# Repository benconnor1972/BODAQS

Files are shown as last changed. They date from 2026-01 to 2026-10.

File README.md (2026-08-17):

<table>
  <tr>
    <td width="50%">
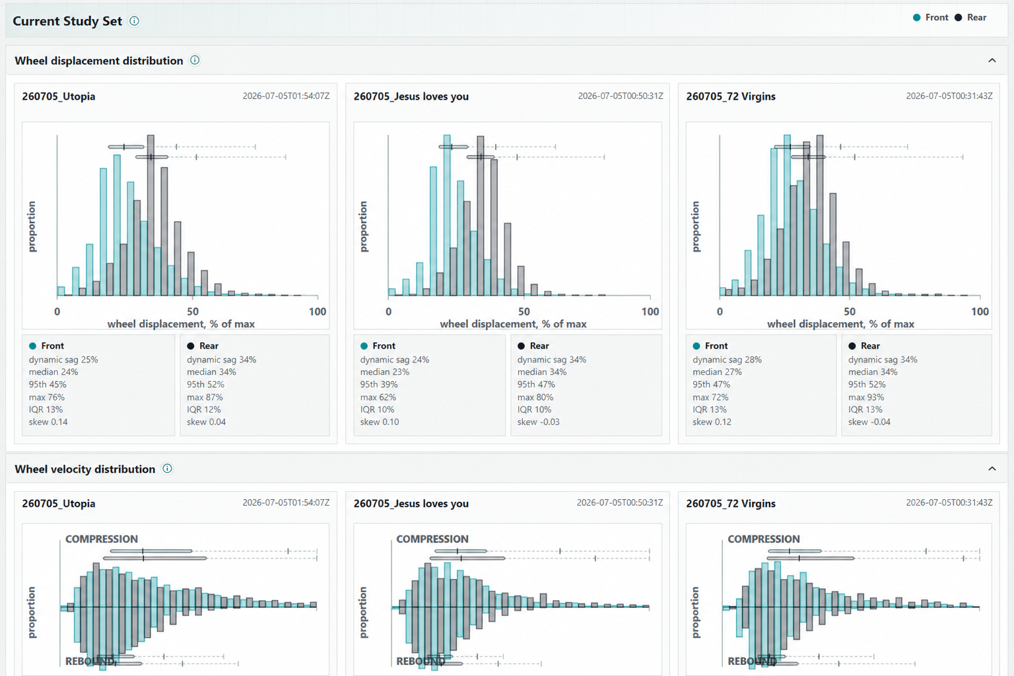
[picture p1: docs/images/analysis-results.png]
BODAQS Workbench showing the simple suspension stats analysis view
      
    </td>

   <td width="50%">
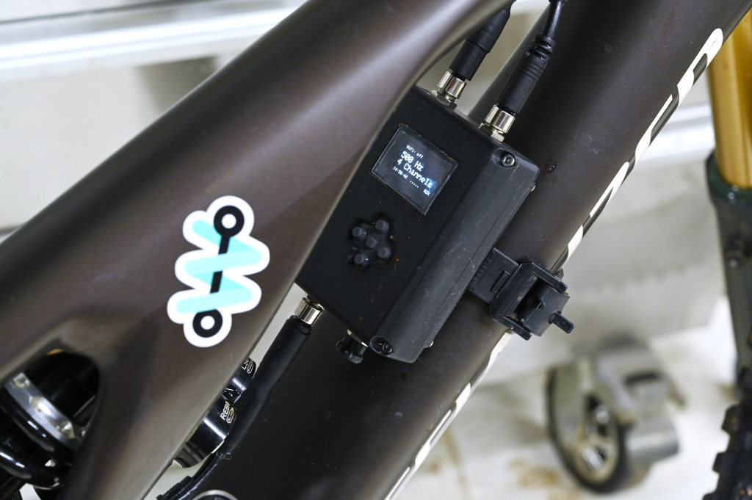
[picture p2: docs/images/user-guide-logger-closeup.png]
BODAQS logger installed on a bike
      
    </td>
  </tr>
  <tr>
    <td width="50%">
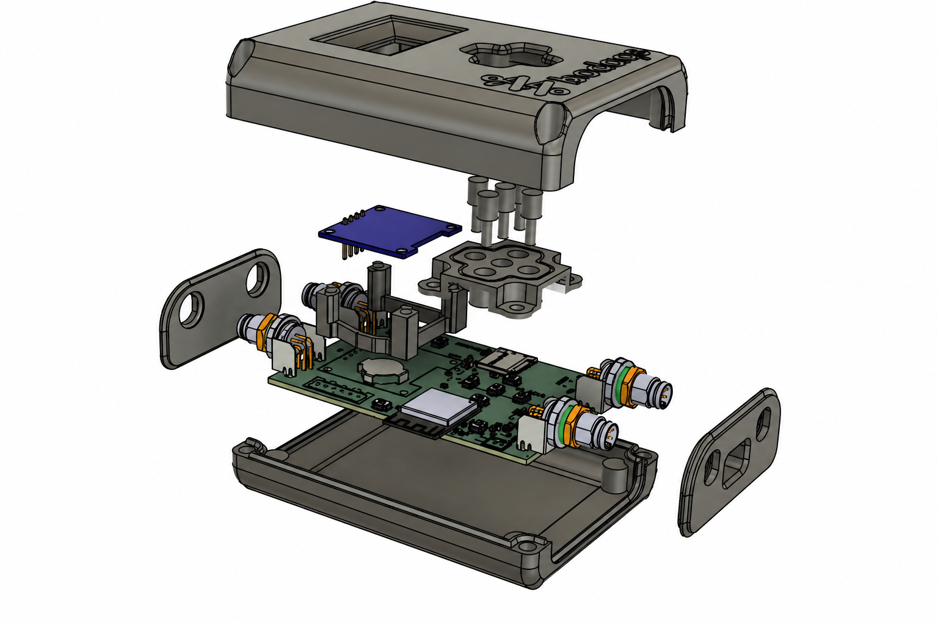
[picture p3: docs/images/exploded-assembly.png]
BODAQS A8 logger exploded diagram
      
    </td>
    <td width="50%">
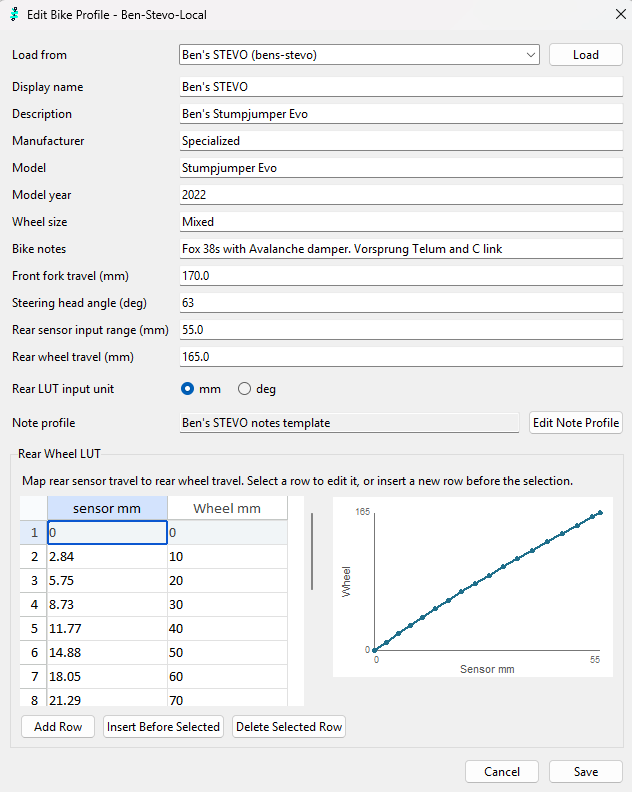
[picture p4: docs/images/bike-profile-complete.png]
BODAQS Import Manager showing a bike profile
      
    </td>
  </tr>
</table>

Current releases [here](https://github.com/benconnor1972/BODAQS/blob/main/RELEASES.md)

# Bicycle Open Data Acquisition System

BODAQS (Bicycle open data acquisition system) is an open-source, build-it-yourself data collection
and analysis system for mountain bikes, designed to be accessible to anyone with some DIY skills and a curiosity about what their bike is actually doing.

Data acquisition is ubiquitous in motorsport, and it's making its way into mountain-bike racing too. But for the engineering-minded (or budget-constrained), the choice is often between costly professional systems or consumer tools that keep the underlying data hidden.

BODAQS aims to offer an alternative: hardware that can be built with basic soldering skills using widely available parts; software with deep functionality and a structure designed for long-term expansion; and analysis built on powerful, free tools — alongside mounting and mechanical designs that can be 3D printed at home or produced at low cost. 

The project provides **open designs** for the hardware, software, analysis tools, and mechanical parts needed to collect and analyze mountain-bike data. It follows a build-it-yourself ethos, emphasising simplicity and low cost **without compromising functionality**.

## The problem with mountain bike (suspension) tuning

For most riders, suspension setup is a vibe-based, iterative guessing game: adjust a click, do a
run, wonder if that made things better or just 'different', repeat to exhaustion.

At the sharp end of gravity racing, teams with the budget chase these problems using data - but at a high cost. A few consumer products - notably Shockwiz, now owned by SRAM - have bridged the gap with a product that can provide meaningful suspension insight for most riders and be set up in under twenty minutes. But ShockWiz is a closed system: the algorithm is proprietary, the data never leaves the device, and if you run a coil shock, you're out of luck.

For the rider who wants to go deeper, wants to do more with the data, or whose coil setup isn't
supported,the choice has been: trust a black box, go all in on professional equipment, or go
without.

## The device

The BODAQS logger is a compact, hackable, open-source data logger you build yourself from widely available
components using basic soldering skills and a 3D printer. It records inputs from suspension and other sensors, at up to 1000Hz, and stores the data as standard CSV files readable by almost anything. The device can connect to wifi to allow settings to be edited or log files downloaded using any device with a web browser.

A small OLED screen and keypad make it simple to use, and an optional
handlebar-mounted button lets you tag moments of interest mid-ride — a heavy landing, a sketchy
section — so they're easy to find later.

The full design is open: PCB schematics and layouts, firmware, case, sensor mounts and more are all available to build, hack, and improve. There's a full bill of materials, build guide and advice on where to purchase the parts required.

## The software

Recording data is an engineering problem. Deciding what it means is the harder part, and the part that actually matters for tuning.

The BODAQS software comprises two main components:

- the **Import Manager** imports data from one or more loggers via file copy or WiFi, applies bike geometry information, does pre-processing calculations, matches GPS data from external devices and manages setup notes. The processed files live in your personal run library.
- the **BODAQS Workbench** gives you the visualization tools to dig deep into what your bike is doing.
The whole package can be installed on your computer and run with or without an internet connection.

## Who it's for

BODAQS is designed to scale with the user — in both the build, and the analysis.

If you're new to data acquisition, the hardware guide walks you through assembling the
logger, and you'll have something real to look at after your first ride with a couple of sensors - or even just one. 

If you're a top-end rider, mechanic or suspension shop with your own battle-tested ideas on how a bike should be set up, you'll have something you can use to test out and validate your own ideas and work, race faster, or to add value to your customers. 

If you're a tinkerer, engineer, developer, data scientist or uncategorised nerd, you can contribute to the project. Code, designs, ideas, feedback - it's all welcome.

## Enough of the pitch - where's this thing actually at?

**TL;DR:** we've got a pretty usable first-generation system that runs from end to end: From sourcing and building your logger to analyzing your runs. There's still lots to do, but we think it can add value for most people in its current state.

- The hardware works well within the limits of what we have tested and we think the user experience is pretty good. 
- The system supports analog potentiometers for suspension displacement, AS5600 (12-bit) and AS5048B (14-bit) rotary encoders for measuring linkage rotation, and GPS (either dedicated receiver or integrating data from Garmin devices).
- We have our own end-to-end software solution that you can download and test out, as well as a [hosted demo](https://demo.bodaqs.net/). We're also compatible with [data.syn.bike](https://data.syn.bike) if you prefer to see your data presented that away.
- We have [sourcing](https://bodaqs.net/logger-build-guide/bodaqs-a8/sourcing-hardware/), [building](https://bodaqs.net/logger-build-guide/bodaqs-a8/building-the-logger/), and [user](https://bodaqs.net/user-guide/) guides.
- We have published packages for the [hardware](https://github.com/benconnor1972/BODAQS/tree/main/hardware/releases) and the [3d printed parts](https://github.com/benconnor1972/BODAQS/tree/main/mechanical/Case/a8_v1_0)
- We have a set of Jupyter Lab [analysis notebooks](https://github.com/benconnor1972/BODAQS/releases) for exploratory data analysis. The back end code is organised in Python modules and there is a documented [API](https://github.com/benconnor1972/BODAQS/blob/main/docs/analysis/contracts/BODAQS_Public_API_Contract_v0.md). 

What we're working on:
- Further development of the software. There is lots we want to do!
- Extending the range of supported sensors. We've gone heavy (overkill?) on our software design to make integration of additional sensor types simple, so now is the time to cash in. Our next priorities are wheel speed sensors and inertia-motion units.
- Collecting build feedback from our beta testers. We're looking for people who want to help with this!
- Getting the system under some faster riders - in the end, we want to do *data analysis*, not just build hardware and software.

## Ethos and inspiration

This project exists for many reasons but three specific precursors stand out:
 - ShockWiz: Nigel Wade's ground-breaking product, now owned by SRAM, is in a category of one: mountain bike suspension analysis products that can be set up by an average user in under 20 minutes and provide useful feedback to the vast majority of riders. I was a happy ShockWiz user for many years and probably still would be if I hadn't discovered coil suspension. An elegant product that extracts maximum insight from minimum hardware, with a simplicity that hides some very clever engineering.
 - Sufni: The first open-source mountain bike data acquisition project to cross my path. For a variety of reasons I decided to take a different path rather than build one, but it provided the seed of the idea and the use of Lego for sensor mounting deserves a credit of its own.
 - RepRap: The movement that gave birth to cheap and ubiquitous 3D printing wasn't driven by market analysis by some big corporation, but by people who wanted a thing they couldn't buy (at a reasonable price). The community development and sharing ethos persists to this day and the products available are massively better and cheaper than what was available just a few years ago.

## Project maintenance

BODAQS is maintained by [Ben Connor](https://github.com/benconnor1972).

Contact: benconnor1972@gmail.com

Official release and code-signing responsibilities are described in the
[Code Signing Policy](CODE_SIGNING_POLICY.md).

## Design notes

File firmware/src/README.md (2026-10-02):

# ESP32 Data Logger (SD + Web UI)

ESP32-based data logger with:
- An extensible sensor framework - initial target is 2 potentiometer, 2 accelerometer, 2 strain gauge and one event mark channels
- Configurable logging rates of 10, 20, 50, 100, 200, 500, 700, and 1000 Hz, subject to sensor throughput limits
- SD card logging
- On-device web UI (list/download/delete files, simple config page)
- mDNS discovery in station and AP mode via `_bodaqs-logger._tcp`
- Button control (start/stop logging, mark events, menu navigation)
- General and sensor configuration via config file on SD (`loggercfg`) 

Developed mainly for mountain bike use.

On the A8, external ADC throughput is budgeted at 70% of each ADS1220's
2,000 SPS maximum, divided by its number of active, unmuted analog channels.
The logger uses the lowest limit across the active ADCs and rounds down to a
permitted rate. There is no separate 500 Hz cap: one active channel per ADC
allows up to 1,000 Hz, two allow 700 Hz, and three or four allow 200 Hz.
The requested configuration rate is preserved; the effective rate controls
logging. Higher rates require hardware validation of sample freshness and
logger timing. The existing integer-microsecond cadence uses a 1,428 us period
for 700 Hz (approximately 700.28 Hz).

A8 and RC3 have separate board profiles with the same hardware pin mapping.
Build A8 with `bodaqs_s3_mini_n4r2` (`BODAQS_A8`) and RC3 with
`bodaqs_s3_mini_n4r2_rc3` (`BODAQS_V1RC3`). The legacy
`BODAQS_S3_Mini_N4R2` profile alias selects A8. RC3 and Prototype F retain
the Sleep menu entry and the default hold-left sleep binding; A8 omits both.
Explicit bindings in existing config files still apply, so remove any A8
sleep binding there as needed. Restart is the last main-menu entry on all
boards and is unavailable while logging. Automatic idle sleep remains
controlled by `auto_sleep_idle_min`.

## Hardware

- **ESP32** (Arduino core 3.3.0 tested) - SparkFun ESP32 Thing Plus dev board
- **MicroSD** via ESP32 SDMMC
- **Buttons**
- **0.96" monochrome OLED display**
- **Sensors** starting with potentiometers on ADC pins (configurable)

## Development

# ESP32 Data Logger — Module Overview

This document summarizes the major modules in the project, what each one is responsible for, how they interact, and key APIs/gotchas. It’s meant to be kept at the repo root for quick orientation.

---

## Top-Level Flow (boot → ready)

1. **setup()** initializes storage (SD), applies defaults, loads config, brings up Wi‑Fi (optional), syncs RTC, constructs sensors from the config, starts Display/UI, and registers buttons.
2. **loop()** runs the main managers’ `loop()` functions (logging, web server, menu, button dispatch, etc.).

---

## `ConfigManager`

**Purpose:** Load/save the logger’s global settings and the list of **SensorSpec**s from `loggercfg.txt`. It also owns a per‑sensor key/value store backing the **ParamPack** interface used by sensor code.

**Key responsibilities**
- `begin(filename)` - set the config file path. Storage access is handled through `StorageManager`.
- `load(LoggerConfig&)` / `save(const LoggerConfig&)` — merge text file with defaults and persist changes.
- Manage **SensorSpec** array (type, name, mutedDefault, ParamPack for per-sensor params).
- Simple string‑backed **ParamStore** (arrays `keys[]`/`vals[]`, bounded sizes) with case‑insensitive lookups.

**APIs**
- `uint8_t sensorCount()`
- `bool getSensorSpec(uint8_t i, SensorSpec& out)` — returns a copy; ParamPack is rebound to the correct store.
- `bool getParam/getIntParam/getFloatParam/getBoolParam(index, key, out)` — safe accessors used by UI/Web to read current per‑sensor values.
- Global parse helpers: `parseBool`, etc.

**Notes/Gotchas**
- `save()` writes **all** config keys (globals + sensors) deterministically.
- `logger_name` is the stable logger identity used by upload/import workflows
  and shown in the web UI title bar.
- `ConfigManager::loggerId()` returns a trimmed, filename-safe derivative of
  `logger_name` for API/session identifiers without changing the stored name.
- `log_format` controls the emitted log file format. `bodaqs_standard` is the normal headed BODAQS CSV; `bodaqs_compact_binary` writes the established single-timebase BDQ v1 file; and explicit `bodaqs_multi_stream_binary` selection writes the experimental BDQ v2 independent-stream format. Deprecated syn.bike format keys are accepted on load and silently select `bodaqs_compact_binary`.
- `omit_metadata=false` keeps the default behaviour of writing a same-stem JSON log metadata file at log close. Set `true` to skip metadata generation.
- Idle timeout config is saved in minutes (`auto_sleep_idle_min`, `wifi_idle_timeout_min`). Legacy `_ms` keys are still accepted on load for migration.
- Fixed per‑sensor KV capacity (currently 32). Exceeding keys will drop extra pairs.
- File format keys used by analog pot sensors: `pin`, `mode`, `include_raw`, `zero_count`, `full_count`, `full_travel_mm`.
- File format keys used by AS5600 string-pot sensors include `counts_per_turn`, `wrap_threshold_counts`, `sensor_zero_count`, `sensor_full_count`, `installed_zero_count`, `sensor_full_travel_mm`, and `assume_turn0_at_start`.
- File format keys used by AS5048B and AS5600 rotary angle sensors include `i2c_bus`, `i2c_addr`, `zero_count`, and `direction`. `direction` is `counts_increase_positive` or `counts_decrease_positive`; log metadata still emits legacy `invert` for downstream compatibility.

---

## `SensorManager`

**Purpose:** Owns the live sensor objects, registration, primary pot selection, and per‑sensor mute state that the logger and UI respect.

**Key responsibilities**
- `begin(const LoggerConfig*)` — reset internal lists and prepare to accept sensors.
- Build sensors in `setup()` by iterating `ConfigManager::sensorCount()` and mapping `ParamPack` → sensor params.
- `registerSensor(Sensor*)`, `finalizeBegin()`, `debugDump()` for inspection.
- Mute control used by logger/UI: `getMuted(idx, bool&)`, `setMuted(idx, bool)`.
- `primaryPot()` selection for UI convenience.

**Notes/Gotchas**
- Keep the **construction order** deterministic so UI indices match spec indices.
- Treat `SensorManager` APIs as **static** utilities across the codebase.

---

## `AnalogPotSensor` (potentiometer)

**Purpose:** Acquire analog position and report one or more columns depending on mode and configuration.

**Key params (from ParamPack)**
- `pin` (ADC pin), `mode` (`raw`/`norm`/`mm`), `include_raw` (bool),
- `zero_count`, `full_count`, `full_travel_mm`.

**Notes**
- Produces normalized and/or raw columns; column names include the sensor `name` (e.g. `pot1_norm`).
- Measurement direction is derived from calibration endpoints. If the full-travel count is below the zero-travel count, the firmware treats the signal as inverted.
- Honors **muted** state via `SensorManager` (muted sensors still tick but are skipped in log output).

## `AS5048BAngleSensor` / `AS5600AngleSensor`

**Purpose:** Acquire one-turn absolute rotary position over I2C and report raw counts or zeroed angular movement.

**Key params (from ParamPack)**
- `i2c_bus`, `i2c_addr`, `i2c_read_mode`
- `zero_count`, `direction`
- `slow_filter` optionally writes the AS5600 `CONF.SF` slow-filter bits at
  startup as a volatile setting (`unchanged`, `16x`, `8x`, `4x`, or `2x`).
- `output_mode`, `include_raw`, `include_angle`, `include_diag`
- `include_angle` appends a diagnostic AS5600 `ANGLE` register column so it can
  be compared with the normal raw `RAW_ANGLE` register readout.
- For AS5600 and AS5048B, `include_diag` adds AGC/status/magnitude plus read-state and
  failure-counter columns (`read_ok`, `reused`, `read_failures`,
  `diag_failures`).
- AS5600 metadata includes a read-only startup snapshot of key device registers
  (`ZPOS`, `MPOS`, `MANG`, `CONF`, `RAW ANGLE`, `ANGLE`, `STATUS`, `AGC`, and
  `MAGNITUDE`) under `device_config`.
- BDQ final summaries include bounded AS5600 and AS5048B runtime transition
  diagnostics (logging/scheduler boundaries, the start and recovery of
  read/configuration failures, failure stage/result, and analog-rail state).
  CSV JSON metadata contains the corresponding compact sensor-health summary;
  these diagnostics do not add sample columns or successful-path I2C
  transactions.
- AS5600 I2C logging uses the device's persistent `RAW_ANGLE` pointer after
  the first addressed read. Normal samples therefore need only the two-byte
  read transaction; diagnostic/configuration access invalidates the pointer
  and the next sample safely re-primes it. Runtime summaries report fast-read
  attempts/successes/fallbacks and raw-read duration. The default magnetic
  diagnostic cadence is 1 Hz (`diag_interval_ms=1000`).

**Notes**
- `ZERO` calibration captures the installed zero point and then asks for a small positive movement so the firmware can set `direction`.
- `direction=counts_increase_positive` means increasing raw counts produce positive angular output; `counts_decrease_positive` reverses that polarity.
- Metadata emits both `direction` and legacy `invert`; `invert=true` corresponds to `counts_decrease_positive`.
- These angle sensors do not support multi-turn tracking.
- Repeated failures are coalesced into transition events and aggregate streak
  counts. At most 32 events are retained per session; overflow is reported.

## `AS5600StringPotSensorBase` / `AS5600StringPotAnalog`

**Purpose:** Acquire a wrapped one-turn AS5600 reading, unwrap it across multiple turns in firmware, and report unwrapped travel while still logging wrapped raw counts.

**Key params (from ParamPack)**
- `ain` / `pin`
- `counts_per_turn`, `wrap_threshold_counts`, `assume_turn0_at_start`
- `sensor_zero_count`, `sensor_full_count`, `installed_zero_count`, `sensor_full_travel_mm`
- `output_mode`, `include_raw`

**Notes**
- `RAW` mode reports wrapped counts as the primary column.
- When `include_raw=true`, the logger appends wrapped raw counts and unwrapped raw counts. The unwrapped raw metadata includes `unwrap` in its transform chain.
- `LINEAR` mode reports unwrapped mm using the calibrated unwrapped span.
- The sensor resets its unwrap tracker to turn 0 at each logging start when `assume_turn0_at_start=true`.

For `AS5600StringPotI2C`, the I2C-specific parameters also include
`slow_filter`, `include_angle`, `include_diag`, and `diag_interval_ms`. The I2C
variant applies and records the same volatile AS5600 configuration, device
register snapshot, magnetic diagnostics, read-quality columns, runtime events,
and deferred post-session recovery as `AS5600AngleSensor`. Existing string-pot
measurement columns retain their previous order; optional health columns are
appended after them.

---

## `StorageManager`

**Purpose:** Single owner of SDMMC startup and log file lifecycle; provides sample interval/buffer knobs.

**Common APIs**
- `StorageManager_begin(boardProfile)`
- `StorageManager_setSampleRate(hz)` / `StorageManager_getSampleIntervalUs()`
  (`StorageManager_getSampleIntervalMs()` remains as a rounded-up compatibility view)
- `StorageManager_setBufferSize(bytes)`

**Notes**
- `SD_MMC.begin()` and error handling live here.
- `bodaqs_standard` logs `sample_id`, timestamp, all active sensor columns, and
  `mark`, with a header. Run statistics and generic configured-sensor health
  summaries are written to the same-stem JSON metadata file under `qc`.
- Both binary selections write `.bdq` logs with embedded metadata and schema information. `bodaqs_compact_binary` is BDQ v1; `bodaqs_multi_stream_binary` is the opt-in BDQ v2 path. Neither generates a separate JSON sidecar or automatic ZIP archive.
- In BDQ v2 mode, sensors with native stream support (currently BMI270) are excluded from the primary row and stored once at the hardware profile rate. BMI270 `max_output_rate_hz` continues to govern the legacy sparse-row adapters only.
- The BDQ v2 primary-row queue is capped at 32 rows to leave heap for multiple IMU FIFO queues. At the intended auxiliary-sensor ceiling of 200 Hz this is about 160 ms of buffering; primary queue drops are preserved in stream status and the final summary.
- BMI270 profiles `orientation_200`, `orientation_400`, `orientation_800`, and
  `orientation_1600` select native accel/gyro ODRs while retaining the existing
  +/-16 g, +/-2000 deg/s, and filter/performance settings. The higher-rate
  profiles are experimental until their achieved rates, filtering, loss, and
  timing have been measured on the target wiring.
- `accel_1600_gyro_200` is an experimental BDQ-v2-only mixed-rate profile.
  It emits 1600 records/s on the accelerometer time grid and declares
  `gyro_sample_valid` at offset 26; gyro axis values are fresh only when that
  field is 1. The stream catalog separately reports effective accel and gyro
  rates. CSV and BDQ v1 reject this profile rather than imply that held or
  placeholder gyro values are native 1600 Hz measurements.
- `fifo_poll_rate_hz` independently selects FIFO service at 25, 50, 100, 200,
  or 400 Hz. Experimental 10 Hz service is restricted to
  `accel_800_gyro_200`. Session diagnostics record the selected native/output/poll rates,
  queue coverage and pressure, FIFO throughput, I2C occupancy, achieved service
  rates, missed service slots, and scheduler lateness.
- A 1600 sample/s stream has an 800 Hz Nyquist limit; it cannot preserve a
  1 kHz signal regardless of transport performance. A genuine 1 kHz analysis
  band requires a different IMU profile/device sampling above 2 ksample/s with
  suitable analogue/digital filter bandwidth.
- Direct syn.bike CSV output is deprecated. Legacy `syn_bike_raw` configuration values fall back to `bodaqs_compact_binary`; data.syn.bike files can be generated downstream by the BODAQS analysis tooling.
- Standard CSV and BDQ logging refuse configurations with more than 64 emitted
  sensor columns. CSV rows are formatted in a session-allocated worst-case
  buffer; formatting and storage-write failures are counted in metadata rather
  than being silently omitted.
- When metadata is enabled and written successfully, log close also creates a
  same-stem session ZIP via `<stem>.zip.tmp` then renames it to `<stem>.zip`.
- After the ZIP is written successfully, the loose same-stem CSV and JSON are
  removed; the ZIP is the canonical upload/import artifact.
- A small smoke test may create `TEST.TXT` during setup.

---

## `ZipArchiveWriter`

**Purpose:** Create small store-only ZIP archives on SD for completed session
artifacts.

**Notes/Gotchas**
- Currently used by `StorageManager` to archive each completed CSV/JSON pair.
- Writes to a caller-supplied destination and refuses to overwrite existing
  files; callers should write a temporary path and rename after success.

---

## `UploadSessionScanner`

**Purpose:** Find completed CSV archives and compact binary sessions on SD for
the Wi-Fi upload API.

**Common APIs**
- `scan(directory, out, capacity, summary)` - returns complete ZIP-backed CSV
  sessions and loose `.bdq` sessions, then fills a bounded summary.
- `findBySessionId(sessionId, out, directory)` - resolves a complete session by
  its `logger_id__session_stem` identifier.

**Notes/Gotchas**
- `.zip.tmp` files are ignored as importable archives but counted in the scan
  summary for diagnostics.
- `.bdq` sessions report `data_format=bdq`, `data_path`, and `data_ready`
  instead of a CSV archive.
- Upload/acknowledgement flags are read from `UploadAckIndex`.

---

## `UploadAckIndex`

**Purpose:** Persist import acknowledgements from the desktop agent.

**Common APIs**
- `markSessionAcknowledged(record)` - records an acknowledgement, returning
  success without appending when the session is already acknowledged.
- `findSessionAcknowledgement(sessionId, out)` - reads the latest valid record
  for a session.
- `applyAcknowledgementStatuses(lookups, count)` - resolves acknowledgement
  flags for a batch of session ids with one index scan.
- `isSessionAcknowledged(sessionId)` - convenience predicate used by session
  listing.

**Notes/Gotchas**
- The index is `/upload_index.ndjson`; the `.ndjson` extension keeps it out of
  same-stem session discovery.
- Oversized indexes are refused rather than scanned indefinitely; remove or
  compact `/upload_index.ndjson` on the SD card if this diagnostic appears.
- Corrupt lines are skipped so a bad record does not block session listing.

---

## `UploadSessionCleanup`

**Purpose:** Conservative cleanup for sessions already acknowledged by the
desktop import agent.

**Common APIs**
- `cleanupSession(session, MoveToUploaded, result)` - moves the ZIP into
  `/uploaded`; loose CSV/JSON files are moved too when present on older cards.
- `cleanupSession(session, Delete, result)` - removes the ZIP; loose CSV/JSON
  files are removed too when present on older cards.

**Notes/Gotchas**
- API callers must require upload mode and prior acknowledgement before using
  this helper.
- Cleanup requires the archive and treats loose CSV/JSON files as optional
  legacy companions.

---

## `LoggingManager`

**Purpose:** Turn logging on/off, write headers and rows from active sensors, and accept **mark** events.

**Common APIs**
- `bool start()` / `void stop()` / `bool isRunning()`
- `void mark()` — insert a marked row/annotation.

**Interlocks**
- Will **refuse to start** while the web server is running (see `ButtonActions`).
- Will **refuse to start** while upload mode is active.

---

## `UploadModeManager`

**Purpose:** Runtime guard for Wi-Fi upload workflows.

**Common APIs**
- `bool enter()` / `void exit()` / `bool toggle()`
- `bool isActive()` / `bool canEnter()`

**Interlocks**
- Upload mode cannot be entered while logging is active.
- Upload mode is transport-neutral; it does not automatically start Wi-Fi.
- Logging cannot start while upload mode is active.

---

## `RTCManager`

**Purpose:** Timekeeping (internal ESP32 RTC or external DS3231), NTP sync, timezone application.

**Common APIs**
- `RTCManager_begin(RTC_INTERNAL|RTC_EXTERNAL)`
- `RTCManager_setHumanReadable(bool)` — UI/log timestamp format.
- `RTCManager_syncWithNTP(ssid, pass)`
- Tied to `configTzTime(tz, ntp1, ntp2, ntp3)` in `setup()`.

---

## `WiFiManager`

**Purpose:** Non-blocking Wi-Fi state machine for station/AP networking, RTC
sync, web/API availability, and discovery.

**Common APIs**
- `status()` - returns mode, IP, hostname, RSSI/client details.
- `hostname()` - returns a stable mDNS/HTTP hostname derived from `logger_id`.
- `refreshDiscovery()` - restarts mDNS TXT records after upload
  mode changes.

**Notes/Gotchas**
- Station and AP modes both advertise `_bodaqs-logger._tcp` on port `80`
  when online, so the device is reachable at `bodaqs-<logger_id>.local`
  in either mode.

---

## `WebServerManager`

**Purpose:** Lightweight HTTP UI for status, SD file browsing, and editing **all** configuration (globals + sensors).

**Routes**
- `/` redirects to `/files`; `/files` is the landing page and supports SD browsing, upload, download, and delete actions.
- `/config` (GET) displays editable globals and sensor sections.
- `/config` (POST) updates globals and rewrites `loggercfg.txt` with all keys; also rewrites each sensor’s block.
- `/config/sensors` can add or remove sensor config blocks. Removing a sensor rewrites config only; transform directories/files are left in place. Restart the logger after adding/removing sensors so the live sensor set is rebuilt.
- `/api/v1/device`, `/api/v1/status`, `/api/v1/upload-mode/*`,
  `/api/v1/sessions`, `/api/v1/session/archive`, and `/api/v1/session/data` expose the local-first
  import-agent API. Session list/download/cleanup routes require upload mode.
- `/files` includes browser controls for entering/exiting upload mode and
  reports network/session readiness for manual checks.
- All HTML pages share a title/navigation header showing `BODAQS data logger: <logger_name>`, the active network, and IP address.

**Interlocks**
- Config edits and generic SD-card mutations are rejected while logging or
  upload mode is active. Downloads remain allowed; import cleanup should use
  the upload API after acknowledgement.
- `canStart()` returns false while logging is active; `ButtonActions` also blocks starting logging while Wi‑Fi/web is running.

**Helpers**
- Minimal HTML/CSS, simple CSV inputs (e.g., NTP servers), basic HTML escaping, safe path checks.

---

## `UI` & `DisplayManager`

**Purpose:** Unified printing to Serial and OLED with levels and targets, plus transient toasts and a status line.

**UI APIs (typical)**
- `UI::begin(g_cfg)` — apply target/level preferences.
- `UI::println(serialText, oledText, target, level, oledToastMs=0)`
- `UI::status("Ready")` — persistent status line when idle.
- `UI::toast("Marked", 1200)` — small transient message.
- `UI::clear(target)` / `UI::flush()` — OLED control.
- `UI::setModal(true/false)`, `UI::isModal()` — allow **MenuSystem** to “own” the OLED while a menu is open.

**DisplayManager**
- Owns the OLED device and regular idle/telemetry rendering.
- In `loop()`, it **exits early** when `UI::isModal()` is true so the menu can draw unobstructed.

---

## `ButtonManager`

**Purpose:** Register buttons in **poll** or **interrupt** mode, debounce, and raise callbacks with **edge** and **hold** events.

**APIs**
- `ButtonManager_register(pin, BUTTON_POLL|BUTTON_INTERRUPT, debounceMs, callback)`
- `ButtonManager_loop()` — delivers events & performs polling.
- Optional `ButtonManager_read(pin)` — single-pin polled edge read.

**Events**
- `BUTTON_PRESSED`, `BUTTON_RELEASED`, `BUTTON_HELD` (long‑press; ~800 ms default).

**Notes/Gotchas**
- Interrupt mode posts **PRESS** from ISR; **HELD** is synthesized in the main loop when the level stays LOW long enough.
- Some pins can’t generate external interrupts on ESP32; keep **Enter** on a reliable GPIO when using interrupt mode, or use **poll** for nav keys.

---

## `ButtonActions`

**Purpose:** Wire configured pins to user-visible actions and UI feedback.

**Mappings (typical)**
- **Web** → start/stop web server (blocks when logging). `web_toggle` can be
  bound to `click`, `double_click`, or `held`.
- **Log** → start/stop logging (blocks when web server is running).
- **Mark** → inserts a mark only when logging is active.
- **Nav Up/Down/Left/Right/Enter** → dispatch into **MenuSystem** when the menu is active; otherwise show small UI toasts.

**Setup**
```cpp
ButtonActions::begin(&g_cfg);
ButtonActions::registerButtons();  // reads pins & debounce from config
```

---

## `MenuSystem`

**Purpose:** A small, modal OLED UI navigated by five buttons for logging,
upload, sensor, calibration, and settings workflows.

**Behavior**
- **Open/Close**: short‑press Enter to open, long‑press Enter to close (or via left/back).
- **Auto‑close** after inactivity (default 15 s; `setIdleCloseMs(ms)`).
- **States**: `Inactive` → `Main`; `Settings` groups lower-frequency
  configuration and device actions (`WiFi mode`, `Log format`, `Reset time`,
  `Restart`, `About`).
- **Navigation**:
  - From **Main**: Right/Enter opens the selected item, including the
    `Settings` submenu.
  - In **Settings**: Up/Down selects settings; Right/Enter opens or runs the
    selected setting.
  - In **SensorsList**: Up/Down to move selection, Right/Enter toggles mute for the selected sensor via `SensorManager::getMuted/setMuted`.
  - Left goes back; closing returns the OLED to `DisplayManager` by calling `UI::setModal(false)` internally.

**Notes**
- The `About` screen is under `Settings`; it shows firmware version, active
  board profile, and build timestamp.
- Firmware version text comes from the compile-time `BODAQS_FW_VERSION` define, with fallback defaults in `FirmwareInfo.h`.
- Calls `UI::setModal(true)` on open and `UI::setModal(false)` on close so normal telemetry rendering pauses while the menu is visible.
- Uses `ConfigManager::sensorCount()`/`getSensorSpec()` to render names; relies on `SensorManager` for the **live** mute state.

---

## `DebugLog` (optional)

**Purpose:** Compile‑time and run‑time gated debug printing without littering the codebase with `#ifdef`s.

**Typical use (pseudocode)**

```cpp
// DebugLog.h
// #define DEBUGLOG_ENABLED 1  // uncomment to compile logs in
enum DebugLevel : uint8_t { DL_ERROR=0, DL_WARN=1, DL_INFO=2, DL_DEBUG=3, DL_VERBOSE=4 };
void DBG_SET_LEVEL(DebugLevel lvl);
bool DBG_WOULD_LOG(DebugLevel lvl);
void DBG_IMPL(DebugLevel lvl, const char* fmt, ...);

#define DBG(lvl, fmt, ...)    do { if (DBG_WOULD_LOG(lvl)) DBG_IMPL(lvl, fmt, ##__VA_ARGS__); } while(0)
#define DBG_IF(cond, lvl, fmt, ...) do { if ((cond) && DBG_WOULD_LOG(lvl)) DBG_IMPL(lvl, fmt, ##__VA_ARGS__); } while(0)
```

**Notes**
- You can flip a single global to enable/disable logs and adjust verbosity.
- Keep fast‑path disabled in production to save cycles and flash.

---

## Configuration Keys (globals)

- `logger_name`, `sample_rate_hz`, `timestamp_mode` (`human|fast`), `log_format` (`bodaqs_standard|bodaqs_compact_binary|bodaqs_multi_stream_binary`; deprecated syn.bike values fall back to compact binary), `omit_metadata`, `auto_sleep_idle_min`, `wifi_idle_timeout_min`, `tz`
- `debounce_ms`
- Button pins: `web_button_pin`, `log_button_pin`, `mark_button_pin`, `nav_up_pin`, `nav_down_pin`, `nav_left_pin`, `nav_right_pin`, `nav_enter_pin`
- Network/time: `wifi_ssid`, `wifi_password`, `ntp_servers`, `time_check_url`
- UI: `ui_target`, `ui_serial_level`, `ui_oled_level`, `oled_brightness`, `oled_idle_dim_ms`, `oled_logging_policy` (`auto`, `freeze`, or `prefer_active`)
- RTC: `use_external_rtc`

Sensor sections follow the pattern:
```
sensorN.type=analog_pot
sensorN.name=pot1
sensorN.muted=true|false
sensorN.pin=34
sensorN.mode=raw|norm|mm
sensorN.include_raw=true|false
sensorN.zero_count=0
sensorN.full_count=4095
sensorN.full_travel_mm=0

sensorN.type=as5600_string_pot_analog
sensorN.name=stringpot1
sensorN.ain=0
sensorN.counts_per_turn=4096
sensorN.wrap_threshold_counts=2048
sensorN.assume_turn0_at_start=true
sensorN.sensor_zero_count=0
sensorN.sensor_full_count=24576
sensorN.installed_zero_count=0
sensorN.sensor_full_travel_mm=600
sensorN.output_mode=LINEAR
sensorN.include_raw=true
```

---

## Interactions at a Glance

- **WebServerManager ↔ LoggingManager**: mutual gating (don’t run both at once).
- **MenuSystem ↔ DisplayManager/UI**: menu takes OLED ownership (modal) and then releases it.
- **ConfigManager ↔ SensorManager**: specs/params come from `ConfigManager`; live mute and sensor objects live in `SensorManager`.
- **ButtonManager ↔ ButtonActions**: hardware events → high-level behaviors.

---

## Troubleshooting Tips

- **Crashes during config print**: ensure any `st->items[k]` legacy code was replaced with the current `ParamStore` (`keys[k]` / `vals[k]`).
- **Wi‑Fi/Web won’t start**: check STA credentials and the “busy while logging” guard.
- **Buttons unreliable**: confirm GPIO supports interrupts if using ISR mode; otherwise fallback to `BUTTON_POLL`.
- **Menu flicker/overdraw**: verify `UI::isModal()` check in `DisplayManager::loop()` short‑circuits while menus are active.
- **Sensor list shows only one entry**: confirm `s_sensorSel` clamping and that `ConfigManager::sensorCount()` matches the constructed sensors.

---

*Last updated: generated by ChatGPT.*

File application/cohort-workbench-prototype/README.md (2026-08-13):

# BODAQS Study Set Workbench Prototype

Static React/Vite prototype for the BODAQS Library Browser and Study Set
Builder.

The prototype is designed to run in two local modes:

- Vite development mode, with the browser app on `http://localhost:5173` and the
  Library API service on `http://127.0.0.1:8765`.
- Bundled local mode, where the Library API service serves the built web app and
  API from the same origin.

## Run

```powershell
cd C:\Users\benco\dev\BODAQS\application\cohort-workbench-prototype
npm install
npm run dev
```

Start the Library API service in a second terminal:

```powershell
cd C:\Users\benco\dev\BODAQS\analysis
..\.venv\Scripts\python.exe -m bodaqs_analysis.library_api_service --libraries-root "C:\Users\benco\OneDrive\BODAQS-data" --host 127.0.0.1 --port 8765
```

If the current terminal does not know where Node.js is, open a fresh terminal or
prepend the Node install path:

```powershell
$env:Path = "C:\Program Files\nodejs;$env:Path"
```

By default, dev and hosted builds call `http://127.0.0.1:8765`. Override that
with `VITE_BODAQS_LIBRARY_API_URL` when needed:

```powershell
$env:VITE_BODAQS_LIBRARY_API_URL = "http://127.0.0.1:8766"
npm run dev
```

## Bundled Local Smoke Test

Build the web app:

```powershell
cd C:\Users\benco\dev\BODAQS\application\cohort-workbench-prototype
npm run build
```

Serve the built app from the Library API service:

```powershell
cd C:\Users\benco\dev\BODAQS\analysis
..\.venv\Scripts\python.exe -m bodaqs_analysis.library_api_service --libraries-root "C:\Users\benco\OneDrive\BODAQS-data" --host 127.0.0.1 --port 8765 --web-root "..\application\cohort-workbench-prototype\dist"
```

Open `http://127.0.0.1:8765/`. In this mode the web app uses the same origin for
API calls, so no `VITE_BODAQS_LIBRARY_API_URL` setting is required.

Optional health check:

```powershell
Invoke-RestMethod http://127.0.0.1:8765/api/v1/health | ConvertTo-Json -Depth 5
```

The `web_app` field should report `enabled: true` and `index_present: true`.

## Checks

```powershell
npm run build
npm run lint
```

## UI Glyph Conventions

The Workbench uses [Lucide](https://lucide.dev/) glyphs. A static glyph is an
orientation aid, not decoration: use one only for a persistent work area or a
first-class BODAQS concept. Subordinate headings remain text-only unless the
glyph makes the concept materially easier to scan.

| Concept | Glyph | Current use |
| --- | --- | --- |
| Library | `Library` | Library Browser |
| Sessions / signal data | `Activity` | Session Selector, signal-related views |
| Study Set | `Layers3` | Study Set Builder |
| Tracks | `Route` | Tracks |
| Filters | `Filter` / `SlidersHorizontal` | Filters, Select and filter drawer |
| GPS location / trackpoints | `MapPin` | GPS headings, trackpoints |
| Map | `Map` | Track map and map placeholders |
| Matching | `Crosshair` | Match Preview and trackpoint-query controls only |
| Video | `Video` | Video reference |
| Altitude | `Mountain` | Altitude Profile |
| Lap timing | `Timer` | Lap timing |

Action glyphs describe the action rather than the surrounding concept: for
example `Plus`, `Save`, `Trash2`, `Play`, `RefreshCw`, `RotateCcw`, and the
directional chevrons. Keep `X` unchanged for close controls until a separate
close-control policy is agreed. The CSS point and segment marks in Track
Analysis are intentionally retained because they express track geometry more
clearly than a generic glyph.

## Current Scope

- Browse, sort, filter, inspect, rename, and delete library sessions.
- Create, save, load, analyze, and manage Study Sets.
- Manage saved filters, tracks, notes, bookmarks, GPS previews, and signal
  inspection workflows through the Library API service.
- Launch analysis views from the library browser or saved/current Study Sets.

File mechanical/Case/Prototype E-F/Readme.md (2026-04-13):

### 3d printing files for case

This directory contains the STL files needed to print the case. A case has four parts: base, lid, top end and bottom end.

There are two base variants, one that uses heat-set brass inserts for closure, and one that uses standard M3 hex nuts.

The ends vary according to the number and type of connectors to be installed. The standard layout is:
 - Four connectors in the top end: two analog inputs, one I2C input and one connector for a handlebar-mounted switch.
 - Two connectors in the bottom end for analog inputs.
 
Variations of the end pieces are provided should you not want to break out all the connectors.

Unless otherwise noted, the end pieces are designed for M8 circular connectors. Those designated '_plastic' are designed to accommodate push-together M8 plastic connectors with cable tails attached.

CAD files (Fusion archive and STEP) are also provided to allow modification of the case design.

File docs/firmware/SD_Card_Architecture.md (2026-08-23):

# SD Card Architecture (BODAQS Firmware)

This document describes the SD card architecture used in the BODAQS firmware.

## 1. Current Policy

BODAQS firmware now supports **SDMMC only** for logger storage.

The old SPI/SdFat backend and the ancient `ThingPlus_A` prototype profile have been retired. Production board profiles are expected to provide SDMMC pins through `BoardProfile::storage`.

## 2. Hardware Backend

The SD card subsystem uses the ESP32 SD/MMC peripheral via Arduino `SD_MMC`.

- Pins are defined by the active `BoardProfile`.
- 1-bit mode is currently used by the BODAQS 4D/4F profiles.
- 4-bit mode remains represented in `StorageProfile` for future SDMMC boards, but it is still handled through `SD_MMC`.

## 3. Filesystem API

All firmware file I/O uses Arduino FS objects from `SD_MMC`:

```cpp
File f = SD_MMC.open("/path.txt", FILE_READ);
```

There is no active `SdFat`, `SdFs`, or SPI SD storage path in the firmware.

## 4. StorageManager Responsibilities

`StorageManager` owns storage startup and log file lifecycle:

- Configure SDMMC pins from `BoardProfile`.
- Call `SD_MMC.begin(...)`.
- Verify card presence, card type, and capacity.
- Open, write, flush, and close CSV log files.
- Use the board performance profile's `bdq_chunk_bytes` target for compact BDQ
  data chunks. The default production target is 16 KiB; the writer falls back
  to smaller allocations at log start if necessary.
- Write each completed BDQ data chunk as one contiguous filesystem write while
  retaining the existing independently CRC-protected BDQ chunk format.
- Record bounded storage-write stall evidence in the BDQ final summary when
  timing instrumentation is enabled.
- Provide common text-file helpers used by config and metadata:
  - `StorageManager_loadTextFile(...)`
  - `StorageManager_saveTextFile(...)`

## 5. Consumers

Other modules should not hold storage backend pointers. They should either:

- use `StorageManager_loadTextFile(...)` / `StorageManager_saveTextFile(...)` for simple text files, or
- use `SD_MMC` directly where streaming/directory APIs are needed, such as file browser and transform routes.

## 6. Summary

- SDMMC is the only supported logger storage backend.
- `SD_MMC` / Arduino `File` is the only active filesystem API.
- SPI/SdFat support has been removed to reduce flash use and simplify maintenance.
- Board profiles remain the source of SDMMC pin configuration.

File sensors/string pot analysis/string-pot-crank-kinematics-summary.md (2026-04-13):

# String Pot Crank-Drive Kinematics Summary

## Original briefing

You described a **string potentiometer driven by a crank arrangement** with:

- crank pin offset: \(r\)
- distance from crank centre of rotation to the fixed entry point of the string pot: \(l\)

This differs from the classical slider-crank because there is **no fixed-length connecting rod**. Instead:

- the "connecting rod" is effectively the **string itself**
- the string length **changes continuously**
- one end of the string remains at a **fixed point** at the string pot entry

You asked for expressions for the **displacement, velocity, and acceleration** of the string, and then for the specific case:

- \(r = 75\,\text{mm}\)
- \(l = 500\,\text{mm}\)

you asked for:

1. peak velocity as a function of crank RPM
2. the maximum error between the exact displacement and a sinusoidal approximation
3. peak acceleration as a function of RPM, including values at **250 RPM** and **350 RPM**

---

## Geometry and exact string length

Take the crank centre as the origin, and place the fixed string entry point at \((l,0)\). If the crank angle is \(\theta\), then the crank pin position is:

\[
P = (r\cos\theta,\; r\sin\theta)
\]

The fixed string entry point is:

\[
E = (l,0)
\]

The exact string length is the distance from \(P\) to \(E\):

\[
s(\theta) = \sqrt{(l-r\cos\theta)^2 + (r\sin\theta)^2}
\]

which simplifies to:

\[
\boxed{s(\theta)=\sqrt{l^2+r^2-2lr\cos\theta}}
\]

If displacement is measured relative to the minimum string length, then for \(l>r\):

\[
s_{\min}=l-r
\]

so the string displacement is:

\[
\boxed{x(\theta)=s(\theta)-(l-r)}
\]

The maximum string length is:

\[
s_{\max}=l+r
\]

so the total stroke is:

\[
\boxed{s_{\max}-s_{\min}=2r}
\]

---

## Exact velocity

Let crank angular speed be \(\omega=\dot\theta\). Then:

\[
\dot x = \dot s = \frac{ds}{d\theta}\,\dot\theta
\]

Differentiating gives:

\[
\boxed{v(\theta)=\dot x = \frac{lr\,\omega\,\sin\theta}{\sqrt{l^2+r^2-2lr\cos\theta}}}
\]

---

## Exact acceleration

For the general case with angular acceleration \(\alpha = \ddot\theta\):

\[
\ddot x = \ddot s = \frac{lr\sin\theta}{s}\,\alpha + \left(\frac{lr\cos\theta}{s} - \frac{l^2r^2\sin^2\theta}{s^3}\right)\omega^2
\]

where:

\[
s = \sqrt{l^2+r^2-2lr\cos\theta}
\]

For **constant crank speed** (the case used for the peak-acceleration results below), \(\alpha=0\), so:

\[
\boxed{a(\theta)=\ddot x = \left(\frac{lr\cos\theta}{s} - \frac{l^2r^2\sin^2\theta}{s^3}\right)\omega^2}
\]

---

## Special case: \(r=75\,\text{mm},\; l=500\,\text{mm}\)

---

## Peak velocity as a function of crank RPM

Using:

\[
\omega = \frac{2\pi N}{60}
\]

where \(N\) is crank speed in RPM, the exact velocity is:

\[
v(\theta)=\frac{lr\,\omega\,\sin\theta}{\sqrt{l^2+r^2-2lr\cos\theta}}
\]

For \(l>r\), the peak velocity magnitude occurs at:

\[
\cos\theta = \frac{r}{l}
\]

For this geometry:

\[
\cos\theta = \frac{75}{500}=0.15
\quad\Rightarrow\quad
\theta \approx 81.37^\circ
\]

and the peak velocity magnitude simplifies exactly to:

\[
\boxed{|v|_{\max}=r\omega}
\]

Therefore:

\[
\boxed{|v|_{\max}=75\left(\frac{2\pi N}{60}\right)\;\text{mm/s}}
\]

which can be written as:

\[
\boxed{|v|_{\max}=2.5\pi N\;\text{mm/s}}
\]

Numerically:

\[
\boxed{|v|_{\max}\approx 7.854\,N\;\text{mm/s}}
\]

or:

\[
\boxed{|v|_{\max}\approx 0.007854\,N\;\text{m/s}}
\]

Examples:

- 60 RPM -> 471.2 mm/s
- 100 RPM -> 785.4 mm/s
- 120 RPM -> 942.5 mm/s

---

## Sinusoidal displacement approximation and its maximum error

For large \(l/r\), the natural sinusoidal approximation is:

\[
\boxed{x_{\sin}(\theta)=r(1-\cos\theta)}
\]

For this geometry:

\[
\boxed{x_{\sin}(\theta)=75(1-\cos\theta)\;\text{mm}}
\]

The exact-minus-sinusoid error is:

\[
e(\theta)=x(\theta)-x_{\sin}(\theta)
\]

which becomes:

\[
e(\theta)=\sqrt{l^2+r^2-2lr\cos\theta}-l+r\cos\theta
\]

The maximum error occurs at:

\[
\cos\theta = \frac{r}{2l}
\]

For this geometry:

\[
\cos\theta = \frac{75}{1000}=0.075
\quad\Rightarrow\quad
\theta \approx 85.70^\circ
\]

and the maximum error is:

\[
\boxed{e_{\max}=\frac{r^2}{2l}}
\]

So here:

\[
\boxed{e_{\max}=\frac{75^2}{2\cdot 500}=5.625\;\text{mm}}
\]

This means the sinusoidal approximation underestimates the exact displacement by at most:

\[
\boxed{5.625\;\text{mm}}
\]

Equivalent interpretations:

- **3.75% of full stroke** (150 mm)
- **7.5% of half-stroke amplitude** (75 mm)

At the exact mid-stroke point:

\[
x_{\text{exact}}=75\;\text{mm}, \qquad x_{\sin}=69.375\;\text{mm}
\]

so the difference is exactly 5.625 mm.

---

## Peak acceleration as a function of crank RPM

Assuming **constant crank speed**, the exact acceleration is:

\[
a(\theta)=\left(\frac{lr\cos\theta}{s} - \frac{l^2r^2\sin^2\theta}{s^3}\right)\omega^2
\]

For \(l>r\), the **maximum positive acceleration** occurs at \(\theta=0\):

\[
\boxed{a_{\max}=\frac{lr}{l-r}\,\omega^2}
\]

The most negative acceleration occurs at \(\theta=\pi\):

\[
\boxed{a_{\min}=-\frac{lr}{l+r}\,\omega^2}
\]

So the peak magnitude is:

\[
\boxed{|a|_{\text{peak}}=\frac{lr}{l-r}\left(\frac{2\pi N}{60}\right)^2}
\]

For \(r=75\,\text{mm}\), \(l=500\,\text{mm}\):

\[
\frac{lr}{l-r}=\frac{500\cdot 75}{500-75}=88.235294\;\text{mm}
\]

so:

\[
\boxed{|a|_{\text{peak}}=88.235294\left(\frac{2\pi N}{60}\right)^2\;\text{mm/s}^2}
\]

which simplifies numerically to:

\[
\boxed{|a|_{\text{peak}}\approx 0.96761\,N^2\;\text{mm/s}^2}
\]

or:

\[
\boxed{|a|_{\text{peak}}\approx 9.6761\times 10^{-4}\,N^2\;\text{m/s}^2}
\]

### At 250 RPM

\[
|a|_{\text{peak}}\approx 0.96761(250)^2 = 60475.5\;\text{mm/s}^2
\]

\[
\boxed{|a|_{\text{peak}}\approx 60.48\;\text{m/s}^2}
\]

### At 350 RPM

\[
|a|_{\text{peak}}\approx 0.96761(350)^2 = 118532.0\;\text{mm/s}^2
\]

\[
\boxed{|a|_{\text{peak}}\approx 118.53\;\text{m/s}^2}
\]

### Most negative acceleration for completeness

For this geometry:

\[
\frac{lr}{l+r}=\frac{500\cdot 75}{575}=65.21739\;\text{mm}
\]

so:

\[
a_{\min} \approx -0.71519\,N^2\;\text{mm/s}^2
\]

Numerically:

- 250 RPM -> \(-44.70\,\text{m/s}^2\)
- 350 RPM -> \(-87.61\,\text{m/s}^2\)

---

## Final compact results

### Exact kinematics

\[
\boxed{s(\theta)=\sqrt{l^2+r^2-2lr\cos\theta}}
\]

\[
\boxed{x(\theta)=\sqrt{l^2+r^2-2lr\cos\theta}-(l-r)}
\]

\[
\boxed{v(\theta)=\frac{lr\,\omega\,\sin\theta}{\sqrt{l^2+r^2-2lr\cos\theta}}}
\]

\[
\boxed{a(\theta)=\left(\frac{lr\cos\theta}{s}-\frac{l^2r^2\sin^2\theta}{s^3}\right)\omega^2}
\qquad (\text{constant } \omega)
\]

with:

\[
s=\sqrt{l^2+r^2-2lr\cos\theta}
\]

### For \(r=75\,\text{mm},\; l=500\,\text{mm}\)

Peak velocity:

\[
\boxed{|v|_{\max}=2.5\pi N\;\text{mm/s}\approx 7.854N\;\text{mm/s}}
\]

Maximum sinusoid error:

\[
\boxed{e_{\max}=5.625\;\text{mm}}
\]

Peak acceleration:

\[
\boxed{|a|_{\text{peak}}\approx 0.96761N^2\;\text{mm/s}^2}
\]

or:

\[
\boxed{|a|_{\text{peak}}\approx 9.6761\times 10^{-4}N^2\;\text{m/s}^2}
\]

with:

- \(250\,\text{RPM} \rightarrow 60.48\,\text{m/s}^2\)
- \(350\,\text{RPM} \rightarrow 118.53\,\text{m/s}^2\)

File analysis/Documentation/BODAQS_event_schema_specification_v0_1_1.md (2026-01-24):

# BODAQS Event Schema Specification v0.1 (updated: segment role dicts)

This document specifies the YAML schema used by the BODAQS analysis pipeline to define event detection,
segmentation defaults, and metric extraction.

This update introduces **registry-first, no-fallback** segment role definitions (Option B):
`segment_defaults.roles` must be expressed in **dict form** with a `prefer` selector that is **sensor-relative**
(i.e., the sensor is bound from the event instance / anchor signal, not hard-coded in the schema).

---

## 1. Key concepts

### 1.1 Signals and the signal registry
The analysis pipeline maintains a canonical signal registry at:

- `session["meta"]["signals"]`

The registry maps **dataframe columns** → semantic metadata, including (at minimum):

- `sensor` (e.g. `rear_shock`, `front_shock`)
- `quantity` (e.g. `disp`, `vel`, `acc`, `raw`)
- `unit` (e.g. `mm`, `mm/s`, `mm/s^2`, `counts`)
- `kind` (e.g. `""` engineered, `raw`, `qc`)
- `op_chain` (list of operations/variants applied, e.g. `["zeroed"]`)

All downstream components must resolve signals **via the registry**. No suffix-guessing or fallback concatenation.

### 1.2 Events are expanded per sensor
An event definition can list multiple sensors. During event detection, each event is expanded into one row per sensor.
Event rows are expected to include an anchor signal column (commonly `signal_col`) that identifies the sensor for that
event instance.

---

## 2. Top-level YAML structure

Top-level keys:

- `specification`: schema specification version (string)
- `version`: schema file revision (string)
- `naming`: naming/suffix conventions (legacy; discouraged for role resolution)
- `defaults`: global defaults for triggers/windows/metrics
- `series`: named series definitions (optional)
- `events`: list of event definitions

---

## 3. Event definition

Each entry in `events` is an object with (common fields):

- `id` (string, stable key used in `events_df["schema_id"]`)
- `label` (string, human-readable)
- `sensors` (list[str], e.g. `["rear_shock", "front_shock"]`)
- `trigger` (definition of primary trigger)
- `preconditions` (optional constraints)
- `window` (time window defaults for detection)
- `metrics` (metric definitions)
- `tags` (optional)
- `segment_defaults` (defaults used by `extract_segments` / segment viewer)

---

## 4. segment_defaults

`segment_defaults` provides defaults used when extracting segments for events of a given schema id.

### 4.1 segment_defaults fields

- `anchor` (string): which timestamp field anchors the segment (commonly `trigger_time_s`)
- `window` (object): segment window, in seconds
  - `pre_s` (float)
  - `post_s` (float)
- `roles` (list[RoleDef]): **required in registry-first mode**

### 4.2 RoleDef (dict form)

Each entry in `segment_defaults.roles` MUST be a dict with:

- `role` (string): output role name in the segment bundle (e.g. `disp`, `vel`, `raw`)
- `prefer` (dict): registry selector constraints

`prefer` MUST include:

- `quantity` (string): one of `disp`, `vel`, `acc`, `raw`, ...

`prefer` MAY include:

- `unit` (string): e.g. `mm`, `mm/s`, `counts`
- `kind` (string): `""` (engineered), `raw`, `qc`
- `op_chain` (list[str]): operation/variant chain, e.g. `["zeroed"]`, `["norm"]`

Note: Operation tokens in op_chain are canonicalised (zeroed, norm, …).
Implementations MAY accept legacy tokens prefixed with op_ and normalize them internally, but schemas SHOULD use canonical tokens.

In v0.1.1+, `segment_defaults.roles` MUST be specified in dictionary form.

Each role entry MUST include a `prefer` block with at least:
- `quantity`
- `unit`

`sensor` MAY be omitted; 
- The sensor is bound from the **event instance** (via its anchor signal / `signal_col` and the registry).
- This avoids duplicating role lists per sensor and keeps schemas sensor-agnostic.

### 4.3 Resolution rules (Option B)

When extracting segments for a specific event row:

1. Determine the event sensor from the anchor signal column (e.g. `signal_col`) via `meta["signals"][signal_col]["sensor"]`.
2. For each RoleDef, resolve the dataframe column by matching registry entries on:
   - the event sensor (bound at runtime)
   - `prefer.quantity`
   - and any optional `prefer` fields (`unit`, `kind`, `op_chain`)
3. Resolution must be **deterministic**:
   - 0 matches → error (missing signal)
   - >1 matches → error (ambiguous signal)

String roles (e.g. `roles: ["disp", "vel"]`) are **not permitted** in registry-first mode.

### Normalised displacement (`disp_norm`)

`disp_norm` is a **role name**, not a physical quantity.

Semantics:
- `quantity`: `disp`
- `unit`: `"1"` (dimensionless)
- `op_chain`: typically `["zeroed", "norm"]`

Example role specification:

```yaml
- role: disp_norm
  prefer:
    quantity: disp
    unit: "1"
    op_chain: [zeroed, norm]

---

## 5. Example (segment_defaults.roles)

```yaml
segment_defaults:
  anchor: trigger_time_s
  window: { pre_s: 0.2, post_s: 0.8 }
  roles:
    - role: disp
      prefer: { quantity: disp, unit: mm, op_chain: [zeroed] }
    - role: vel
      prefer: { quantity: vel, unit: mm/s, op_chain: [zeroed] }
    - role: raw
      prefer: { quantity: raw, unit: counts, kind: raw }
```

---

# End of document

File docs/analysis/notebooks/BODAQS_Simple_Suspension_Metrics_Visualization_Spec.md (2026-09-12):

# Session Browser Suspension Visualization Specification

Status: draft for manual review  
Audience: BODAQS browser / Library API / visualization implementation agents  
Prototype target: session browser extension in the React/TypeScript browser app  

## 1. Purpose

This document specifies the next visualization direction for BODAQS suspension
comparison views. It replaces the earlier notebook-first implementation target:
the prototype should be built as an extension to the browser session/study-set
browser, using the browser visualization stack already adopted for the web
application.

The goal is a clean but flexible comparison view for suspension signals,
metrics, event counts, and distributions, starting from a Study Set scope.

The core visualization grammar has two explicit analysis modes:

- **Session view** consumes enabled sessions and groups, optional per-session
  time windows, and one or more Scenario populations. Its comparison dimensions
  are entity, suspension end, and Scenario.
- **Track view** consumes one enabled track and only enabled individual sessions
  that have a valid crossing pair for at least one selected sector. Its
  comparison dimensions are session, suspension end, and sector. Groups,
  unmatched sessions, time windows, and Scenarios are retained but inactive.
- In either mode, the three active comparison dimensions are assigned
  bijectively to `across`, `down`, and `on_chart`. Series colour follows the
  `on_chart` dimension.
- Each quantity or chart family lives in a vertically collapsible panel.

The first implementation should feel like a high-value quick view, not a
general pivot-table builder. It should nevertheless use data and component
shapes that can later support saved visualization setups and a richer comparison
builder.

## 2. Current Context

Assume the following are already available:

- a BODAQS artifact library exposed through the current Library API service
- a Study Set selected or loaded in the browser app
- Study Set entities consisting of explicit sessions and optional groupings
- processed sessions containing signal data, event tables, metrics, and
  metadata
- optional track/trackpoint sector information for sessions where geospatial
  matching has been performed

Implementation target:

```text
application/cohort-workbench-prototype/
```

Relevant current stack:

- Vite
- React
- TypeScript
- plain CSS / application CSS
- `@tanstack/react-table` for table behavior where useful
- `d3` for scales, binning, and custom visualization helpers
- `@observablehq/plot` for fast distribution/scatter experiments where useful
- `uPlot` for dense time-series views where useful
- `lucide-react` for icons

The existing Python/Jupyter simple suspension metrics dashboard remains useful
as a reference for semantics, selectors, metric defaults, and summary
calculations. It is not the prototype implementation target for this work.

Implementation checkpoint:

- Browser entry point from the Study Set `Analyze` modal is implemented.
- Whole-session displacement and velocity distribution panels are implemented.
- Whole-session event counts are implemented as tables.
- Whole-session compression and rebound scatter panels are implemented.
- Compression and rebound scatter panels include best-fit lines, equations, and
  `R^2` summaries.
- The view supports a comparison layout toggle:
  - `Entities as columns`: front/rear overlaid inside each entity tile.
  - `Ends as columns`: selected entities overlaid inside front/rear tiles.
- A sector-mode UI scaffold is implemented. It lists the selected track and
  trackpoint-bounded sectors.
- Initial sectorized displacement and velocity distributions are implemented.
  The browser assigns raw signal samples to sectors using trackpoint
  crossing-time intervals from loaded track match summaries, then renders
  front/rear mini ridgeline distributions by sector.
- The earlier whole-session/sector toggle and two-way comparison-layout toggle
  are superseded by Session view and Track view plus the shared three-dimension
  comparison assignment.
- Session view supports multiple independently evaluated Scenario populations
  and an explicit `All qualifying data` baseline. Scenario populations may
  overlap and are not presented as additive.
- Track view requires a single enabled track. Only enabled individual sessions
  with valid bounding-trackpoint crossings for the selected sector are charted.
- The mode, enabled scope items, mode-specific filters, and comparison
  assignments are retained in browser visualization settings.

## 3. Architecture Direction

The browser should own interaction and chart rendering. The Library API should
serve catalog, Study Set, signal, event, metric, and time-series data in stable
payloads without requiring the browser to understand artifact paths.

For this view, the browser may compute lightweight visualization transforms
such as:

- histogram bins from raw or raw-equivalent samples
- ridgeline density/bin geometry
- chart scales and layout
- front/rear styling
- entity visibility
- panel collapse state

The Library API should be used for data access and heavier or cross-session
work where browser-side computation would be slow, lossy, or require artifact
knowledge.

Important constraint:

Do not build distributions from display-decimated time-series payloads unless
the endpoint explicitly preserves distribution correctness. A decimated trace is
good for drawing a line; it is not necessarily valid input for histograms,
percentiles, or ridgelines.

## 4. Non-goals For The First Version

Do not implement the following in the first version unless explicitly requested:

- a general-purpose pivot table builder
- saved visualization specifications
- arbitrary time-window comparison across multiple sessions
- syn.bike-style displacement navigation bar
- time matching between sessions
- sector data slicing / ridgeline rendering
- sector support for compression/rebound metric scatter plots
- authoring or editing Study Sets from this visualization view
- changing canonical Study Set membership from visualization controls
- notebook/Jupyter implementation of the new layout

The syn.bike-style single-session time-window navigator is a roadmap item. It
may be introduced later as an ad-hoc visualization-only scope refinement when
exactly one session entity is active.

## 5. Key Concepts

### 5.1 Visualization Entity

A visualization entity is either:

- a single processed session
- a Study Set grouping

Sessions and groupings should be listed together in visualization controls.
Groupings are deselected by default. Users may turn entities on/off for the
current visualization without changing Study Set membership.

### 5.2 Grouping Semantics

When a Study Set grouping is visualized as one entity, use pooled raw
samples/events from its member sessions.

Examples:

- displacement distribution for a grouping pools matching displacement samples
  from the grouping's member sessions
- velocity distribution for a grouping pools matching velocity samples
- event counts for a grouping count matching events from all member sessions
- scatter plots for a grouping plot pooled event/metric rows from all member
  sessions unless this proves visually misleading

Grouping behavior is allowed only where pooling is meaningful. If a chart type
cannot represent a grouping safely, show a clear disabled/unsupported message
for that entity rather than silently choosing a misleading behavior.

### 5.3 Signal Role

Signal role is the front/rear distinction.

Front and rear are first-class visualization roles, not generic aggregation
dimensions. They should not be pooled into one combined distribution. They may
be shown on the same chart, adjacent within an entity, or both, depending on
chart type.

Use fixed front/rear colors globally across the browser app.

Recommended initial colors:

- front: BODAQS teal
- rear: black or a dark neutral

Exact color tokens should be aligned with the broader BODAQS UI styling once
design tokens exist.

### 5.4 Sector

A sector is a track-ordered subdivision derived from trackpoints / track
matching. In visualizations, sectors are ordered by track order almost always.

If a session/entity has no data for a sector, keep the sector row visible but
empty/faint so track order remains stable across entities.

### 5.5 View Scope

The first implementation should support:

- whole selected entities
- optional sector breakdown where implemented

Do not implement ad-hoc time-window scope in the first version. Keep it on the
roadmap as a single-session-only refinement.

## 6. Overall Browser Layout

Add the suspension visualization as a mode or panel within the session browser /
Study Set browser area. The user should be able to move from a loaded Study Set
to visualization without re-selecting the library root or Study Set.

The visualization view is a vertical stack of collapsible panels.

Initial panels:

- Displacement distribution
- Velocity distribution
- Event counts
- Compression metrics
- Rebound metrics

Each panel uses a horizontal entity strip:

```text
Panel title / controls
------------------------------------------------------------
| Entity A | Entity B | Entity C | ...
------------------------------------------------------------
```

The entity strip should scroll horizontally if it exceeds available width.
Do not paginate in the first implementation unless horizontal scrolling proves
unworkable.

The browser visualization uses one shared comparison-layout control. Each
active mode supplies exactly three dimensions, and the user assigns each one
to exactly one of `across`, `down`, and `on_chart`. Reassigning a dimension
swaps it with the dimension already occupying that placement, so the layout is
always valid.

Session-view defaults are entity across, Scenario down, and suspension end on
chart. Track-view defaults are sector across, session down, and suspension end
on chart. A singleton `down` dimension is visually collapsed rather than
adding an empty-looking facet tier.

Within each entity, front/rear comparison is arranged according to the chart
type:

- distribution whole-entity mode: front/rear may be overlaid on one chart
- distribution sector mode: front/rear should be adjacent horizontally within
  the entity, with sectors arranged vertically
- scatter metrics: front/rear may be on the same chart
- event counts: front/rear should be presented in a table

Sector breakdown, where available, is vertical:

```text
Entity tile
------------------------------------------------
Front                         Rear
Sector 1   chart/row          Sector 1   chart/row
Sector 2   chart/row          Sector 2   chart/row
Sector 3   chart/row          Sector 3   chart/row
```

This sector-mode rule supersedes any earlier design idea that front/rear should
be stacked vertically.

## 7. Shared Axis And Scale Rules

Use shared axes where comparison depends on scale.

Default scale rules:

- distribution panel x-axis: shared across all entity tiles
- distribution panel y-axis: shared within comparable chart rows where relevant
- displacement normalized x-axis: fixed `0..1`
- velocity x-axis: symmetric around zero, with a fixed default limit unless
  explicitly changed
- metric scatter axes: shared across all entity tiles in the panel
- event count tables: no chart y-axis; counts are tabular because they may span
  several orders of magnitude

Where an axis is fixed by domain semantics, prefer the fixed value over
autoscaling. Where autoscaling is needed, compute panel-level shared extents
before rendering entity tiles.

## 8. Panel Specifications

### 8.1 Displacement Distribution Panel

Purpose:

Show normalized suspension displacement distributions and summary displacement
statistics for selected entities.

Inputs:

- selected visualization entities
- front displacement signal selector
- rear displacement signal selector
- optional engineering-unit displacement source for stats
- optional sector assignments

Whole-entity mode:

- one tile per selected entity
- front and rear shown on the same histogram chart
- x-axis is normalized displacement, fixed `0..1`
- y-axis is shared across entity tiles
- summary stats shown per entity and per role

End-faceted mode:

- one tile for front and one tile for rear
- selected entities are overlaid as colored distribution series within each end
- x/y scale rules remain panel-level shared

Sector mode:

- one tile per selected entity
- front and rear arranged horizontally inside the tile
- sectors arranged vertically in track order
- each front/rear role uses ridgeline-style distributions by sector
- empty sectors remain visible and faint

Summary stats:

- dynamic sag / median
- 95th percentile
- maximum travel
- interquartile range
- skew

Stats should continue to show normalized values. If engineering-unit values are
available, show paired normalized/mm values as the current Python dashboard
does.

### 8.2 Velocity Distribution Panel

Purpose:

Show suspension velocity distributions for selected entities.

Inputs:

- selected visualization entities
- front velocity signal selector
- rear velocity signal selector
- optional sector assignments

Whole-entity mode:

- one tile per selected entity
- front and rear shown on the same histogram chart
- x-axis is velocity in `mm/s`
- x-axis is symmetric around zero
- default fixed absolute limit may remain the current Python dashboard's
  default unless changed during implementation
- y-axis is shared across entity tiles

End-faceted mode:

- one tile for front and one tile for rear
- selected entities are overlaid as colored distribution series within each end
- x/y scale rules remain panel-level shared

Sector mode:

- one tile per selected entity
- front and rear arranged horizontally inside the tile
- sectors arranged vertically in track order
- each front/rear role uses ridgeline-style distributions by sector

### 8.3 Event Counts Panel

Purpose:

Show event counts by entity and front/rear role.

Reasoning:

Event counts may span several orders of magnitude, so tabular display is
preferred over bar charts for the first version.

Inputs:

- selected visualization entities
- front event signal selector
- rear event signal selector
- event table data
- optional sector assignments, if later extended

Whole-entity mode:

- one tile per selected entity or one table spanning entities
- counts grouped by event type and front/rear role
- groupings use pooled events

Sector mode:

- optional for later implementation
- if implemented, sectors are vertical and ordered by track order
- counts remain tabular

### 8.4 Compression Metrics Panel

Purpose:

Show compression metric relationships for selected entities.

Current default:

- event type: `compressions_all`
- x metric: `m_stroke_disp_max`
- y metric: `m_interval_vel_max`

Whole-entity mode:

- one tile per selected entity
- front and rear may be shown on the same scatter chart
- shared x/y axes across all entity tiles
- regression/fit overlays may remain if already supported and meaningful

End-faceted mode:

- one tile for front and one tile for rear
- selected entities are overlaid as colored scatter series within each end
- best-fit lines, equations, and `R^2` are shown per entity series when enough
  points are available

Sector mode:

- defer in first version
- future behavior: facet vertically by sector
- do not implement sector support for compression scatter in the first slice

### 8.5 Rebound Metrics Panel

Purpose:

Show rebound metric relationships for selected entities.

Current default:

- event type: `rebounds_all`
- x metric: `m_stroke_disp_max`
- y metric: `m_interval_vel_min`

Whole-entity mode:

- one tile per selected entity
- front and rear may be shown on the same scatter chart
- shared x/y axes across all entity tiles
- regression/fit overlays may remain if already supported and meaningful

End-faceted mode:

- one tile for front and one tile for rear
- selected entities are overlaid as colored scatter series within each end
- best-fit lines, equations, and `R^2` are shown per entity series when enough
  points are available

Sector mode:

- defer in first version
- future behavior: facet vertically by sector
- do not implement sector support for rebound scatter in the first slice

## 9. Browser Data Shape

Create browser-side domain types for visualization records. These may be built
from multiple API responses, but downstream chart components should consume a
tidy shape rather than raw service payloads.

Recommended record shape:

```text
entity_id
entity_label
entity_type          session | grouping
source_session_ref_id
source_session_key
source_run_id
source_session_id
signal_role          front | rear
sector_id
sector_label
sector_order
quantity             displacement | velocity | event_count | event_metric
value
unit
metric_name
event_type
time_s
```

Not every field is required for every panel. Missing fields should be explicit
null/empty values rather than inferred from labels.

Recommended TypeScript locations:

```text
application/cohort-workbench-prototype/src/domain/
application/cohort-workbench-prototype/src/components/
```

Prefer keeping data shaping in domain/helper modules and rendering in chart
components. Avoid embedding Library API response handling deeply inside visual
components.

## 10. API And Data Access Requirements

### 10.1 Existing API To Reuse

Use the current Library API for:

- library/catalog loading
- Study Set loading
- session references and entity membership
- event and metric query endpoints where available
- time-series windows for trace-style views where downsampling is acceptable
- track/trackpoint metadata where needed

### 10.2 Distribution Data Requirement

Histogram, percentile, and ridgeline views require distribution-correct data.

Acceptable first-version approaches:

- add or use a Library API signal query endpoint that returns raw or
  distribution-correct samples for selected sessions/signals
- add a Library API distribution endpoint that returns bin counts and summary
  stats for selected sessions/signals
- use `timeseries/window` only if the requested payload is not display-decimated
  or the endpoint explicitly returns distribution-correct samples

Do not silently compute histograms or summary stats from min/max bucket
decimated trace data.

### 10.3 Event And Metric Data Requirement

Compression/rebound scatter and event count panels require event/metric rows for
the selected entities.

If `events/query` and `metrics/query` are already implemented, use them. If not,
the first implementation should add minimal table-oriented API support rather
than reading artifacts directly in the browser.

### 10.4 Grouping Resolution

The browser may resolve a grouping into member session references from the Study
Set object. API requests can then be made per member session and pooled in the
browser, provided the data volume remains acceptable.

If grouping data volumes become large, move pooling/summary work server-side in
a later slice.

## 11. User Controls

Current controls:

- entry point from the session browser / Study Set browser
- analysis scope containing independently enabled sessions, groupings, and at
  most one track; groupings are deselected by default
- inactive-period exclusion in the scope block
- Session view / Track view mode selector, with Session view as the default
- Session view: optional per-session time windows and one or more Scenario
  populations, including `All qualifying data`
- Track view: trackpoint-bounded sector selection; only enabled matched
  individual sessions qualify
- comparison assignment requiring the mode's entity, end, and Scenario/sector
  dimensions to use `across`, `down`, and `on_chart` exactly once
- panel collapse/expand
- engineering-unit display option for displacement stats if engineering-unit
  values are available

Nice-to-have but not required for first implementation:

- select all sessions
- select all groupings
- reset entity visibility
- per-panel chart options
- save visualization setup
- single-session time-window navigator

Visualization scope and presentation selection are local to the visualization
view and must not mutate the Study Set. Mode-inapplicable settings are preserved
so switching modes does not discard the user's previous setup.

## 12. Implementation Plan

### Slice 1: Browser Shell And Entity-First Whole-Session View

Status: implemented

Goal:

Add the suspension visualization view to the browser session/study-set browser
with whole-session entity-first panels and no sector mode.

Expected work:

- add a session-browser visualization entry point
- add visualization entity selection backed by the loaded Study Set
- list sessions and groupings together, with groupings deselected by default
- create collapsible panel components
- create horizontally scrolling entity strips
- add browser-side data/domain helpers for entity, role, and panel data
- implement whole-session displacement and velocity distribution panels
- implement event counts as tabular display
- implement compression and rebound scatter panels with front/rear on the same
  chart per entity
- use fixed front/rear colors

Acceptance criteria:

- user can open the visualization view from a loaded Study Set/session browser
  context
- user can select one or more session entities for visualization
- groupings appear but are deselected by default
- enabling a grouping pools member-session samples/events where supported
- displacement and velocity panels compare front/rear within each entity
- compression and rebound panels show front/rear on the same chart per entity
- event counts are readable as tables
- axes are shared at panel level where specified
- large selections scroll horizontally rather than breaking layout
- frontend build passes

### Slice 1A: Comparison Layout Flip

Status: implemented, then superseded by Slice 4's three-dimension grammar

Goal:

Allow the user to flip the two primary comparison dimensions without changing
the selected Study Set entities.

Expected work:

- add a comparison-layout control
- keep `Entities as columns` as the default mode
- add `Ends as columns` mode for distribution and metric scatter panels
- overlay selected entities as colored series inside front/rear tiles
- keep event counts table-oriented

Acceptance criteria:

- user can switch between entity-faceted and end-faceted layouts at runtime
- no new API request is required when only the layout changes
- distribution panels remain scale-comparable across the panel
- compression and rebound scatter panels keep shared axes and regression
  summaries in both modes

### Slice 5: Session/Track Modes And Three-Dimension Comparison

Status: implemented

Goal:

Separate filtering semantics that are valid in session time from comparisons
that require one matched track, while giving SSA and SPD the same compact
faceting grammar.

Implemented behavior:

- Scope independently enables sessions, groups, and one track; inactive-period
  exclusion remains a convenient scope-level control.
- Session view applies time windows and supports multiple Scenario populations,
  including a null-Scenario baseline.
- Track view ignores groups and unmatched sessions and applies selected sectors
  using conservative bounding-trackpoint crossing times.
- Each mode assigns its three active dimensions to `across`, `down`, and
  `on_chart` exactly once, with swap-on-selection behavior.
- The generic faceting path is shared by distributions, event counts, metric
  scatter charts, and phase-diagram variants.
- Mode-specific settings are preserved while inactive, and older saved
  whole-session/sector settings migrate to the corresponding mode.

### Slice 6: Population And Scenario Caching

Status: initial implementation complete

Session time windows, inactive-period exclusion, and Scenario Episodes are
represented in the browser as reusable population selections over immutable
source arrays. The implementation:

- compiles the combined selection into a compact per-session byte mask only
  when a chart first needs sample values;
- caches chart-ready selected values against the stable population view;
- retains bounded population-view and Scenario-evaluation caches;
- caches Scenario requests independently so adding another Scenario comparison
  reuses evaluations already loaded in the browser; and
- invalidates browser Scenario cache identity when the underlying suspension
  analysis cache is invalidated.

The Library API caches Scenario evaluation at both the complete-request and
individual-session levels. Multi-session responses are composed from those
session entries, so changing scope or reprocessing one session does not require
re-evaluating unaffected sessions. Cache timing and hit/miss diagnostics are
available through the existing service diagnostics and the browser's
`bodaqs.debug.suspension-cache` debug switch.

Activity eligibility has a separate, disposable per-session run index derived
from the canonical activity mask. It is built lazily, shared across Scenario
definitions, persisted only as a rebuildable service cache entry, and keyed by
the session data and metadata artifact identities. The regression corpus shows
that this run representation remains very small even for the longest current
sessions. Proactive all-Scenario mask generation, a general decoded-column
cache, and startup prewarming remain deferred until measurements demonstrate a
need.

### Slice 2: API Hardening For Chart-Ready Data

Status: minimal implementation complete; continue hardening as data volume and
sector requirements become clearer

Goal:

Ensure the browser is receiving statistically valid data for distributions,
events, and metrics.

Expected work:

- review existing `signals/query`, `events/query`, `metrics/query`, and
  `timeseries/window` behavior
- add minimal API support if needed for distribution-correct samples or
  server-computed distribution bins
- add request/response types in the browser data source layer
- add tests for data-source mapping and distribution correctness assumptions

Acceptance criteria:

- displacement and velocity histograms are not built from display-decimated
  data
- event count inputs include all relevant events for selected entities
- scatter inputs include matching event/metric rows
- browser components consume stable typed data-source methods rather than ad
  hoc fetch calls

### Slice 3A: Sector Mode UI Scaffold

Status: implemented

Goal:

Expose sector mode in the visualization UI without pretending sector data
slicing is complete.

Expected work:

- add a visualization scope control: whole session vs by sector
- use Study Set `trackIds` and loaded track records to select a track
- derive trackpoint-bounded sector rows from ordered trackpoints
- show sector rows in displacement and velocity panels when sector mode is
  selected
- show clear deferred-state messaging for metric scatter panels

Acceptance criteria:

- sector mode is disabled or unavailable when no track is attached
- track selection appears when sector mode is active
- displacement and velocity panels show ordered sector scaffold rows
- compression and rebound panels clearly state that sector scatter is deferred
- frontend build passes

### Slice 3B: Add Distribution Sector Data And Ridgelines

Historical note: the acceptance criteria and limitations below describe the
original sector-scaffold slice. Slice 5 supersedes its grouping, layout, and
panel-coverage constraints with Track view and the generic comparison grammar.

Status: initial browser-side implementation complete

Goal:

Add real sector breakdown for displacement and velocity distributions.

Expected work:

- use `signals/query` raw time arrays for sample timestamps
- use loaded track match summaries for per-session trackpoint crossing times
- assign displacement/velocity samples to sectors in the browser when both
  bounding trackpoints have valid crossing times
- produce ridgeline-style distributions by sector
- keep sector rows stable and ordered by track order
- show empty rows/cells for missing sector data

Acceptance criteria:

- sector mode affects displacement and velocity panels first
- sector mode works for one session and multiple sessions
- entities remain arranged horizontally
- front/rear are adjacent horizontally within entity tiles
- sectors are vertical and ordered by track order
- groupings pool samples by sector where sector assignment is available
- sectors with missing crossing intervals remain visible but empty
- frontend build passes

Current limitations:

- sector assignment is browser-side and interval-based; it depends on loaded
  `SessionTrackMatchRecord.trackpointResults[].crossingTimeS` values.
- samples are assigned to the time interval between adjacent crossed
  trackpoints; this does not yet account for path direction beyond using the
  min/max crossing time as the interval.
- compression/rebound scatter sector mode remains deferred.
- event-count sector mode remains deferred.
- no server-side sector cache or chart-ready sector aggregation exists yet.

### Slice 4: Polish And Error Handling

Goal:

Make the view robust enough for routine browser use.

Expected work:

- improve loading, empty-data, and unsupported-data states
- add warnings for groupings where pooling is not meaningful
- ensure chart labels and legends remain readable
- keep layout usable on tablet-sized displays or larger
- add manual validation notes to the relevant browser handoff or README

Acceptance criteria:

- missing front/rear signals produce clear messages
- missing sector data produces clear messages
- API failures produce recoverable UI states
- large selections remain usable
- no raw exception text is shown for ordinary missing-data conditions

## 13. Testing Plan

Automated tests should be added where practical for data preparation helpers and
browser components.

Recommended frontend/unit tests:

- entity list includes sessions and groupings, with groupings deselected by
  default
- grouping distribution input pools member-session samples
- front/rear roles are kept separate and not pooled
- displacement x-axis domain remains fixed `0..1`
- sector ordering follows track order
- missing sector rows are preserved in sector-mode data
- event-count grouping pools events correctly
- data-source methods reject or flag decimated data when distribution-correct
  data is required

Recommended browser/manual tests:

- start the Library API service against a real library root
- start the Vite browser app
- load a Study Set containing one session
- open the suspension visualization view
- load a Study Set containing multiple sessions
- load a Study Set containing at least one grouping
- confirm groupings are visible but initially deselected
- enable a grouping and confirm distributions/events pool member data
- verify front/rear colors are consistent across panels
- verify horizontal scrolling works with many selected entities
- verify sector mode for displacement and velocity where sector data exists
- verify sector mode missing-data behavior where sector data does not exist

Recommended commands:

```powershell
cd C:\Users\benco\dev\BODAQS\application\cohort-workbench-prototype
npm run build
```

If API code is changed:

```powershell
cd C:\Users\benco\dev\BODAQS\analysis
..\.venv\Scripts\python.exe -m pytest
```

## 14. Assumptions

The implementation may proceed using these assumptions unless contradicted:

- "Session browser" means the React/TypeScript browser application's
  session/study-set browser area, not the Jupyter `bodaqs_session_browser`
  notebook.
- Study Set groupings are available in the loaded Study Set object.
- A grouping can be resolved to member sessions in browser state.
- Pooled raw samples/events are the correct default for grouping visualization.
- Front/rear colors should be fixed globally.
- Displacement distributions use normalized displacement as the primary x-axis.
- Track sectors, where present, have a stable order derived from track order.
- Horizontal scrolling is acceptable for entity overflow in the prototype.
- Sector support is required first for displacement and velocity only.
- Time-window navigation is omitted from the first version.

## 15. Ambiguities And Design Questions

The following should be reviewed before or during implementation:

- Exact front/rear color tokens are not finalized.
- The exact browser entry point is not specified: implementation may add a
  dedicated "Visualize" mode/tab/panel inside the current session browser /
  Study Set browser UI.
- The precise API shape for distribution-correct signal samples or server-side
  histogram bins may need to be defined before Slice 1 can be fully useful.
- The precise storage/location of per-sample sector assignments may need code
  inspection before Slice 3.
- If sector assignments are not already materialized per sample, Slice 3 may
  require a new computation/cache layer rather than only a frontend change.
- The preferred ridgeline implementation is not fixed. D3 or Observable Plot are
  both acceptable for the first browser implementation if wrapped behind a
  reusable component boundary.
- For grouping scatter plots, it is assumed that plotting all pooled events is
  acceptable. If this becomes visually noisy, a summary mode may be needed.
- Event count sector mode is intentionally deferred, but the eventual table
  layout should be revisited once sector data volume is better understood.
- Panel collapse state persistence is not specified. First implementation may
  keep it runtime-only.
- Visualization entity selection persistence is not specified. First
  implementation may keep it runtime-only.

## 16. Future Roadmap Items

Potential follow-up work:

- saved visualization setups
- advanced comparison/spec builder
- single-session displacement navigation / time-window scope
- per-entity time windows, only if a clear use case emerges
- sector support for compression/rebound metric scatter
- metric-distribution panels for compression/rebound metrics
- richer distribution forms such as violin plots
- reusable visualization-spec contract shared by notebooks and browser
- server-side chart-ready aggregation endpoints if browser-side pooling becomes
  too slow for large Study Sets

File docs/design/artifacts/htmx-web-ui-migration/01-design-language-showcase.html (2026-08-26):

# BODAQS Design Language Showcase

Reference page for the htmx web UI migration. Open this file in a browser to see all components rendered with the brand palette.

## Color Palette

### Brand Colors

--shadow-grey#212227

--dim-grey#637074

--lavender-grey#8693ab

--powder-blue#aab9cf

--pale-sky#bdd4e7

### Semantic Status Colors

success#e7f5e7 / #8bc34a

error#ffe7e7 / #e57373

warn#fff3cd / #ffe08a

## Navigation Bar

Files General Sensors

## Alerts

Configuration saved.

Error: Invalid sample rate. Must be between 1 and 2000 Hz.

Editing is disabled while logging is active. Exit upload mode or stop logging to make changes.

## Fieldsets & Form Rows

General

Logger name

Sample rate (Hz)

Log format BODAQS CSV Compact binary

Omit metadata JSON

Timestamp mode

Timezone POSIX tz rule

Network & NTP

Wi-Fi mode

AP SSID

AP password 8-63 characters

Enable Wi-Fi by default

NTP servers

## Buttons

Save Cancel Delete Disabled

### Button with htmx indicator

Save Saving... Save Saving... ← left shows "Saving..." state, right shows idle

## Table (Sensor List)

# | Name | Type | State | Output

0 | front_susp | AS5600 String Pot I2C | active | LINEAR | Edit
1 | rear_susp | AS5600 String Pot I2C | active | LINEAR | Edit
2 | front_pot | Analog Potentiometer | muted | RAW | Edit
3 | gps | DAN-F10N GPS UART | active | RAW | Edit

## Locked State (logging active)

Editing is disabled while logging is active. Exit upload mode or stop logging to make changes.

General (locked)

Logger name

Sample rate (Hz)

Save

## Mobile Preview (375px)

375px — iPhone SE / small Android

Files General Sensors

General

Logger name

Sample rate (Hz)

Wi-Fi mode

Save

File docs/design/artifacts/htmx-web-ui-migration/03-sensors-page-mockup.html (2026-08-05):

BODAQS data logger: BODAQS-Logger

Network: Access point / BODAQS-Logger IP: 192.168.4.1

Files General Sensors

## Sensors

# | Name | Type | State | Output

0 | front_susp | AS5600 String Pot I2C | active | LINEAR | Edit
1 | rear_susp | AS5600 String Pot I2C | active | LINEAR | Edit
2 | front_pot | Analog Potentiometer | muted | RAW | Edit
3 | gps | DAN-F10N GPS UART | active | RAW | Edit

New sensor

Type

Name Leave blank to auto-name.

Add Sensor Adding...

## Sensor Editor: front_susp

← Back to sensors

front_susp - AS5600 String Pot I2C

#### Basic

Name

Type Apply Type Rebuilds fields for this sensor type; restart after add/delete/type changes.

I2C bus

I2C address

Muted by default

#### Output

Output mode Complex transforms are applied downstream during import/analysis.

Include raw column

Sensor full travel (mm)

Installed range

#### Usage

End

Primary domain

Primary quantity

#### Calibration

Calibration methods Read-only sensor capability. Calibration values below remain editable.

Sensor count at zero travel

Sensor count at full travel

Installed zero count

Zero count

#### Wrapping

Counts per turn

Wrap threshold (counts)

Assume turn 0 at log start

Remove Delete this sensor Removes the sensor from logger config only.

Save Sensor Saving...

## Simulated htmx Fragment Responses

### Save success

<div class="alert-ok">Saved.</div>

Rendered:

Saved.

### Add sensor success (with redirect hint)

<div class="alert-ok">Sensor added. Restart the logger to rebuild the live sensor set.</div>

Rendered:

Sensor added. Restart the logger to rebuild the live sensor set.

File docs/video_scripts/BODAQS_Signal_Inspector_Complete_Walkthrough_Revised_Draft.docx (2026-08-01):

BODAQS Signal Inspector

Draft walkthrough script | Approx. 6 minutes 10 seconds

Recording setup

Start with one session that has useful signals and GPS. Have a local video clip ready to attach, and identify one or two distinctive moments for the synchronisation demonstration.

What appears on screen | What I say in voiceover
0:00-0:10 BODAQS logo and a clean Workbench data view. | BODAQS is an open source mountain bike data acquisition project focused on making professional analysis tools affordable and accessible
0:10-0:23 Brief return to the Simple Suspension Analysis tab, showing the distribution charts from the previous video. | In the last video we looked at some suspension analysis data from the demo library, in summary form: frequency distributions of wheel displacement and speed, that sort of thing
0:23-0:26 Short BODAQS title bumper. No voiceover.
0:26-0:42 Library Browser with a session selected. The cursor moves toward the signal preview and Signal Inspector action. | In this video we introduce the Signal Inspector: the place to examine time series data at its most basic and locate points or sections of interest using GPS and video, and bookmark them for later analysis.
0:42-0:57 Click the Signal Inspector icon, then briefly use the wheel-displacement preview route to show the alternative entry point. | The signal inspector opens from this little icon in the library. You’ll notice the library gives you a preview of the wheel displacement signals – you can open the signal inspector from that too. You can also launch the signal inspector from inside the simple suspension analysis view as we’ll see a little later.
0:57-1:13 Signal Inspector opens. Hold on the three panels: main signal panel, Bookmarks/GPS/Video, and Signals/Events. Collapse and reopen one side panel. | The signal inspector consists of three panels: the main signal panel, bookmarks, GPS and video panel, and the signals and events panel in the middle here. The second two, you can put away to give you more screen real estate to look at the signals.
1:13-1:37 The full-session chart. Hover to show value readouts, then click a recognisable feature to set Pinned Time. | Initially, the signal panel shows the full session. As you mouse over, the values of each signal are shown on the screen. You can click on the chart at any point – that time is called Pinned Time. We’ll use that later.
1:37-2:04 Drag across the chart to zoom. Zoom once more, use Full session, then drag and resize the navigator window at the bottom. | If we click, drag and release in the chart, we zoom into a smaller window. We can zoom repeatedly. We can also restore the full session view, or resize or drag the window in the navigator at the bottom of the panel here – which always shows the full time range of the session.
2:04-2:19 Open Signals and events and toggle between the combined-chart and separate-chart display modes. | The signals and events panel controls what’s shown on the chart. You have two basic options: everything on one chart, or each thing on its own chart.
2:19-2:49 Use the Signals checklist: retain wheel displacement and GPS speed, then briefly select wheel velocity and normalised displacement. | The signals list contains all the time series signals produced by all the sensors, and all the additional series derived from them. By default we start with wheel displacements and GPS speed selected, but you can pick anything you want. Some other useful options: wheel velocities; or normalised displacements (if you want to see what percentage of total travel you’re using).
2:49-3:25 Enable compression and rebound events. Select one event and show its detail/readout in the chart. | Events are one of the powerful features of the bodaqs analysis pipeline. Here only a few simple events are configured, but these – compression and rebound events specifically – are the raw material from which many of the suspension statistics we saw in the last video are derived. If we want to, we can see the details of a specific event. Events are a much bigger discussion that I will leave for another video.
3:25-3:49 In Bookmarks, GPS and Video, set Pinned Time, enter a bookmark name and save a point bookmark. Then zoom a window and save it. | The bookmarks, GPS and video panel contains the controls for finding and saving parts of the session that interest us. We can record either a point or a window as a bookmark: put Pinned Time where we want the bookmark, name it and save it; or find the window we want.
3:49-3:58 Show the saved bookmark list, then select a bookmark to restore its stored point or window. | These bookmarks stay with the session. They are also available in other views to filter the analysis.
3:58-4:12 Show the GPS map responding to the cursor and highlight the current time window on the route. | Where GPS is available, the map follows the time cursor and the window is highlighted.
4:12-4:22 Scroll to the Video card and open the new-attachment controls. | We ca also attach a video to this session. Video is optional, but it is particularly useful when you want to see what produced a feature in the data.
4:22-4:38 Enter an attachment name and use Browse to choose a local video file. Show the attachment selector after saving. | Create the attachment, give it a useful name, and browse to the video file. You can keep more than one attachment when you have different camera angles.
4:38-5:12 Scrub to a distinctive moment in the video and pin the matching chart time. Use Sync to pinned time, then briefly show the seconds and tenths nudge controls. | The app will attempt to sync the video to your logger data using the session timestamps, but you may need to do some synchronisation. To synchronise the video, simply find a distinctive moment in the footage and the same moment in the data. Pin the chart time and use Sync to pinned time. The app saves the result.You an also nudge the time alignment in seconds or tenths of seconds.
5:12-5:27 Play the video. The video-head marker advances through the charts; enable Scroll with playback. | Video playback now drives the marker through the signals. Turn on scroll with playback when you want the chart window to follow along automatically.
5:27-5:37 Adjust the panel layout to expand the video area while the chart remains visible. | You can also re-allocate the screen real estate to give the video a bit more room.
5:37-5:58 Show the synchronised chart, map and video together, then return to a concise Signal Inspector overview. | That is Signal Inspector: the place to examine time series data and narrow down on the areas that interest you the most. In future videos, we will continue to explore the features of the BODAQS software. Next, we will be looking at study sets: a way to keep data grouped together.
5:58-6:10 BODAQS end card with website, Instagram and Discord details. | For more information, visit bodaqs.net, follow us on Instagram or join our Discord server. Thank you for watching and see you in the next video.

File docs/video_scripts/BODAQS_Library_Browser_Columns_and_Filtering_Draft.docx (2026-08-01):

BODAQS Library Browser: Columns and Filtering

Draft walkthrough script | Approx. 5 minutes 15 seconds

Recording setup

Use a library with enough sessions to make narrowing the list worthwhile. Begin with default columns and no active filters; have one saved filter available for the final section.

What appears on screen | What I say in voiceover
0:00-0:10 BODAQS logo over the Library Browser session table. | BODAQS is an open source mountain bike data acquisition project focused on making professional analysis tools affordable and accessible.
0:10-0:25 Brief return to a saved Study Set and its selected member rows. | In the last video, we built a Study Set for a comparison. In this video, we will look at the Library Browser in more detail: how to configure it and quickly find the sessions you need.
0:25-0:44 Open the Library Browser and hold on the Library Selector, session table, preview panels and Study Set Builder. | The main areas are the Library Selector, the session table, the preview panels below it, and the Study Set Builder. Most of the time, the table is where you will start.
0:44-1:04 Open Library Selector. Select one library, then briefly add a second library if relevant. | First, choose where to look. Keep one library selected for a focused search, or include more than one when the comparison spans libraries.
1:04-1:23 Return to the table and pause on the default column arrangement. | The table begins with a sensible default view. It gives you enough context to identify likely sessions without opening every recording.
1:23-1:48 Click Columns. Select a practical preset, then turn on one additional useful field. | Use Columns to shape the table around the decision you are making. Start with a preset, then add only the fields you will actually use to choose sessions.
1:48-2:08 Move one visible column left or right in the Columns menu, then return to the table. | You can also set the order. Put the fields you scan most often near the left, so the useful information stays visible while you work through the list.
2:08-2:25 Drag one column boundary wider, using a name or notes field as the example. | Column widths are adjustable as well. Give names or notes a little more room when they carry the context you need.
2:25-2:45 Click a column heading to sort, then click it again to reverse the order. | Sorting is the quickest first pass. Sort by date to find a recent session, or by another visible field when that is the more useful way to organise the list.
2:45-3:12 Open one column filter, search its values and select a meaningful condition. | For a more precise shortlist, open a column filter. Search the values, choose the condition you want, and the table updates to show just those sessions.
3:12-3:35 Open a second column filter and select a complementary condition. Leave the shorter list visible. | Filters can work together. Here we are combining two simple conditions so the table becomes a list we can actually inspect or add to a Study Set.
3:35-3:55 Use the main search field to find a word or identifier, then clear it. | The search field is useful when you already know part of a name, note or identifier. It works well alongside the filters rather than replacing them.
3:55-4:20 Show the saved-filter controls. Apply one useful saved filter, then clear it. | For a filtering pattern you use repeatedly, save it and bring it back from the filter controls. That is handy for common questions without turning the browser into a long setup exercise.
4:20-4:43 Clear temporary filters. Leave the preferred column configuration and a tidy shortlist on screen. | Once the list is right, select the sessions and move on: inspect one directly, or add several to a Study Set for comparison. The Library Browser is there to get you to the data quickly.
4:43-5:03 Show a selected session entering Signal Inspector, then a small multi-session selection going to Study Set Builder. | That is the basic library workflow: choose the source, shape the table, narrow the sessions, then open the analysis that answers the question. In future videos, we will keep building on those comparisons.
5:03-5:15 BODAQS end card with website, Instagram and Discord details. | For more information, visit bodaqs.net, follow us on Instagram or join our Discord server. Thank you for watching and see you in the next video.

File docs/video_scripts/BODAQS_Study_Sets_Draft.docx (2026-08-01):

BODAQS Study Sets

Draft walkthrough script | Approx. 4 minutes 30 seconds

Recording setup

Start in the Library Browser with several comparable sessions visible. Use a small, meaningful selection and, if possible, a saved track that is relevant to those sessions.

What appears on screen | What I say in voiceover
0:00-0:10 BODAQS logo over several sessions selected in the Library Browser. | BODAQS is an open source mountain bike data acquisition project focused on making professional analysis tools affordable and accessible.
0:10-0:24 Quick cuts of single-session analysis and track timing views. | We started by looking at analysis of a single session. In this video, we will look at Study Sets: a way to save a useful selection of sessions, group them in different ways, add tracks, and save it so you can return to it later.
0:24-0:41 Library Browser with the Study Set Builder visible. Hold long enough to see the table, current Study Set and saved Study Sets. | Hiding away on the right hand side of the library browser is the study set builder panel. This is where we keep the sessions, groups and tracks that belong in the comparison.
0:41-1:03 Select two or three comparable sessions in the table. Keep the selection visible. | We’ll start with a small selection of sessions: a few repeats of one route, plus a couple of others. Add the selected sessions to the current Study Set.
1:03-1:18 Click Add to Study Set. The selected sessions appear in Current Study Set. | We’re also going to add a track from our list of tracks. We’ll cover where these come from in a later video, but for now just observe that we can put them in our study set. We can also search for sessions with GPS data that matches the track, which can be very useful.
1:18-1:40 Enter a clear Study Set name and a short description, if useful. | The third thing you can put in a study set is a group. Groups are useful if you want to pool data for something. For example, if you want to group all your morning runs on one setup and compare them to all your afternoon runs on a different setup, you can do that.
2:50-3:10 Click Save. Show the saved Study Set in the list and the confirmation message. | You don’t have to save your stud set – you can proceed directly to analysis. But if you do, you’ll be able to return to it. The payoff is that the same prepared set can launch multiple different analysis views – visible at the same time if you like.
3:32-3:55 Click Analyze and show the Analysis launcher with the prepared Study Set in scope.
3:55-4:15 End on the saved Study Set name and its compact member list. | So that’s a study set: a re-usable grouping of data for analysis. You don’t have to use them, but you’ll probably find them useful. In the next video, we will look at tracks and lap timing – a perfect use case for study sets.
4:15-4:27 BODAQS end card with website, Instagram and Discord details. | For more information, visit bodaqs.net, follow us on Instagram or join our Discord server. Thank you for watching and see you in the next video.

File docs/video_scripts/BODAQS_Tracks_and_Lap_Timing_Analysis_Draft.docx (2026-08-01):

BODAQS Tracks and Lap Timing Analysis

Draft walkthrough script | Approx. 5 minutes

Recording setup

Open a saved Study Set containing several sessions with GPS coverage. Have a saved track with a start/finish point and sector points ready, and use sessions that have crossed the track.

What appears on screen | What I say in voiceover
0:00-0:10 BODAQS logo over a route map and a lap-time table. | BODAQS is an open source mountain bike data acquisition project focused on making professional analysis tools affordable and accessible.
0:10-0:25 Brief return to a Signal Inspector view with GPS and the session time cursor visible. | In the last video, we looked at the idea of a study set: a collection of related data. In this video, we see a perfect application: we will use several sessions with GPS data to look at tracks, segments and virtual lap timing.
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

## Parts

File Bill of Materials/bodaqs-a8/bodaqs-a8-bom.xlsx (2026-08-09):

Qty | Item | Link |  | Note
1 | BODAQS A8 printed circuit board | JLCPCB (https://jlcpcb.com/) | https://jlcpcb.com/ | Direct from fabricator
 |  | BODAQS.net (https://bodaqs.net/logger-build-guide/bodaqs-a8/buy/) | https://bodaqs.net/logger-build-guide/bodaqs-a8/buy/ | Buy from bodaqs.net
1 | 0.96" OLED display HS96L03W2C03 | AliExpress (https://www.aliexpress.com/item/1005007228213109.html) | https://www.aliexpress.com/item/1005007228213109.html | Multiple vendors - search "HS96L03W2C03"
1 | Nintendo 2DS replacement button pad | AliExpress (https://www.aliexpress.com/item/1005009646292735.html) | https://www.aliexpress.com/item/1005009646292735.html | Multiple vendors - search "button pad 2DS"
1 | Li-Ion Polymer battery pack 3.7V. JST-PH 2 pin connector | Sparkfun (https://www.sparkfun.com/lithium-ion-battery-2ah.html) | https://www.sparkfun.com/lithium-ion-battery-2ah.html | Recommended if purchasing from the US
 |  | Kiwi Electronics (https://www.kiwi-electronics.com/en/lithium-polymer-li-po-battery-3-7v-1200mah-1045) | https://www.kiwi-electronics.com/en/lithium-polymer-li-po-battery-3-7v-1200mah-1045 | Recommended if purchasing from the EU
 |  | Altronics (https://www.altronics.com.au/p/s4725-3.7v-2000mah-polymer-lithium-ion-battery-lipo/) | https://www.altronics.com.au/p/s4725-3.7v-2000mah-polymer-lithium-ion-battery-lipo/ | Recommended if purchasing from Australia
 |  | AliExpress (https://www.aliexpress.com/item/1005004841334328.html) | https://www.aliexpress.com/item/1005004841334328.html | Check dimensions - model 524261 from this vendor
1 | Header socket, 8.5mm high, 2.54mm pitch, single row, 4+ sockets. | Sparkfun (https://www.sparkfun.com/arduino-header-kit.html) |  | Recommended if purchasing from the US
 |  | Kiwi Electronics (https://www.kiwi-electronics.com/en/teensy-header-kit-2706) |  | Recommended if purchasing from the EU
 |  | Altronics (https://www.altronics.com.au/p/p5390-oupiin-40-pin-header-socket/) |  | Recommended if purchasing from Australia
 |  | AliExpress (https://www.aliexpress.com/item/1005003610333849.html) |  | Multiple vendors - search "Socket header 8.5mm".
4 | Amphenol M8 circular connector M8AS-06PMMR-SF8001 | Digikey (https://www.digikey.com.au/en/products/detail/amphenol-ltw/M8AS-06PMMR-SF8001/7618863)
 |  | AliExpress (https://www.aliexpress.com/item/1005008002251461.html) | https://www.aliexpress.com/item/1005008002251461.html | Purchase plug assemblies from same vendor - read the guide
4 | M8 Plug assemblies Amphenol 8A-06AFFM-SL7A01 | Digikey (https://www.digikey.com.au/en/products/detail/amphenol-ltw/8A-06AFFM-SL7A01/7616809) | https://www.digikey.com.au/en/products/detail/amphenol-ltw/8A-06AFFM-SL7A01/7616809 | Digikey
5 max | M6 plastic circular connectors - 3 pin | AliExpress (https://www.aliexpress.com/item/1005005939808200.html) | https://www.aliexpress.com/item/1005005939808200.html | Multiple vendors - search "M6 connector". Read the guide to decide how many you need.
3 max | M6 plastic circular connectors - 4 pin | AliExpress (https://www.aliexpress.com/item/1005005939808200.html) | https://www.aliexpress.com/item/1005005939808200.html | Multiple vendors - search "M6 connector". Read the guide to decide how many you need.
1 | 22mm x 33mm x 1mm acrylic panel | AliExpress (https://www.aliexpress.com/item/1005012216508583.html) | https://www.aliexpress.com/item/1005012216508583.html | You can make this from a clear lens from a set of goggles.
1 | CR1220 button cell battery |  |  | For real-time clock. Available almost anywhere.
1 | MicroSD card, 16GB or larger |  |  | Available almost anywhere
 | 2.5mm shrink sleeve |  |  | Available from most hardware shops and electronics suppliers.
 | 10mm shrink sleeve(if making y connections) |  |  | Available from most hardware shops and electronics suppliers.
 | Neutral-cure caulking silicone |  |  | Available from most hardware shops.
Fasteners (option 1)
14 | M3 x 5 x 4.2 heat set brass inserts | AliExpress (https://www.aliexpress.com/item/1005008666672949.html) | https://www.aliexpress.com/item/1005008666672949.html | Multiple vendors - search "M3 brass insert"
4 | M3 x 12 stainless steel socket head capscrews | AliExpress (https://www.aliexpress.com/item/1005003318923561.html) | https://www.aliexpress.com/item/1005003318923561.html | Multiple vendors - search "M3 stainless steel hex"
4 | M3 x 8 stainless steel socket head capscrews | AliExpress (https://www.aliexpress.com/item/1005003318923561.html) | https://www.aliexpress.com/item/1005003318923561.html | Multiple vendors - search "M3 stainless steel hex"
6 | M3 x 6 stainless steel socket head capscrews | AliExpress (https://www.aliexpress.com/item/1005003318923561.html) | https://www.aliexpress.com/item/1005003318923561.html | Multiple vendors - search "M3 stainless steel hex"
4 | M2 x 5 stainless steel button head capscrew | AliExpress (https://www.aliexpress.com/item/32966917947.html) | https://www.aliexpress.com/item/32966917947.html | Multiple vendors - search "M2 stainless steel buttonhead"
Fasteners (option 2)
8 | BT2.5 x 8 self-tapping screws for plastic | Bambulab (https://au.store.bambulab.com/products/bt2-5-socket-head-cap-self-tapping-screws-shcs-new) | https://au.store.bambulab.com/products/bt2-5-socket-head-cap-self-tapping-screws-shcs-new | Also available on AliExpress
10 | BT2.5 x 5 self-tapping screws for plastic | Bambulab (https://au.store.bambulab.com/products/bt2-5-socket-head-cap-self-tapping-screws-shcs-new) | https://au.store.bambulab.com/products/bt2-5-socket-head-cap-self-tapping-screws-shcs-new | Also available on AliExpress
3D printed parts
Qty | Part
1 | Logger case - base
1 | Logger case - lid
1 | Logger case - top end
1 | Logger case - bottom end
1 | Logger case - Nav plate
1 | Logger case - Power button plate
1 | Logger case - OLED spacer
6 | Logger case - pin
1 | Plug
4 | Caps
1 | Downtube mount

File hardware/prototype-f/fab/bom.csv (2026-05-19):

Designator | Footprint | Quantity | Value | LCSC Part #
C1, C2, C3, C4 | 0603 | 4 | 10nF | C57112
C6, C7 | 0603 | 2 | 2.2uF | C342978
C8 | 0603 | 1 | 100nF | C91183
D1, D2 | D_SOD-323 | 2 | BAT60A | C442418
R1, R10, R12, R3, R4, R6, R7, R9 | 0603 | 8 | 10K | C25804
R11, R2, R5, R8 | 0603 | 4 | 68R | C27592
U2 | SOIC-14_3.9x8.7mm_P1.27mm | 1 | MCP6004 | C7378
U3 | SOT-23-5 | 1 | TPS7A2033PDBVR | C2862740

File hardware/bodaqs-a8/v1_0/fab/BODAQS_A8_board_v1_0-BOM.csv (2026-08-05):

Designator | Footprint | Quantity | Value | LCSC Part #
BT1 | BAT-TH_MY-1220-01 | 1 | MY-1220-01 | C964817
C1, C10, C14, C15, C16, C18, C20, C29, C30, C31, C32, C7 | 0402 | 12 | 100nF | C1525
C11, C33, C34, C6, C3 | 0402 | 4 | 1uF | C52923
C12, C13 | 0603 | 2 | 2.2uF | C23630
C17, C19, C9 | 0805 | 3 | 10uF | C15850
C2, C8 | 0603 | 2 | 22uF | C84419
C21, C22, C23, C24, C25, C26, C27, C28 | 0402 | 8 | 10nF | C15195
C4 | 0402 | 1 | 4.7uF | C23733
C5 | 0805 | 1 | 47uF | C16780
CN1 | CONN-TH_B2B-PH-K-S | 1 | Battery | C131337
D1, D2 | 0603 | 2 | Red | C2286
IC1 | XC6193AA05ERG | 1 | XC6193A103ER-G | C19267155
L1 | L0603 | 1 | MPZ1608S601ATA00 | C107335
Q1 | SOT-23 | 1 | DMG2301L | C102619
R1, R11, R13, R15, R22, R25, R26, R27, R28, R29, R30, R31, R4 | 0402 | 13 | 10k | C25744
R10, R9 | 0402 | 2 | 22 | C25092
R12 | 0402 | 1 | 511k | C64042
R14 | 0402 | 1 | 91k | C4147
R16 | 0402 | 1 | 18k | C25762
R17 | 0402 | 1 | 1k | C11702
R18, R19, R3, R5, R7, R8 | 0402 | 6 | 4.7k | C25900
R2, R6 | 0402 | 2 | 47k | C25792
R20, R21, R23 | 0402 | 3 | 200k | C25764
R24 | 0402 | 1 | 133k | C25753
R32, R33, R34, R35, R36, R37, R38, R39 | 0402 | 8 | 100R | C25076
R40, R41, R42, R43, R44, R45, R46, R47, R48, R49 | 0402 | 10 | 47R | C25120
R50, R51 | 0402 | 2 | 5.1k | C25905
SIM1 | SIM-SMD_8P-1040310811 | 1 | 1040310811 | C585350
SW1, SW2, SW3, SW4, SW5, SW6, SW7, SW8 | SW-SMD_L3.9-W3.0-P4.45 | 8 | TS-1088-AR02016 | C720477
U1 | ESP32-S2-MINI-1 | 1 | ESP32-S3-MINI | C3013941
U10, U11 | VQFN-16_L3.5-W3.5-P0.50-BL-EP2.1 | 2 | ADS1220IRVAR | C2651338
U12 | SOT-23-6_L2.9-W1.6-P0.95-LS2.8-BR | 1 | DT1042-04SO | C19626385
U2 | L1008 | 1 | DFE252012P-1R0M=P2 | C882955
U3 | TDFN-8_L2.0-W2.0-P0.50-BL-EP1.2 | 1 | MAX17048G+T10 | C2682616
U4 | SOT-583-8_L2.1-W1.2-P0.50-LS1.6-BL | 1 | TPS631000DRLR | C5219190
U5 | WSON-10_L2.2-W2.0-P0.40-BL-EP_TI_DLH0010A | 1 | BQ25185DLHR | C19725033
U6 | TSOT-23-5_L2.9-W1.6-P0.95-LS2.8-BR | 1 | TPS7A2030PDBVR | C963429
U7 | SOT-23-6_L2.9-W1.6-P0.95-LS2.8-BR | 1 | TPS2553DBVR | C55266
U8 | MicroCrystal_C7_SON-8_1.5x3.2mm_P0.9mm | 1 | RV-3028-C7 | C3019759
USB1 | USC-C-SMD_USB4085-GF-A | 1 | USB4085-GF-A_C7095263 | C7095263

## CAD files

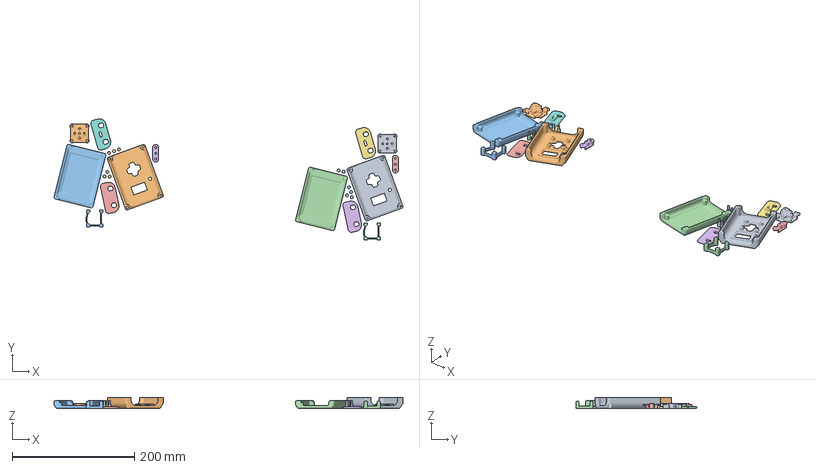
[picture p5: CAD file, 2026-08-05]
mechanical/Case/a8_v1_0/3mf/a8_all_parts_one_material.3mf
572.1 x 198.9 x 18.0 mm
Lid bt2_5.step
Lid.step
Base.step
Base bt2_5.step
Top end.stl x 2
Bottom end.stl x 2
Nav plate bt2_5.stl
Nav plate.stl
OLED spacer.stl x 2
Power button plate bt2_5.stl
Power button plate.stl
Pin.stl x 12

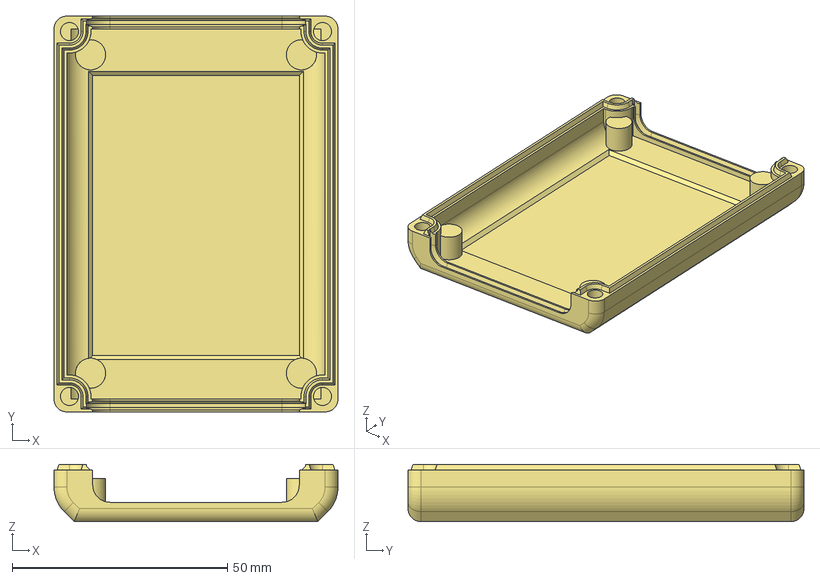
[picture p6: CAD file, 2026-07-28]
mechanical/Case/a8_v1_0/step/Base.step
66.0 x 92.0 x 13.3 mm

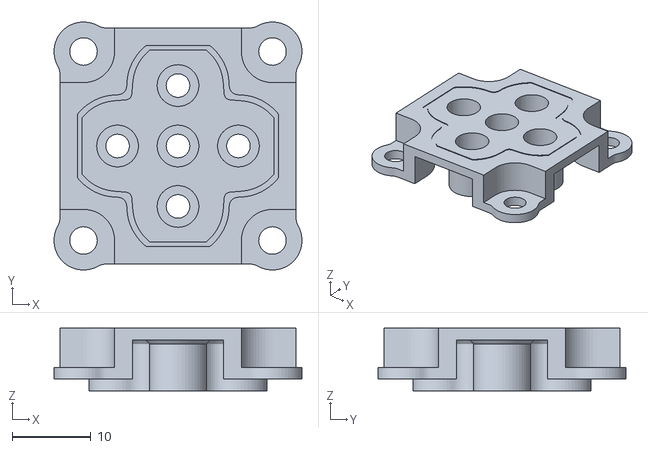
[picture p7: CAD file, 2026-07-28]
mechanical/Case/a8_v1_0/stl/Nav plate.stl
31.5 x 31.5 x 8.00

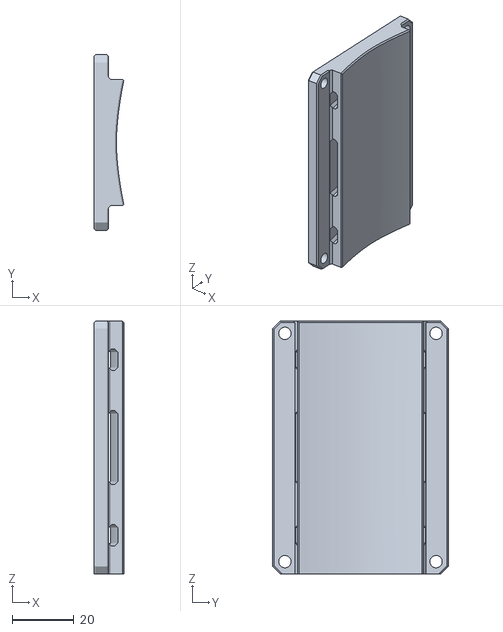
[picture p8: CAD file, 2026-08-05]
mechanical/Case/Common/Downtube mount generic.stl
9.59 x 57.0 x 82.0

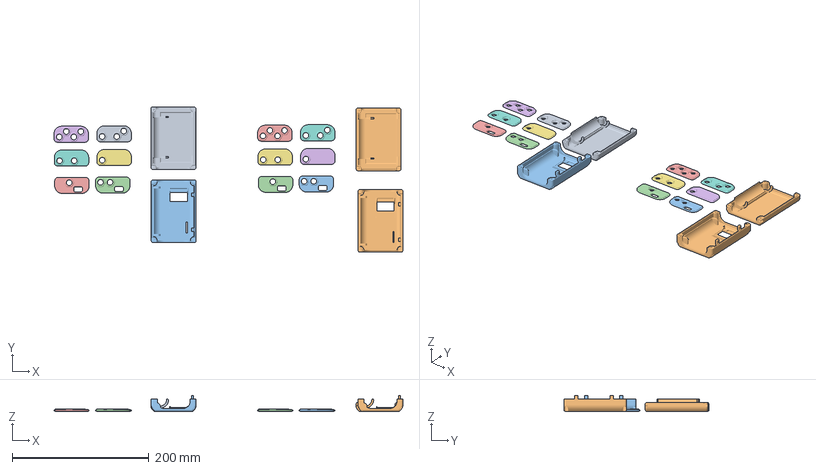
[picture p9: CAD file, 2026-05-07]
mechanical/Case/Prototype E-F/3mf/All parts - three color - F.3mf
511.3 x 213.1 x 23.5 mm
Base.step
Base_nuts.step
Lid.step x 2
Bottom end.stl x 2
Bottom end_1_connector.stl x 2
Top end.stl x 2
Top end_1_connector.stl x 2
Top end_2_connectors.stl x 2
Top end_3_connectors.stl x 2

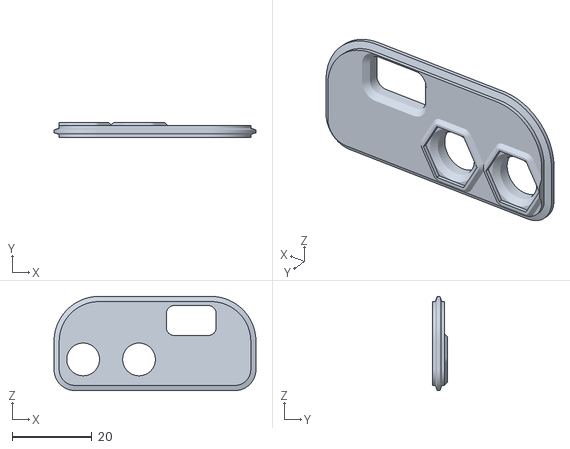
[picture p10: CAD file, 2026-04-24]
mechanical/Case/Prototype E-F/Bottom end.stl
50.6 x 3.70 x 23.6

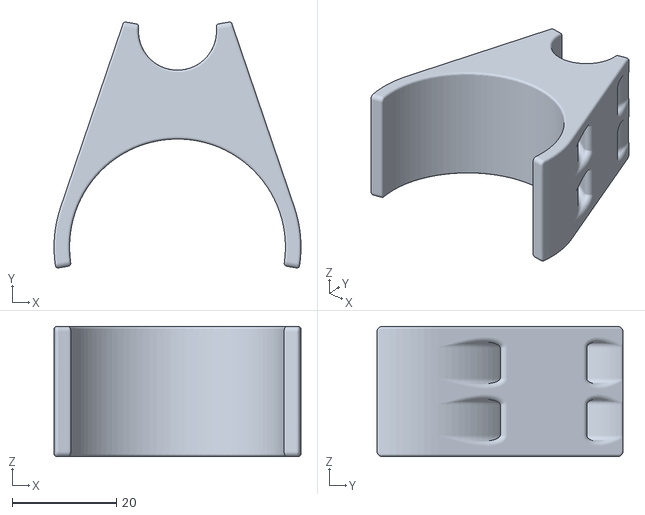
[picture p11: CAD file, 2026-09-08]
mechanical/linear-potentiometer-mounts/Fork/Fox 34/fork-lower-housing-type-forkdia41_5-potdia15-sid-fox34-miran.stl
47.5 x 47.3 x 25.0

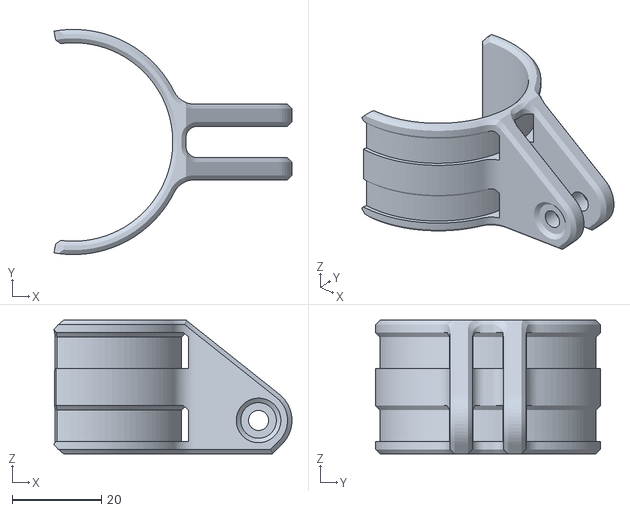
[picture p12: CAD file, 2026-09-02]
mechanical/linear-potentiometer-mounts/Fork/Fox 36/fork-lower-ziptie-type-od44_5-af7mm-fox36-lyrik-miran.stl
53.4 x 50.5 x 30.0

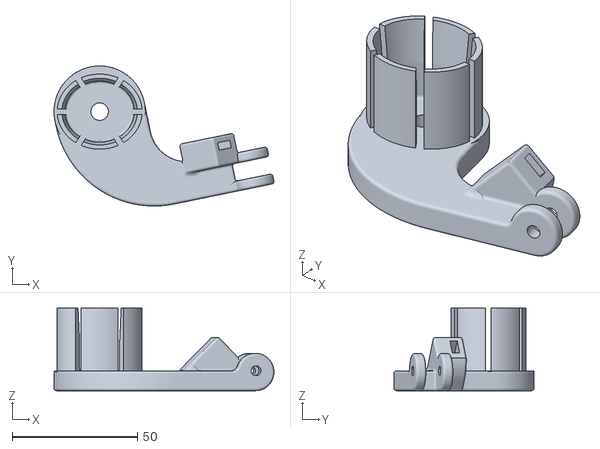
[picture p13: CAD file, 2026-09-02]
mechanical/linear-potentiometer-mounts/Fork/Fox 38/fork-upper-steerer30-type-oval-af7mm-fox38-miran.stl
87.9 x 56.0 x 33.0

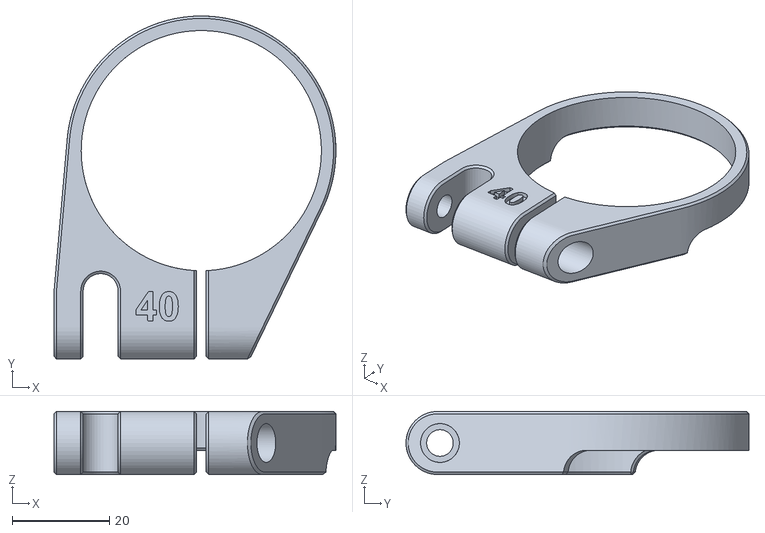
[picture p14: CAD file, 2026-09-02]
mechanical/linear-potentiometer-mounts/Fork/Fox 40/fork-lower-band-type-od49_5-af7mm-fox40-miran.stl
58.1 x 70.7 x 13.0

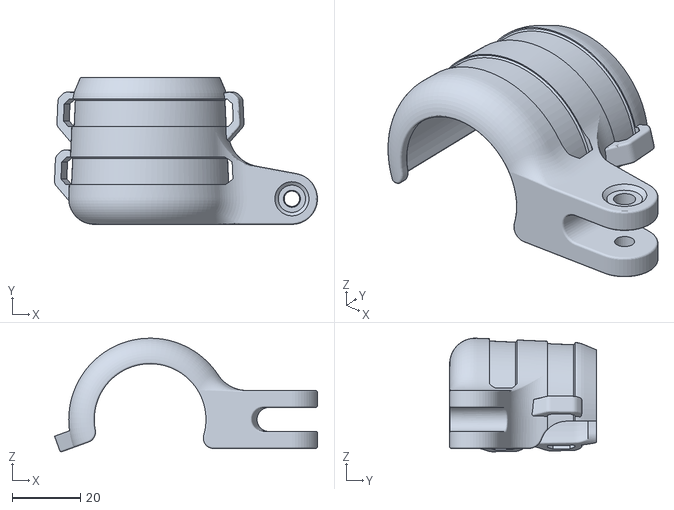
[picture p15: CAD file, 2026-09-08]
mechanical/linear-potentiometer-mounts/Fork/SID/fork-upper-crown0-type-af7mm-sid-miran.stl
77.1 x 43.0 x 33.3

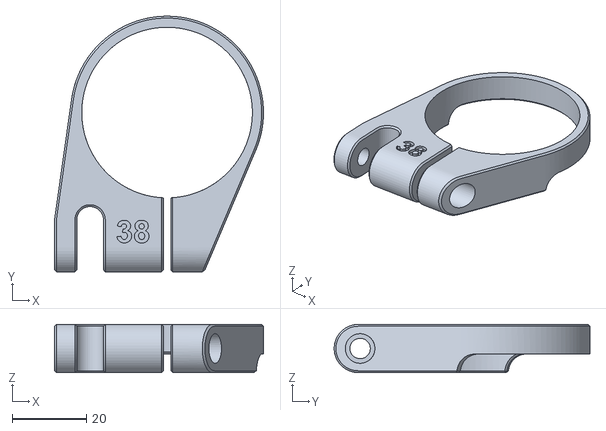
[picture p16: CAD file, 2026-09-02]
mechanical/linear-potentiometer-mounts/Fork/Zeb/fork-lower-band30-type-od46-af7mm-fox38-zeb-miran.stl
56.3 x 68.9 x 13.0

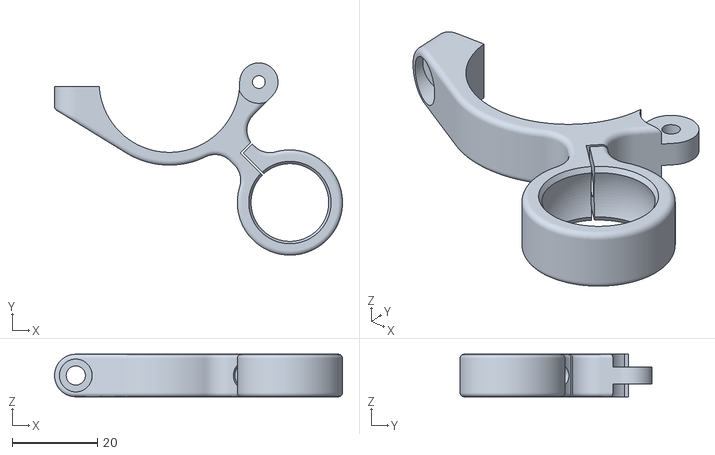
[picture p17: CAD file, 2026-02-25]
mechanical/linear-potentiometer-mounts/Shock/Coil shock body mount/Shock pot mount upper 33ID part 2.stl
67.6 x 45.1 x 10.0

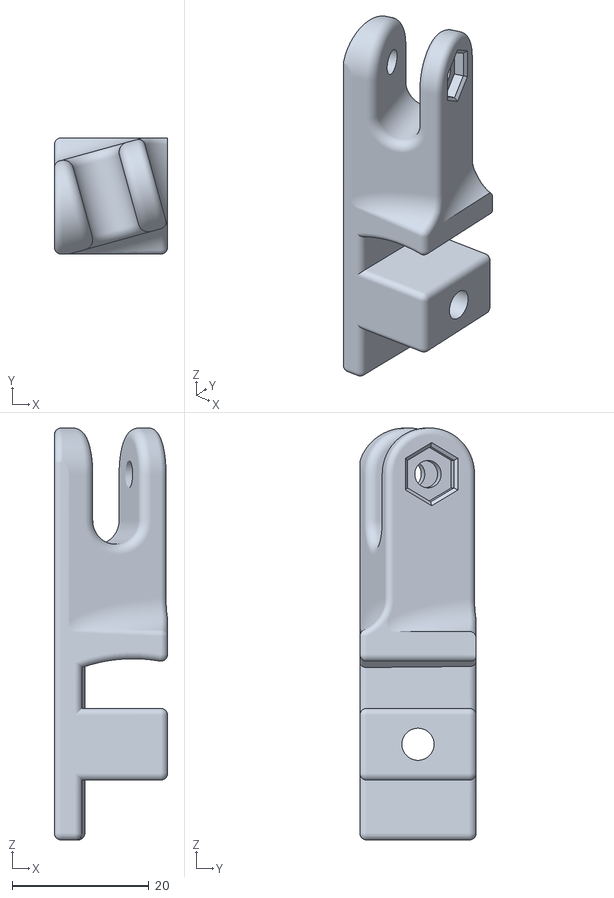
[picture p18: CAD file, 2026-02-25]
mechanical/linear-potentiometer-mounts/Shock/STEVO yoke mount/Rear pot back mount part 1.stl
16.6 x 17.0 x 60.2

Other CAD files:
mechanical/linear-potentiometer-mounts/Fork/Lyrik/fork-upper-steerer30-type-od31_7mm-af7mm-lyrik-miran.stl
mechanical/Case/a8_v1_0/3mf/a8_all_parts_3_colors.3mf
mechanical/Case/a8_v1_0/step/Base bt2_5.step
mechanical/Case/a8_v1_0/stl/Bottom end.stl
mechanical/Case/Common/Amphenol M8 cap.stl
mechanical/Case/Common/Plug.stl
mechanical/Case/Prototype E-F/3mf/All parts - one color - F.3mf
mechanical/Case/Prototype E-F/Base.stl
mechanical/Case/Prototype E-F/Base_nuts.stl
mechanical/Case/Prototype E-F/Bottom end_1_connector.stl
mechanical/Case/Prototype E-F/Bottom end_1_connector_plastic.stl
mechanical/Case/Prototype E-F/Lid.stl
mechanical/Case/Prototype E-F/STEP/Base.step
mechanical/Case/Prototype E-F/STEP/Base_nuts.step
mechanical/Case/Prototype E-F/STEP/Lid.step
mechanical/Case/Prototype E-F/Top end.stl
mechanical/Case/Prototype E-F/Top end_1_connector.stl
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

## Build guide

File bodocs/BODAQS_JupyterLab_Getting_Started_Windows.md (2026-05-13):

# BODAQS: Get Started with JupyterLab (Windows, no Conda)

This guide gets you from **"repo cloned"** to **"JupyterLab running your notebooks"** on **Windows**, assuming you **don't have Python installed yet** and you want a **single environment** using Python's built-in **venv**.

---

## 0) Prerequisites

You already have:
- A local clone of the **BODAQS** repo.

You will install:
- **Python** (includes `pip`)
- A **virtual environment** for this repo
- **JupyterLab**
- The repo's Python dependencies

---

## 1) Install Python on Windows

1. Download Python from the official site:
   - https://www.python.org/downloads/windows/

2. Run the installer and **make sure** you tick:
   - **Add python.exe to PATH**
   - (Optional but recommended) **Install launcher for all users**

3. Finish the install.

### Verify Python is installed

Open **PowerShell** and run:

```powershell
python --version
pip --version
```

You should see version output (for example `Python 3.12.x`).

If `python` is not found:
- Re-run the installer and ensure **"Add to PATH"** is checked, or
- Close and reopen PowerShell after installation.

---

## 2) Create a virtual environment inside the repo

In PowerShell, `cd` into your repo (adjust the path):

```powershell
cd D:\Dev\BODAQS
```

Create a virtual environment (named `.venv`):

```powershell
python -m venv .venv
```

Activate it:

```powershell
.\.venv\Scripts\Activate.ps1
```

If PowerShell blocks activation with an execution policy warning, run:

```powershell
Set-ExecutionPolicy -Scope CurrentUser -ExecutionPolicy RemoteSigned
```

Then try activation again:

```powershell
.\.venv\Scripts\Activate.ps1
```

### Upgrade pip (recommended)

```powershell
python -m pip install --upgrade pip
```

---

## 3) Install BODAQS Python dependencies

BODAQS dependencies are defined in the repo-root `requirements.txt`.

From the repo root:

```powershell
python -m pip install -r requirements.txt
```

This is the canonical live environment specification, including JupyterLab.
Use it again after pulling dependency updates.

---

## 4) Launch JupyterLab

No separate `pip install jupyterlab` step is required after installing
`requirements.txt`.

From the **repo root** (recommended):

```powershell
python -m jupyter lab
```

A browser tab should open with the JupyterLab interface. If it does not,
PowerShell will print a local URL (usually starting with
`http://localhost:8888/lab`) that you can paste into your browser.

---

## 5) Open and run notebooks

In JupyterLab:
1. Use the left file browser to navigate to the notebook folder (commonly `notebooks/`, but it may differ).
2. Open a `.ipynb` file.
3. If prompted to select a kernel:
   - Choose the **Python** kernel associated with your `.venv`.

### Run a notebook

- Use **Run -> Run All Cells**, or press **Shift+Enter** to execute cell-by-cell.

---

## 6) Typical workflow (every time)

When you come back later:

1. Open PowerShell
2. Go to the repo
3. Activate the venv
4. Launch JupyterLab

```powershell
cd D:\Dev\BODAQS
.\.venv\Scripts\Activate.ps1
python -m jupyter lab
```

---

## Troubleshooting

### "ModuleNotFoundError: ..."

That package is not installed in your current environment. Confirm you activated the venv:

```powershell
where python
python -c "import sys; print(sys.executable)"
```

You should see a path inside `...\BODAQS\.venv\...`.

Then install dependencies again (Section 3).

---

### JupyterLab / notebook version conflict after a refresh

If `pip` reports that `notebook` requires a newer `jupyterlab`, refresh from
the repo-root `requirements.txt` again after pulling the latest branch changes:

```powershell
python -m pip install -r requirements.txt
python -m pip check
```

If warnings about invalid distributions such as `~upyterlab` persist, your venv
likely contains leftovers from an interrupted package upgrade. Recreating the
`.venv` is the cleanest fix.

---

### Jupyter launches but the kernel can't start / wrong kernel

Make sure `ipykernel` is installed in your venv:

```powershell
python -m pip install ipykernel
```

Then (optional) register a named kernel:

```powershell
python -m ipykernel install --user --name bodaqs --display-name "Python (BODAQS)"
```

Restart JupyterLab and select **Python (BODAQS)** as the kernel.

---

### Port already in use

Start JupyterLab on a different port:

```powershell
python -m jupyter lab --port 8889
```

---

### "jupyter is not recognized..."

You likely did not install JupyterLab in the active environment, or the venv is not activated.

Try:

```powershell
python -m pip install -r requirements.txt
python -m jupyter lab
```

---

## What I need from you (only if you want this guide to be repo-specific)

If you want this guide to mention *exact* file/folder names (for example the correct notebooks folder, the correct dependency install command, or a "first notebook to run"), tell me:
- What dependency file(s) your repo uses: `requirements.txt` / `pyproject.toml` / something else
- The folder where the notebooks live (for example `analysis/notebooks/`)
- The recommended "first notebook" (filename)

Then I can produce a tailored version with no conditionals.

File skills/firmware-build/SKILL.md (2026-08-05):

---
name: firmware-build
description: "Build, merge, and flash BODAQS ESP32-S3 firmware using the firmware/build.sh script. Use when the user wants to compile firmware, create a flashable .bin file, flash firmware to a device, change the default build environment or serial port, list available firmware environments, clean build artifacts, or configure build settings. Triggers on: build firmware, flash firmware, make a .bin, upload firmware, esptool, platformio, build.sh, change build config, which environment, serial port."
---

# Firmware Build

Build, merge, and flash BODAQS ESP32-S3 firmware via `firmware/build.sh`.

## Prerequisites

The script requires two tools. If either is missing, the script prints install instructions and exits:

- **PlatformIO CLI** (`pio`) — install with `pipx install platformio`
- **esptool** — install with `pipx install esptool` or `brew install esptool`

## Quick Reference

All commands run from `firmware/`:

| Command | Purpose |
|---|---|
| `./build.sh` | Build + merge (default env) |
| `./build.sh build [env]` | Build + merge for a specific env |
| `./build.sh merge [env]` | Merge only (skip build, reuse existing artifacts) |
| `./build.sh flash [env]` | Build + merge + flash to device |
| `./build.sh clean [env]` | Clean build directory |
| `./build.sh check` | Verify tools, project, port, and device |
| `./build.sh detect` | Scan /dev for connected ESP32-S3 devices |
| `./build.sh list` | List all environments from platformio.ini |

Options: `--port PORT` (or `auto`), `--no-build`, `--env ENV`, `-h`/`--help`.

## Configuration

All defaults are inline at the top of `firmware/build.sh` under the "Configuration" section. An optional `firmware/build.conf` file can override any value if it exists.

When the user asks to change build configuration (default environment, serial port, baud rate, flash offsets, output filename), read [references/configuration.md](references/configuration.md) for the full list of settings, what each controls, and what to prompt the user about.

## Workflow

1. **Run a system check.** Execute `./build.sh check` to verify tools, project files, environment, serial port, connected device, and build state. This catches problems before a build or flash attempt.
2. **Determine the target environment.** If the user doesn't specify, use the default (`DEFAULT_ENV` in build.sh). Run `./build.sh list` to see all options. Ask the user which board they're targeting if unclear.
3. **Build + merge.** Run `./build.sh build [env]`. Produces `bodaqs-firmware.bin` in `firmware/`.
4. **Flash.** Run `./build.sh flash [env]` (builds + merges + flashes in one step), or `./build.sh flash --no-build` to reflash an existing binary.
5. **If flashing fails**, run `./build.sh check` to diagnose, then verify the serial port with `--port` and that the device is connected and in bootloader mode.

## Environments

Environments are defined in `firmware/platformio.ini`. Each maps to a board + set of build flags. Key environments:

- `thingplus_s3_usb_cdcserial_bodaqs_4f` — SparkFun Thing Plus, BODAQS 4F board profile (default)
- `bodaqs_s3_mini_n4r2` — BODAQS V1RC3 custom board (A8)
- `*_as5048_probe` / `*_gps_uart_probe` — diagnostic variants for sensor bringup
- `*_bringup` — minimal diagnostics build

Run `./build.sh list` for the current full list.

## Multi-Board Workflows

When building for multiple boards (e.g., Prototype F and A8/RC3), both environments produce the same output file (`bodaqs-firmware.bin`). Each build overwrites the previous binary — the filename gives no indication of which board it targets.

To avoid confusion:

- **Set per-env `OUTPUT_BIN`** in `build.conf` to keep separate binaries (e.g., `bodaqs-4f.bin` vs `bodaqs-v1rc3.bin`).
- **Flash baud differs by board** — V1RC3 flashes at 460800, Thing Plus at 921600. The script auto-selects based on environment. Override with `FLASH_BAUD` in build.conf if needed.
- **Always specify the env** when flashing: `./build.sh flash bodaqs_s3_mini_n4r2` rather than relying on the default.

## System Check

`./build.sh check` runs a full diagnostic of the build environment. It does not require tools to be installed — it reports what's missing rather than exiting. Use it:

- **Before building** — catches missing tools, bad env names, missing project files
- **Before flashing** — verifies serial port exists and device is connected
- **When troubleshooting** — isolates whether a failure is tools, config, port, or device

The check reports six categories with ✓/✗/! markers:

| Category | What it verifies |
|---|---|
| Tools | PlatformIO CLI and esptool installed with versions |
| Project | platformio.ini, src/, boards/, variants/ directories present |
| Environment | DEFAULT_ENV exists in platformio.ini; build.conf status |
| Serial Port | Configured port exists in /dev |
| Device | ESP32 chip type and MAC (probes via esptool chip-id) |
| Build State | Previous build artifacts and merged binary present |

Exits with code 1 if any check fails, 0 if all pass. Warnings (build.conf missing, no previous build) do not cause a failure.

## Port Detection

Auto-detection is enabled by default (`DEFAULT_PORT="auto"` in build.sh). The script scans `/dev/cu.*` and probes each port with esptool to find a connected ESP32-S3.

**Standalone:** `./build.sh detect` — scans and reports all ESP32-S3 devices found.

**With flash:** Auto-detection runs automatically before flashing. To override with a specific port:
```
./build.sh flash --port /dev/cu.usbmodem1101
```

**How it works:**
1. Lists all `/dev/cu.*` ports (filters out Bluetooth and debug ports)
2. Probes each with `esptool --chip esp32s3 --port <port> chip-id`
3. If exactly one ESP32-S3 responds, uses it automatically
4. If multiple respond, lists them all and uses the first (user can override with `--port`)
5. If none respond, reports failure with a hint to check the connection

To disable auto-detection, set `DEFAULT_PORT` to a specific port (e.g. `/dev/cu.usbmodem1101`) in build.sh or build.conf.

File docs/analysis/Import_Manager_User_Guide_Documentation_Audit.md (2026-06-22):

# Import Manager Documentation Audit

Status: draft  
Date: 2026-06-21  
Scope: `bodocs/src/content/docs/software-guide/setup-import-manager.mdx`, `bodocs/src/content/docs/user-guide/import-manager-user-guide.mdx`, and `bodocs/src/content/docs/user-guide/import-manager-folder-structure-appendix.md`  
Import Manager context: current `import-manager` and `analysis` trees after the 0.1.4-Beta work.

This note identifies changes needed before editing the website content. It is intentionally an audit/planning document, not an edit of the published docs.

## Source Docs Reviewed

- `bodocs/src/content/docs/software-guide/setup-import-manager.mdx`
- `bodocs/src/content/docs/user-guide/import-manager-user-guide.mdx`
- `bodocs/src/content/docs/user-guide/import-manager-folder-structure-appendix.md`

## Code And Local Context Checked

- Import Manager UI and provisioning: `import-manager/bodaqs_import_manager/import_agent_setup.py`, `import-manager/bodaqs_import_manager/import_agent_provisioning.py`
- Import/preprocess execution: `analysis/bodaqs_analysis/import_agent.py`, `analysis/bodaqs_analysis/preprocess_profile.py`, `analysis/bodaqs_analysis/io_logger.py`
- data.syn.bike exporter: `analysis/bodaqs_analysis/exporters/data_syn_bike.py`
- Library shape note: `docs/analysis/Library_Shape_Run_Session_Bike_Profile_Changes.md`
- Release notes draft: `import-manager/docs/BODAQS Import Manager 0.1.4-Beta Release Notes Draft.md`
- Existing screenshot assets in `bodocs/src/assets/pics/`

## Summary

The Import Manager setup guide, user guide, and folder-structure appendix are now materially out of date. The largest conceptual drift is that the docs still describe a mostly source-local model:

- each source has its own bike profile folder;
- each source has its own settings/preprocess folder;
- libraries live directly under the library root;
- one imported archive generally equals one run;
- removing a source only removes the catalog/config entry.

The current app has moved toward a shared workspace model:

- shared bike profiles live under the libraries/workspace root;
- shared preprocess profiles live under the libraries/workspace root;
- shared event schemas live under the libraries/workspace root;
- new managed libraries live under a `libraries/` collection directory below that root;
- sources point at shared bike/preprocess profile files;
- a source scan can import multiple sessions into the same run;
- sources and libraries can be removed from the manager only, or completely removed from disk after confirmation.

The docs should be updated before they are used as end-user guidance for 0.1.4-Beta.

## Recommended Responsibility Split

- `software-guide/setup-import-manager.mdx` should be the first successful setup path:
  - install the app;
  - create or adopt a workspace;
  - create the first library and source;
  - configure the bike profile and optional note template;
  - run one first import.
- `user-guide/import-manager-user-guide.mdx` should be the operating guide:
  - everyday importing;
  - watch mode;
  - source and library management;
  - shared profile assignment;
  - naming;
  - Wi-Fi logger workflows;
  - exports;
  - troubleshooting.
- `user-guide/import-manager-folder-structure-appendix.md` should be the path and file reference:
  - app settings;
  - current managed workspace layout;
  - source folders;
  - shared bike/preprocess/event-schema folders;
  - managed library folders;
  - legacy compatibility notes.

## Existing Items Whose Details Have Changed

### Import Manager Setup Guide

- The setup guide currently shows the old provisioning workflow and should be updated around **Create Initial Library + Source**.
- It should introduce the split between:
  - **Libraries root**, which now contains managed libraries and shared profile folders;
  - **Sources root**, which contains source folders and workflow folders.
- It should mention **Use Existing Workspace** for adopting already-created shared roots on another computer.
- The setup steps should include:
  - `Generate data.syn.bike exports`;
  - source type selection;
  - optional session auto-naming;
  - optional draft setup note attachment.
- The quick folder tree should no longer show active source-local `bike/` and `settings/` folders for new sources.
- The bike-profile section should describe shared bike profile files under `bike_profiles/`, not source-local `<source>/bike`.
- The rear LUT section should say it maps rear sensor travel to rear wheel travel, and mention `mm`/`deg` input units.
- The setup guide should keep only a short conceptual folder tree and link to the appendix for full detail.
- The setup guide should include a short first-import test path:
  - local archive: copy `.zip` or supported logger file such as `.bdq` into `inbox/`;
  - run **Import Now**;
  - check `done/`, `failed/`, `runs/`, and optionally `syn/`.

### Import Manager User Guide

#### Opening Overview

- The overview currently says each source can have its own import settings, bike profile, and notes template. This needs to be revised:
  - sources still own note templates/presets under their `notes/` folder;
  - sources now normally reference shared bike profile files;
  - sources now normally reference shared preprocess profile files;
  - legacy source-local bike/settings folders can still work if a source config points at them.
- The opening should introduce the shared workspace concepts before listing source/library folders.
- The app title now includes the app version, for example `BODAQS Import Manager 0.1.4-Beta`.

#### Quick Folder Layout

- The user guide currently presents a simplified layout like:

  ```text
  BODAQS/
    libraries/<library>/
    sources/<source>/
  ```

  This no longer matches the current managed layout.
- A current conceptual layout should show the shared profile directories and the managed library collection, for example:

  ```text
  <data-or-workspace-root>/
    bike_profiles/
    preprocess_profiles/
    event_schemas/
    libraries/
      <library>/
        runs/
        library/
        syn/
    sources/
      <source>/
        import_source.json
        notes/
        fit/
        inbox/
        done/
        failed/
        staging/
  ```

- The docs should be careful with the terms `libraries root`, `library folder`, `sources root`, and `workspace/data root`. Current code can use separate source and library roots, while many real deployments use a common parent folder.

#### Sources

- The typical source folder no longer contains active `bike/` and `settings/` folders for newly provisioned managed sources.
- Current source folders normally contain:
  - `import_source.json`
  - `notes/`
  - `fit/`
  - `inbox/`
  - `done/`
  - `failed/`
  - `staging/`
- `bike/` and `settings/` should be documented as legacy/source-local compatibility locations, not the default current layout.
- `.bdq` archives/logs should be included where the docs currently imply that local archive sources are only `.zip` based.
- The source config now has explicit pointers to shared files:
  - `bike_profile_path`
  - `preprocess_profile_path`
- The source config can also include session naming configuration under `naming.session_description`.

#### Libraries

- New managed libraries are now created under:

  ```text
  <libraries-root>/libraries/<library>/
  ```

- Existing direct-child library folders remain supported for compatibility, but should not be presented as the default new layout.
- The current guide should distinguish:
  - the shared libraries/workspace root;
  - the `libraries/` collection directory;
  - an individual library artifact folder.
- The docs should mention that shared bike/preprocess/event-schema folders are not inside an individual library. They are shared across libraries that use the same root.

#### Manager Tab

- The current Libraries table has changed. It currently shows:
  - `Library Name`
  - `Syn Export`
- The current Sources table has changed. It currently shows:
  - `Enabled`
  - `Allow Reprocessing`
  - `Source Name`
  - `Type`
  - `Status`
  - `Target Library`
  - `Bike Name`
  - `Attach Note`
- The actions row has changed. It now includes:
  - `Refresh`
  - `Sync Workspace`
  - `Import Now`
  - `Start Watch`
  - `Stop Watch`
- The docs should explain `Allow Reprocessing`, especially because it affects whether archives in `done/` can be reprocessed.
- The docs should explain `Sync Workspace`: it discovers libraries/sources/profile files from the configured workspace roots and reconciles the UI with disk.

#### Source Context Menu

The documented context menu is out of date. The current source context menu includes:

- `Edit bike`
- `Assign bike profile`
- `Duplicate bike profile`
- `Assign preprocess profile`
- `Change target library`
- `Import naming`
- `Details`
- Wi-Fi source actions where applicable:
  - `Edit Wi-Fi settings`
  - `Check Logger`
  - `Request Upload Mode`
  - `Open Logger Web UI`
- `Validate`
- `Rename source`
- `Remove Source`

The docs should explain the difference between:

- editing the currently assigned shared bike profile;
- assigning an existing shared bike profile;
- duplicating a shared bike profile;
- assigning a different preprocess profile.

The docs should also mention that duplicating a bike profile does not automatically assign the duplicate to the source.

#### Library Context Menu

The guide should document the current library context menu:

- `Rename library`
- `Details`
- `Remove Library`

The remove behavior has changed and is described separately below.

#### Adding Libraries And Sources

- New library provisioning now creates or ensures the shared directories:
  - `bike_profiles/`
  - `preprocess_profiles/`
  - `event_schemas/`
- New source provisioning now creates a source folder with workflow subfolders, and points the source at shared bike/preprocess profile files.
- The current Provision tab includes session auto-naming controls:
  - `Auto-name sessions on import`
  - `Session base name`
- The current Provision tab includes a `Generate data.syn.bike exports` library option.
- The current Provision tab action row includes:
  - `Create Initial Library + Source`
  - `Use Existing Workspace`
  - `Apply App Settings`
- The guide should document when to use `Use Existing Workspace` versus creating a new library/source.

#### Import Now And Watch Mode

- `Import Now` can now prompt for an optional run-description override. Leaving it blank uses source/default naming.
- Session descriptions can be auto-generated from a base name and index.
- Detected sessions from the same source scan can now be processed into the same run, rather than every session being forced into a separate run.
- The docs should explain that run and session IDs remain stable machine-facing identifiers, while run/session descriptions are the user-facing names seen by downstream tools.
- The guide should mention that bulk detection and processing progress is now shown during the pass, rather than waiting for all sessions to complete.
- The user-facing difference between `Import Now` and `Start Watch` should be refreshed:
  - `Import Now` performs an immediate scan/import pass;
  - `Start Watch` starts continuous watching for enabled sources;
  - `Stop Watch` stops the watcher.

#### Run And Session Model

- The current docs still imply a one-archive/one-session/one-run mapping in several places.
- Current behavior is better described as:
  - a run is an import/preprocess batch for a source pass;
  - a run may contain one or more sessions;
  - each session remains addressable by `(run_id, session_id)`;
  - run and session descriptions are separate from IDs.
- The appendix should carry the detailed disk layout; the user guide only needs the operational model.

#### Bike Profiles

- The current guide says each source has its own bike profile. This is no longer the default model.
- Bike profiles are now shared files under:

  ```text
  <libraries-root>/bike_profiles/
  ```

- A source points to a bike profile file via `bike_profile_path`.
- Multiple sources can use the same bike profile.
- Assigning a bike profile changes which shared profile the source uses.
- Duplicating a bike profile creates a new shared file but does not automatically assign it.
- The guide should advise users to duplicate a profile before experimental edits if the same profile is shared by multiple sources.
- The rear wheel LUT section has changed:
  - the top text should refer to sensor travel, not shock travel;
  - LUT input units can be `mm` or `deg`;
  - the first table column heading updates to `sensor mm` or `sensor deg`;
  - the second table column maps to wheel travel in `mm`.
- The calibration/materialization text should account for rotary sensor channels and degree-based calibration/LUT input.

#### Preprocess Profiles And Event Schemas

- Preprocess profiles are no longer best described as source-local `settings/` files.
- Shared preprocess profiles now live under:

  ```text
  <libraries-root>/preprocess_profiles/
  ```

- Shared event schemas now live under:

  ```text
  <libraries-root>/event_schemas/
  ```

- A source references a preprocess profile via `preprocess_profile_path`.
- Event schemas are referenced from preprocess profiles by path. For the seeded shared profile, the event schema path is relative to the preprocess profile directory:

  ```text
  ../event_schemas/event_schema.yaml
  ```

- The docs should make clear that legacy source-local settings files remain usable if a source points at them.

#### Activity Detection

- The current guide does not cover the updated activity detection strategy.
- The current strategy should be documented at a user level:
  - GPS velocity is preferred when available;
  - wheel motion is used as the next option;
  - legacy preprocess profiles remain supported;
  - analog flat-zero signals can be genuine inactivity or a missing sensor, so the profile/source configuration matters.
- The seeded preprocess profile now uses a 0.1 second zeroing window.

#### GPS Handling

- The guide should be updated to reflect that logger GPS data is now used downstream, not just FIT-style GPS naming.
- Initial invalid GPS rows from logger files are tolerated when validity flags and finite coordinates indicate which points are usable.
- data.syn.bike exports now use logger GPS where available.
- FIT files are still useful for enrichment/fallback workflows, but the guide should not imply that FIT is the only way GPS gets into downstream exports.

#### data.syn.bike Exports

- The guide should mention that exports now handle missing travel at one end by writing zeros in the relevant columns, so the data.syn.bike visualiser can still open the file.
- The guide should explain that export files are re-generated on reprocess when the library/source settings request data.syn.bike output.
- The output description should include:
  - the CSV export file;
  - the helper/settings text file;
  - export manifests where relevant.
- The explanation of raw/travel scaling should be refreshed, especially for processed wheel travel mode and rotary sensors.
- The current `synoutputs.png` image shows the data.syn.bike web analyser, not the Import Manager's `syn/` output folder. It should not be the only visual for this section.

#### Removing Sources And Libraries

- The current guide says removing a source only removes it from the Import Manager and leaves folders untouched. This is now incomplete.
- Current remove dialogs offer two choices:
  - remove from Import Manager only;
  - remove from Import Manager and delete the folder from disk.
- Complete removal requires an additional confirmation where the user types `DELETE`.
- Complete source removal deletes the source folder if the filesystem operation succeeds.
- Complete library removal deletes the individual library data folder if the filesystem operation succeeds.
- Complete library removal does not delete shared workspace-level folders such as:
  - `bike_profiles/`
  - `preprocess_profiles/`
  - `event_schemas/`
- The guide should mention practical failure causes such as read-only/locked folders, especially under cloud-synced roots such as OneDrive.

#### Troubleshooting

The troubleshooting section should be expanded or refreshed for current behavior:

- Source removal/delete fails:
  - folder may be open in another process;
  - cloud sync may hold locks;
  - file attributes may be read-only;
  - user may have insufficient permission for that folder.
- Source appears with unexpected type/status:
  - this was fixed in the current build, but users should refresh/sync workspace after upgrading.
- Wi-Fi logger not discovered:
  - check AP versus station mode;
  - use fixed logger address where discovery is not available;
  - use `Open Logger Web UI` to confirm browser connectivity.
- No GPS in downstream export:
  - check whether logger GPS points are valid;
  - check FIT enrichment only if relying on FIT GPS;
  - check the preprocess profile's GPS stream handling.
- Session appears inactive:
  - check available activity signals;
  - GPS velocity is preferred;
  - wheel motion is fallback;
  - missing/flat analog signals can look like parked-bike inactivity.
- data.syn.bike file missing or incomplete:
  - verify library export setting;
  - verify reprocess setting;
  - check source `failed/` and logs;
  - remember that missing one-end travel should now produce zero-filled columns rather than an unreadable export.

#### Safe Operating Habits

- The current advice to keep one active bike profile per source is no longer right.
- Recommended habits should become:
  - treat shared bike/preprocess profiles as reusable workspace assets;
  - duplicate a profile before experimental edits if it is shared;
  - assign the intended profile explicitly after duplicating;
  - stop watch mode before major source/profile changes;
  - keep shared profiles under the managed profile directories rather than adding ad hoc source-local files;
  - back up shared profile directories along with libraries and sources.

### Folder And File Structure Appendix

#### Main Locations

- The appendix currently describes three locations: app settings, sources root, and libraries root. It needs one more layer of precision.
- The app settings file remains:

  ```text
  %LOCALAPPDATA%/BODAQS/import-agent/import_agent_app.json
  ```

- The sources root still contains source folders.
- The libraries/workspace root now contains shared assets plus the managed library collection:

  ```text
  <libraries-root>/
    bike_profiles/
    preprocess_profiles/
    event_schemas/
    libraries/
      <library>/
  ```

- The appendix should explain that code defaults and user-chosen roots can produce confusing names. For example, a folder named `libraries` may be the configured libraries root, and it may itself contain the managed `libraries/` collection directory.
- A vocabulary table would help:
  - app settings path;
  - sources root;
  - libraries/workspace root;
  - shared profile directories;
  - managed library collection directory;
  - individual library folder.

#### Portable Shared Workspace Example

- The portable/shared workspace example should include shared profile directories.
- A clearer example would be:

  ```text
  BODAQS-data/
    sources/
      <source>/
    bike_profiles/
      <bike-profile>.json
    preprocess_profiles/
      <preprocess-profile>.json
    event_schemas/
      event_schema.yaml
    libraries/
      <library>/
        runs/
        library/
        syn/
  ```

- The docs should explain that sources and libraries can be configured under the same data root, but they are still separate roots in app settings.

#### Source Folder

- The current source folder tree includes active `bike/` and `settings/` folders. That should move to a legacy compatibility note.
- The current managed source folder should be documented as:

  ```text
  <sources-root>/<source>/
    import_source.json
    notes/
    fit/
    inbox/
    done/
    failed/
    staging/
  ```

- `inbox/`, `done/`, `failed/`, and `staging/` should be described as workflow folders for local archives and logger downloads.
- `fit/` remains the place for FIT enrichment files.
- `notes/` remains source-owned.

#### Source Manifest

The `import_source.json` field descriptions need updates:

- `source_id`: stable source identifier.
- `display_name`: UI-facing source name.
- `source_type`: local archive or Wi-Fi logger style source.
- `library_id`: target library identifier used by the managed app.
- `artifacts_dir`: compatibility/direct path field; managed app primarily resolves `library_id` through app settings.
- `preprocess_profile_path`: path to the selected preprocess profile file, usually in shared `preprocess_profiles/`.
- `bike_profile_path`: path to the selected bike profile file, usually in shared `bike_profiles/`.
- `session_note`: source-local note template/preset configuration under `notes/`.
- `fit_dir`, `inbox_dir`, `done_dir`, `failed_dir`, `staging_dir`: source workflow directories.
- `force_reprocess`: whether already processed archives can be reprocessed.
- `logger_wifi`: Wi-Fi logger connection and upload-mode settings.
- `naming.session_description`: optional auto-naming settings for session descriptions.

#### Shared Bike Profiles

The appendix should add a new section for:

```text
<libraries-root>/bike_profiles/
```

It should explain:

- bike profiles are shared workspace assets;
- a source references a specific profile file;
- multiple sources may share one profile;
- duplicate creates a new profile file;
- duplicate does not automatically assign the new file;
- source-local `bike/` folders are legacy-compatible, not the normal new layout.

#### Shared Preprocess Profiles

The appendix should add a new section for:

```text
<libraries-root>/preprocess_profiles/
```

It should explain:

- preprocess profiles are shared workspace assets;
- a source references a specific profile file;
- a profile can reference event schemas by relative or absolute path;
- the seeded relative event schema path is:

  ```text
  ../event_schemas/event_schema.yaml
  ```

- source-local `settings/` folders are legacy-compatible, not the normal new layout.

#### Shared Event Schemas

The appendix should add a new section for:

```text
<libraries-root>/event_schemas/
```

It should explain:

- event schemas are shared workspace assets;
- the Import Manager does not need source-level event schema assignment because preprocess profiles already reference schema paths;
- event schemas can be reused by multiple preprocess profiles.

#### Library Folder

- The library folder example should be updated from direct-child library roots to the current managed default:

  ```text
  <libraries-root>/libraries/<library>/
    library_definition.json
    runs/
    library/
    syn/
  ```

- The docs should mention that older direct-child library folders remain readable for compatibility, but new libraries are created under the managed `libraries/` directory.

#### Runs And Sessions

- The appendix currently states that each run usually corresponds to one imported session. That is now misleading.
- Current wording should describe:
  - a run as a source scan/import batch;
  - a run may contain multiple sessions;
  - sessions are stored below the run;
  - the stable physical address is `(run_id, session_id)`.
- The run manifest can contain batch import metadata, including the import mode and session count.
- The appendix should describe run/session descriptions separately from run/session IDs.

#### Library Index And Catalog

- The existing `library/` state/index section is broadly still relevant, but should be checked for wording that assumes one run per session.
- Downstream tools should use manifests/catalogs and IDs rather than folder names alone.
- The docs should clarify whether browser/study-set columns labelled `run` and `session` show descriptions, IDs, or both, depending on the current downstream UI.

#### data.syn.bike Output Folder

- The appendix should include the current `syn/` folder output shape.
- It should show that exports are session-based and include generated CSV plus helper/settings/manifest files where present.
- It should explain that exports may be regenerated on reprocess.
- It should mention zero-filled columns for missing one-end travel.

#### Removing Data

- The appendix should add a section distinguishing:
  - remove from Import Manager only;
  - complete removal from Import Manager plus disk deletion.
- It should state exactly what complete deletion affects:
  - complete source removal deletes the source folder;
  - complete library removal deletes the individual library folder;
  - complete library removal does not delete shared profile/schema directories.
- It should caution that manual deletion outside the app may require `Sync Workspace` or app restart.

## New Items And Features Not Currently Covered

- Shared bike profile directory under the libraries/workspace root.
- Shared preprocess profile directory under the libraries/workspace root.
- Shared event schema directory under the libraries/workspace root.
- Managed `libraries/` collection directory below the configured libraries/workspace root.
- Assign bike profile action.
- Duplicate bike profile action and its non-auto-assignment behavior.
- Assign preprocess profile action.
- Import naming dialog for session auto-naming.
- Session auto-naming controls during source provisioning.
- Import Now run-description override prompt.
- Batch import behavior where multiple detected sessions can be processed into the same run.
- Progress updates during detection and processing of large batches.
- `Sync Workspace` action.
- `Allow Reprocessing` source column and behavior.
- Complete source removal with disk deletion and typed confirmation.
- Complete library removal with disk deletion and typed confirmation.
- Version number in the app title.
- Updated Wi-Fi logger AP-mode/fixed-address/open-web-UI workflows.
- Logger GPS use in downstream exports.
- data.syn.bike export behavior when one end of travel data is missing.
- Rotary-sensor related bike profile behavior:
  - degree-based LUT input;
  - degree-capable calibration materialization;
  - sensor travel wording for rear LUT.
- Updated activity detection preference order:
  - GPS velocity first;
  - wheel motion fallback;
  - legacy profiles supported.
- Seeded preprocess profile's 0.1 second zeroing window.
- Local archive handling for compact binary `.bdq` where relevant.

## Screenshots That Are Out Of Date

The following existing screenshots should be updated before the docs are refreshed.

### `import-manager.png`

Used near the start of both `setup-import-manager.mdx` and `import-manager-user-guide.mdx`.

This is substantially outdated:

- it shows the old unversioned app title;
- it shows old library/source table columns such as library/source IDs;
- it does not show the current `Allow Reprocessing`, `Bike Name`, and `Attach Note` columns;
- it does not show the current `Sync Workspace` action;
- it predates the shared profile model and current source status/type column fixes.

Recommendation: replace with a current full-window Manager tab screenshot from 0.1.4-Beta.

### `import-mgr-provisioning.png`

Used in `setup-import-manager.mdx`.

This screenshot is outdated:

- it does not show the current session auto-naming controls;
- it does not show the current action row, especially **Create Initial Library + Source** and **Use Existing Workspace**;
- it likely predates shared bike/preprocess/event-schema provisioning.

Recommendation: replace with a current Provision tab screenshot focused on first setup.

### `just-say-yes.png`

Used in `setup-import-manager.mdx`.

This screenshot should be checked against the current post-create prompt:

- the prompt still offers to open the bike-profile editor after source creation;
- the text may now mention the rear LUT and note template;
- the styling may need refreshing for a consistent 0.1.4-Beta screenshot set.

Recommendation: refresh if the current prompt differs materially from the image.

### `manager-tab.png`

This screenshot is outdated:

- it lacks the current app title/version;
- it lacks the current `Allow Reprocessing` source column;
- it lacks the current `Sync Workspace` button;
- it shows old table content/columns.

Recommendation: replace with a current Manager tab screenshot, preferably with one local source and one Wi-Fi logger source visible.

### `source-context-menu.png`

This screenshot is outdated:

- it is missing `Assign bike profile`;
- it is missing `Duplicate bike profile`;
- it is missing `Assign preprocess profile`;
- it is missing `Import naming`;
- it predates the current source table columns.

Recommendation: replace with a current source context menu screenshot.

### `provision-tab.png`

This screenshot is outdated:

- it does not show the current session auto-naming controls;
- it does not show the current action row including `Use Existing Workspace` and `Apply App Settings`;
- it does not show the current app title/version;
- it likely predates the current shared profile provisioning behavior.

Recommendation: replace with a current Provision tab screenshot with the session auto-naming row visible.

### `bike-profile-complete.png`

This screenshot is outdated:

- it refers to rear shock travel instead of rear sensor travel;
- it does not show the `mm`/`deg` LUT input unit radio buttons;
- it does not show the dynamic `sensor mm` or `sensor deg` first column heading;
- it predates the current shared bike profile model.

Recommendation: replace with a current bike profile editor screenshot showing the rear LUT area.

### `edit-note-profile.png`

This screenshot appears broadly consistent with the source-local note profile concept, but it should be checked during the final doc edit.

Recommendation: refresh only if the current dialog styling/fields have changed, or if a consistent 0.1.4-Beta screenshot set is desired.

### `synoutputs.png`

This image shows the data.syn.bike web analyser rather than the Import Manager output folder.

Recommendation: either move/use it in a data.syn.bike workflow section, or supplement it with a screenshot of the Import Manager/library `syn/` folder containing generated CSV/helper/manifest files.

## Screenshots Or Photos That Should Be Added

- Current full-window Manager tab showing:
  - versioned app title;
  - Libraries table;
  - Sources table with all current columns;
  - `Sync Workspace`, `Import Now`, `Start Watch`, and `Stop Watch`.
- Current Provision tab showing:
  - libraries root;
  - sources root;
  - target library;
  - source type;
  - session auto-naming controls;
  - action row.
- Current first-setup Provision tab screenshot for the setup guide, with **Create Initial Library + Source** clearly visible.
- Current post-create prompt asking whether to open the bike-profile editor.
- Source context menu showing the shared profile and import naming actions.
- Assign Bike Profile dialog.
- Duplicate Bike Profile dialog, ideally with a caption noting that the duplicate is not auto-assigned.
- Assign Preprocess Profile dialog/file picker.
- Import Naming dialog.
- Import Now run-description override prompt.
- Remove Source dialog showing the two removal choices.
- Typed `DELETE` confirmation dialog for complete removal.
- Remove Library dialog, including the warning that shared profile/schema folders are not deleted.
- Bike Profile editor showing the current rear LUT unit controls and `sensor mm`/`sensor deg` heading.
- Wi-Fi logger settings dialog showing discovery/fixed-address/upload/open-web-UI workflow.
- A progress/log screenshot from a multi-archive import showing detection and per-session processing updates.
- A current folder tree screenshot or generated diagram showing:
  - `sources/`
  - `bike_profiles/`
  - `preprocess_profiles/`
  - `event_schemas/`
  - `libraries/<library>/runs`
- A `syn/` output folder screenshot showing generated CSV, helper/settings text, and manifest files.
- Optional: a data.syn.bike web analyser screenshot after upload, kept separate from the file-output screenshot.

## Suggested Restructure

### Setup Guide

The setup guide should stay short and task-oriented. It should cover only the
first successful setup:

1. Install the app.
2. Create or adopt a workspace.
3. Create the first library and source.
4. Configure the bike profile and optional note template.
5. Run one first import.
6. Link onward to the user guide and appendix.

It should avoid becoming the full source/library management guide. It only
needs a short conceptual folder tree, with path details left to the appendix.

### Import Manager User Guide

The user guide should assume first setup is complete. It should be organised
around normal operation and ongoing management:

1. What the Import Manager manages
   - sources;
   - libraries;
   - shared profiles;
   - runs and sessions.
2. Everyday importing
   - local archive sources;
   - Wi-Fi logger sources;
   - `Import Now`;
   - watch mode;
   - progress and failures.
3. Naming and descriptions
   - run IDs versus run descriptions;
   - session IDs versus session descriptions;
   - Import Now run-description override;
   - session base-name auto-naming.
4. Managing shared profiles
   - bike profiles;
   - preprocess profiles;
   - event schemas;
   - source-local legacy compatibility.
5. Managing libraries and sources
   - sync workspace;
   - rename;
   - retarget;
   - remove from manager;
   - complete delete from disk.
6. Exports and downstream tools
   - data.syn.bike;
   - FIT enrichment;
   - logger GPS;
   - `syn/` folder outputs.
7. Troubleshooting
   - source discovery;
   - Wi-Fi logger discovery/AP mode;
   - failed imports;
   - inactive sessions;
   - deletion/access-denied problems.

### Folder And File Structure Appendix

The appendix should become the authoritative disk-layout reference and should separate current layout from legacy compatibility:

1. App settings
2. Workspace/library roots vocabulary
3. Current managed workspace tree
4. Source folders
5. Shared profile folders
6. Managed library folders
7. Runs and sessions
8. Library indices/catalogs
9. data.syn.bike outputs
10. Legacy source-local bike/settings folders
11. Remove/delete behavior
12. Sharing a workspace across computers

This would keep the main guide practical while letting the appendix carry the precise path details.

## Editorial Notes For The Later Content Edit

- Use `profile` carefully:
  - bike profile is shared;
  - preprocess profile is shared;
  - note profile/template is source-local.
- Use `description` for user-facing run/session names and `ID` for stable machine-facing names.
- Prefer `assign` for selecting an existing shared profile and `duplicate` for creating a new profile file.
- Avoid saying a source "owns" a bike/preprocess profile unless discussing legacy source-local compatibility.
- Be explicit that complete deletion is destructive and separate from ordinary removal from the Import Manager.
- Keep detailed implementation fields in the appendix; keep the main guide focused on what users need to do.

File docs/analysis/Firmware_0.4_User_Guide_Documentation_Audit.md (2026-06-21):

# Firmware 0.4 User Guide Documentation Audit

Status: draft  
Date: 2026-06-21  
Scope: `bodocs/src/content/docs/user-guide/index.mdx` and `bodocs/src/content/docs/user-guide/accessing logs and configuration.mdx`  
Firmware context: current `firmware` tree after the 0.4.0 feature work.

This note identifies changes needed before editing the website content. It is intentionally an audit/planning document, not an edit of the published docs.

## Source Docs Reviewed

- `bodocs/src/content/docs/user-guide/index.mdx`
- `bodocs/src/content/docs/user-guide/accessing logs and configuration.mdx`

## Firmware Areas Checked

- OLED/menu behavior: `firmware/src/MenuSystem.cpp`, `firmware/src/UI.cpp`, `firmware/src/DisplayManager.cpp`
- Web routes: `firmware/src/Routes_Config.cpp`, `firmware/src/Routes_Files.cpp`, `firmware/src/Routes_Api.cpp`, `firmware/src/HtmlUtil.cpp`
- Sensor model/registry: `firmware/src/SensorRegistry.cpp`, `firmware/src/SensorManager.cpp`, sensor class files
- File/log behavior: `firmware/src/StorageManager.cpp`, `firmware/src/BdqLogWriter.cpp`, `firmware/src/LogMetadataWriter.cpp`

## Existing Items Whose Details Have Changed

### Display Overview

- The idle footer no longer has a `Time:` label. It shows the clock on the left, optional GPS status in the middle, and battery percentage on the right.
- GPS status now appears only when a GPS sensor is configured:
  - `GPS` = fix achieved
  - `.....` = GPS configured and acquiring
  - `NOGPS` = GPS configured but absent/error/no usable state
- The top status line can now show AP-mode state as well as station Wi-Fi state. It alternates network name and IP when network is up.
- The status line can temporarily show board warnings such as missing SD card, SD not ready, analog rail fault, low battery, or battery alert.
- The existing `Idle.png` explanation needs updating to include GPS, battery percentage, and AP/status-warning behavior.

### Navigation Model And Main Menu

The top-level menu currently contains:

- `WiFi: ON/OFF/STARTING`
- `Upload: ON/OFF`
- `Mute sensors`
- `Sample rate: <rate> Hz`
- `Calibration`
- `Sag helper`
- `Sleep`
- `Settings`

The current docs still list `Reset time` and `Restart` as top-level items. These now live under `Settings`.

The new `Settings` submenu contains:

- `WiFi mode: STA/AP`
- `Log format`
- `Reset time`
- `Health`
- `Restart`
- `About`

### Logging Start/Stop

- The docs say Wi-Fi may be restored after stopping a log if it was active when logging started. Current behavior should be described more conservatively: starting a log stops Wi-Fi/web so sampling has ownership; users should manually re-enable Wi-Fi/upload mode after logging if needed.
- Logging is blocked while upload mode is active.
- The docs should clarify that web/config/file mutation is not a while-logging workflow.

### Marking Events

- The existing docs say marks require the bar switch and cannot be logged using the logger keypad. That may still be the intended user-facing policy, but the firmware now treats marks as a configurable button action rather than a hard-coded special case.
- The docs should describe the shipped/default user flow rather than implying a firmware limitation. Suggested wording: marks are normally made using the configured mark/bar-switch button while logging is active.
- Mention that the display shows `Marked` when the mark is accepted.

### Wi-Fi And Web Interface

- The docs currently assume station Wi-Fi only. Firmware now supports both station and access-point modes.
- The main menu Wi-Fi row starts/stops the selected Wi-Fi mode and web server. The row can show `WiFi: STARTING`.
- AP mode should be documented as a direct-connect workflow, typically using the logger AP SSID/password and the AP IP address.
- The Settings menu now has a `WiFi mode` picker (`Station` / `Access point`).
- The General web config page also exposes Wi-Fi mode, AP SSID, and AP password.
- AP credential changes should be described as taking effect after Wi-Fi restart, not necessarily immediately during the active browser session.

### Reset Time

- `Reset time` is now under `Settings`, not the top-level menu.
- Time sync depends on station Wi-Fi/NTP. AP mode is useful for direct browser access but does not provide internet NTP unless another route is present.
- The docs should distinguish station-mode NTP from AP-mode web access.

### Log Format

- Log format can be selected on-device from `Settings` -> `Log format`.
- The General web config page now offers three formats:
  - `BODAQS CSV`
  - `syn.bike CSV`
  - `BODAQS compact binary`
- The docs currently talk mainly about CSV and syn.bike output. They need to mention compact binary `.bdq` output, what it is for, and what downstream software support is required.

### Files Page

- The Files page now includes a `Logger upload` panel with:
  - upload mode active/inactive state
  - network mode/name/IP/hostname
  - importable session count
  - incomplete session count where applicable
  - enter/exit upload mode button
- Upload mode is now distinct from ordinary manual file browsing.
- Manual upload/create/delete operations are disabled while logging is active or upload mode is active.
- The docs should add `.bdq` compact binary files to the list of possible log files.
- The current text says `fip files` in the ZIP/download card. That looks like a typo and should be corrected.

### General Configuration Page

The current docs need updates for fields now present or changed:

- `Log format` includes compact binary.
- `Wi-Fi mode` is now configurable (`Station` / `Access point`).
- `AP SSID` and `AP password` are present.
- `HTTP time check URL` is present.
- Hidden SSID and static IP details remain present.
- Config pages are locked while logging is active or upload mode is active.
- The recommendation around `Timestamp mode` should be checked. The existing text says to generally leave it as `fast`, but the current defaults and downstream expectations should be verified before preserving that advice.

### Sensor Configuration Page Structure

- The Sensors page is no longer a single long editor for every sensor. It now shows a sensor summary table and a `New sensor` block.
- Each sensor has its own detail page at `/config/sensor?id=N`.
- Screenshots and text should reflect the list/detail split.
- Add/delete/type changes still require restart before relying on the live sensor set.

### Sensor Types

The currently documented sensor configuration is centered on analog pots/I2C basics. The supported type list now includes at least:

- Analog Potentiometer
- AS5600 String Pot (Analog)
- AS5600 String Pot (I2C)
- AS5600 Angle (I2C)
- AS5048B Angle (I2C)
- DAN-F10N GPS (UART)

The docs should describe these at a user-facing level, especially which fields appear for each family: analog input, I2C bus/address, UART port/baud, wrapping, GPS update rate/diagnostics, etc.

### Sensor Output Section

- Output mode is now firmware-limited to `RAW` and `LINEAR` in the web UI.
- The docs still describe logger-side `LUT` and `Poly` output modes as active options. That is out of date.
- The docs should say complex transforms are applied downstream during import/analysis. Legacy POLY/LUT configs may be read but saved back as LINEAR.
- `Units label` is no longer an editable override. Units are inherited from the sensor class/output mode.
- `Installed range` is now a sensor parameter for sag percentage display.
- Bus speed (`i2c_hz`) is no longer a per-sensor web field; bus speed is part of the board profile.

### Sensor Usage / Semantics

- Usage fields are still important: `End`, `Primary domain`, and `Primary quantity` feed log metadata and features such as Sag Helper.
- The docs should explicitly connect `primary_domain=suspension` to Sag Helper eligibility.
- GPS signals should be described in terms of signal semantics rather than as ordinary fixed-rate scalar sensors. Mention that GPS rows may initially be invalid and downstream processing should respect validity/status fields.

### Sensor Calibration Section

- `Calibration methods` is now read-only in the web UI. It reflects sensor capability/effective calibration availability; it is not a user override.
- Calibration state/values remain editable where exposed.
- Rotary zero calibration now includes a direction/polarity step (`Capture +move`) so the firmware can infer positive direction. The old docs describe zero as a single capture.
- Rotary polarity is now represented by `direction`; `invert` continues to be emitted for compatibility where needed.
- Range calibration language should be narrowed to sensor families that actually support it. Rotary angle sensors do not need range calibration for counts-to-degrees.
- The zero-calibration section currently has `<Flag src="" alt="">`; that should be replaced with a real screenshot or plain text until an image exists.

### Sample Rate

- The OLED sample-rate picker still offers `10, 20, 50, 100, 200, 500, 1000 Hz`.
- The web page numeric field allows a wider range. The docs should either document the OLED-supported preset list separately from the web numeric field, or recommend using presets unless there is a reason to do otherwise.
- Add a caution that some sensor combinations, especially external ADC and asynchronous sensors, may limit the practical logging rate.

### Mute Sensors

- The basic behavior remains, but the docs should mention that muted sensors are also hidden from Sag Helper and excluded from active logging output.

### Sleep / Power

- The broad behavior is still valid, but the Proto-E-specific warning is probably less central now that Proto F/RC3 are the active hardware targets. Consider moving that warning to a legacy hardware note.
- The docs should mention current board warnings on the idle display if keeping the display overview comprehensive.

## New Items Or Features Not Currently Covered

### Access Point Mode

Add a direct-connect workflow:

1. Set Wi-Fi mode to `Access point` from OLED Settings or General web config.
2. Start Wi-Fi from the main menu or configured button binding.
3. Connect laptop/phone to the logger AP SSID.
4. Browse to the AP IP shown on the OLED, typically the ESP32 AP address unless configured otherwise.
5. Understand that AP mode is for local browser access, not internet/NTP time sync.

### Upload Mode

Add a section explaining Upload Mode:

- What it is: a protected mode for Import Manager / session transfer workflows.
- How to enter/exit from the Files page and OLED main menu.
- What it changes: configuration and manual file mutations are locked while active.
- Why it exists: gives file transfer/import workflows clear ownership of the SD card/network interaction.

### Sag Helper

Add a full OLED feature section:

- Main menu item: `Sag helper`, after `Calibration` and before `Sleep`.
- Not available while logging; stop logging first.
- Shows unmuted sensors with `primary_domain=suspension`.
- Updates live values once per second.
- Up/down cycles display modes:
  - raw counts
  - linear units, only for sensors configured for linear output
  - sag percentage, only when `installed_range` is set
- Enter/mark freezes/unfreezes the displayed values.
- Frozen values briefly flash off every two seconds and show `HOLD`.
- Left exits back to the main menu.

### GPS Sensor Support

Add GPS coverage:

- DAN-F10N GPS over UART.
- GPS is asynchronous/lower-rate relative to the main log loop.
- GPS state appears on OLED footer when configured.
- GPS columns/signals need validity/status interpretation downstream.
- Initial invalid GPS rows are normal while acquiring a fix.
- GPS does not currently discipline the RTC in this firmware release.
- L5 is not enabled for now.

### Compact Binary Log Format

Add user-facing explanation of compact binary output:

- The file extension is `.bdq`.
- It is smaller/more efficient than CSV but requires compatible downstream tooling.
- Metadata/semantics remain important.
- Users who want simple manual inspection should keep using BODAQS CSV.

### RC3 And External ADC Analog Inputs

Add a short note for RC3 users:

- Analog input dropdowns are board-aware.
- RC3 analog inputs may be external ADC channels rather than ESP32 GPIO ADC pins.
- External ADC sampling has practical rate limits depending on channels/sensor configuration.

### New Rotary Sensors

Add sensor-type notes for:

- AS5600 angle sensor.
- AS5048B angle sensor.
- AS5600 string-pot modes if not already covered elsewhere.
- Direction/polarity calibration workflow.
- I2C address and bus selection at a high level.

### Health And About Screens

Add lightweight descriptions:

- `Health` shows SD, battery, analog rail, sample-rate/effective-rate style status.
- `About` gives device/firmware information.

### Web API / Import Manager Endpoints

Probably not a main user-guide topic, but the accessing-logs page may need a short note that Import Manager uses API endpoints and Upload Mode. Avoid documenting the API exhaustively in the user guide; link to an API/developer note if one exists.

## Screenshots / Photos That Are Out Of Date

These screenshots are referenced by the two reviewed docs and should be considered stale or at least suspect after the UI changes:

- `Idle.png` - footer/time/GPS/battery/status behavior changed.
- `mainmenu.png` - top-level menu items changed; add Upload, Sag helper, Settings; remove top-level Reset time/Restart.
- `connecting.png` - Wi-Fi row now can show `STARTING`; AP mode should be represented too.
- `wifiip.png` - idle Wi-Fi status now alternates network/IP and can show AP mode.
- `wifion.png` / `wifinetwork.png` if used elsewhere - likely old station-only assumptions.
- `mute.png` - verify against current list layout and muted marker.
- `samplerate.png` - likely mostly valid, but verify visible preset list and header.
- `calibration.png` - sensor list may now show changed calibration capabilities, including rotary zero-only cases.
- `rangestart.png` / `rangefinish.png` - verify phased calibration UI and labels.
- `config.png` - General page now includes compact binary and updated layout/locking behavior.
- `wifi.png` - Network section now includes Wi-Fi mode, AP SSID/password, HTTP time check URL, etc.
- `files.png` - Files page now includes the Logger upload panel and upload-mode controls.
- `sensorbasic.png` - sensor editing moved to detail pages and Basic has board-aware fields.
- `sensorbasici2c.png` - I2C page should be re-shot for current detail page; bus speed no longer appears as a sensor field.
- `sensoroutput.png` - output mode is now RAW/LINEAR only; no editable units label; installed range added.
- `sensorusage.png` - verify section appears only for sensors with usage params and matches current labels.
- `sensorcalibration.png` - calibration methods read-only; direction/zero_count fields for rotary sensors may need separate shots.
- `sensorwrapping.png` - verify against current string-pot wrapping fields and labels.
- `logformat.JPG` / `logformatmenu.JPG` - likely need updating for compact binary and Settings submenu placement if reused.

## Screenshots / Photos We Should Have But Currently Do Not

OLED screenshots/photos to add:

- Idle/status with no GPS configured.
- Idle/status with GPS acquiring (`.....`).
- Idle/status with GPS fixed (`GPS`).
- Idle/status in AP mode showing AP name/IP behavior.
- Main menu showing the current top-level item list.
- Settings menu showing Wi-Fi mode, Log format, Reset time, Health, Restart, About.
- Wi-Fi Mode picker (`Station` / `Access point`).
- Log Format picker including `BODAQS compact binary`.
- Upload Mode screen from the OLED.
- Sag Helper RAW mode with one or two suspension sensors.
- Sag Helper LINEAR mode.
- Sag Helper `%` mode with installed range configured.
- Sag Helper frozen/HOLD state.
- Rotary zero calibration `Capture +move` screen.
- Rotary calibration save/cancel screen after +move capture.
- Health screen.
- Optional: About screen.

Web screenshots to add:

- Files page with Logger upload panel at the top.
- Files page in upload mode.
- Files page while manual mutation is disabled.
- General config page showing compact binary and Network & NTP fields.
- General config page in AP mode with AP SSID/password fields.
- Sensors summary/list page.
- New sensor block with current supported type list.
- Sensor detail page for an analog pot on Proto F/RC3.
- Sensor detail page for an RC3 external ADC analog input showing board-aware analog input options.
- Sensor detail page for an I2C rotary angle sensor.
- Sensor detail page for DAN-F10N GPS over UART.
- Sensor detail Output section showing RAW/LINEAR only and installed range.
- Sensor detail Calibration section showing read-only calibration methods.
- Locked configuration warning while logging active.
- Locked configuration warning while upload mode active.

Photos that may be useful, depending on how far the user guide wants to go:

- Proto F logger with keypad/OLED in current enclosure.
- RC3 board/logger hardware if it is now a supported target for users.
- DAN-F10N GPS board wired to the UART pins.
- AS5600/AS5048 rotary sensor examples if sensor setup is covered in this guide rather than hardware docs.

## Suggested Restructure

### `Using the data logger` (`index.mdx`)

Suggested structure:

1. Display overview
   - Status line
   - Footer: time, GPS, battery
   - Warnings/toasts/dimming
2. Controls and navigation
   - Button model
   - Default bindings / bar-switch note
   - Menu navigation pattern
3. Start/stop logging and marks
   - Logging owns sensors/storage; Wi-Fi/upload mode are stopped/blocked
   - Marks from configured mark button
4. Main menu map
   - Short table of top-level items and what they do
5. Settings submenu
   - Wi-Fi mode
   - Log format
   - Reset time
   - Health/About/Restart
6. Wi-Fi quick start
   - Station mode summary
   - AP mode summary
   - Link to full accessing-logs/config page
7. Sensor operations
   - Mute sensors
   - Sample rate
   - Calibration overview
   - Sag Helper
8. Sleep/power

This would keep the on-device guide focused on what a rider/operator sees on the logger.

### `Accessing logger data and configuration`

Suggested structure:

1. What the web UI is for
   - Setup, file transfer, configuration
   - Not while logging
2. Connection options
   - Station mode
   - Access point mode
   - Finding IP/hostname
3. Files and upload mode
   - Files page overview
   - Manual downloads/ZIP
   - Upload mode and Import Manager workflow
   - What files you will see: `.CSV`, `.json`, `.bdq`
4. General configuration
   - Logger identity/rates/log formats
   - Time and timezone
   - Wi-Fi station/AP settings
5. Sensor configuration concepts
   - Sensor list vs sensor detail page
   - Basic/wiring
   - Output policy
   - Usage/semantics
   - Calibration state
   - Wrapping/other advanced fields
6. Sensor type notes
   - Analog pot / external ADC
   - AS5600 string pot
   - AS5600/AS5048 angle sensors
   - DAN-F10N GPS
7. Safety/locking behavior
   - Config locked while logging/upload mode
   - Manual file mutation disabled while logging/upload mode
   - Restart requirements after add/delete/type changes

### General Editorial Suggestions

- Use tables for menu items and web fields rather than long prose lists where possible. The firmware UI is now feature-rich enough that tables will be easier to maintain.
- Separate current user workflows from legacy caveats. Proto-E-specific limitations should move to a legacy hardware note unless the page is explicitly covering older builds.
- Avoid documenting every low-level sensor parameter inline. Instead, group parameters by concept and add type-specific notes for fields users are likely to touch.
- Treat complex transforms as downstream/import-manager work, not a logger-side workflow.
- Include a short glossary for terms that now matter to both firmware and downstream processing: `domain`, `quantity`, `linear output`, `installed range`, `upload mode`, `AP mode`, `valid GPS fix`.

## Priority Update List

Recommended first pass:

1. Replace `mainmenu.png`, `Idle.png`, `files.png`, `config.png`, `wifi.png`, and all sensor config screenshots.
2. Rewrite menu structure in `index.mdx` to match current top-level menu plus Settings submenu.
3. Add AP mode and upload mode to `accessing logs and configuration.mdx`.
4. Update sensor configuration text to match RAW/LINEAR-only output and split list/detail pages.
5. Add Sag Helper section.
6. Add GPS support and GPS footer/status section.
7. Fix calibration docs for rotary `Capture +move` direction calibration and read-only calibration methods.
8. Add compact binary `.bdq` format note.

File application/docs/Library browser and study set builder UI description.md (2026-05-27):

# UI description: Library Browser and Study Set Builder
This bit of the UI is intended to allow users to set the scope for analysis by defining a ‘study set’ (previously called a ‘cohort’). A study set specifies one or more sessions, 0 or more ‘groupings’ (previously called ‘aggregations’ – sets of one or more of the sessions in the study set) and 0 or more ‘tracks’ (collections of geospatial locations).

The handoff to visualization is a single study set definition.

## Overall layout
The UI is comprised of two panels with a fixed left-right orientation. The left panel is the ‘library browser’; the right is the ‘study set builder’. Both panels should be collapsible horizontally for when screen real estate is scarce.

## Library Browser
The Library Browser is intended to do three things:
-	allow users to find and specify sessions they want to place in a cohort
-	allow users to attach tracks to a study set (including defining new tracks)
-	provide a shortcut to analysis with a degenerate study set(i.e. pick a single session and go directly to analysis, with a one-session, 0 grouping, 0 geopoint study set created invisibly).
First implementation could be just the library selector and session selector.

It comprises the following UI elements:

### Library Selector
Permits the user to select one or more libraries from the library root. All the sessions in selected libraries are then available, subject to further filtering

### Session Selector
The UI point where sessions are added to a study set. Features of this element are:
-	Column control. The user can add, remove, resize and reorder the displayed columns. Available columns are a defined subset of run, session, preprocessing and bike metadata.
-	Ad-hoc filtering and sorting. The user can sort and filter on any of the available columns.
-	Quick metadata access. The user can click icons to view session notes, session metadata and data quality warnings.
-	Multi-select. The user can select one or more rows from the table. One of these rows is the primary selection, which determines the data displayed in the GPS Location UI element.
-	‘Add to study set’ control. The user can add one or more selected sessions to the current study set.
-	‘Analyze now’ control. The user can go directly to analysis with a single session.

### Filter Manager
A UI element that lists available filters, allows filters to be toggled on and off, and allows creation of new filters. Unlike ad-hoc filtering on the session selector columns, this control allows filters to be re-used. It is intended that multiple filters can be applied at one time.

### GPS Location window
A UI element that shows GPS data for the primary selection and/or selected Tracks. Also includes an entry point for creation of new Tracks.

### Track Manager
The UI point where Tracks are added to the study set or selected for display in the GPS location window. Also allows creation, editing and deletion of Tracks.

## Study Set Builder
The study set builder is intended to provide viewing (and editing) of the content of the current Study Set; permit saving, loading and editing of persisted Study Sets; and provide the main entry point for analysis.
It has two UI elements: Current Study Set and Saved Study Sets.

### Current Study Set
This set of controls contains two tables, one each for the Study Set’s Sessions and Tracks. It also allows groupings to be specified by selection of multiple sessions from the Sessions Table.

The Sessions Table displays the same set of columns as the Sessions Selector in the Library Browser, with a control for each to remove the session from the Study Set (and any groupings it is a part of). The Sessions Table also allows the user to define ‘groupings’.  (Implementation details TBD. Ideally these would be displayed with link lines, but simply having one or more grouping columns with checkboxes would be OK).

The Tracks table lists tracks that form part of the Study Set, with a control to remove each one. The columns show the Track name, the number of points, and controls to access deeper data (coordinates, map, distances etc).
The Current Study Set UI element also contains a text box and save button so the Study Set definition can be persisted, and an ‘analyze’ button to move to analysis of the Current Study Set

### Saved Study Sets
This set of controls contains a table listing saved Study Sets, with controls to analyze, view and load a single Study Set.

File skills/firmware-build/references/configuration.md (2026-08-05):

# Build Configuration Reference

All configuration lives in the "Configuration" section at the top of `firmware/build.sh`. An optional `firmware/build.conf` file can override any value — if it exists, it is sourced after the inline defaults.

## Settings

### DEFAULT_ENV

**What it controls:** Which PlatformIO environment is built when no env is specified on the command line.

**Default:** `thingplus_s3_usb_cdcserial_bodaqs_4f`

**When to prompt the user:** When they ask to change the default board, or when they're unsure which environment to use. Run `./build.sh list` to show available options. Ask which board they're targeting:

- SparkFun ESP32-S3 Thing Plus → `thingplus_s3_usb_cdcserial_bodaqs_4f` (BODAQS 4F profile)
- BODAQS V1RC3 custom board (A8) → `bodaqs_s3_mini_n4r2`
- Diagnostic/probe builds → envs ending in `_probe` or `_bringup`

### CHIP

**What it controls:** ESP32 chip variant passed to esptool for merge and flash operations.

**Default:** `esp32s3`

**When to change:** Only if switching to a different ESP32 family (e.g., `esp32`, `esp32c3`). All BODAQS boards use the ESP32-S3.

### DEFAULT_PORT

**What it controls:** Serial port used for flashing when `--port` is not passed on the command line.

**Default:** `auto`

**Special value:** `auto` (the default) auto-detects a connected ESP32-S3 on each run. The script scans `/dev/cu.*`, probes each port with esptool, and uses the first ESP32-S3 that responds. See the Port Detection section in SKILL.md.

**When to prompt the user:** When flashing fails with a port error, or when the user mentions a different USB port or device. Common macOS values:

- `/dev/cu.usbmodem1101` — typical ESP32-S3 USB CDC
- `/dev/cu.usbmodem2101` — second USB CDC device
- `/dev/cu.SLAB_USBtoUART` — CP210x UART bridge (older boards)
- `auto` — auto-detect by scanning /dev and probing with esptool

To discover available ports: `ls /dev/cu.*` with the device plugged in, or run `./build.sh detect`.

### FLASH_BAUD

**What it controls:** Upload baud rate for esptool flashing.

**Default:** Empty (auto-selected per board — 460800 for V1RC3, 921600 for Thing Plus)

**When to change:** Set to a specific value to force one rate for all boards. If flash uploads are unreliable, drop to `460800`. Higher speeds (`1500000`, `2000000`) work on some boards but can fail with long USB cables.

**Board-specific note:** The V1RC3 board definition specifies 460800 in its board JSON. When `FLASH_BAUD` is empty, build.sh auto-selects this rate for `bodaqs_s3_mini_n4r2*` environments. Setting `FLASH_BAUD` explicitly overrides this for all boards.

### OFFSET_BOOTLOADER, OFFSET_PARTITIONS, OFFSET_FIRMWARE

**What they control:** Flash addresses where each binary component is placed during the merge step.

**Defaults (no_ota partition scheme):**

| Setting | Default | Contents |
|---|---|---|
| `OFFSET_BOOTLOADER` | `0x0` | Bootloader |
| `OFFSET_PARTITIONS` | `0x8000` | Partition table |
| `OFFSET_FIRMWARE` | `0x10000` | Application firmware |

**When to change:** Only if `board_build.partitions` in `platformio.ini` is changed from `no_ota.csv` to a different partition scheme. The partition table CSV defines where each component lives. Verify offsets against the partition CSV before changing.

### OUTPUT_BIN

**What it controls:** Filename of the merged binary written to `firmware/`.

**Default:** `bodaqs-firmware.bin`

**When to change:** When building for multiple boards, set a per-env filename to avoid overwriting. Both environments produce the same `bodaqs-firmware.bin` by default — each build overwrites the previous binary. For multi-board workflows, use distinct names (e.g., `bodaqs-4f.bin` vs `bodaqs-v1rc3.bin`) via `build.conf`.

## Optional build.conf File

If `firmware/build.conf` exists, it is sourced after the inline defaults and can override any variable. This lets users keep customizations out of the script itself. Example:

```bash
# firmware/build.conf
DEFAULT_ENV="bodaqs_s3_mini_n4r2"
DEFAULT_PORT="/dev/cu.usbmodem2101"
OUTPUT_BIN="bodaqs-v1rc3.bin"
```

The file is optional — the script works standalone with inline defaults if `build.conf` does not exist.

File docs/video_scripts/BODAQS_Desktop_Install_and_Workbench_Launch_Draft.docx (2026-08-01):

BODAQS Desktop Install Package - Video 1 Draft Script

Bare installation and opening the BODAQS Workbench web app

Production Notes

1. Scope: install BODAQS Desktop, launch BODAQS Import Manager, and open the bundled BODAQS Workbench web app in the browser. Do not cover logger provisioning, imports, analysis, or Workbench usage.

2. Current build note: the Workbench button is enabled only after a managed workspace exists. This draft treats the first-run Create Default Workspace click as a minimal launch prerequisite, not a provisioning lesson. For a literal zero-workspace-step recording, preconfigure the machine before filming.

3. Version note: this draft is based on the current Windows bundle found locally as bodaqs-desktop-setup-0.1.6-dev.exe. Replace the version text in the final take if the release file name changes.

4. Prompt note: Windows UAC or SmartScreen may appear depending on signing and local policy. Include it only if it appears during recording.

Script Table

What is appearing on the screen | What I am saying in the voiceover
[0:00-0:18] Intro to camera. Simple lower third: Ben - creator of BODAQS. Keep the BODAQS logo or website subtle. | BODAQS is an open source mountain bike data acquisition project focused on making professional analysis tools affordable and accessible.
[0:18-0:29] Cut to screen recording. Start from a browser or clean desktop and frame the goal: download and install BODAQS Desktop. | In this short walkthrough we will download and install the BODAQS Desktop software package. In later videos we will cover connecting a logger, importing data and running analysis.
[0:29-0:50] In the browser: go to github.com, search BODAQS, open the BODAQS repository, open Releases, and download the latest BODAQS Desktop executable. | Start by downloading the latest BODAQS Desktop package from the BODAQS github repository. Go to Github.com; search BODAQS and head to the Releases page. Find the latest Desktop release and download the executable.
[0:50-1:07] Downloads folder. Double-click the downloaded BODAQS Desktop installer. Show UAC or SmartScreen only if it appears, then continue. | Double-click the BODAQS Desktop installer. If Windows asks for permission, continue only if you downloaded the installer from the official BODAQS release location. See the notes at the end of this video for how to verify that the package is safe to install.
[1:07-1:20] BODAQS Desktop Setup opens. Move through the welcome page toward the install options. | The installer packages several components: the BODAQS Import Manager and local Library Service, the BODAQS Workbench web app, and an optional sample library so you can try out the software without needing a BODAQS logger.
[1:20-1:26] Destination Location page. Leave the default Program Files install folder and click Next. | Accept the default install folder unless you prefer a different location.
[1:26-1:36] Additional Tasks page. Leave the demo library option selected; tick desktop shortcut only if desired; click Next. | Choose whether to create a desktop shortcut. For a first install, we recommend keeping the demo library option selected.
[1:36-1:55] Ready to Install, then install progress. Use a quick cut or time-lapse while files copy. | Click Install and wait for the files to copy.
[1:55-2:02] Completing Setup page. Keep Launch BODAQS Import Manager selected and click Finish. | Leave Launch BODAQS Import Manager selected and click Finish.
[2:02-2:18] BODAQS Import Manager opens on the Manager tab. Default/demo library rows are already present. Avoid the Provision tab. | The BODAQS import manager is an application that runs on your computer and handles the import and pre-processing of files from your logger. We will cover configuration of the Import Manager in a later video.
[2:18-2:38] Briefly hold on the Manager tab. Cursor points to Libraries/Sources, then to Open BODAQS Workbench. Do not start watch mode or import. | For now, just note the general functions of the import manager: collecting log files from one or more loggers via file copy or wifi; pre-processing the data for easy presentation; matching and attaching GPS data from Garmin devices, and attaching bike setup notes from your template.
[2:38-2:45] Click Open BODAQS Workbench. Wait for the browser tab to open. | Click Open BODAQS Workbench. This opens the BODAQS Workbench analysis app in your web browser.
[2:45-2:56] Browser opens to the local Workbench. Hold on Library Browser and Study Set Builder while the demo library/session list loads. | When the browser opens, the Library Browser and Study Set Builder screen appears. After a couple of seconds, the demo library should load.
[2:56-3:07] Hold on the loaded demo data in Workbench. Do not click into analysis; optionally move the cursor over the visible run/session table. | In the next video, we will examine the runs in the demo library and demonstrate some of the features of the BODAQS Workbench analysis app.
[3:07-3:17] Outro to camera or simple end card with bodaqs.net, Instagram, and Discord. | For more information, visit bodaqs.net, follow us on Instagram or join our Discord server. Thank you for watching and see you in the next video.

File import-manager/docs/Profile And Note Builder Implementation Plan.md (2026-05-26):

# BODAQS Import Manager Profile And Note Builder Plan

Status: implemented second slice

## Goal

Make normal source setup possible without hand-editing JSON. A user should be
able to create or duplicate a bike profile, edit the rear shock-to-wheel LUT,
choose note-template fields from a master catalog, and redirect a source to a
different library from the Import Manager UI.

The bike profile is the user-facing anchor for bike-specific configuration.
The rear LUT remains part of the bike profile, and bike-specific note templates
and setup presets are managed from the bike-profile editing flow.

## Phase 1. Source Library Retargeting

Implemented:

- app-config update helper for changing a source's target library
- source-local `import_source.json` update for `library_id` and `artifacts_dir`
- Manager UI `Change Library` action
- tests for app-config and source-config consistency

## Phase 2. Reusable Builder Models

Implemented:

- `bodaqs_import_manager.import_agent_profile_builders`
- source-local discovery of exactly one valid bike profile, session note
  template, and bike setup preset
- form-value extraction/application for bike profiles
- rear LUT parse/format/update helpers
- note-template field catalog loading and validation
- tests for builder behavior

## Phase 3. Bike Profile Editor

Implemented:

- Manager UI `Edit Bike` action
- editable bike/profile basics
- editable front fork travel, rear shock travel, and rear wheel travel
- save-time bike-profile validation
- setup-preset synchronization to keep draft notes linked to the active bike
  profile
- profile IDs are derived from the display name for normal UI use
- note-template IDs are kept/derived internally rather than exposed in the
  normal field-selection UI
- bike-profile `setup` fields have been removed from the shipped default and
  are stripped when profiles are saved through the builder

Future refinement:

- richer field grouping and validation hints
- optional sensor/install details in the form

## Phase 4. Rear LUT Editor

Implemented:

- rear LUT editing is launched from the bike-profile editor
- dedicated LUT dialog using editable `shock_mm, wheel_mm` lines
- interpolation/extrapolation controls
- enabled/disabled control
- save-time strict monotonic input validation

Future refinement:

- graphical preview
- add/delete row table controls
- import/export LUT CSV

## Phase 5. Note Template Field Builder

Implemented:

- master field catalog asset in `import_agent_assets`
- note-template editing is launched from the bike-profile editor
- scrollable field selector
- template id, version, title, description, and custom-field controls
- setup-preset filtering to selected fields
- target bike-profile relinking

Future refinement:

- preset value editor for chosen fields
- field catalog grouping/filtering
- custom user-defined field creation

## Phase 6. Copy From Existing Source

Implemented:

- Manager UI `Copy Bike` action
- Manager UI `Copy Notes` action
- copied files remain independent source-local files
- copied note setup presets relink to the target source's bike profile

## Phase 7. Provisioning Shortcuts

Implemented:

- newly created sources are selected in the Manager tab
- after source creation, the app offers to open the bike-profile editor
- after source creation, the app offers to open the note-template field selector

Future refinement:

- first-run wizard page for choosing "start from defaults" vs "copy from
  existing source"
- combined bike/profile/note summary screen before creating the source

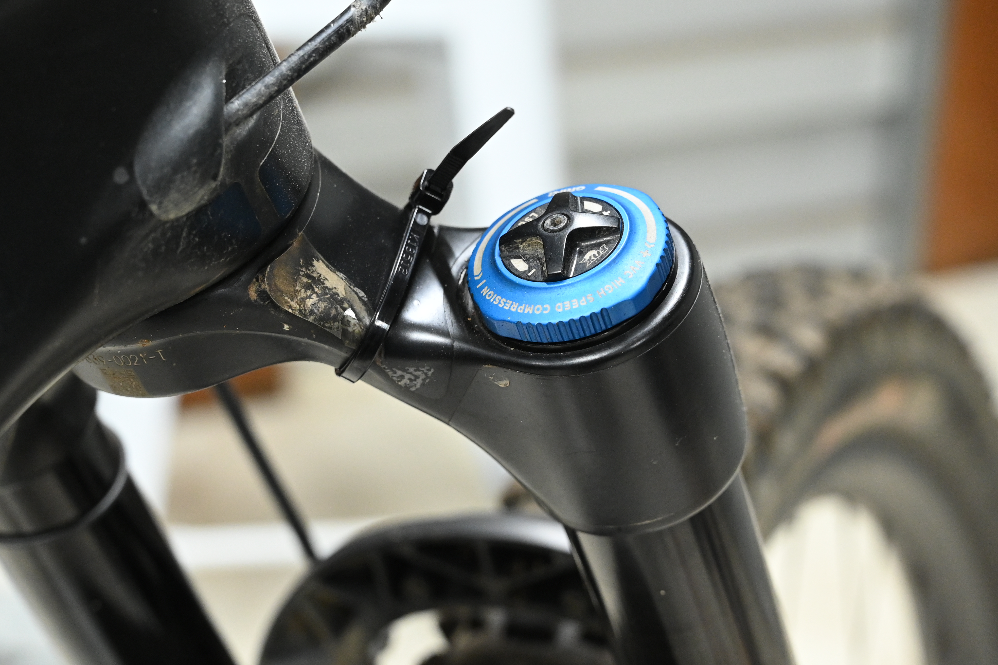
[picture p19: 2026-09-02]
bodocs/src/assets/pics/bike-installation-guide/pot-upper-crown-ziptie.JPG

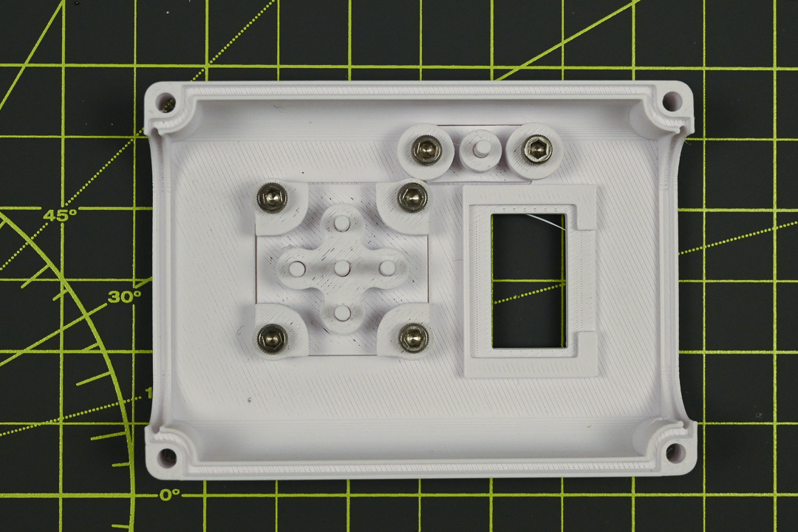
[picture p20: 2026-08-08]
bodocs/src/assets/pics/logger-build-guide/build-a8-8.png

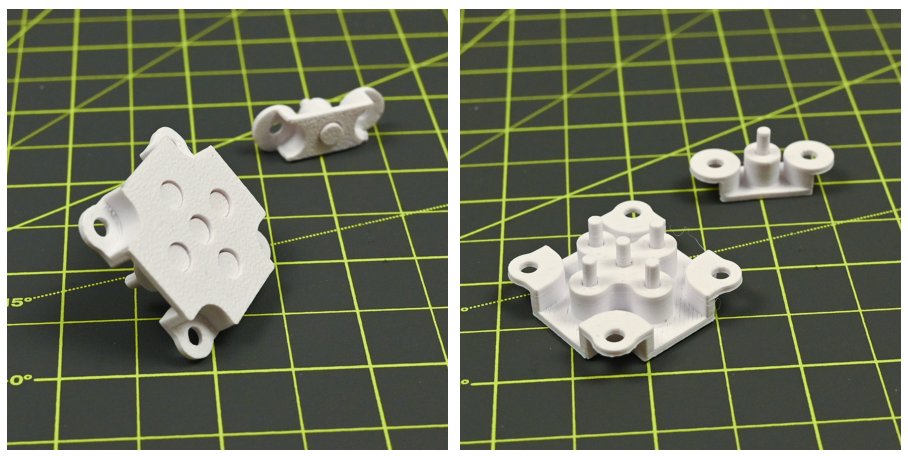
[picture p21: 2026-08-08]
bodocs/src/assets/pics/logger-build-guide/build-a8-7.png

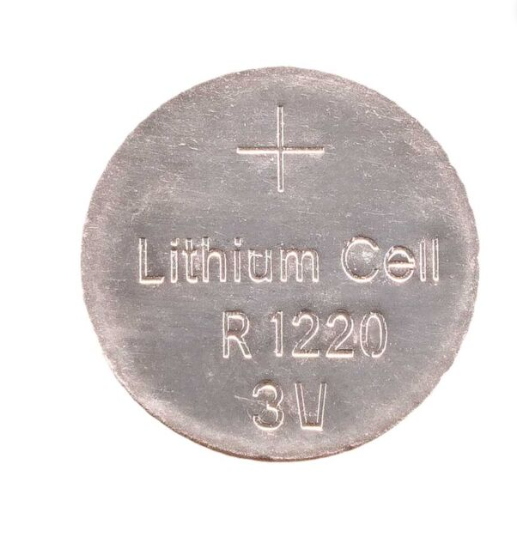
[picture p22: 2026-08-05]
bodocs/src/assets/pics/logger-build-guide/button-cell.png

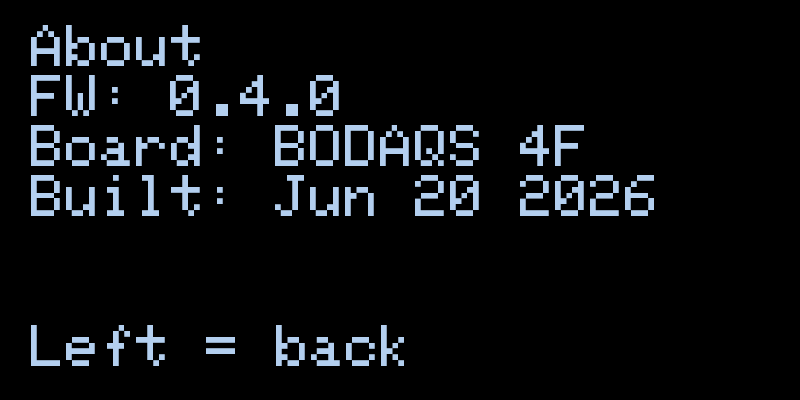
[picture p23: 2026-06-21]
bodocs/src/assets/pics/user-guide/oled-about.png

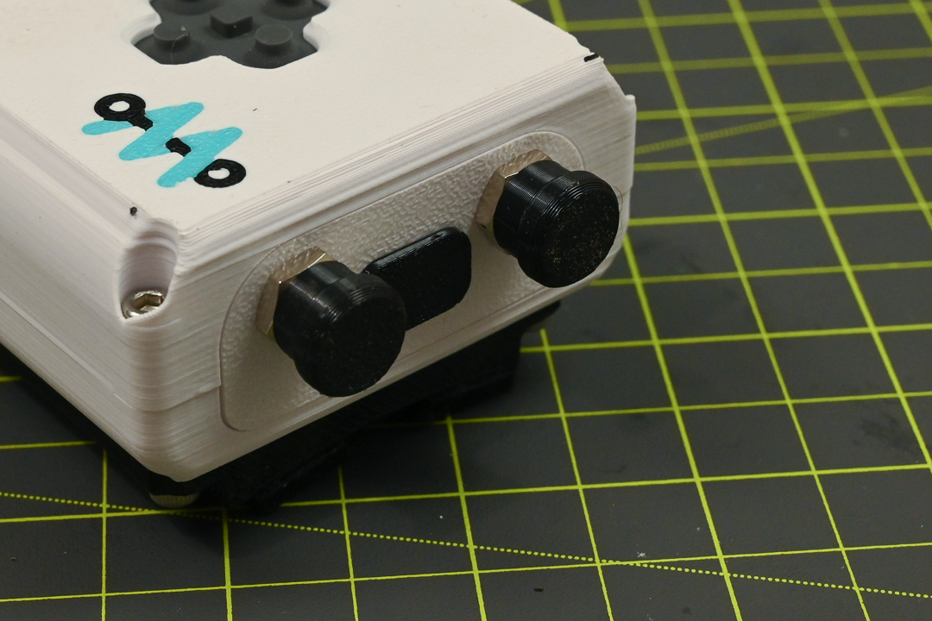
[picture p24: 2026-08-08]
bodocs/src/assets/pics/logger-build-guide/build-a8-21.png

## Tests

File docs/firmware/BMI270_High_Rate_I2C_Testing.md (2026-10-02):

# BMI270 high-rate I2C test plan

Status: exploratory mixed-bus endpoint; full-length bench runs completed and
bike qualification pending, 2026-09-19.

## Purpose

Characterize how far the existing A8 I2C architecture can support four BMI270
accel/gyro streams before choosing whether any production configuration can
remain on I2C. This is a transport and timing test; it does not qualify the
BMI270 for a 1 kHz measurement bandwidth.

## Configuration controls

- `profile`: `orientation_200`, `orientation_400`, `orientation_800`,
  `orientation_1600`, or the BDQ-v2-only `accel_800_gyro_200` and
  `accel_1600_gyro_200`. The orientation profiles use equal accel/gyro ODRs;
  the mixed profiles use 800 or 1600 Hz accel and 200 Hz gyro. Range and
  current filter/performance selections remain unchanged from
  `orientation_200`.
- `fifo_poll_rate_hz`: 25, 50, 100, 200, or 400 Hz generally. An experimental
  10 Hz selection is accepted only with `accel_800_gyro_200`. This controls how
  often the FIFO is serviced, not the IMU sample rate.
- `max_output_rate_hz`: legacy CSV/BDQ-v1 row materialisation only. It is
  retained in saved configurations but hidden from the IMU web editor. Use
  BDQ v2 to retain each IMU at its selected native rate.

The stable default is `orientation_200` with `fifo_poll_rate_hz=200`.

## Capacity expectation

A combined accel/gyro FIFO frame occupies 13 bytes. Ignoring sensor-time and
transaction overhead, one IMU therefore produces 2.6, 5.2, 10.4, or 20.8 kB/s
at the four supported rates. The scheduler's conservative 400 kbit/s model
allows about 40 kB/s per bus (10 wire bits per transferred byte). Consequently,
two 800 sample/s IMUs consume roughly 52% of a bus before overhead, while two
1600 sample/s IMUs require 41.6 kB/s and cannot be sustained by that model.

The 1600/200 mixed profile produces at most about 12.6 kB/s per IMU under the
planner's conservative accounting (single-sensor headers counted separately),
versus 20.8 kB/s for `orientation_1600`. The 800/200 profile is a lower-load
comparison point. Two 1600/200 IMUs remain an intentional ceiling experiment
at 400 kbit/s, but are materially more plausible than two full six-axis
1600 Hz streams.

This calculation is an expected boundary, not a substitute for the cable test.

## Shared-bus AS5600 priority

The AS5600 has no FIFO, so a late read loses timing quality in a way that a
late BMI270 FIFO drain normally does not. The bus scheduler therefore treats
AS5600 angle acquisitions as latency-sensitive. Before beginning a potentially
long BMI270 drain, it looks ahead to the next AS5600 deadline. If that deadline
would fall inside the drain, the scheduler may service the AS5600 first.

This is bounded priority, not unconditional priority. A pending BMI270 drain
may yield at most twice, only after that IMU has completed an initial successful
drain, and only when the estimated deferral remains inside a profile- and
poll-rate-dependent service gap. The normal gap is capped at 70 ms. The
experimental 10 Hz 800/200 case permits 140 ms. Both are further limited to the
time required to fill 60% of the 2048-byte FIFO; the remaining space is reserved
for samples arriving while the eventual drain is in progress. Transactions
already in progress are never pre-empted. The final summary reports
`latency_sensitive`, `maximum_service_gap_us`, `priority_yield_limit`,
`priority_service_count`, `priority_deferral_count`, and
`priority_deferral_maximum_us` for each scheduler client. The last value is the
maximum cumulative AS5600 deferral applied before one buffered service.
`maximum_successful_service_interval_us` records the largest observed interval
between successful client completions.

For the first comparison run, use a 200 Hz primary stream, an AS5600 asynchronous
rate of zero (meaning follow the 200 Hz primary rate), the 800/200 IMU profile,
and 25 Hz FIFO polling. Compare AS5600 achieved rate and start lateness against
the previous run, while confirming that IMU FIFO high-water marks, service gaps,
overflows, sequence gaps, and discontinuities remain acceptable.

The final mixed-bus experiment uses `accel_800_gyro_200`, 10 Hz FIFO polling,
an explicit 500 Hz AS5600 asynchronous target, and a 200 Hz primary stream.
BMI270 temperature is sampled at 2 Hz and held between reads; the short
sensor-time observation remains at 10 Hz. At 10 Hz the acquisition recovery
threshold is reduced from three consecutive failures to two so that recovery
begins before the FIFO's nominal coverage can be exhausted.

This is the endpoint for optimising buffered and unbuffered sensors on the same
400 kHz trunk. Do not add further AS5600 priority levels, reduce BMI270 FIFO
service below 10 Hz, or admit 10 Hz service for higher-throughput profiles. If
the final experiment is insufficient, change the transport architecture: use a
separate bus, qualify Fast-mode Plus electrically, choose a buffered rotary
sensor, or move acquisition to a satellite node.

## Bench sequence

Use BDQ v2, disable radio/UI activity, and retain the intended two-IMUs-per-bus
wiring and 600-1200 mm trunks.

1. Establish a clean four-IMU baseline at 200 sample/s and 200 Hz FIFO service.
2. For 400 and 800 sample/s, test FIFO service at 200, 100, then 50 Hz. Lower
   service rates reduce transaction setup overhead but increase batch latency
   and the consequence of a delayed drain.
3. At 1600 sample/s, first test one active IMU on each bus. Four IMUs at
   `accel_1600_gyro_200` have produced complete short-cable bench runs of about
   13 minutes, but this is still near the measured bus ceiling and is not yet
   qualified with full-length cabling or motion.
4. Repeat the limiting cases at realistic cable length, then with the proposed
   I2C accelerators only if electrical errors or edge quality are the limiting
   mechanism.
5. Repeat each viable point for at least 10 minutes and include representative
   auxiliary I2C and analogue sensor activity up to its expected 200 Hz ceiling.

## Evidence to retain

For each run preserve the BDQ v2 file and final summary, configuration, cable
length/topology, supply voltage at each node, pull-up/accelerator arrangement,
and oscilloscope captures for marginal electrical cases. Review at minimum:

- achieved FIFO service and native record rates per IMU;
- I2C bus occupancy, transaction duration/failure counts, service deadline
  misses, missed slots, and maximum start lateness;
- FIFO full/skip events, queue high-water marks and drops, parser drops, stream
  sequence gaps, and timing-degraded samples split by accel, gyro, and other
  causes; accel/gyro native-time discontinuities and gyro association fallback;
- short sensor-time register-read attempts, failures, drops, duration, and the
  resulting host-time observation windows; these 10 Hz reads add bus load and
  should be included when comparing runs;
- primary logger wake lateness, missed slots, queue drops, and storage timing;
- supply droop and SDA/SCL rise time at the furthest node.
- bus-recovery attempts/successes/failures and before/after SDA/SCL levels in
  `i2c_scheduler_timing.buses`, plus the serial `[I2C] busN recovery` line.

After failed device-level recovery caused by an I2C communication error, the
firmware can detach and reinitialize that bus. If SDA remains low while SCL is
free, it tries up to nine open-drain clock pulses and a STOP. The bus mutex
excludes other users during this operation, and each BMI270 on that bus marks
its next samples as a discontinuity. Attempts are bounded and rate-limited;
if SCL or SDA remains held low, software cannot guarantee recovery without a
separately switchable sensor supply or physical intervention. A recovery does
not make lost samples or their timing reconstructible.

A point is not viable if it has silent or unexplained loss. Numerical acceptance
limits for timing and error rate should be set after the first clean baseline;
all raw counters remain available so that decision does not need to be embedded
in firmware.

## Measurement-bandwidth caveat

Sampling at 1600 sample/s limits unaliased content to below 800 Hz even before
allowing transition band and amplitude/phase tolerances. The user's required
1 kHz acceleration band therefore needs an IMU sampling above 2 ksample/s and a
verified filter response; the BMI270 I2C trials can still establish the A8's
practical multi-device transport ceiling.

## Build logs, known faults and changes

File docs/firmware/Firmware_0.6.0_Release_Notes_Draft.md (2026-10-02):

# BODAQS Firmware 0.6.0 Release Notes Draft

Status: draft  
Release date: TBD

Firmware `0.6.0` is a feature and usability release for BODAQS A8, RC3, and
Prototype F loggers. It adds BDQ v2 multi-stream logging, expands BMI270 support
for multi-IMU and higher-rate configurations, raises the usable A8 ADC sampling
ceiling, and gives A8 and RC3 distinct power-management behavior.

## Highlights

- Added opt-in BDQ v2 multi-stream logging. A recording can contain a primary
  stream plus independent sensor-native streams, allowing high-rate devices to
  retain their native cadence without forcing every channel into one row rate.
- Expanded BMI270 support with selectable acquisition profiles and multi-IMU
  operation, including configurations with up to four IMUs.
- Removed the A8 external-ADC 500 Hz cap, increased the ADC conversion-time
  budget from 55% to 70%, and added 700 Hz to the permitted logger sample rates.
- Split the A8 and RC3 board profiles. A8 no longer has a default Sleep button
  binding or a Sleep menu item; RC3 and Prototype F retain Sleep because they
  use it as their user power-off function.
- Simplified the paused logging display to show `Logging` once, made the sensor
  mute list scroll, and stopped muted IMUs from unnecessarily holding the OLED
  in its reduced-update logging state.
- Moved Restart from Settings to the bottom of the main menu.

## Logging and IMU Changes

BDQ v2 is selected with `log_format=bodaqs_multi_stream_binary`. Existing CSV
and BDQ v1 selections remain supported. The new format records a primary stream
alongside independent native-rate streams and includes the catalog, event, and
diagnostic information needed to interpret them downstream. Use current BODAQS
import and analysis tooling when reading BDQ v2 files.

BMI270 support now includes several accelerometer and gyroscope rate profiles,
mixed-rate FIFO handling, dynamically sized queues, and stronger FIFO, I2C, and
timing diagnostics. The I2C scheduler and recovery paths have also been improved
for shared-bus, multi-sensor operation.

## Sample Rates and A8 ADC Capacity

The permitted logger rates are now:

```text
10, 20, 50, 100, 200, 500, 700, and 1000 Hz
```

The A8 external ADC gate now accepts configurations whose estimated conversion
time uses up to 70% of an ADC's available time. There is no longer a separate
500 Hz hard cap. Capacity still depends on how many active channels share each
ADC; the validation error reports the accepted rate for the current channel
allocation.

The higher budget reduces timing margin for conversion variation, I2C traffic,
and other runtime work. High-rate configurations, especially 700 Hz and 1000 Hz,
should be checked on physical hardware for missed samples and data freshness
before routine deployment.

## Board and User-Interface Changes

- A8 and RC3 now compile against separate board profiles while retaining their
  shared pin mapping.
- A8 defaults no longer bind a held button to Sleep, and its menu omits Sleep.
- RC3 and Prototype F continue to expose Sleep and its default button binding.
- Existing A8 configuration files with an explicit Sleep binding retain that
  binding until the configuration is updated.
- Restart is now the final item on the main menu.
- The reduced-update logging screen now displays `Logging` in full-size text and
  removes the duplicate small `logging` label.
- The sensor mute menu scrolls when more than five sensors are configured.
- When every asynchronous I2C sensor is muted, the OLED can resume normal
  updates after the logging warm-up period because no sensor deadline is at
  risk.

## Build and Developer Tooling

- Added a dedicated RC3 production build target.
- Removed the obsolete ADC diagnostic, AS5048 probe, and GPS UART probe
  PlatformIO tasks. Their dormant source helpers remain available if future
  diagnostic work needs them.
- Added host coverage for the A8, RC3, and Prototype F board-profile behavior.

## Compatibility and Migration

- Use the firmware image that matches the logger hardware. A8 and RC3 images are
  now distinct even though the boards share their pin mapping.
- Update A8 configuration files to remove any explicit Sleep button binding.
- Existing CSV and BDQ v1 configurations remain valid. BDQ v2 is opt-in.
- Use current BODAQS import and analysis tooling for BDQ v2 recordings and
  multi-IMU native streams.
- The nominal 700 Hz period is represented in integer microseconds, producing an
  effective scheduler cadence of approximately 700.28 Hz.

## Release Images

The release directory contains application, bootloader, partition, and combined
full-flash images for all three supported boards:

```text
firmware/dist/0.6.0/
```

| Image | Purpose | SHA-256 |
| --- | --- | --- |
| `bodaqs_a8-0.6.0.bin` | A8 application update | `20E221E611BDCF6235BFDBC3B00C1CA490EC597F8B31A83FA14A5B6DA6358DFD` |
| `bodaqs_a8-0.6.0-bootloader.bin` | A8 bootloader | `E01A2300DE23C8D601E9F2A37684B5DBC83AE37132D5A8833E23520AFD895F92` |
| `bodaqs_a8-0.6.0-partitions.bin` | A8 partition table | `6A88D59601A83A16A19A08114B59D338324B8DEC267D8B43E5D61AD56EC92102` |
| `bodaqs_a8-0.6.0-full.bin` | A8 combined full-flash image | `AF38A5260547A1C6C0545FD881EEA77ABF0D1BC3B87866BB3A853B5F6164EDB5` |
| `bodaqs_v1RC3-0.6.0.bin` | RC3 application update | `D73C72C2638463E94272D03C0C40C11EDCCD9F6F2285D9A1836B23177A1608BA` |
| `bodaqs_v1RC3-0.6.0-bootloader.bin` | RC3 bootloader | `E01A2300DE23C8D601E9F2A37684B5DBC83AE37132D5A8833E23520AFD895F92` |
| `bodaqs_v1RC3-0.6.0-partitions.bin` | RC3 partition table | `6A88D59601A83A16A19A08114B59D338324B8DEC267D8B43E5D61AD56EC92102` |
| `bodaqs_v1RC3-0.6.0-full.bin` | RC3 combined full-flash image | `DFB9E206592D1DA48BBBDF1F39AFBA1F5F932A3C4974218E8387698BF7444ACC` |
| `bodaqs_4f-0.6.0.bin` | Prototype F application update | `381C5537C53427DFF0EB1142D9A3C165DD7630DA768CC5CFAC90EBD77BB11218` |
| `bodaqs_4f-0.6.0-bootloader.bin` | Prototype F bootloader | `9BF9AAB34441621D794360CA427CBDDC3D62F38A7950F8790696BB3D7986769F` |
| `bodaqs_4f-0.6.0-partitions.bin` | Prototype F partition table | `6A88D59601A83A16A19A08114B59D338324B8DEC267D8B43E5D61AD56EC92102` |
| `bodaqs_4f-0.6.0-full.bin` | Prototype F combined full-flash image | `380715DA89C0B3D28D636F02A35C330FCE1B2DE83D208E664E8A6C261D30848F` |

## Flash Addresses

For a normal application-only update, flash the matching application image at
`0x10000`. For a blank or erased logger, flash the matching `-full.bin` image at
`0x00000`.

The separate component offsets are:

```text
0x00000  <board>-0.6.0-bootloader.bin
0x08000  <board>-0.6.0-partitions.bin
0x10000  <board>-0.6.0.bin
```

Do not mix components from different board targets.

## Validation Performed

- The full native host test suite passed.
- All three production PlatformIO environments built successfully:
  - A8: 162,628 of 327,680 bytes RAM (49.6%); 1,827,045 of 2,097,152 bytes
    application flash (87.1%).
  - RC3: 162,628 of 327,680 bytes RAM (49.6%); 1,828,117 of 2,097,152 bytes
    application flash (87.2%).
  - Prototype F: 162,368 of 327,680 bytes RAM (49.6%); 1,824,897 of
    2,097,152 bytes application flash (87.0%).
- Each application image was checked for embedded version `0.6.0` and the
  matching firmware identity (`bodaqs_a8`, `bodaqs_v1RC3`, or `bodaqs_4f`).
- Combined images were generated with the established bootloader, partition,
  and application offsets, and SHA-256 hashes were recorded for all 12 files.

Physical smoke testing on each board remains a release acceptance step. The new
700 Hz ADC configuration and the relaxed 70% ADC budget should receive specific
hardware timing and data-quality checks.

## Known Limitations

- A logging configuration may emit no more than 64 primary-stream sensor
  columns.
- The higher A8 ADC rates depend on the active-channel allocation and conversion
  timing; not every multi-channel configuration can run at 700 Hz or 1000 Hz.
- Existing ArduinoJson deprecation warnings remain during compilation. They do
  not prevent the firmware from building or linking.

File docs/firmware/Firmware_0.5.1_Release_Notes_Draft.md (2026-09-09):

# BODAQS Firmware 0.5.1 Release Notes Draft

Status: draft  
Release date: TBD

Firmware `0.5.1` is a maintenance release for BODAQS A8 loggers that improves
RV-3028 real-time clock battery-backup reliability.

## Changes

- The A8 now checks the RV-3028 backup-power configuration on every startup.
- If necessary, the firmware enables Level Switching Mode so the RTC transfers
  to its CR1220 backup battery when main power is removed.
- Trickle charging is kept disabled because the CR1220 is non-rechargeable.
- Existing RTC calibration and unrelated configuration bits are preserved.
- Configuration EEPROM is written only when correction is required, and the
  saved value is read back for verification.
- A configuration repair failure is reported through diagnostic logging but
  does not prevent the logger from starting.

If the RTC has already lost its time, the logger will still require its normal
network or manual time synchronization once. The repaired backup configuration
then applies to subsequent power cycles.

## Compatibility

- No logger configuration changes are required.
- Existing log formats, sensor configuration, metadata, and analysis workflows
  are unchanged.
- The change applies only to A8 hardware using the external RV-3028 RTC;
  Prototype F behavior is unchanged.

## Release Images

The A8 images are in `firmware/dist/0.5.1/`.

| Image | Flash address | SHA-256 |
| --- | --- | --- |
| `bodaqs_a8-0.5.1.bin` | `0x10000` | `DC4E367A2B4DB6ECC79DB8F37613901D77091DACF7A37FB40BD892A3CFD7D4A5` |
| `bodaqs_a8-0.5.1-full.bin` | `0x00000` | `8C4FDD3F582FA1A616540869B9D43BD2D17F9D8D3E3E576054C7DBB78D6BC8D9` |

Use the application image for a normal firmware update. Use the combined full
image for blank, erased, or uncertain devices.

## Validation

- The `bodaqs_s3_mini_n4r2` PlatformIO target built successfully.
- Build usage was 147,540 of 327,680 bytes RAM (45.0%) and 1,738,013 of
  2,097,152 bytes application flash (82.9%).
- The application image was verified to contain firmware version `0.5.1`.
- Physical main-power removal and battery-retention testing remains part of
  release acceptance.

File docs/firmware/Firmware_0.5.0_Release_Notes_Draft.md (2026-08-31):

# BODAQS Firmware 0.5.0 Release Notes Draft

Status: release  
Release date: 2026-08-31

Firmware `0.5.0` is a major capability and reliability release for BODAQS A8
(previously identified as RC3) and Prototype F loggers. Since `0.4.2`, it adds
end-to-end BMI270 IMU logging, assisted sensor orientation, a self-contained web
interface, more consistent I2C sensor health reporting, and substantial
improvements to BDQ and CSV metadata integrity.

## Highlights

- Added production logging support for one Bosch BMI270 six-axis IMU, including
  native 200 Hz FIFO acquisition, timing and loss diagnostics, temperature,
  startup quality observations, and automatic recovery from several classes of
  transient device failure.
- Added an on-device assisted installation-orientation workflow for the BMI270.
  Accepted orientation is stored in logger configuration and emitted as a
  validated `sensor_native -> body_local` rotation matrix without modifying the
  recorded raw measurements.
- Reworked the logger web interface around htmx and embedded all required web
  assets in firmware. The configuration interface no longer depends on files
  being present on the SD card.
- Added mDNS/Bonjour discovery in both station and access-point modes. The OLED
  displays the logger's `.local` address when available.
- Expanded AS5048B and AS5600 string-pot health handling to match the established
  AS5600 angle-sensor lifecycle more closely, including magnetic diagnostics,
  read-quality fields, failure transitions, and deferred recovery.
- Improved BDQ and CSV metadata completeness and write reliability. BDQ files now
  retain richer typed channel schemas and session diagnostics, while CSV JSON
  metadata is streamed safely and packaged only after completeness checks.
- Deprecated direct syn.bike-format CSV output. Existing configurations that
  request it now silently fall back to BDQ.

## BMI270 IMU Support

The new `bmi270_imu_i2c` sensor records native accelerometer and gyroscope data
from the BMI270's hardware FIFO. Its fixed `orientation_200` profile uses:

- 200 Hz accelerometer and gyroscope acquisition;
- accelerometer range of +/-16 g;
- gyroscope range of +/-2000 degrees per second;
- explicit sequence, native sensor-time, sample-age, validity, temperature, and
  status fields; and
- sparse emission into supported logger rates without inventing replacement
  samples when no new native IMU sample is available.

The implementation preserves sensor-native raw data as the authority. Session
metadata and final diagnostics expose FIFO loss, queue pressure, timing quality,
near-rail events, recovery activity, temperature range, and startup stationary
evidence so collection quality can be assessed downstream.

The logger can also guide the user through an installation-orientation capture
while it is not logging. The capture checks stationarity, acceleration magnitude,
gyro stability, clipping, sample count, and roll residual before accepting the
result. An unset orientation does not prevent raw IMU logging.

## Sensor Reliability and Diagnostics

- AS5048B angle sensors now expose optional magnetic status, AGC, magnitude,
  `read_ok`, reused-sample, raw-read-failure, and diagnostic-failure columns.
- AS5600 I2C string-pot sensors now retain AS5600 device-configuration snapshots,
  magnetic health, read-quality fields, bounded runtime transition events, and
  deferred post-session recovery.
- AS5600 angle sensors, AS5600 string pots, and AS5048B sensors now use a more
  consistent session lifecycle and diagnostic vocabulary.
- Repeated read failures are coalesced into bounded transition histories instead
  of producing unbounded diagnostic output.
- Recovery that could overwrite useful session evidence is deferred until after
  log metadata has been finalized.
- GPS session startup now clears stale cached and queued observations, preventing
  a new session from beginning with the previous session's final position.

## Logging, Metadata, and File Integrity

- BDQ v1 now supports explicit `int16`, `uint16`, `int32`, `uint32`, and
  `float32` sensor-channel storage. This preserves the intended signed and
  unsigned representation of IMU and other native fields.
- Embedded BDQ metadata and CSV JSON metadata now carry substantially closer
  sensor provenance, semantic channel descriptions, runtime sensor health,
  acquisition timing, storage timing, and final session-quality information.
- Large JSON metadata is generated through a streaming path, avoiding the fixed
  in-memory document limit that could truncate metadata as diagnostics grew.
- Standard CSV completion uses a temporary archive and validates its metadata
  before publishing the final ZIP. Loose intermediate CSV and JSON files are
  removed after successful packaging.
- CSV row-buffer sizing is based on a safe worst case, and formatting or storage
  failures are counted rather than silently ignored.
- Both standard CSV and BDQ refuse to start if the configuration emits more than
  64 sensor columns.
- BDQ chunk sizing and storage-stall diagnostics have been improved for sustained
  high-rate logging.

## Web and Network Changes

- The configuration UI now uses htmx-driven routes and more reliable full-page
  refreshes after sensor additions, removals, or type changes.
- CSS, htmx, and other required static assets are embedded in flash and served by
  the firmware, so an incomplete or replaced SD card does not break the UI.
- Content-hashed asset URLs prevent browsers from retaining stale interface
  files after a firmware update.
- The logger advertises its service through mDNS/Bonjour in both Wi-Fi station
  and access-point modes. The normal address is:

  ```text
  bodaqs-<logger_id>.local
  ```

## Compatibility and Migration

- Existing standard BODAQS CSV and BDQ configuration selections remain
  supported.
- Direct syn.bike-format CSV generation has been removed from the logger. Legacy
  syn.bike format keys remain accepted but silently select BDQ, with no warning.
  Existing syn.bike files remain importable, and syn.bike output can still be
  generated by the downstream Import Manager workflow.
- Existing BMI270 `location` configuration remains accepted as an alias for the
  newer domain/end semantics. Obsolete `mount_x`, `mount_y`, and `mount_z` keys
  are removed when configuration is next saved; assisted orientation replaces
  them with a full rotation matrix.
- Existing angle-sensor measurement columns retain their order. Optional health
  columns are appended when diagnostics are enabled.
- Newly added or materially reconfigured BMI270 sensors require a logger restart
  before use so the active device and recorded configuration cannot diverge.
- Use current BODAQS import and analysis tooling when consuming logs containing
  BMI270 secondary streams, typed BDQ fields, or the expanded metadata.

## Build and Developer Tooling

- Added a reproducible command-line build workflow for listing targets, checking
  dependencies, building, merging full-flash images, flashing, and cleaning.
- The Bosch BMI270 SensorAPI dependency is pinned to a specific upstream revision
  and constrained to the required sources.
- Added focused native test coverage for BMI270 profile validation, FIFO parsing,
  queue behavior, timing, mounting/orientation validation, web fragments, static
  routes, and HTML utilities.

## Release Images

The release includes application, bootloader, partition, and combined full-flash
images for A8 and Prototype F. Always use files for the same hardware target.

Expected release directory:

```text
firmware/dist/0.5.0/
```

| Image | Purpose | SHA-256 |
| --- | --- | --- |
| `bodaqs_a8-0.5.0.bin` | Application update image | `DF48353BB8EA2B0ED6074B59946C516E8BFD296F134AD6CF8EECB3868F72A36D` |
| `bodaqs_a8-0.5.0-bootloader.bin` | A8 bootloader | `E01A2300DE23C8D601E9F2A37684B5DBC83AE37132D5A8833E23520AFD895F92` |
| `bodaqs_a8-0.5.0-partitions.bin` | A8 partition table | `6A88D59601A83A16A19A08114B59D338324B8DEC267D8B43E5D61AD56EC92102` |
| `bodaqs_a8-0.5.0-full.bin` | Combined full-flash image | `373E1CA0ABDD24298FB0645DB4F75C2B2495DCFAC14209F6B83BF4BCBB0DC908` |
| `bodaqs_4f-0.5.0.bin` | Prototype F application update image | `CD10F64D323D8E7F0AC723C5DAF6E8715A9305C187C4EEB6D142861441C2B217` |
| `bodaqs_4f-0.5.0-bootloader.bin` | Prototype F bootloader | `9BF9AAB34441621D794360CA427CBDDC3D62F38A7950F8790696BB3D7986769F` |
| `bodaqs_4f-0.5.0-partitions.bin` | Prototype F partition table | `6A88D59601A83A16A19A08114B59D338324B8DEC267D8B43E5D61AD56EC92102` |
| `bodaqs_4f-0.5.0-full.bin` | Prototype F combined full-flash image | `ECAC4D8B12CFC4FF5449347B4E330F98CB77A4A2E3BCD97AFBF18CB117AF6DA3` |

## Flash Addresses

For a normal application-only update, use the image matching the hardware:

```text
0x10000  bodaqs_a8-0.5.0.bin
0x10000  bodaqs_4f-0.5.0.bin
```

For a blank, erased, or uncertain logger, either flash the matching combined
image:

```text
0x00000  bodaqs_a8-0.5.0-full.bin
0x00000  bodaqs_4f-0.5.0-full.bin
```

or flash one matching component set:

```text
# A8
0x00000  bodaqs_a8-0.5.0-bootloader.bin
0x08000  bodaqs_a8-0.5.0-partitions.bin
0x10000  bodaqs_a8-0.5.0.bin

# Prototype F
0x00000  bodaqs_4f-0.5.0-bootloader.bin
0x08000  bodaqs_4f-0.5.0-partitions.bin
0x10000  bodaqs_4f-0.5.0.bin
```

## Validation Performed

- The final A8 `bodaqs_s3_mini_n4r2` PlatformIO environment was built cleanly.
- Final build usage is 147,540 of 327,680 bytes RAM (45.0%) and 1,737,037 of
  2,097,152 bytes application flash (82.8%).
- The linked application was checked for embedded firmware name `bodaqs_a8`,
  version `0.5.0`, and board name `BODAQS A8`.
- The final Prototype F `thingplus_s3_usb_cdcserial_bodaqs_4f` PlatformIO
  environment was built cleanly.
- The Prototype F build uses 147,280 of 327,680 bytes RAM (44.9%) and 1,734,833
  of 2,097,152 bytes application flash (82.7%).
- The linked Prototype F application was checked for embedded firmware name
  `bodaqs_4f`, version `0.5.0`, and board name `BODAQS 4F`.
- Combined full-flash images were generated successfully from each target's
  final bootloader, partition table, and application images.
- Focused parser, storage, metadata, IMU, orientation, and host-extraction tests
  were added and exercised during development.
- BMI270 ride-log inspection drove fixes for FIFO sensor-time parsing, shared-bus
  scheduling, sparse-row handling, clock fitting, and recovery from silent
  volatile-state loss.
- SHA-256 hashes were recorded for all eight release images. Hardware smoke
  testing remains a separate release acceptance step.

## Known Limitations

- This release supports at most one active BMI270 IMU per logger.
- The BMI270 physical acquisition profile is fixed at 200 Hz. Supported sparse
  logger output rates are 5, 10, 20, 25, 40, 50, 100, and 200 Hz.
- BMI270 orientation capture must be run while the logger is idle and the bicycle
  and sensor are held stationary in the requested pose.
- BMI270 component self-test is not run automatically; it requires a future
  maintenance-mode workflow because the Bosch self-test reconfigures the device.
- Direct syn.bike-format CSV output is no longer available in firmware.
- A logging configuration may emit no more than 64 sensor columns.
- Existing ArduinoJson deprecation warnings remain during compilation. They do
  not prevent the firmware from building or linking.

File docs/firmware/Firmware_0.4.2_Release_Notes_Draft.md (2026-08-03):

# BODAQS Firmware 0.4.2 Release Notes Draft

Status: draft  
Release date: TBD

Firmware `0.4.2` is a reliability and observability release for current
Prototype F and RC3 loggers. It builds on `0.4.1` with asynchronous sensor
sampling by I2C bus, stronger sensor-runtime diagnostics, and improved
instrumentation of acquisition and logging behavior.

## Highlights

- Rebuilt production firmware for Prototype F and RC3 as `0.4.2`.
- Moved supported sensor acquisition onto separate asynchronous tasks by bus to
  reduce interference between sensor reads and logging.
- Added lifecycle and timing instrumentation for I2C acquisition, sensor-row
  freshness, reused samples, missing samples, and failure streaks.
- Expanded logger metadata and diagnostic output so downstream tools can better
  distinguish acquisition behavior from row-use behavior.

## Compatibility

- Existing `0.4.x` logger configurations remain supported.
- The BDQ archive format remains compatible with the current import and
  preprocessing workflow.
- Standard over-the-air or update flashing normally requires only the
  application image. Use matching bootloader and partition images for blank,
  erased, or uncertain devices.

## Release Images

The release directory is:

```text
firmware/dist/0.4.2/
```

| Target | Application image | SHA-256 |
| --- | --- | --- |
| Prototype F | `bodaqs_4f-0.4.2.bin` | `022D87A28E64636BB72C489FAFD3B7D16290334C7B474585FE110BFB444A3480` |
| RC3 | `bodaqs_v1RC3-0.4.2.bin` | `F32B08B04A1F9E23A6CC3FBFC66230AC6B93A85657B97F53556B53A61A4B2297` |

Matching full-flash images are included:

```text
bodaqs_4f-0.4.2-bootloader.bin
bodaqs_4f-0.4.2-partitions.bin
bodaqs_v1RC3-0.4.2-bootloader.bin
bodaqs_v1RC3-0.4.2-partitions.bin
```

## Flash Addresses

For a normal update:

```text
0x10000  bodaqs_4f-0.4.2.bin
0x10000  bodaqs_v1RC3-0.4.2.bin
```

For a blank, erased, or uncertain device, flash the matching target set:

```text
0x0000   <board>-0.4.2-bootloader.bin
0x8000   <board>-0.4.2-partitions.bin
0x10000  <board>-0.4.2.bin
```

Use `bodaqs_4f` for Prototype F and `bodaqs_v1RC3` for RC3.

## Validation Performed

- Built `thingplus_s3_usb_cdcserial_bodaqs_4f` successfully.
- Built `bodaqs_s3_mini_n4r2` successfully.
- Prototype F build: 74.1% flash, 42.9% RAM.
- RC3 build: 74.2% flash, 42.9% RAM.

## Known Limitations

- This release retains existing ArduinoJson deprecation warnings during the
  build. They do not prevent the generated images from building or flashing.
- Runtime timing instrumentation is intended to improve diagnostics; it does
  not replace normal validation on the target logger and sensor configuration.

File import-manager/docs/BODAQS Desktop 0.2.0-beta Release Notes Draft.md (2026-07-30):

# BODAQS Desktop 0.2.0-beta Release Notes Draft

Status: draft  
Release date: TBD

BODAQS Desktop `0.2.0-beta` is a bundled Windows beta release of the local
BODAQS workflow. It packages the Import Manager, the local Library Service, the
BODAQS Workbench web application, and an optional demonstration library so users
can import, browse, analyze, and inspect BODAQS data without manually running
Python or Node tooling.

This release remains local-first. The installed application can launch the local
Library Service and Workbench, and the Workbench can also be used against a
separately hosted read-only demo service.

## Component Versions

- BODAQS Desktop bundle: `0.2.0-beta`
- BODAQS Import Manager: `0.1.7-beta`
- BODAQS Library Service: `0.1.1-beta`
- BODAQS Workbench: `0.1.1-beta`

## Installer

Installer filename:

```text
bodaqs-desktop-setup-0.2.0-beta.exe
```

SHA-256:

```text
D47F6605771393667C364F6C0A3986A3CAE82AC5BD4357B7AF698E3B76411410
```

## Headline Changes Since 0.1.6-alpha

- The Windows package is now branded as BODAQS Desktop, reflecting that it
  bundles the Import Manager, Library Service, Workbench, and demo assets.
- The installer can optionally install a demonstration library, with an
  overwrite option for refreshing existing demo data.
- The Import Manager can launch and stop the bundled BODAQS Workbench and local
  Library Service from more prominent controls.
- First-run setup now offers a simpler default workspace path, default library,
  and default local archive source path.
- The Library Service includes read-only hosted-demo support, catalog caching,
  session and study-set refresh support, and expanded APIs used by Workbench
  analysis views.
- The Workbench Library Browser has improved table layout, filtering, column
  resizing, session rename, bulk delete, note copy/paste, signal preview, GPS
  preview, altitude preview, and clearer table controls.
- Simple Suspension Analysis now supports histogram and cumulative-frequency
  views, charted summary-statistic glyphs, normalized or millimetre displacement,
  time-window controls, bookmarks, signal-inspector entry points, and improved
  caching/performance.
- Signal Inspector now supports single-chart and multi-chart modes, synchronized
  window selection, bookmarks, event details with metrics, GPS and altitude
  context, video attachment and sync controls, and local video playback.
- Track Analysis and Lap Timing adds a GPS map workflow for track editing,
  scratch tracks, 3D track altitude profiles, segment labels, untimed segments,
  lap timing comparison, track/session search, and video-assisted trackpoint
  placement.

## Known Limitations

- The Windows installer is not yet code-signed; Windows may show unknown
  publisher or SmartScreen warnings.
- The Workbench is still a beta web UI and some analysis workflows remain
  actively evolving.
- Hosted-demo mode is read-only; write operations such as saving tracks, study
  sets, notes, bookmarks, and video attachments are disabled there.
- Video attachments currently reference local files and are intended for local
  Workbench use, not the hosted demo.
- The installer remains large because it includes Python, scientific analysis
  dependencies, the Library Service, the Workbench, and optional demo assets.

## Suggested Validation Checklist

- Install `bodaqs-desktop-setup-0.2.0-beta.exe` on a clean Windows user account.
- Confirm the optional demo library appears when selected during install.
- Confirm BODAQS Desktop launches the Import Manager.
- Confirm `Open BODAQS Workbench` starts the local Library Service and opens the
  browser UI.
- Confirm the Library Browser lists demo sessions without manually running the
  service.
- Open Simple Suspension Analysis for a single session and for a study set.
- Open Signal Inspector from the Library Browser and from analysis time-window
  controls.
- Open Track Analysis and Lap Timing and confirm demo tracks, GPS paths, altitude
  profile, and lap timing panels render.
- Stop the Workbench from the Import Manager and confirm the browser reports the
  local API as offline.

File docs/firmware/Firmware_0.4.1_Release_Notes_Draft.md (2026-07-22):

# BODAQS Firmware 0.4.1 Release Notes Draft

Status: draft  
Release date: TBD

Firmware `0.4.1` is a small maintenance release following `0.4.0`, focused on
RTC behavior for RC3 loggers with a fitted backup battery.

## Highlights

- Fixed RC3 external RTC startup behavior.
- Rebuilt Proto-F and RC3 firmware images as `0.4.1`.

## Fixes

- RC3 loggers now trust a valid RV3028 external RTC after reset instead of
  discarding the copied system time and forcing a network time sync.
- Automatic Wi-Fi/NTP time recovery is still used when the external RTC is not
  available, cannot be read, or reports PORF/power-loss state.

## Compatibility

No configuration changes are required.

Existing `0.4.0` logger configs should continue to load unchanged. This release
does not change the OLED, sensor, logging, GPS, ADC, web UI, or file format
behavior introduced in `0.4.0`.

## Builds

Release binaries:

```text
bodaqs_4f-0.4.1.bin
bodaqs_v1RC3-0.4.1.bin
```

Matching bootloader and partition images are also available for full flashing
onto blank or erased devices.

## Flash Addresses

The local staging directory for the generated release binaries is:

```text
firmware/dist/0.4.1/
```

For a normal firmware update on a device that already has a compatible
bootloader and partition table, flash only the application binary:

```text
0x10000  bodaqs_4f-0.4.1.bin
0x10000  bodaqs_v1RC3-0.4.1.bin
```

For blank, erased, or uncertain devices, flash the full image set for the
target board:

```text
0x0000   <board>-0.4.1-bootloader.bin
0x8000   <board>-0.4.1-partitions.bin
0x10000  <board>-0.4.1.bin
```

Use the matching board prefix throughout: `bodaqs_4f` for Proto-F loggers, or
`bodaqs_v1RC3` for RC3 loggers.

## Notes

This release is mainly useful for RC3 hardware with the RV3028 backup RTC
battery installed. Proto-F users can stay on `0.4.0`, but `0.4.1` is a harmless
baseline update.

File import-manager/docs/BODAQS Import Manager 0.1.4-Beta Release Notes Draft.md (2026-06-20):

# BODAQS Import Manager 0.1.4-Beta Release Notes Draft

BODAQS Import Manager `0.1.4-Beta` is a Windows beta update focused on shared
library configuration, more reliable logger imports, and smoother source
management.

## Changes Since 0.1.2-alpha

- Added a managed workspace layout with libraries stored under a `libraries`
  directory and reusable configuration stored at the BODAQS data-root level.
- Bike profiles can now be shared across sources and libraries that use the
  same data root, rather than being tied to one import source.
- Preprocess profiles can now be shared and assigned to sources from the source
  context menu.
- Event schemas can be kept in the shared `event_schemas` directory and
  referenced from shared preprocess profiles.
- Import batches detected in the same source pass can now be processed into the
  same run, instead of creating one run per session.
- `Import Now` supports an optional run-description override, and source
  settings support default or base-name-plus-index session descriptions.
- Large import batches now update the manager output during detection and
  processing, rather than waiting until the whole batch is complete.
- Logger CSV loading now repairs rare out-of-order primary timestamp rows before
  preprocessing, fixing failures caused by non-monotonic `time_s` values.
- Logger GPS imports now tolerate initial invalid GPS rows and preserve valid
  GPS points in the `gps_logger` stream.
- Activity detection now prefers GPS velocity when available, then falls back to
  wheel-motion signals, while keeping legacy preprocess profiles usable.
- data.syn.bike exports now use logger GPS data as well as FIT-style GPS column
  names.
- data.syn.bike exports now write zero-filled travel columns when one end of the
  bike has no available travel signal, so the visualizer can still open the
  export.
- Rotary-sensor workflows now support degree-based calibration materialization
  and rear wheel lookup-table inputs in either sensor millimetres or sensor
  degrees.
- Duplicating a bike profile no longer automatically assigns the duplicate to
  the current source.
- Source and library removal now distinguishes between removing an entry from
  the manager and completely deleting its files after confirmation.
- Complete source/library deletion now handles read-only Windows directories
  more reliably and only updates the manager configuration after the filesystem
  deletion succeeds.
- Fixed source table updates so `Type` and `Status` remain separate columns.
- Fixed watch-mode startup behavior.
- Improved Wi-Fi logger upload/discovery state reporting, including logger
  AP-mode workflows.
- Added the packaged application version to the Import Manager window title.

## Compatibility Notes

- Existing Import Manager configuration files should continue to load.
- Existing source-local bike and preprocess profile files remain valid when a
  source still references them.
- Existing libraries that live directly under the data root remain discoverable;
  newly created managed libraries are placed under `libraries`.
- New shared bike profiles, preprocess profiles, and event schemas are stored at
  the data-root level.
- Complete source/library deletion is destructive once confirmed and should be
  tested first on disposable data.

## Installer

The Windows installer output is:

```text
bodaqs-import-manager-setup-0.1.4-Beta.exe
```

The installer remains GUI-only; standalone command-line utilities are not
installed as separate user-facing commands.

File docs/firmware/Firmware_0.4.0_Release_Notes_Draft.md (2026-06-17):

# BODAQS Firmware 0.4.0 Release Notes Draft

Status: draft  
Release date: TBD

Firmware `0.4.0` extends the logger's external sensor support and tightens the
runtime split between logging, upload, and configuration workflows.

## Highlights

- Added UART GPS support for SparkFun DAN-F10N/u-blox modules.
- Added asynchronous sensor caching so lower-rate sensors can feed the
  synchronous log row without blocking the logging loop.
- Added AS5048B and AS5600 rotary angle sensor support over I2C.
- Added rotary angle `direction` calibration while continuing to emit legacy
  `invert` metadata for downstream compatibility.
- Added AS5600 rotary angle support as a practical fallback angle sensor.
- Moved I2C bus speed ownership into board profiles.
- Updated Proto-F and RC3 UART profile mapping to GPIO43 TX and GPIO44 RX.
- Improved upload/config mode ownership so Wi-Fi, GPS, and web routes are not
  unnecessarily kept alive during logging.
- Reduced dynamic web UI pressure by simplifying generated sensor/config pages.

## Compatibility

Existing configs should continue to load. AS5048B and AS5600 angle sensors may
now persist:

```text
sensorN.zero_count=<count>
sensorN.direction=counts_increase_positive
```

or:

```text
sensorN.direction=counts_decrease_positive
```

For rotary angle sensors, `direction` is the firmware-owned polarity field.
Generated metadata still includes `invert` for compatibility with existing
downstream consumers. `invert=true` corresponds to
`counts_decrease_positive`.

## Calibration

The on-device `ZERO` calibration for rotary angle sensors is now two-step:

1. Capture the installed zero position.
2. Move the measured linkage in the intended positive direction and capture
   the second point.

The second capture is used only to determine polarity. It does not create a
full-range calibration; rotary angle output remains based on the sensor's native
counts-per-revolution scale.

## GPS Logging

GPS data is sampled asynchronously and cached. Log rows use the most recent
valid GPS sample according to the sensor's emission policy, with validity and
semantic details recorded in metadata for downstream preprocessing.

## Known Notes

- Rotary angle sensors are single-turn sensors in this release.
- Compact binary logging is still being hardened alongside the new asynchronous
  sensor model.

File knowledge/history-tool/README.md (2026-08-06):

# BODAQS history tool

This private, local-first tool converts the initial BODAQS ChatGPT ZIP and Codex rollout-session archives into a reviewable engineering-knowledge corpus.

It deliberately does not build a general-purpose event database or copy raw conversation data into the repository.

## Installation

From this directory, create or use a Python 3.11+ virtual environment and install the base tool:

```powershell
python -m pip install -e .
```

Install OpenAI support only if you intend to use the opt-in external drafting path:

```powershell
python -m pip install -e ".[openai]"
```

Copy `config/project.example.yaml` to `config/project.local.yaml` and replace every placeholder. The local file is ignored by Git.

The reviewed corpus should initially be configured beneath `C:\Users\benco\OneDrive\BODAQS-private`, not in this repository. Keep raw archives and `private_work` outside the repository as well.

## Commands

```powershell
python -m bodaqs_history inventory --config config/project.local.yaml
python -m bodaqs_history ingest --config config/project.local.yaml
python -m bodaqs_history candidates --config config/project.local.yaml
python -m bodaqs_history draft --config config/project.local.yaml --limit 10
python -m bodaqs_history verify --config config/project.local.yaml
python -m bodaqs_history generate --config config/project.local.yaml
python -m bodaqs_history validate --config config/project.local.yaml
```

`all` runs the same sequence. Without `--allow-external`, drafting creates cautious local candidate records and makes no network request.

## Interactive Codex workflow

The recommended no-API-cost workflow is to run `candidates`, deliberately select one candidate, then prepare a bounded redacted packet for interactive review:

```powershell
python -m bodaqs_history prepare --config config/project.local.yaml --candidate CAND-...
```

The packet is stored privately in `private_work/packets/`. Review it in Codex, generate a cautious Markdown record, verify important code/Git claims, and promote the reviewed record into the private corpus. Do not use `--allow-external` for this workflow.

To use OpenAI, set `llm.external_api_allowed: true`, set `llm.model` (and optional `llm.reasoning_effort`), set `OPENAI_API_KEY` in the process environment, and explicitly add `--allow-external` to `draft` or `all`. `llm.max_input_characters` is a hard cap on redacted text included in each request:

```powershell
$env:OPENAI_API_KEY = "..."
python -m bodaqs_history draft --config config/project.local.yaml --allow-external --limit 10
```

No API key is read or required for inventory, ingest, candidate discovery, validation, or local drafting.

## Initial source support

The first implementation supports the source formats found in the supplied archive:

* a ChatGPT ZIP containing chunked `conversations-*.json` exports;
* Codex `sessions/**/rollout-*.jsonl` archives from the workstation and laptop.

It intentionally ignores Codex caches, SQLite databases, credentials, configuration, plugins, and other non-session files.

## Privacy and review

Raw normalised messages, candidates, redacted LLM bundles, manifests, reports, and drafts remain in `private_work`.

The tool applies basic local redaction immediately before an optional external request. It masks common API-token shapes, email addresses, bearer tokens, and Windows user paths, but it cannot guarantee removal of every sensitive value. Review material before enabling an external call.

`generate` publishes copies to the configured private corpus under `drafts/`; it never overwrites a manually reviewed record. Promote and amend records manually until a more formal review workflow is needed.

## Incremental updates

Run `inventory` after adding new archives. Source hashes and normalised source/session IDs make exact duplicates visible. `private_work/manifest/processing-manifest.json` retains the last run and a bounded run history. The initial implementation keeps drafts separate, but deliberately defers automatic near-duplicate merging and automatic amendment of reviewed records.

## Known limitations

* Semantic candidate classification is not yet separate from OpenAI drafting; deterministic keyword candidates are always available.
* Git verification currently validates explicitly supplied code/Git references in drafts. It does not infer commit-to-topic relationships.
* The current `chronological-overview.md` is an intentional review scaffold, not an auto-generated narrative.

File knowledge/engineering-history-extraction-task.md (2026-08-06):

# Task: Build the BODAQS Engineering Knowledge Corpus

## Objective

Build a local, repeatable knowledge-harvesting tool that turns historical BODAQS conversations and relevant Git repositories into a curated engineering knowledge corpus that is useful to both people and future agents.

The initial run is expected to be substantial because it covers roughly one year of project history. Future runs will normally occur about every three months and should process only new or changed material.

The task ends when the first iteration has produced a reviewed, useful corpus and the incremental workflow is documented. This is not a requirement to build a general-purpose evidence-management platform.

## What the corpus must capture

The corpus should make the following easy to find and understand:

* current engineering decisions and their rationale;
* resolved technical problems and tested fixes;
* important experiments and their results or limitations;
* significant changes of direction or superseded approaches;
* open technical questions;
* uncertainties that need a human decision or further testing;
* concise historical context where it changes how current code, hardware, or analysis should be interpreted.

Do not attempt to turn every message, suggestion, or code edit into a formal record. Prefer a small number of accurate, useful topic records over an exhaustive event database.

## Implementation location and naming

Implement the tool and its documentation under:

```text
bodaqs/knowledge/
  history-tool/
  engineering-history/
```

Use `bodaqs_history` as the Python package and command-line name if a package is needed.

`engineering-history/` is the human- and agent-facing corpus. `history-tool/` contains the implementation, configuration examples, and its documentation. Adjust the exact internal layout only where the existing repository conventions require it.

The initial reviewed corpus is private. Keep generated records under the configured private output location (currently beneath `C:\Users\benco\OneDrive\BODAQS-private`) rather than in the repository. The repository location may contain the tool, documentation, templates, and examples, but not derived private conversation material.

## Working principles

### Source material is read-only

Do not alter, rename, move, or delete source archives or repositories. Treat all source directories as read-only.

### Accuracy over apparent completeness

Conversation history records discussion, proposals, hypotheses, and reported results. It does not necessarily describe the current implementation.

Use evidence in this order where it is available:

1. current code and approved documentation;
2. reproducible test logs or data;
3. Git commits and inspected diffs;
4. explicit project-owner confirmation in conversation;
5. assistant recommendations;
6. inference.

An assistant recommendation alone is never an adopted project decision. Mark incomplete or conflicting conclusions as uncertain rather than forcing an answer.

### Lightweight source references

Each knowledge record must retain enough information for a reviewer to revisit important claims, without requiring forensic-grade source locations for every sentence.

For material claims, retain where available:

* source archive and conversation/session identifier;
* approximate date or date range;
* relevant Git commit and file path;
* a concise evidence note or short quotation for contested or high-impact claims.

Use durable internal references such as:

```text
[Codex:workstation:session-456]
[ChatGPT:main:conversation-123]
[Git:firmware:abcdef1:src/StorageManager.cpp]
```

### Privacy by separation

Keep original archives and unredacted parsed content outside the version-controlled corpus. Generated working data containing raw conversations must be stored in a Git-ignored private directory.

Only reviewed, BODAQS-specific, appropriately redacted knowledge records belong in the project corpus. Do not copy raw archives into the repository.

Before content is sent to an external model, remove or mask obvious secrets, credentials, personal contact details, unrelated personal discussion, customer/employer confidential information, and user-specific private paths. Automated redaction reduces risk but cannot guarantee detection of every sensitive value.

API credentials must be supplied through environment variables, not configuration files committed to Git.

### External LLM use is opt-in

External API use is disabled by default. The tool must require an explicit configuration setting or command-line flag before sending any content externally.

When no local model is configured and external API use is disabled, the tool should still perform inventory, parsing, exact de-duplication, and export of candidate material for manual review. Semantic relevance filtering and drafting may then be deferred rather than silently sending material to an API.

When an LLM is used, retain the model and prompt-version metadata in the run manifest. Ask it to distinguish explicit statements from inference and to allow `unknown`; do not accept unsupported dates, versions, numerical results, or adoption claims.

## Inputs and initial inventory

The available archives and repositories may not match a fixed directory structure. Do not hard-code source paths, archive names, or formats.

Start with a read-only inventory of the supplied inputs. Determine and report the actual ChatGPT and Codex export formats, including unsupported variants, before finalising parser support. Support only formats found in the initial sources plus clearly documented variants that can be tested safely.

Provide a configuration file that identifies:

* source directories and archive labels;
* source type, when known;
* relevant Git repositories;
* project terms and exclusion terms;
* private working directory;
* reviewed corpus output directory;
* optional date range for incremental runs;
* whether an external LLM API is permitted;
* local or external model settings;
* optional redaction patterns.

An example layout is:

```text
sources/                         # supplied externally; never copied into the repo
C:\Users\benco\OneDrive\BODAQS-private\
  engineering-history-work/       # parsed/raw/redacted working data
  engineering-history/            # reviewed private corpus
bodaqs/knowledge/
  history-tool/                   # implementation, templates, and documentation
```

## Required corpus layout

Produce Markdown-first records with YAML front matter in the configured private corpus. A separate YAML, JSON, or CSV version of every record is not required.

```text
<private corpus>/engineering-history/
  README.md
  index.md
  chronological-overview.md
  open-questions.md
  uncertainties.md
  decisions/
  problems/
  experiments/
  topics/
```

Use the smallest set of directories that remains clear. A record can be organised by its primary purpose; avoid duplicate files merely to satisfy multiple categories.

Each record should use front matter similar to:

```yaml
---
title: SD writes and sampling timing
kind: problem-resolution # decision | problem-resolution | experiment | topic | open-question
topics:
  - firmware.storage
  - firmware.sampling
status: resolved # draft | current | resolved | open | uncertain | superseded
applies_to:
  - ESP32-S3 logger
date_range: 2025-11 to 2026-01
confidence: high # high | medium | low
source_refs:
  - Codex:workstation:session-456
  - Git:firmware:abcdef1:src/StorageManager.cpp
code_refs:
  - src/StorageManager.cpp
review_status: draft # draft | reviewed | needs-more-evidence
---
```

The record body should plainly state, where applicable:

* the context or problem;
* observations and supporting evidence;
* options or hypotheses considered;
* the decision, experiment, or resolution;
* implementation and verification status;
* limitations, applicability, and remaining uncertainty.

Use concise source notes or quotations for high-impact, disputed, or numerical claims. Do not expose unrelated raw conversation content.

## Initial workflow

Implement a small, inspectable command-line workflow. Commands may be combined where that improves clarity; do not create separate passes merely for formality.

Suggested commands:

```bash
python -m bodaqs_history inventory --config config/project.yaml
python -m bodaqs_history ingest --config config/project.yaml
python -m bodaqs_history candidates --config config/project.yaml
python -m bodaqs_history draft --config config/project.yaml
python -m bodaqs_history verify --config config/project.yaml
python -m bodaqs_history generate --config config/project.yaml
python -m bodaqs_history all --config config/project.yaml
```

The first iteration should proceed as follows:

1. Inventory the supplied archives and repositories, identify actual formats, hash files, and report anything unsupported or unreadable.
2. Parse supported sources into a private, common representation that preserves conversation/session identity, message order, dates when available, and source paths. Do not silently discard malformed material.
3. Identify likely BODAQS material using project terms and, when configured, semantic classification. Retain enough surrounding context for interpretation. Place borderline material in a candidate queue for human review.
4. Group the selected material into practical topic/date candidates. This may be approximate; it is not a requirement to perfectly segment every episode.
5. Draft a limited number of high-value knowledge records spanning several areas, such as firmware storage and sampling, calibration, IMU selection or processing, analysis methodology, and Garmin/timestamp integration.
6. For important claims, inspect current code and relevant Git diffs or test artifacts. Git inspection is targeted verification, not a requirement to build a complete Git-history database.
7. Generate the Markdown corpus, index, chronological overview, open-questions list, and uncertainties list.
8. Support a human review step before records are described as current project knowledge.

## Candidate selection and factual checks

Prefer topics with one or more of the following:

* an implementation that affects current hardware, firmware, or analysis;
* repeated troubleshooting or recurring confusion;
* a decision with meaningful alternatives or constraints;
* numerical results that influence a design limit or default;
* a later reversal, conflict, or unknown that could mislead future work.

For each drafted conclusion, distinguish these dimensions when relevant:

```text
proposal / decision / implementation / verification
```

For example, a favourable discussion may support a proposal, a merged diff may support implementation, and a test log may support verification. Do not combine those claims without evidence.

Where code, Git history, and discussion disagree, explain the disagreement in the record or `uncertainties.md` and request human review.

## Incremental updates

The initial run is the primary effort. Subsequent runs should normally be conducted roughly quarterly.

Track processed input hashes, source/session identifiers, and the most recent source date in a Git-ignored run manifest. On a later run:

* identify new or changed archives and conversations;
* process only new or changed material where possible;
* identify existing records that may need amendment;
* create draft additions rather than overwrite reviewed content;
* produce a short run summary listing proposed additions, amendments, and newly discovered uncertainties.

Exact duplicate detection is required. Near-duplicate detection, automated cross-archive clustering, and automatic record merging are explicitly deferred unless the initial material demonstrates a practical need.

## Validation and tests

Validation should be proportionate and should fail clearly on structural errors. Check at least:

* input sources are not modified;
* expected Markdown front matter is valid;
* source references resolve to known imported sources where retained;
* record paths and titles are unique;
* Git references point to known repositories/commits when repositories are available;
* reviewed corpus output does not contain secrets detected by the configured redaction checks.

Use small synthetic fixtures to test the parsers for the actual discovered ChatGPT and Codex formats, malformed input, timestamp handling, exact duplicate detection, redaction, and incremental-run tracking. Do not include private conversation content in tests.

## Documentation

Provide a concise README for the tool covering:

* purpose and limits of the corpus;
* supported source formats discovered during the initial inventory;
* configuration and commands;
* private working-data and redaction model;
* external-API opt-in behaviour;
* review workflow;
* how to run an incremental update;
* known limitations and unsupported formats.

Clearly state that generated drafts are not approved engineering truth until reviewed.

## First-iteration deliverables

The first iteration must produce:

1. a source inventory and supported-format report;
2. a private normalised/candidate dataset sufficient to reproduce the drafting process;
3. a candidate queue for borderline or uncertain BODAQS material;
4. a reviewed initial Markdown knowledge corpus spanning the priority technical areas;
5. an index, chronological overview, open-questions list, and uncertainties list;
6. targeted code/Git checks for the highest-impact current claims;
7. a documented incremental workflow and run manifest;
8. a README with commands, privacy limitations, and known unsupported inputs.

## Completion criteria

The task is complete when:

* the supplied sources have been inventoried and their supported/unsupported formats reported;
* relevant BODAQS discussions can be identified and used to draft records with lightweight source references;
* the corpus captures major decisions, resolved problems, important experiments, open questions, and uncertainties;
* key current claims have been checked against code, Git, or test evidence where practical;
* generated records have been reviewed before being presented as current project knowledge;
* the sources remain unchanged;
* a future archive addition can be incorporated incrementally without reprocessing all known material; and
* the README documents operation, privacy limitations, and the next review/update workflow.

Before concluding the task, provide a concise implementation summary, the final directory tree, commands used, tests and results, unsupported formats or limitations, privacy/redaction limitations, highest-priority review items, and recommended next steps.

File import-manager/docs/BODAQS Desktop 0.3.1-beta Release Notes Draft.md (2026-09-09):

# BODAQS Desktop 0.3.1-beta Release Notes

BODAQS Desktop `0.3.1-beta` is a macOS maintenance release that fixes context
menus in the Import Manager.

## Fixed

- Right-click menus now open correctly on the Import Manager's Sources and
  Libraries tables on macOS.
- Control-click is also supported as the standard macOS context-menu gesture.

## Component Versions

- BODAQS Desktop bundle: `0.3.1-beta`
- BODAQS Import Manager: `0.1.10-beta`
- BODAQS Library Service: `0.2.0-beta`
- BODAQS Workbench: `0.2.0-beta`

## Downloads

This maintenance release is distributed for macOS only:

- `BODAQS-Import-Manager-0.3.1-beta-macos-arm64.dmg` — Apple silicon Macs
- `BODAQS-Import-Manager-0.3.1-beta-macos-x64.dmg` — Intel Macs

Windows and Linux packages are not included in this release. Users on those
platforms can continue using BODAQS Desktop `0.3.0-beta`.

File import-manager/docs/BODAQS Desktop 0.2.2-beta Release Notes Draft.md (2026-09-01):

# BODAQS Desktop 0.2.2-beta Release Notes Draft

Status: draft  
Release date: TBD

BODAQS Desktop `0.2.2-beta` improves the local import, library-management, and
analysis workflow. It brings a more responsive Workbench, clearer adequacy and
signal-inspection tools, better Wi-Fi source handling, and automatic retention
management for processed import archives.

## Component Versions

- BODAQS Desktop bundle: `0.2.2-beta`
- BODAQS Import Manager: `0.1.8-beta`
- BODAQS Library Service: `0.1.2-beta`
- BODAQS Workbench: `0.1.2-beta`

The installed package records these values in `component_versions.json`. They
are also available from **Help → About BODAQS Desktop** in the Import Manager.

## Highlights

### Import Manager

- Wi-Fi sources now scan their local inbox as well as the logger when importing
  is enabled. This supports re-processing a run with the same source settings.
- Processed `done` and `failed` archives can now be retained automatically for
  a configurable number of days, defaulting to 30 days. A **retain forever**
  option remains available.
- Archive cleanup runs after each completed scan and also sweeps existing
  archives after upgrading. New archive retention uses the time the run entered
  `done` or `failed`; existing archives use their modified time.
- The Provision page exposes the retention setting and applies it through
  **Apply app settings**.

### BODAQS Workbench

- The Workbench now uses a clearer, more consistent visual language and heading
  structure, including rationalised context glyphs.
- The Study Set Builder automatically expands when sessions or tracks are added.
- Session selection is more flexible: Ctrl/Cmd-click and Shift-click work from
  any data column. A deliberate second click on the Session name starts a
  rename, while a quick double-click still opens analysis.
- Session renaming and multi-session note paste now update optimistically,
  making library changes feel immediate while retaining error recovery.
- Signal previews can show data modestly below zero rather than pinning the
  lower axis at zero.
- Signal Inspector now shows full signal names on hover, defaults to primary
  analysis signals, orders signals by sensor and analysis quantity, and keeps
  its controls more compact.
- Track Analysis and Lap Timing now shows the first scratch-track point on the
  initial map click, provides a visible armed state for adding scratch points,
  and improves its drawer layout and controls.
- Adequacy assessment now displays a compact per-session matrix of ticks and
  crosses beside each criterion. Required failures are red; recommended and
  optional failures are orange.

### Library Service

- Adequacy responses now expose per-session criterion results, supporting the
  Workbench’s criterion matrix.
- Description updates avoid unnecessary rereads of manifests while preserving
  the same API response shape.

## Downloads and Verification

| Platform | Package | Release status |
| --- | --- | --- |
| Windows x64 | `bodaqs-desktop-setup-0.2.2-beta.exe` | Unsigned; SHA-256 to be published after the release build. |
| macOS Apple Silicon | `BODAQS-Import-Manager-0.2.2-beta-macos-arm64.dmg` | Developer ID signed, notarized, and stapled. Download the `macos-arm64-0.2.2-beta` build artifact. |
| macOS Intel | `BODAQS-Import-Manager-0.2.2-beta-macos-x64.dmg` | Developer ID signed, notarized, and stapled. Download the `macos-x64-0.2.2-beta` build artifact. |
| Linux x64 | `BODAQS-Import-Manager-0.2.2-beta-linux-x64.tar.gz` | Keylessly signed with Sigstore. The `linux-x64-0.2.2-beta` artifact also includes its `.sigstore.json` verification bundle. |

The macOS package is a drag-to-Applications DMG. The Linux package is a
portable archive; extract it and run `bodaqs-import-manager` from the expanded
directory.

## Known Limitations

- **The Windows installer is not yet code-signed.** Windows may show an
  unknown-publisher or SmartScreen warning during installation. Verify the
  published SHA-256 before proceeding.
- macOS and Linux builds are produced from the release tag. The macOS signing
  and notarization workflow requires its configured Apple credentials; the
  Linux archive is accompanied by a Sigstore verification bundle.
- This remains a beta release; Workbench analysis workflows and the Import
  Manager configuration experience are still evolving.
- The desktop package is large because it bundles Python, scientific-analysis
  dependencies, the local Library Service, and the Workbench.

## Suggested Validation Checklist

- Install on a clean Windows user account and confirm the expected unsigned
  installer warning is understood.
- Confirm **Help → About BODAQS Desktop** shows the Desktop and three component
  versions listed above.
- Import from a Wi-Fi source with an inbox present, and confirm both the inbox
  and logger source are considered.
- Set a short processed-archive retention period in Provision, apply settings,
  and confirm completed scans clean eligible `done` and `failed` archives.
- In the Workbench, multi-select sessions from several columns; verify rename
  and quick double-click analysis behaviour from the Session column.
- Open Signal Inspector, Adequacy, and Track Analysis and Lap Timing for a
  representative local library.

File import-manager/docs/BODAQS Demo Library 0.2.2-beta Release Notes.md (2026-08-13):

# BODAQS Demo Library 0.2.2-beta Release Notes

Release date: TBD

The BODAQS Demo Library provides a ready-to-browse local library for exploring
BODAQS Desktop and the Workbench without importing data from a logger.

## Download

- Archive: `BODAQS-Demo-Library-0.2.2-beta.zip`
- Archive manifest: `BODAQS-Demo-Library-0.2.2-beta.manifest.json`
- Archive SHA-256:

  ```text
  570cb4b6887710a046b4d85077ba03b084712a7cdcb9686fdf97b46c58a81012
  ```

The manifest records a SHA-256 checksum for the archive and for every packaged
file.

## Install the Demo Library

Unpack the archive into the **BODAQS workspace root**—the folder containing
your `libraries` and `sources` folders. Do not unpack it into the `libraries`
folder itself.

For example, if the Import Manager is configured with:

```text
Workspace root: C:\Users\your-name\BODAQS
Libraries root: C:\Users\your-name\BODAQS\libraries
```

extract the archive to:

```text
C:\Users\your-name\BODAQS\
```

After extraction, the workspace should contain this shape:

```text
BODAQS\
  libraries\
    bodaqs-demo\
      library_definition.json
      runs\
      ...
  study_sets\
  tracks\
  bookmarks\
  session_filters\
  demo_manifest.json
```

The archive does not include an extra enclosing folder. If your extraction tool
offers to create a folder named after the zip automatically, open that folder
and move its contents into the workspace root instead.

Then open the Import Manager and either:

- select the existing workspace in the first-run setup; or
- use **Provision** to select the workspace's existing Libraries root, then
  refresh/synchronise the managed workspace.

`BODAQS Demo Library` should then appear in the Import Manager and Workbench.

## Existing Demo Library

Do not extract this archive over an existing `libraries\bodaqs-demo` folder.
Either keep the existing demo library, or first move/delete that folder and the
companion demo items you want to replace (`study_sets`, `tracks`, `bookmarks`,
and `session_filters`). This avoids a mixed-version library.

## Contents and Deliberate Omissions

This archive includes the library’s processed sessions, tracks, study sets,
bookmarks, session filters, recipes, and `demo_manifest.json`.

To keep the download practical, it deliberately excludes:

- video files;
- video attachment records; and
- generated `.bodaqs_library_api_cache` data.

The Library Service rebuilds its cache when the demo is opened. Video workflows
will not be available from this archive.

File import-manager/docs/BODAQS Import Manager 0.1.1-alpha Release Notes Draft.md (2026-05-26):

# BODAQS Import Manager 0.1.1-alpha Release Notes Draft

Status: draft  
Release date: TBD

BODAQS Import Manager `0.1.1-alpha` is a Windows alpha build of the local
BODAQS import workflow. It focuses on the windowed manager experience: creating
libraries and sources, watching for completed logger sessions, importing local
archive and Wi-Fi logger sources, running the BODAQS preprocessing pipeline, and
writing processed library artifacts without requiring users to run Python.

This release remains local-first. It does not require cloud services, a phone
bridge, BLE, or a database server.

## Headline Changes Since 0.1.0-dev

- The Windows installer now ships the GUI Import Manager only; the separate CLI
  utility is no longer included in the GUI installer package.
- The installer version and output filename are now `0.1.1-alpha`.
- The Manager screen has been simplified around context menus rather than rows
  of action buttons.
- Libraries can be renamed from the Manager screen without changing their
  library IDs or artifact directories.
- Sources can be renamed from the Manager screen without changing their source
  IDs, source roots, or target libraries.
- Source table wording now uses `Target Library` to make the library
  relationship clearer.
- Source context menus now include validation, bike editing, target-library
  changes, details, rename, and removal actions.
- Wi-Fi source provisioning now treats fixed logger addresses as an explicit
  opt-in, so discovered IP addresses are not automatically remembered.
- Existing Wi-Fi source connection settings can be viewed and edited from the
  source context menu.
- Library context menus now include rename and details actions.
- The manager now prevents multiple running instances for the same app
  configuration.
- Bike-profile and note-template editing has been expanded with builder-style
  UI support, including LUT editing and draft note profile generation.

## Installer And Packaging

The Windows installer output is named:

```text
bodaqs-import-manager-setup-0.1.1-alpha.exe
```

The installer includes:

- the windowed BODAQS Import Manager app
- bundled default import assets
- Windows icon assets
- Start Menu integration
- optional desktop shortcut support

The installer no longer includes the standalone `bodaqs-import.exe` CLI utility.
This reduces the package and installed size by avoiding a second bundled Python
runtime and scientific dependency stack. Users who need the CLI can still build
or receive it as a separate artifact.

Installed-mode app configuration is stored in per-user app data rather than in
the installation directory.

The installer is currently unsigned. Users may see Windows "unknown publisher"
or SmartScreen warnings until code signing is added and reputation builds.

## Manager UI

The Import Manager window provides two main workflows:

- `Provision`: create libraries and sources.
- `Manager`: operate existing libraries and sources.

Manager table changes in this release:

- The library table shows `Library Name` and `Syn Export`.
- Library details are available from the library row context menu.
- The source table shows enabled state, source name, source type, status,
  target library, bike name, and attach-note state.
- Source details are available from the source row context menu.
- Source validation has moved from the main button row into the source context
  menu.
- Wi-Fi source actions appear only for Wi-Fi sources.
- Wi-Fi source settings can be edited after provisioning, including logger ID,
  fixed-address mode, fixed address, cleanup policy, and timeouts.

Rename behavior is display-name-only. Renaming a library or source does not
change IDs, paths, import history, or processed artifact locations.

Only one manager instance can run at a time for a given app configuration. If a
second copy is launched, it exits with an already-running message rather than
starting another watcher or tray icon.

## Source And Profile Builders

This alpha includes the current bike-profile and note-template builder work:

- bike profile creation/editing from a guided form
- display-name-driven profile IDs
- front suspension vertical-wheel transform generation from steering head angle
- rear shock-to-wheel LUT editing
- source-local note profile/template editing
- note field defaults
- custom note fields when enabled by the field catalog
- create-from workflows for copying profiles/templates from existing sources

The generated JSON remains compatible with the existing import pipeline and
library artifact contracts.

## Import Capabilities

This release keeps the existing Import Manager capabilities:

- local archive-folder sources for completed logger ZIP files
- Wi-Fi logger sources using the BODAQS Wi-Fi Upload API v1
- mDNS discovery where the local network allows it
- optional fixed logger addresses for networks where mDNS is unavailable or
  unreliable
- multi-source and multi-library management
- background watch mode with Windows tray integration
- start-at-login support
- optional FIT enrichment when enabled by the preprocess profile
- optional draft session-note creation on import
- optional data.syn.bike export generation per library

Wi-Fi logger sources are intended to pair with BODAQS firmware `0.3.0` or later.
Upload mode is required before Wi-Fi session transfer.

## Compatibility Notes

- This is an alpha release, not a polished public stable release.
- Existing app configuration should continue to load.
- Running multiple manager instances with the same app configuration is now
  blocked to avoid duplicate watchers and competing config edits.
- Removing the CLI from the GUI installer does not change the manager app's
  import behavior.
- Existing source and library IDs remain stable when display names are renamed.
- Existing source folders and library folders are not deleted by rename or
  remove-from-manager actions.
- Existing Wi-Fi sources with remembered addresses continue to work, and those
  addresses can now be cleared or updated from the manager.
- macOS packaging is planned separately.

## Known Limitations

- The installer is not yet code-signed.
- The package remains relatively large because the manager includes Python,
  pandas, NumPy, SciPy, parquet support, Tk, tray support, and network discovery
  dependencies.
- The GUI installer no longer installs a command-line import utility.
- mDNS discovery may be blocked by firewall, VPN, guest Wi-Fi, AP isolation, or
  router multicast settings.
- FIT enrichment is best-effort and does not block otherwise successful import.
- data.syn.bike helper files still require manual settings entry in
  data.syn.bike.

## Suggested Validation Checklist

- Install `bodaqs-import-manager-setup-0.1.1-alpha.exe` on a clean Windows user
  account.
- Confirm the Start Menu shortcut launches BODAQS Import Manager.
- Confirm no separate CLI folder or `bodaqs-import.exe` is installed by the GUI
  installer.
- Create a library and local archive source.
- Rename the library and confirm only its display name changes.
- Rename the source and confirm only its display name changes.
- Validate a source from the source context menu.
- Change a source target library from the source context menu.
- Open source and library details dialogs from their context menus.
- Provision a Wi-Fi source from discovery with fixed address off and confirm no
  address is written to the source config.
- Edit a Wi-Fi source, enable fixed address, verify the logger, save, then clear
  fixed address again.
- Edit a bike profile and note profile from the source workflow.
- Launch the manager a second time and confirm it reports that the manager is
  already running rather than opening a duplicate instance.
- Import a completed logger ZIP and confirm artifacts appear in the target
  library.
- If testing Wi-Fi, use firmware `0.3.0` or later, put the logger in upload
  mode, and confirm discovery/import behavior.

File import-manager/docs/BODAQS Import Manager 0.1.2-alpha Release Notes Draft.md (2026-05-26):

# BODAQS Import Manager 0.1.2-alpha Release Notes Draft

Status: draft  
Release date: TBD

BODAQS Import Manager `0.1.2-alpha` is a small Windows alpha update focused on
Wi-Fi source portability and safer desktop app startup behavior.

## Changes Since 0.1.1-alpha

- Wi-Fi source provisioning now treats fixed logger IP addresses as an explicit
  opt-in.
- Discovered logger addresses are no longer automatically saved unless fixed
  address mode is selected.
- Existing Wi-Fi source settings can be viewed and edited from the source
  context menu.
- Wi-Fi actions can fall back to mDNS discovery when a remembered fixed address
  is stale or unreachable.
- The manager now prevents multiple running instances for the same app
  configuration, avoiding duplicate watchers, duplicate tray icons, and
  competing config edits.

## Installer

The Windows installer output is:

```text
bodaqs-import-manager-setup-0.1.2-alpha.exe
```

The installer remains GUI-only; the standalone CLI utility is not included.

## Validation Suggestions

- Install over `0.1.1-alpha` and confirm existing libraries and sources load.
- Provision a Wi-Fi source from discovery with fixed address mode off and
  confirm no fixed address is saved.
- Edit a Wi-Fi source, enable fixed address mode, save, then clear it again.
- Launch the manager a second time and confirm it reports that the manager is
  already running rather than opening a duplicate instance.

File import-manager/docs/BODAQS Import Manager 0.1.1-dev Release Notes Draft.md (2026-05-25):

# BODAQS Import Manager 0.1.1-dev Release Notes Draft

Status: draft  
Release date: TBD

BODAQS Import Manager `0.1.1-dev` is the current packaged desktop build of the
local BODAQS import workflow. It is designed to let users create local
libraries, configure import sources, watch for completed logger sessions, run
the existing BODAQS preprocessing pipeline, and write processed artifacts
without running Python or opening notebooks.

This is a Windows-first development release. It remains local-first: it does
not require cloud services, a phone bridge, BLE, or a database server.

## Highlights

- New Windows installer for BODAQS Import Manager.
- New windowed manager UI for creating and managing libraries and import
  sources.
- Local archive-folder import sources for completed logger ZIP files.
- Wi-Fi logger import sources using the BODAQS Wi-Fi Upload API v1.
- mDNS discovery for station-mode BODAQS loggers where the local network
  allows it.
- Multi-source and multi-library management from one app.
- Background watch mode with Windows tray integration.
- Start-at-login support for the installed manager.
- Per-source bike, settings, FIT, and note-template folders.
- Optional FIT enrichment when enabled by the preprocess profile.
- Optional draft session-note creation on import.
- Optional data.syn.bike export generation per library.
- Branded Windows app, tray, taskbar, and installer icons.

## Compatibility

### Operating System

This build targets Windows desktop/laptop use.

macOS packaging is planned separately. Linux packaging is not part of this
release.

### Firmware

Wi-Fi logger sources are intended to pair with BODAQS firmware `0.3.0` or later,
using the Wi-Fi Upload API v1.

For Wi-Fi import, the logger must:

- be reachable on the local network
- expose `/api/v1/` upload routes
- have completed ZIP-backed sessions
- be in explicit upload mode before session transfer

Local archive-folder sources can import compatible logger ZIP files without a
network connection.

### Session Archive Contract

The import manager expects one completed logger session per ZIP archive.

Each archive should contain a same-stem CSV and JSON pair:

```text
<session_stem>.CSV
<session_stem>.json
```

The files inside the archive do not need fixed names, but the CSV and JSON must
have the same stem.

## Installer And Packaging

The Windows installer output is named:

```text
bodaqs-import-manager-setup-0.1.1-dev.exe
```

The installer includes:

- the windowed Import Manager app
- the CLI import/watch tool as a support utility
- bundled default import assets
- Windows icon assets
- Start Menu integration
- optional desktop shortcut support

Installed-mode app configuration is stored in per-user app data rather than in
the installation directory. This keeps user state separate from installed
program files and makes upgrades/uninstalls safer.

The installer is currently unsigned. Users may see Windows "unknown publisher"
or SmartScreen warnings until code signing is added and reputation builds.

## Manager UI

The Import Manager window provides two main workflows:

- `Provision`: create libraries and sources.
- `Manager`: operate existing libraries and sources.

The manager can:

- create additional libraries under a common libraries root
- create additional sources under a common sources root
- target multiple sources at one central library
- remove a source from the managed configuration without deleting any source or
  library files
- enable/disable sources directly from the source table
- toggle draft-note creation directly from the source table
- toggle data.syn.bike exports directly from the library table
- run one-shot imports
- start and stop background watching
- open source, library, and logger-related locations from the UI

## Source Types

### Local Archive Folder

Local archive sources watch a source `inbox/` directory for completed ZIP files.

On successful import:

- processed artifacts are written to the selected library
- the source archive is moved to `done/`

On failed import:

- the source archive is moved to `failed/`
- the manager records the failure in import state and UI status

The source folder contains:

```text
<source>/
  import_source.json
  bike/
  settings/
  notes/
  fit/
  inbox/
  done/
  failed/
  staging/
```

### Wi-Fi Logger

Wi-Fi sources can download completed session archives directly from a BODAQS
logger over the local network.

The workflow is:

1. Confirm logger identity with `/api/v1/device`.
2. Confirm upload readiness with `/api/v1/status`.
3. Discover completed sessions with `/api/v1/sessions`.
4. Download an archive to a local temporary `.part` file.
5. Validate the downloaded ZIP before import.
6. Import through the same local archive pipeline.
7. Acknowledge successful import to the logger.
8. Optionally request logger-side cleanup.

Upload mode is always required for Wi-Fi session transfer. If the logger is
reachable but not in upload mode, the manager treats that as a normal waiting
state rather than an import failure.

Remote cleanup policies are:

- keep remote files
- move acknowledged sessions to the logger's uploaded area
- delete acknowledged sessions

The default should remain conservative until the user trusts the workflow.

## Logger Discovery

Station-mode logger discovery uses mDNS service:

```text
_bodaqs-logger._tcp
```

The logger ID remains the stable identity. Discovered addresses are treated as
reachability hints and are verified with `/api/v1/device` before importing.

Manual logger addresses remain supported for:

- AP-mode workflows
- networks that block mDNS
- VPN/firewall/guest-network cases
- troubleshooting

## Libraries

Each library contains processed BODAQS artifacts and library metadata:

```text
<library>/
  runs/
  library/
  syn/
  library_definition.json
```

Multiple libraries can live under one libraries root. This supports workflows
such as one library per rider, logger, bike, or test program.

## Processing Pipeline

Imports reuse the existing BODAQS preprocessing and artifact-writing contract.

The manager:

- loads the source bike profile from `bike/`
- loads preprocess settings from `settings/`
- loads an event schema from `settings/` when available
- runs preprocessing
- runs event detection and metrics when an event schema is available
- writes processed run/session artifacts to the target library

The active source folders use an "exactly one valid file" rule:

- `bike/` should contain exactly one valid bike profile
- `settings/` should contain exactly one valid preprocess profile
- `settings/` may contain exactly one valid event schema

## FIT Enrichment

Each source has a `fit/` directory.

When FIT enrichment is enabled in the preprocess profile:

- FIT files are read from the source `fit/` directory
- files should be fully copied before import
- FIT files are not moved or deleted by the manager
- the largest-overlap matching FIT file is preferred
- parse failures or ambiguity do not block the import
- failed FIT enrichment is recorded as a quality-control note/warning

## Draft Session Notes

Each source can optionally attach a draft session note to incoming sessions.

The source owns:

- a session-note template
- a bike setup preset
- an `Attach Note` setting

Notes created during import are marked as draft so users can distinguish
automatically generated setup notes from notes intentionally created or edited
later.

The import process records note/template/setup provenance in the run manifest
and copies needed note-template information into the target library so notes
remain interpretable if the source folder changes later.

## data.syn.bike Exports

Each library can opt in to data.syn.bike export generation.

When enabled before import, new sessions produce files under:

```text
<library>/syn/
```

Outputs include:

- headerless data.syn.bike CSV export files
- per-session helper text files with manual data.syn.bike settings
- an export manifest

The helper text includes values derived from the bike profile, including travel
and normalization-related settings. Raw data can be scaled from the logger's
calibrated raw range to a full ADC-count range for data.syn.bike compatibility.

Old sessions are not backfilled automatically when the library setting is
enabled later.

## Background Operation

The manager can run in watch mode and continue operating from the Windows tray.

Supported behavior:

- closing the window hides to tray when tray support is active
- tray menu can reopen the manager or quit the app
- start-at-login can launch the manager in installed mode
- startup launches can start watch mode automatically
- offline Wi-Fi sources report waiting/error status without modal error storms

## User-Visible Behavior Changes From Notebook/CLI Workflows

- Users no longer need to edit JSON files for normal source/library setup.
- App-level configuration is managed automatically.
- Source bike/settings/note assets are copied into each source folder.
- A source can be removed from the manager without deleting files.
- Wi-Fi downloads are normalized into the same archive-import path as local
  files.
- Event detection and metrics run automatically when an event schema is
  available.
- Logger timezone is not requested in normal setup; session timing comes from
  log metadata.

## Known Limitations

- This is a `dev` release, not a polished public stable release.
- Windows packaging is implemented first; macOS and Linux packages are not yet
  available.
- The Windows installer is not yet code-signed.
- The installer bundle is relatively large because it includes Python runtime
  and scientific dependencies.
- Wi-Fi imports require the logger to be in upload mode.
- Automatic PC switching into logger AP mode is not implemented.
- mDNS discovery depends on local network multicast behavior and may be blocked
  by firewalls, VPNs, guest Wi-Fi, AP isolation, or router configuration.
- Manual logger address entry is still needed for AP mode and troublesome
  networks.
- Old imported sessions are not automatically backfilled for data.syn.bike
  exports or draft notes.
- FIT enrichment is best-effort and intentionally does not block import.
- Remote cleanup should be used conservatively until tested with real logger
  data.

## Suggested Validation Checklist

Installer checks:

- Install BODAQS Import Manager on a clean Windows user account.
- Confirm the Start Menu shortcut launches the manager.
- Confirm the app title and taskbar icon use BODAQS Import Manager branding.
- Confirm the app config is created under per-user app data in installed mode.
- Confirm uninstall behavior when the manager is closed.

Local archive checks:

- Create a library and local archive source.
- Replace the seeded bike profile with a real target-bike profile.
- Copy a completed session ZIP into `inbox/`.
- Run `Import Now`.
- Confirm the archive moves to `done/`.
- Confirm processed artifacts appear in the target library `runs/` directory.

Wi-Fi logger checks:

- Use firmware `0.3.0` or later.
- Put the logger and computer on the same local network.
- Put the logger into upload mode.
- Discover the logger with mDNS, or enter a manual address.
- Use `Check Logger`.
- Import a completed session.
- Confirm the manager acknowledges the import to the logger.
- Test cleanup mode only after confirming the local library artifacts.

Optional-output checks:

- Enable `Syn Export` on a library before import.
- Confirm data.syn.bike CSV/helper files appear under `syn/`.
- Enable `Attach Note` on a source before import.
- Confirm a draft session note appears in the target library.
- Add a fully copied FIT file to the source `fit/` directory and confirm FIT
  enrichment succeeds or records a non-blocking warning.

Failure checks:

- Try importing a malformed ZIP and confirm it moves to `failed/`.
- Try Wi-Fi import when the logger is reachable but not in upload mode.
- Try Wi-Fi discovery on a network where mDNS is blocked and confirm manual
  address entry still works.
- Interrupt a Wi-Fi download and confirm partial `.part` files are not imported.
- Remove a source from the manager and confirm source/library files remain on
  disk.

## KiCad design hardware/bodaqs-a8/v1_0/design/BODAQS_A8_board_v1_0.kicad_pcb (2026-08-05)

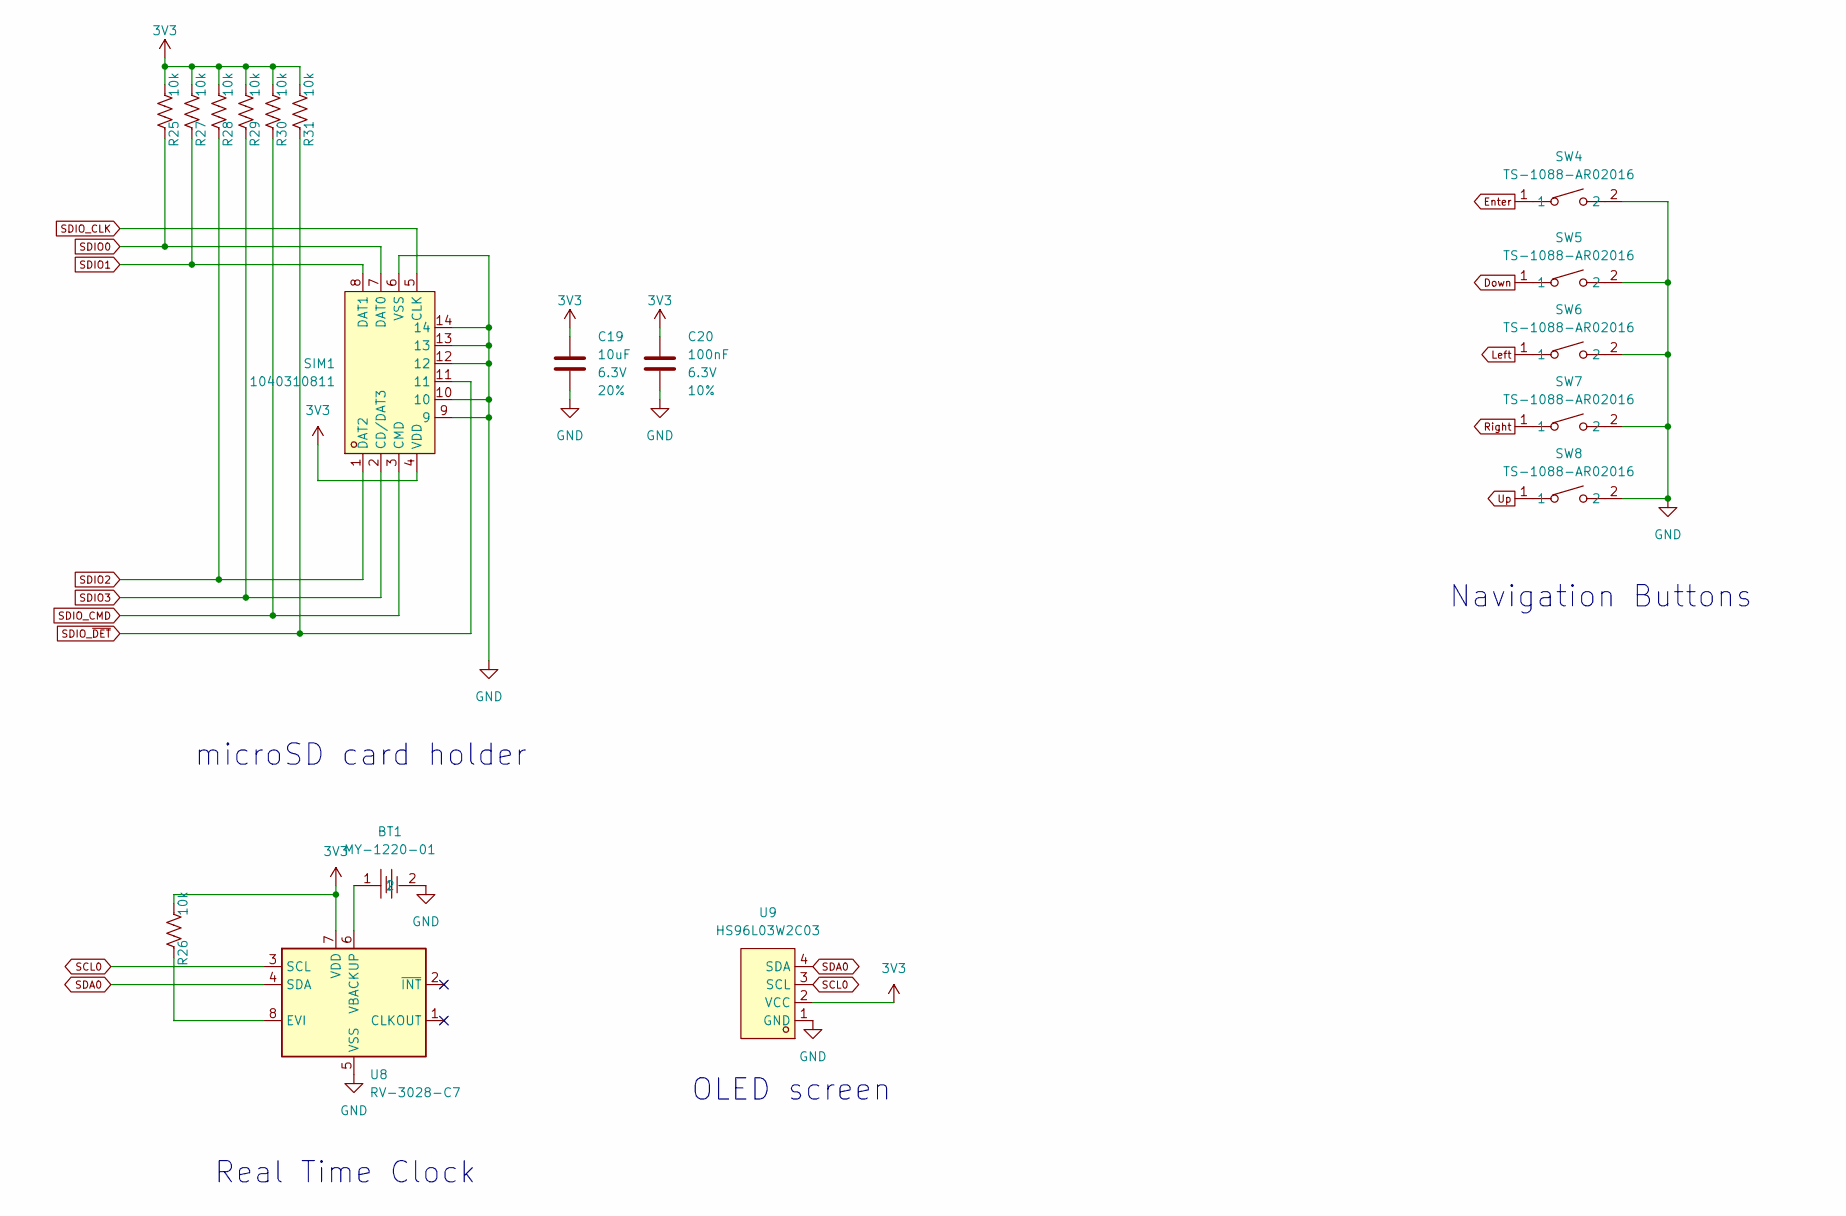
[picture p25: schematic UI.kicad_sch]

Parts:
BT1: MY-1220-01; BAT-TH_MY-1220-01; MPN MY-1220-01; LCSC Part C964817
C19: 10uF; C_0805_2012Metric; Voltage 6.3V; Tolerance 20%; Manufacturer_Part_Number CL21A106KAYNNNE; LCSC Part C15850
C20: 100nF; C_0402_1005Metric; Voltage 6.3V; Tolerance 10%; Manufacturer_Part_Number CL05B104KO5NNNC; LCSC Part C1525
R25, R26, R27, R28, R29, R30, R31: 10k; R_0402_1005Metric; Manufacturer_Part_Number 0402WGF1002TCE; LCSC Part C25744
SIM1: 1040310811; SIM-SMD_8P-1040310811; MPN 1040310811; LCSC Part C585350
SW4, SW5, SW6, SW7, SW8: TS-1088-AR02016; SW-SMD_L3.9-W3.0-P4.45; MPN TS-1088-AR02016; LCSC Part C720477
U8: RV-3028-C7; MicroCrystal_C7_SON-8_1.5x3.2mm_P0.9mm; Manufacturer_Part_Number RV-3028-C7-32.768kHz-1ppm-TA-QC; LCSC Part C3019759
U9: HS96L03W2C03; OLED-TH_L27.8-W27.2-P2.54_C9900033791; MPN HS96L03W2C03; LCSC Part C5248080

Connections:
3V3: C19.1, C20.2, R25.1, R26.1, R27.1, R28.1, R29.1, R30.1, R31.1, SIM1.4 (VDD), U8.7 (VDD), U9.2 (VCC); also elsewhere on the board
Down: SW5.1; also elsewhere on the board
Enter: SW4.1; also elsewhere on the board
GND: BT1.2, C19.2, C20.1, SIM1.6 (VSS), SIM1.9, SIM1.10, SIM1.12, SIM1.13, SIM1.14, SW4.2, SW5.2, SW6.2, SW7.2, SW8.2, U8.5 (VSS), U9.1 (GND); also elsewhere on the board
Left: SW6.1; also elsewhere on the board
unnamed: R26.2, U8.8 (EVI)
unnamed: BT1.1, U8.6 (VBACKUP)
Right: SW7.1; also elsewhere on the board
SCL0: U8.3 (SCL), U9.3 (SCL); also elsewhere on the board
SDA0: U8.4 (SDA), U9.4 (SDA); also elsewhere on the board
SDIO0: R25.2, SIM1.7 (DAT0); also elsewhere on the board
SDIO1: R27.2, SIM1.8 (DAT1); also elsewhere on the board
SDIO2: R28.2, SIM1.1 (DAT2); also elsewhere on the board
SDIO3: R29.2, SIM1.2 (CD/DAT3); also elsewhere on the board
SDIO_CLK: SIM1.5 (CLK); also elsewhere on the board
SDIO_CMD: R30.2, SIM1.3 (CMD); also elsewhere on the board
SDIO_~DET: R31.2, SIM1.11; also elsewhere on the board
Up: SW8.1; also elsewhere on the board

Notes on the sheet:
OLED screen
Real Time Clock
Navigation Buttons
microSD card holder

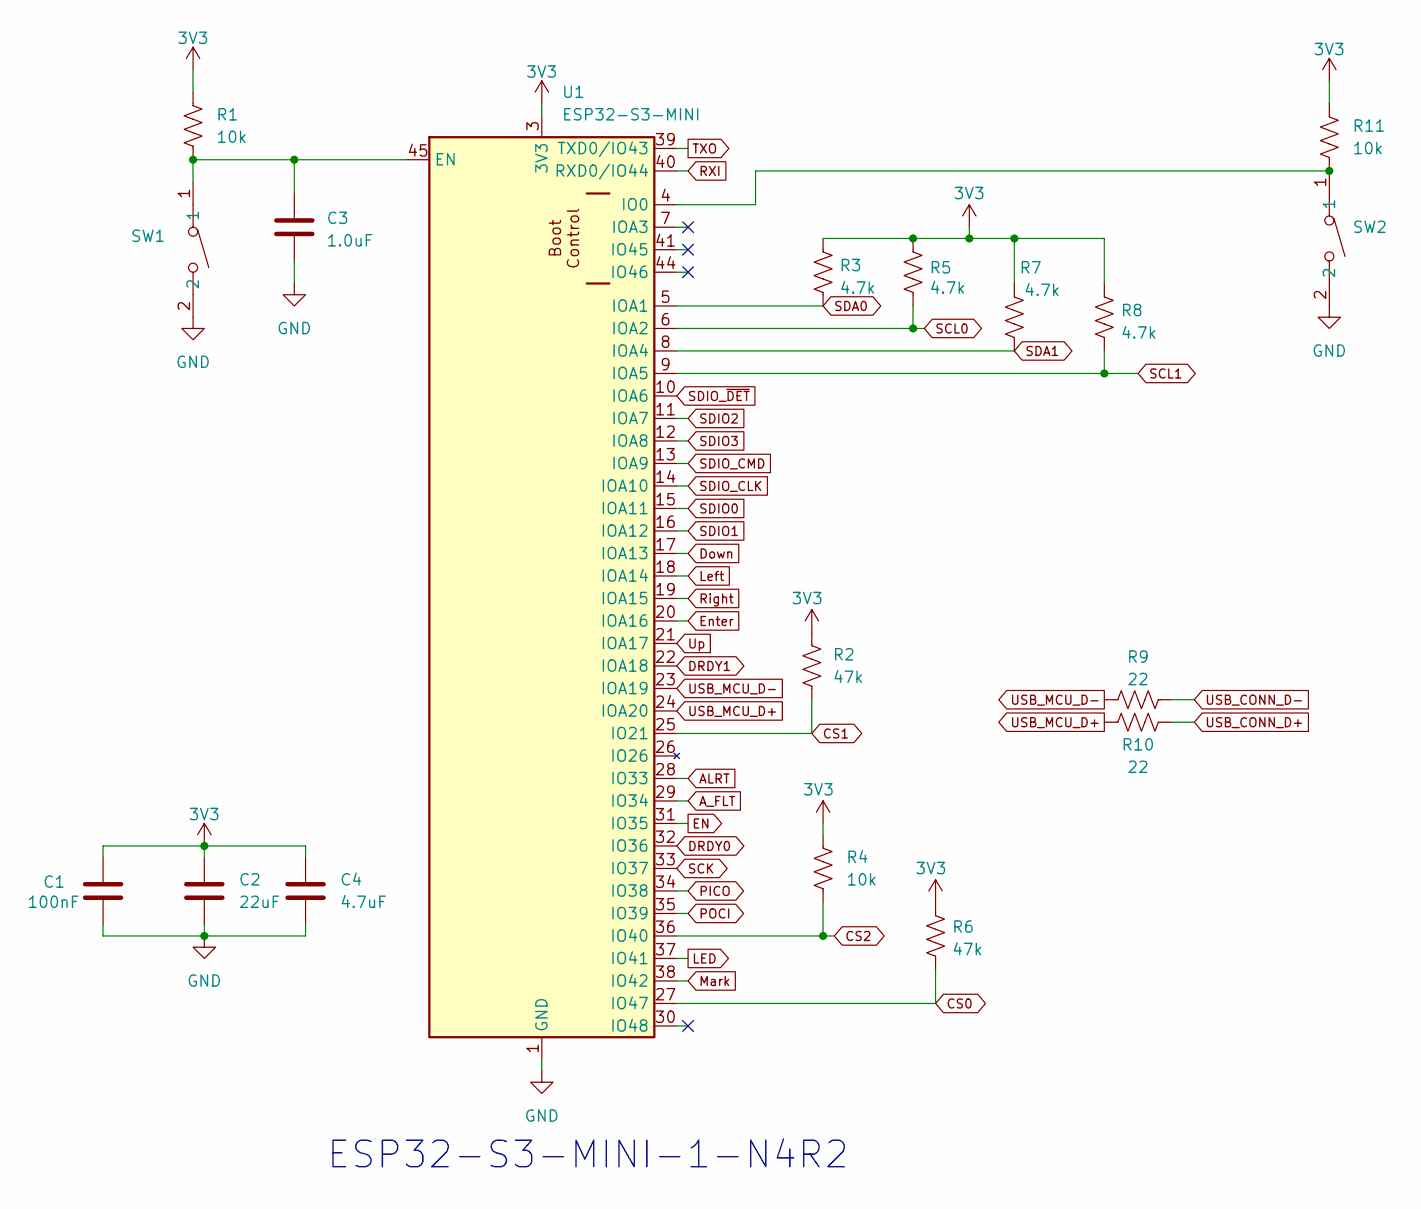
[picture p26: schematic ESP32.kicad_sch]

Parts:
C1: 100nF; C_0402_1005Metric; Manufacturer_Part_Number CL05B104KO5NNNC; LCSC Part C1525
C2: 22uF; C_0603_1608Metric; Voltage 6.3V; Tolerance 20%; Manufacturer_Part_Number GRM188R61A226ME15D; LCSC Part C84419
C3: 1.0uF; C_0402_1005Metric; Voltage 16V; Tolerance 10%; Manufacturer_Part_Number CL05A105KA5NQNC; LCSC Part C52923
C4: 4.7uF; C_0402_1005Metric; Voltage 6.3V; Tolerance 20%; Manufacturer_Part_Number CL05A475MP5NRNC; LCSC Part C23733
R1, R4, R11: 10k; R_0402_1005Metric; Manufacturer_Part_Number 0402WGF1002TCE; LCSC Part C25744
R2, R6: 47k; R_0402_1005Metric; Manufacturer_Part_Number 0402WGF4702TCE; LCSC Part C25792
R3, R5, R7, R8: 4.7k; R_0402_1005Metric; Manufacturer_Part_Number 0402WGF4701TCE; LCSC Part C25900
R9, R10: 22; R_0402_1005Metric; Manufacturer_Part_Number 0402WGF220JTCE; LCSC Part C25092
SW1, SW2: TS-1088-AR02016; SW-SMD_L3.9-W3.0-P4.45; MPN TS-1088-AR02016; LCSC Part C720477
U1: ESP32-S3-MINI; ESP32-S2-MINI-1; Manufacturer_Part_Number ESP32-S3-MINI-1-N4R2; LCSC Part C3013941

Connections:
3V3: C1.1, C2.2, C4.1, R1.1, R2.1, R3.2, R4.1, R5.2, R6.1, R7.2, R8.2, R11.1, U1.3 (3V3); also elsewhere on the board
LED: U1.37 (IO41); also elsewhere on the board
POCI: U1.35 (IO39); also elsewhere on the board
TXO: U1.39 (TXD0/IO43); also elsewhere on the board
ALRT: U1.28 (IO33); also elsewhere on the board
A_FLT: U1.29 (IO34); also elsewhere on the board
CS0: R6.2, U1.27 (IO47); also elsewhere on the board
CS1: R2.2, U1.25 (IO21); also elsewhere on the board
CS2: R4.2, U1.36 (IO40); also elsewhere on the board
DRDY0: U1.32 (IO36); also elsewhere on the board
DRDY1: U1.22 (IOA18); also elsewhere on the board
Down: U1.17 (IOA13); also elsewhere on the board
EN: U1.31 (IO35); also elsewhere on the board
Enter: U1.20 (IOA16); also elsewhere on the board
GND: C1.2, C2.1, C3.2, C4.2, SW1.2, SW2.2, U1.1 (GND), U1.2 (GND), U1.42 (GND), U1.43 (GND), U1.46 (GND), U1.47 (GND), U1.48 (GND), U1.49 (GND), U1.50 (GND), U1.51 (GND), U1.52 (GND), U1.53 (GND), U1.54 (GND), U1.55 (GND), U1.56 (GND), U1.57 (GND), U1.58 (GND), U1.59 (GND), U1.60 (GND), U1.61 (GND), U1.62 (GND), U1.63 (GND), U1.64 (GND), U1.65 (GND); also elsewhere on the board
Left: U1.18 (IOA14); also elsewhere on the board
Mark: U1.38 (IO42); also elsewhere on the board
unnamed: C3.1, R1.2, SW1.1, U1.45 (EN)
unnamed: R11.2, SW2.1, U1.4 (IO0)
PICO: U1.34 (IO38); also elsewhere on the board
RXI: U1.40 (RXD0/IO44); also elsewhere on the board
Right: U1.19 (IOA15); also elsewhere on the board
SCK: U1.33 (IO37); also elsewhere on the board
SCL0: R5.1, U1.6 (IOA2); also elsewhere on the board
SCL1: R8.1, U1.9 (IOA5); also elsewhere on the board
SDA0: R3.1, U1.5 (IOA1); also elsewhere on the board
SDA1: R7.1, U1.8 (IOA4); also elsewhere on the board
SDIO0: U1.15 (IOA11); also elsewhere on the board
SDIO1: U1.16 (IOA12); also elsewhere on the board
SDIO2: U1.11 (IOA7); also elsewhere on the board
SDIO3: U1.12 (IOA8); also elsewhere on the board
SDIO_CLK: U1.14 (IOA10); also elsewhere on the board
SDIO_CMD: U1.13 (IOA9); also elsewhere on the board
SDIO_~DET: U1.10 (IOA6); also elsewhere on the board
USB_CONN_D+: R10.2; also elsewhere on the board
USB_CONN_D-: R9.2; also elsewhere on the board
USB_MCU_D+: R10.1, U1.24 (IOA20)
USB_MCU_D-: R9.1, U1.23 (IOA19)
Up: U1.21 (IOA17); also elsewhere on the board

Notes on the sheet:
ESP32-S3-MINI-1-N4R2

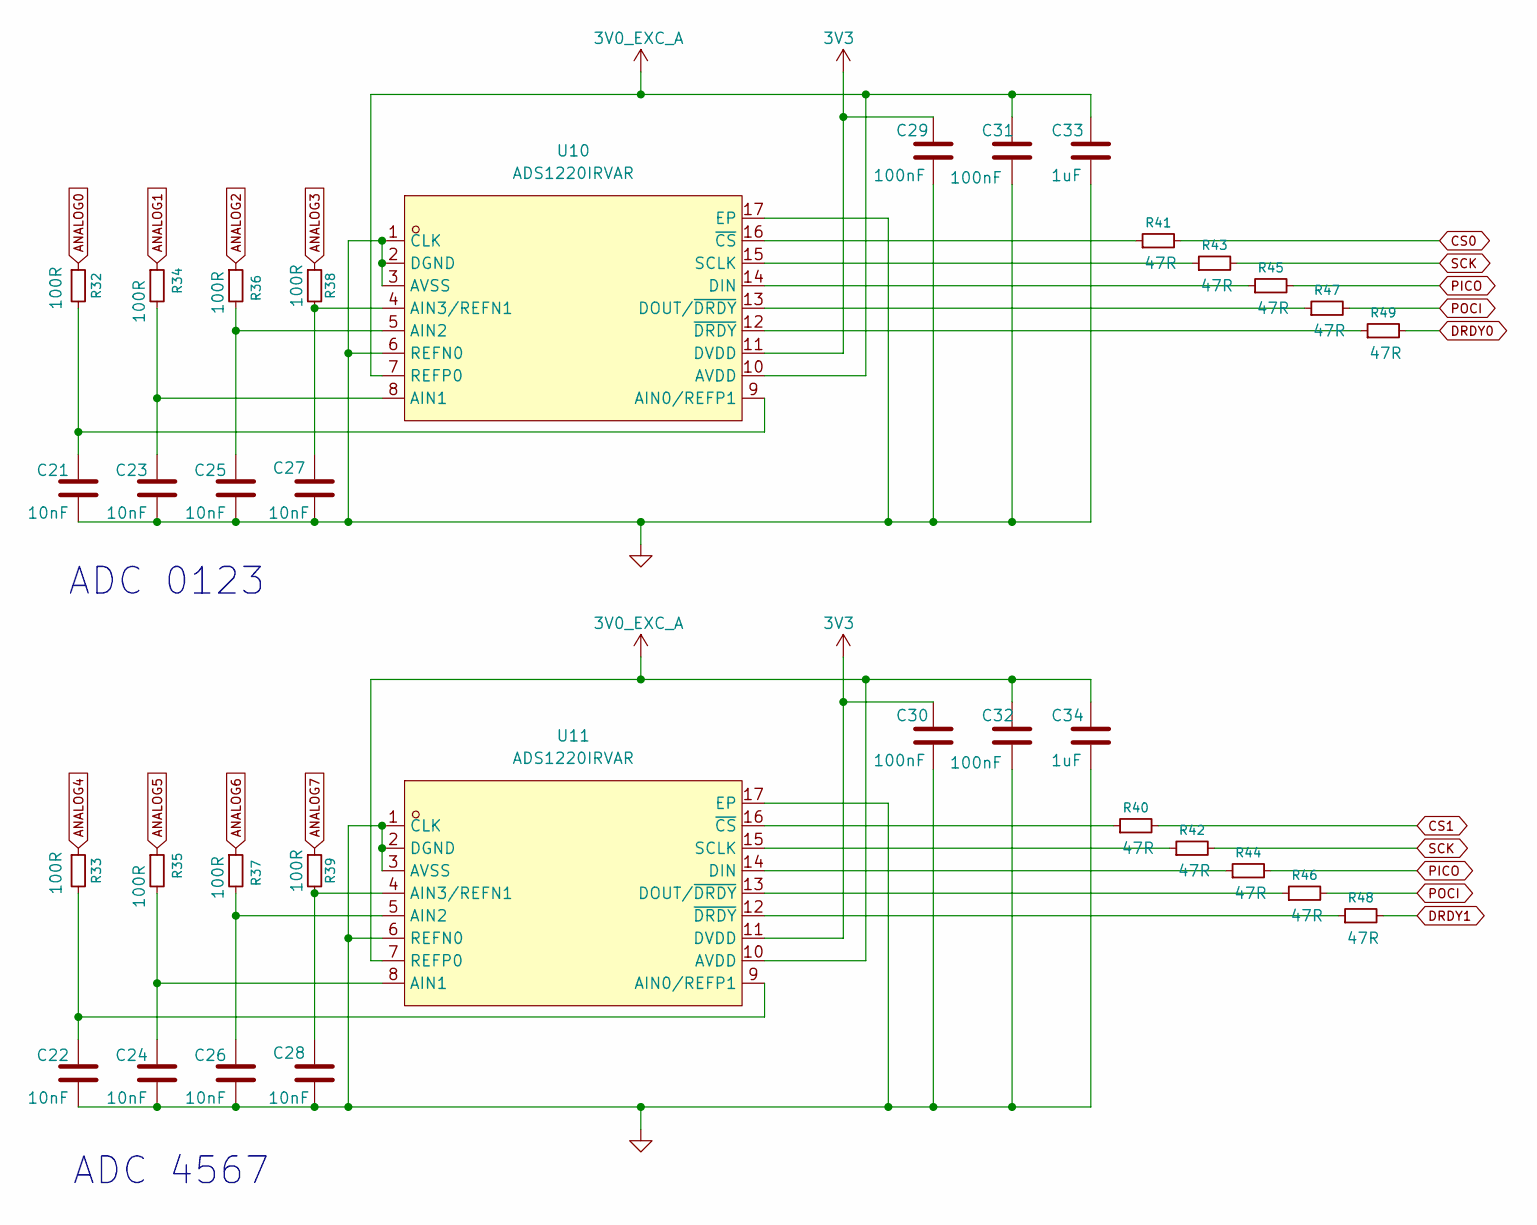
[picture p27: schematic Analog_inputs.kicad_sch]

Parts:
C21, C22, C23, C24, C25, C26, C27, C28: 10nF; C_0402_1005Metric; Manufacturer_Part_Number CL05B103KB5NNNC; LCSC Part C15195
C29, C30, C31, C32: 100nF; C_0402_1005Metric; Manufacturer_Part_Number CL05B104KO5NNNC; LCSC Part C1525
C33, C34: 1uF; C_0402_1005Metric; Manufacturer_Part_Number CL05A105KA5NQNC; LCSC Part C52923
R32, R33, R34, R35, R36, R37, R38, R39: 100R; R_0402_1005Metric; Manufacturer_Part_Number 0402WGF1000TCE; LCSC Part C25076
R40, R41, R42, R43, R44, R45, R46, R47, R48, R49: 47R; R_0402_1005Metric; Manufacturer_Part_Number 0402WGF499JTCE; LCSC Part C25120
U10, U11: ADS1220IRVAR; VQFN-16_L3.5-W3.5-P0.50-BL-EP2.1; MPN ADS1220IRVAR; LCSC Part C2651338

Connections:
3V0_EXC_A: C31.1, C32.1, C33.1, C34.1, U10.7 (REFP0), U10.10 (AVDD), U11.7 (REFP0), U11.10 (AVDD); also elsewhere on the board
3V3: C29.1, C30.1, U10.11 (DVDD), U11.11 (DVDD); also elsewhere on the board
POCI: R46.2, R47.2; also elsewhere on the board
ANALOG0: R32.1; also elsewhere on the board
ANALOG1: R34.1; also elsewhere on the board
ANALOG2: R36.1; also elsewhere on the board
ANALOG3: R38.1; also elsewhere on the board
ANALOG4: R33.1; also elsewhere on the board
ANALOG5: R35.1; also elsewhere on the board
ANALOG6: R37.1; also elsewhere on the board
ANALOG7: R39.1; also elsewhere on the board
CS0: R41.2; also elsewhere on the board
CS1: R40.2; also elsewhere on the board
DRDY0: R49.2; also elsewhere on the board
DRDY1: R48.2; also elsewhere on the board
GND: C21.2, C22.2, C23.2, C24.2, C25.2, C26.2, C27.2, C28.2, C29.2, C30.2, C31.2, C32.2, C33.2, C34.2, U10.1 (CLK), U10.2 (DGND), U10.3 (AVSS), U10.6 (REFN0), U10.17 (EP), U11.1 (CLK), U11.2 (DGND), U11.3 (AVSS), U11.6 (REFN0), U11.17 (EP); also elsewhere on the board
unnamed: C21.1, R32.2, U10.9 (AIN0/REFP1)
unnamed: C23.1, R34.2, U10.8 (AIN1)
unnamed: C25.1, R36.2, U10.5 (AIN2)
unnamed: C27.1, R38.2, U10.4 (AIN3/REFN1)
unnamed: R45.1, U10.14 (DIN)
unnamed: R47.1, U10.13 (DOUT/~DRDY)
unnamed: R43.1, U10.15 (SCLK)
unnamed: R41.1, U10.16 (~CS)
unnamed: R49.1, U10.12 (~DRDY)
unnamed: C22.1, R33.2, U11.9 (AIN0/REFP1)
unnamed: C24.1, R35.2, U11.8 (AIN1)
unnamed: C26.1, R37.2, U11.5 (AIN2)
unnamed: C28.1, R39.2, U11.4 (AIN3/REFN1)
unnamed: R44.1, U11.14 (DIN)
unnamed: R46.1, U11.13 (DOUT/~DRDY)
unnamed: R42.1, U11.15 (SCLK)
unnamed: R40.1, U11.16 (~CS)
unnamed: R48.1, U11.12 (~DRDY)
PICO: R44.2, R45.2; also elsewhere on the board
SCK: R42.2, R43.2; also elsewhere on the board

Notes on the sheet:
ADC 4567
ADC 0123

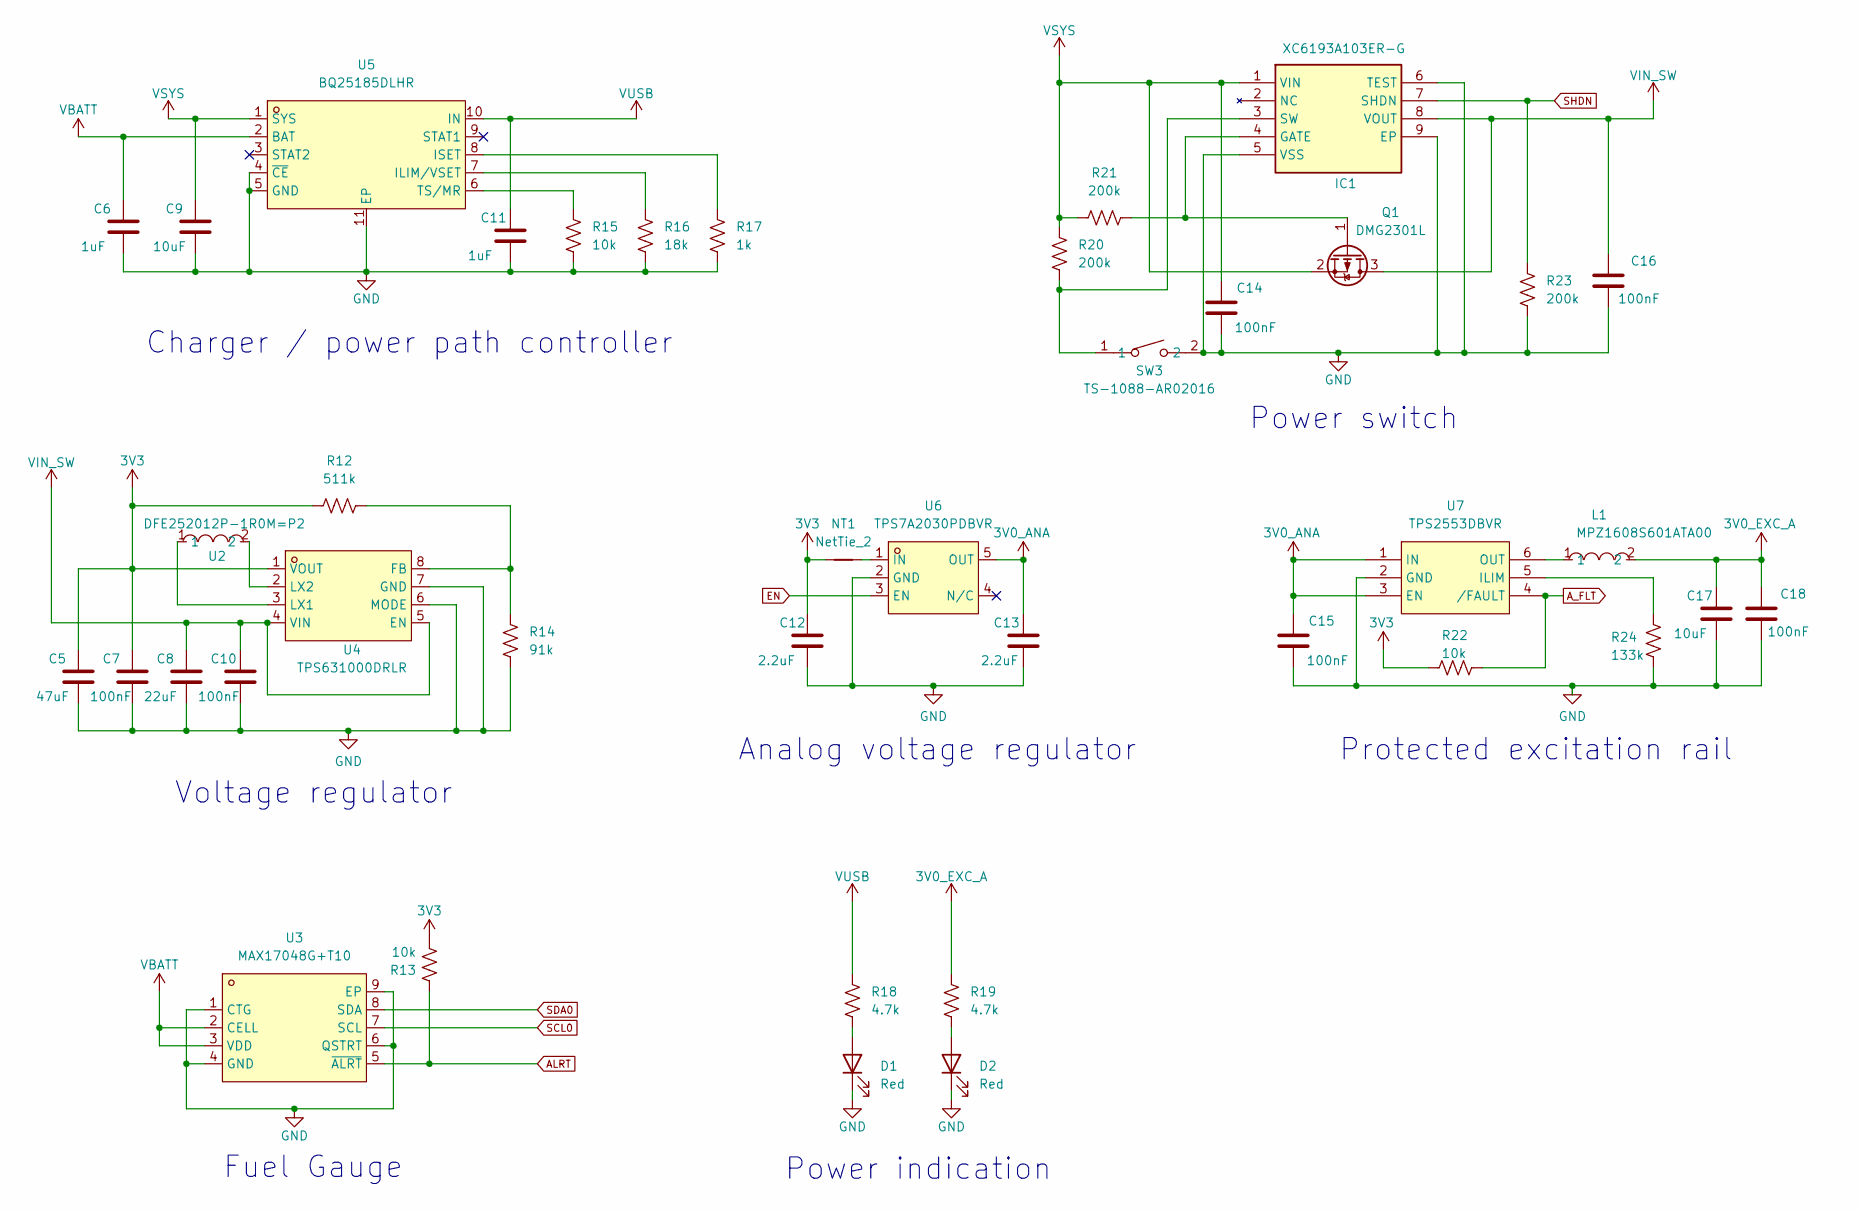
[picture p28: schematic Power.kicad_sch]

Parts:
C5: 47uF; C_0805_2012Metric; Manufacturer_Part_Number CL21A476MQYNNNE; LCSC Part C16780
C6, C11: 1uF; C_0402_1005Metric; Manufacturer_Part_Number CL05A105KA5NQNC; LCSC Part C52923
C7, C10, C14, C15, C16, C18: 100nF; C_0402_1005Metric; Manufacturer_Part_Number CL05B104KO5NNNC; LCSC Part C1525
C8: 22uF; C_0603_1608Metric; Manufacturer_Part_Number GRM188R61A226ME15D; LCSC Part C84419
C9, C17: 10uF; C_0805_2012Metric; Manufacturer_Part_Number CL21A106KAYNNNE; LCSC Part C15850
C12, C13: 2.2uF; C_0603_1608Metric; Manufacturer_Part_Number CL10A225KO8NNNC; LCSC Part C23630
D1, D2: Red; LED_0603_1608Metric; Manufacturer_Part_Number Hubei KENTO KT-0603R; LCSC Part C2286
IC1: XC6193A103ER-G; XC6193AA05ERG; Manufacturer_Part_Number XC6193A103ER-G; LCSC Part C19267155
L1: MPZ1608S601ATA00; L0603; MPN MPZ1608S601ATA00; LCSC Part C107335
NT1: NetTie_2; NetTie-2_SMD_Pad0.5mm
Q1: DMG2301L; SOT-23; Manufacturer_Part_Number DMG2301L-7; LCSC Part C102619
R12: 511k; R_0402_1005Metric; Manufacturer_Part_Number 0402WGF5113TCE; LCSC Part C64042
R13, R15, R22: 10k; R_0402_1005Metric; Manufacturer_Part_Number 0402WGF1002TCE; LCSC Part C25744
R14: 91k; R_0402_1005Metric; Manufacturer_Part_Number 0402WGF9102TCE; LCSC Part C4147
R16: 18k; R_0402_1005Metric; Manufacturer_Part_Number 0402WGF1802TCE; LCSC Part C25762
R17: 1k; R_0402_1005Metric; Manufacturer_Part_Number 0402WGF1001TCE; LCSC Part C11702
R18, R19: 4.7k; R_0402_1005Metric; Manufacturer_Part_Number 0402WGF4701TCE; LCSC Part C25900
R20, R21, R23: 200k; R_0402_1005Metric; Manufacturer_Part_Number 0402WGF2003TCE; LCSC Part C25764
R24: 133k; R_0402_1005Metric; Manufacturer_Part_Number 0402WGF1333TCE; LCSC Part C25753
SW3: TS-1088-AR02016; SW-SMD_L3.9-W3.0-P4.45; MPN TS-1088-AR02016; LCSC Part C720477
U2: DFE252012P-1R0M=P2; L1008; MPN DFE252012P-1R0M=P2; LCSC Part C882955
U3: MAX17048G+T10; TDFN-8_L2.0-W2.0-P0.50-BL-EP1.2; MPN MAX17048G+T10; LCSC Part C2682616
U4: TPS631000DRLR; SOT-583-8_L2.1-W1.2-P0.50-LS1.6-BL; MPN TPS631000DRLR; LCSC Part C5219190
U5: BQ25185DLHR; WSON-10_L2.2-W2.0-P0.40-BL-EP_TI_DLH0010A; MPN BQ25185DLHR; LCSC Part C19725033
U6: TPS7A2030PDBVR; TSOT-23-5_L2.9-W1.6-P0.95-LS2.8-BR; MPN TPS7A2030PDBVR; LCSC Part C963429
U7: TPS2553DBVR; SOT-23-6_L2.9-W1.6-P0.95-LS2.8-BR; MPN TPS2553DBVR; LCSC Part C55266

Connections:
3V0_ANA: C13.1, C15.1, U6.5 (OUT), U7.1 (IN), U7.3 (EN)
3V0_EXC_A: C17.1, C18.1, L1.2, R19.1; also elsewhere on the board
3V3: C5.1, C7.1, C12.1, NT1.1, R12.1, R13.1, R22.2, U4.1 (VOUT); also elsewhere on the board
ALRT: R13.2, U3.5 (~ALRT); also elsewhere on the board
A_FLT: R22.1, U7.4 (/FAULT); also elsewhere on the board
EN: U6.3 (EN); also elsewhere on the board
GND: C5.2, C6.2, C7.2, C8.2, C9.2, C10.2, C11.2, C12.2, C13.2, C14.2, C15.2, C16.2, C17.2, C18.2, D1.1 (K), D2.1 (K), IC1.5 (VSS), IC1.6 (TEST), IC1.9 (EP), R14.2, R15.2, R16.2, R17.2, R23.2, R24.1, SW3.2, U3.1 (CTG), U3.4 (GND), U3.6 (QSTRT), U3.9 (EP), U4.6 (MODE), U4.7 (GND), U5.4 (~CE), U5.5 (GND), U5.11 (EP), U6.2 (GND), U7.2 (GND); also elsewhere on the board
unnamed: D1.2 (A), R18.2
unnamed: D2.2 (A), R19.2
unnamed: IC1.4 (GATE), Q1.1 (G), R21.2
unnamed: IC1.3 (SW), R20.2, SW3.1
unnamed: R12.2, R14.1, U4.8 (FB)
unnamed: U2.1, U4.3 (LX1)
unnamed: U2.2, U4.2 (LX2)
unnamed: R16.1, U5.7 (ILIM/VSET)
unnamed: R17.1, U5.8 (ISET)
unnamed: R15.1, U5.6 (TS/MR)
unnamed: NT1.2, U6.1 (IN)
unnamed: R24.2, U7.5 (ILIM)
unnamed: L1.1, U7.6 (OUT)
SCL0: U3.7 (SCL); also elsewhere on the board
SDA0: U3.8 (SDA); also elsewhere on the board
SHDN: IC1.7 (SHDN), R23.1
VBATT: C6.1, U3.2 (CELL), U3.3 (VDD), U5.2 (BAT); also elsewhere on the board
VIN_SW: C8.1, C10.1, C16.1, IC1.8 (VOUT), Q1.3 (D), U4.4 (VIN), U4.5 (EN)
VSYS: C9.1, C14.1, IC1.1 (VIN), Q1.2 (S), R20.1, R21.1, U5.1 (SYS)
VUSB: C11.1, R18.1, U5.10 (IN); also elsewhere on the board

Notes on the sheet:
Power indication
Charger / power path controller
Protected excitation rail
Voltage regulator
Fuel Gauge
Analog voltage regulator
Power switch

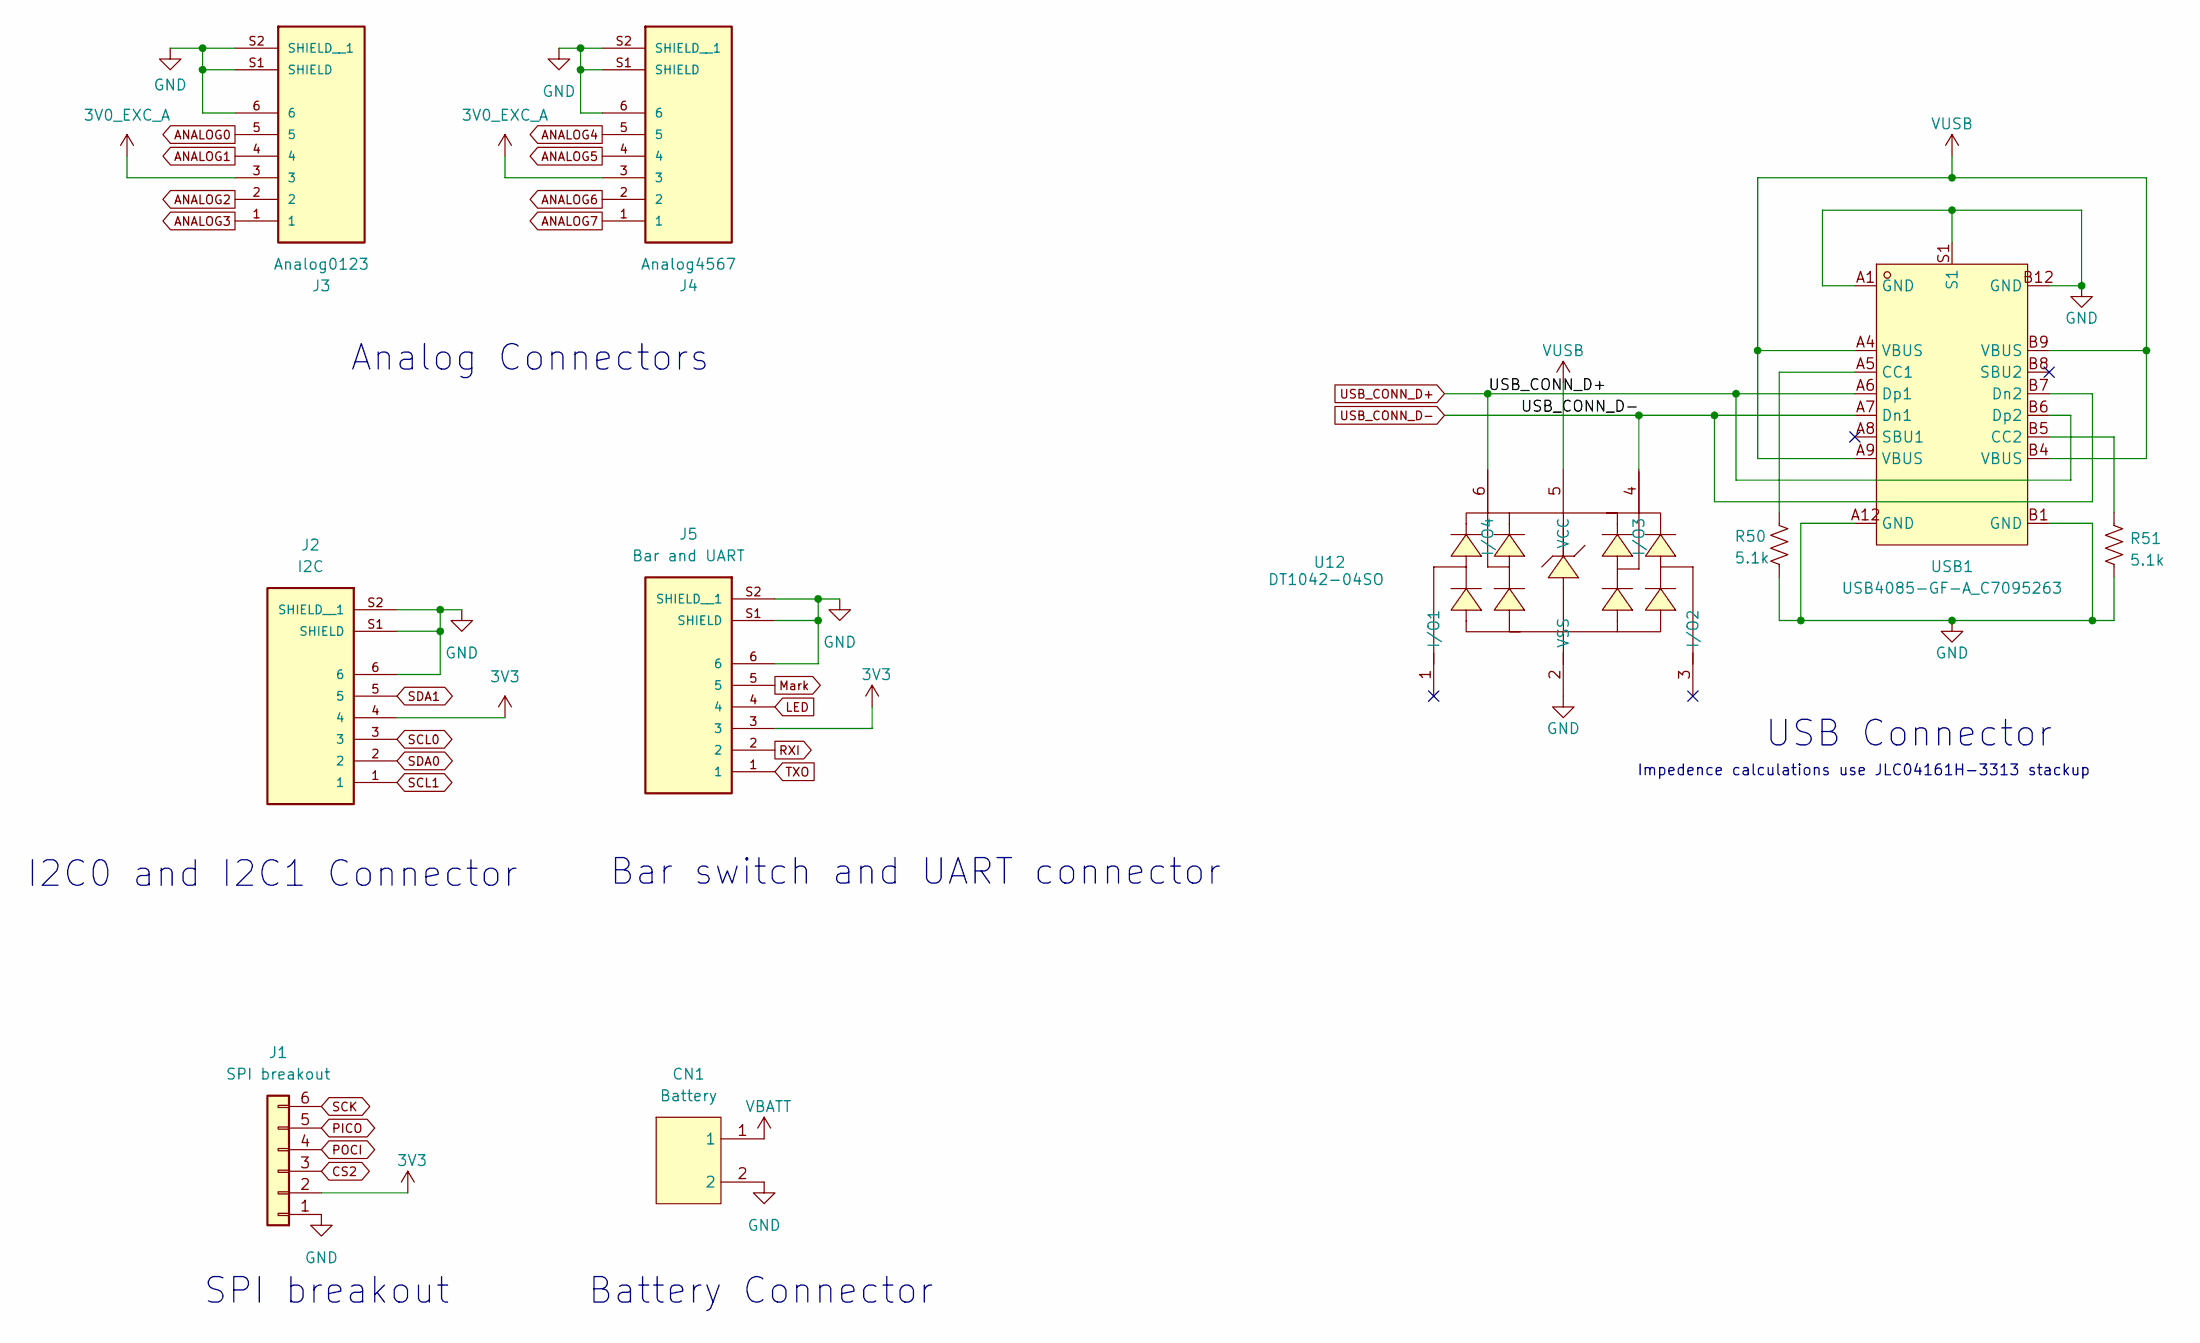
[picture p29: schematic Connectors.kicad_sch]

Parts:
CN1: Battery; CONN-TH_B2B-PH-K-S; MPN B2B-PH-K-S(LF)(SN); LCSC Part C131337
J1: SPI breakout; JST_XA_B06B-XASK-1_1x06_P2.50mm_Vertical
J2: I2C; AMPHENOL_M8AS-06PMMR-SF8001; PARTREV A
J3: Analog0123; AMPHENOL_M8AS-06PMMR-SF8001; PARTREV A
J4: Analog4567; AMPHENOL_M8AS-06PMMR-SF8001; PARTREV A
J5: Bar and UART; AMPHENOL_M8AS-06PMMR-SF8001; PARTREV A
R50, R51: 5.1k; R_0402_1005Metric; Manufacturer_Part_Number 0402WGF5101TCE; LCSC Part C25905
U12: DT1042-04SO; SOT-23-6_L2.9-W1.6-P0.95-LS2.8-BR; MPN DT1042-04SO-7(UMW); LCSC Part C19626385
USB1: USB4085-GF-A_C7095263; USC-C-SMD_USB4085-GF-A; MPN USB4085-GF-A; LCSC Part C7095263

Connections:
3V0_EXC_A: J3.3, J4.3; also elsewhere on the board
3V3: J1.2, J2.4, J5.3; also elsewhere on the board
LED: J5.4; also elsewhere on the board
POCI: J1.4; also elsewhere on the board
TXO: J5.1; also elsewhere on the board
ANALOG0: J3.5; also elsewhere on the board
ANALOG1: J3.4; also elsewhere on the board
ANALOG2: J3.2; also elsewhere on the board
ANALOG3: J3.1; also elsewhere on the board
ANALOG4: J4.5; also elsewhere on the board
ANALOG5: J4.4; also elsewhere on the board
ANALOG6: J4.2; also elsewhere on the board
ANALOG7: J4.1; also elsewhere on the board
CS2: J1.3; also elsewhere on the board
GND: CN1.2, J1.1, J2.6, J2.S1 (SHIELD), J2.S2 (SHIELD__1), J3.6, J3.S1 (SHIELD), J3.S2 (SHIELD__1), J4.6, J4.S1 (SHIELD), J4.S2 (SHIELD__1), J5.6, J5.S1 (SHIELD), J5.S2 (SHIELD__1), R50.2, R51.1, U12.2 (VSS), USB1.A1 (GND), USB1.A12 (GND), USB1.B1 (GND), USB1.B12 (GND), USB1.S1; also elsewhere on the board
Mark: J5.5; also elsewhere on the board
unnamed: R50.1, USB1.A5 (CC1)
unnamed: R51.2, USB1.B5 (CC2)
PICO: J1.5; also elsewhere on the board
RXI: J5.2; also elsewhere on the board
SCK: J1.6; also elsewhere on the board
SCL0: J2.3; also elsewhere on the board
SCL1: J2.1; also elsewhere on the board
SDA0: J2.2; also elsewhere on the board
SDA1: J2.5; also elsewhere on the board
USB_CONN_D+: U12.6 (I/O4), USB1.A6 (Dp1), USB1.B6 (Dp2); also elsewhere on the board
USB_CONN_D-: U12.4 (I/O3), USB1.A7 (Dn1), USB1.B7 (Dn2); also elsewhere on the board
VBATT: CN1.1; also elsewhere on the board
VUSB: U12.5 (VCC), USB1.A4 (VBUS), USB1.A9 (VBUS), USB1.B4 (VBUS), USB1.B9 (VBUS); also elsewhere on the board

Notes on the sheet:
I2C0 and I2C1 Connector
SPI breakout
Analog Connectors
Impedence calculations use JLC04161H-3313 stackup
USB Connector
Bar switch and UART connector
Battery Connector

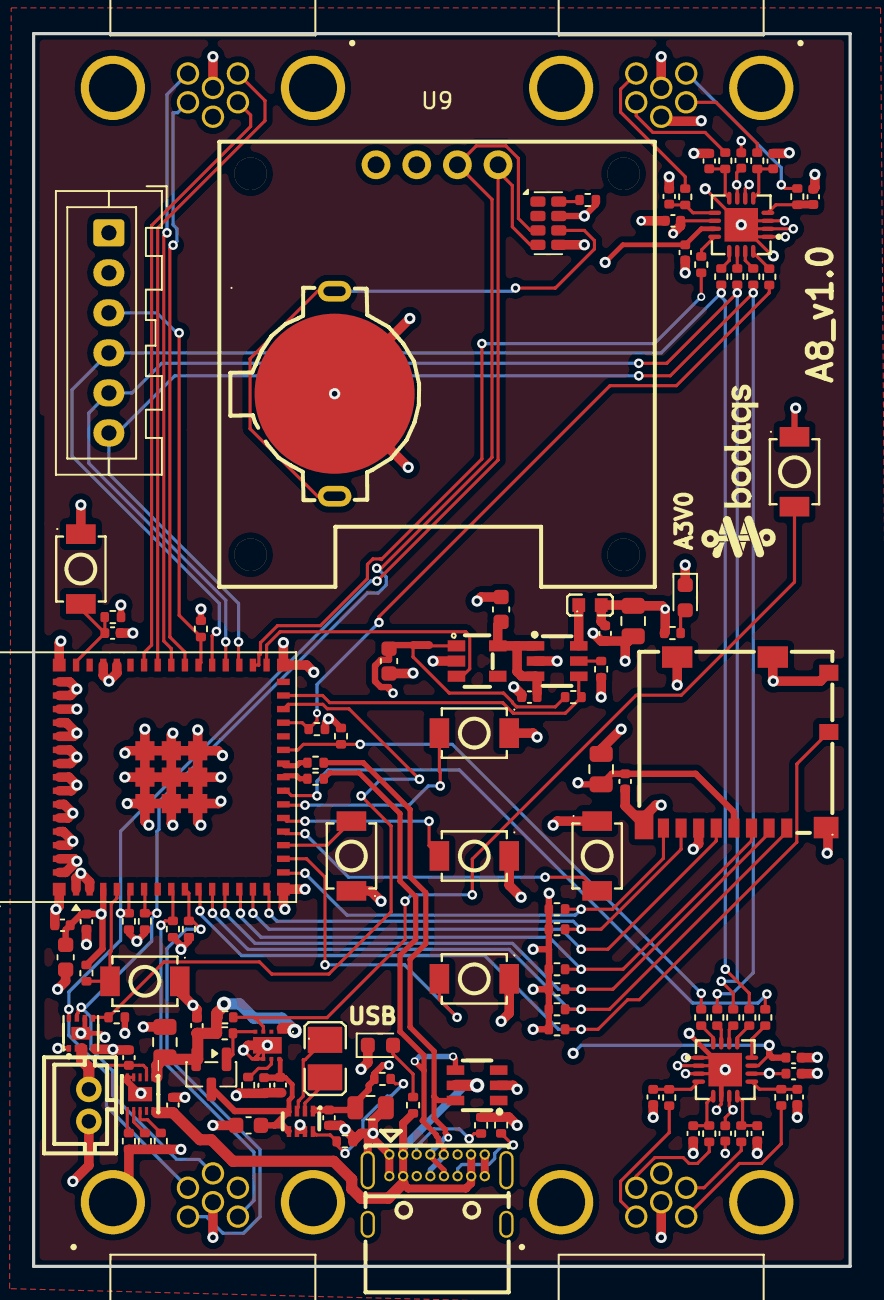
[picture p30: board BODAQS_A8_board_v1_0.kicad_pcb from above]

Board: 4 copper layers, 51.0 x 77.0 mm, 120 parts (0 on the bottom side), 89 nets.

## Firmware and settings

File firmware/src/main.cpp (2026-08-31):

#include <Arduino.h>
#include "ButtonManager.h"

#include "Calibration.h"
#include "RTCManager.h"
#include "StorageManager.h"
#include "WebServerManager.h"
#include "WiFi.h"
#include "ConfigManager.h"
#include "DisplayManager.h"
#include "UI.h"
#include "LoggingManager.h"
#include "ButtonActions.h"
#include "ButtonBindingTable.h"
#include "Sensor.h"
#include "SensorManager.h"
#include "AnalogPotSensor.h"
#include "DebugLog.h"
#include "MenuSystem.h"
#include "SensorRegistry.h"
#include "TransformRegistry.h"
#include "OutputTransform.h"
#include "WiFiManager.h"
#include "UploadModeManager.h"
#include "BoardSelect.h"
#include "I2CManager.h"
#include "AnalogInputManager.h"
#include "IndicatorManager.h"
#include "PowerManager.h"
#include "BoardProfile.h"
#if defined(BODAQS_AS5048_LIBRARY_PROBE)
#include "AS5048LibraryProbe.h"
#endif
#if defined(BODAQS_GPS_UART_PROBE)
#include "GpsUartProbe.h"
#endif
#include "freertos/FreeRTOS.h"
#include "freertos/task.h"
#include "esp_heap_caps.h"

#include "FS.h"
#include "SD_MMC.h"

#define PROBE(msg) do { LOGI(msg); delay(2); } while(0)
#define BOOT_LOGW(...) LOGW_TAG("BOOT", __VA_ARGS__)
#define BOOT_LOGE(...) LOGE_TAG("BOOT", __VA_ARGS__)
#define BOOT_LOGI(...) LOGI_TAG("BOOT", __VA_ARGS__)
#define HB_LOGD(...)   LOGD_TAG("HB", __VA_ARGS__)
#define ADC_LOGD(...)  LOGD_TAG("ADC", __VA_ARGS__)

#ifndef BODAQS_BOARD_PROFILE
#define BODAQS_BOARD_PROFILE ThingPlusS3_BODAQS_4_D
#endif


//Debug
static void dbgHeartbeat_()
{
  static uint32_t last = 0;
  uint32_t now = millis();
  if (now - last < 5000) return;
  last = now;

  HB_LOGD("ms=%lu core=%d heap=%u largest=%u\n",
          (unsigned long)now,
          xPortGetCoreID(),
          ESP.getFreeHeap(),
          heap_caps_get_largest_free_block(MALLOC_CAP_8BIT));

  // Optional: stack watermark for loop task (call from the task you care about)
  HB_LOGD("stack watermark=%u\n", (unsigned)uxTaskGetStackHighWaterMark(nullptr));
}


// --- Small utils ------------------------------------------------------------

// Parse "ZERO,RANGE" → CalMask (case-insensitive). Unknown tokens are ignored.
static CalMask parseCalMaskCSV(const char* csv) {
  if (!csv || !*csv) return CAL_NONE;
  CalMask m = CAL_NONE;

  auto ieq = [](char a, char b) {
    if (a >= 'a' && a <= 'z') a = char(a - 32);
    if (b >= 'a' && b <= 'z') b = char(b - 32);
    return a == b;
  };
  auto tokenEq = [&](const char* tok, const char* lit) {
    while (*tok && *tok != ' ' && *tok != '\t') {
      if (!*lit || !ieq(*tok, *lit)) return false;
      ++tok; ++lit;
    }
    return *lit == '\0';
  };

  const char* p = csv;
  while (*p) {
    while (*p == ',' || *p == ' ' || *p == '\t') ++p;
    if (!*p) break;
    const char* start = p;
    while (*p && *p != ',') ++p;

    // trim end spaces
    const char* end = p;
    while (end > start && (end[-1] == ' ' || end[-1] == '\t')) --end;

    char buf[24];
    size_t len = size_t(end - start);
    if (len >= sizeof(buf)) len = sizeof(buf) - 1;
    memcpy(buf, start, len);
    buf[len] = '\0';

    // normalize leading/trailing spaces already handled
    if (tokenEq(buf, "ZERO"))  m = (CalMask)(m | CAL_ZERO);
    if (tokenEq(buf, "RANGE")) m = (CalMask)(m | CAL_RANGE);
  }
  return m;
}

// ----------------------------------------------------------------------------

static void buildSensorsFromConfig();
static bool s_rtcConnectIntent = false;
void onToggleLogging(ButtonEvent event);
void onMarkEvent(ButtonEvent event);
void onWebServerToggle(ButtonEvent event);

static adc_attenuation_t adcAttenuationForBoard_(board::AdcAttenuation attenuation) {
  switch (attenuation) {
    case board::AdcAttenuation::Db0:   return ADC_0db;
    case board::AdcAttenuation::Db2p5: return ADC_2_5db;
    case board::AdcAttenuation::Db6:   return ADC_6db;
    case board::AdcAttenuation::Db11:
    default:                           return ADC_11db;
  }
}

static const char* adcAttenuationLabel_(board::AdcAttenuation attenuation) {
  switch (attenuation) {
    case board::AdcAttenuation::Db0:   return "0dB";
    case board::AdcAttenuation::Db2p5: return "2.5dB";
    case board::AdcAttenuation::Db6:   return "6dB";
    case board::AdcAttenuation::Db11:
    default:                           return "11dB";
  }
}

static void configureBoardAnalogInputs_() {
  if (!board::gBoard) return;

  const auto& analog = board::gBoard->analog;
  analogReadResolution(12);

  const adc_attenuation_t attenuation = adcAttenuationForBoard_(analog.attenuation);
  for (uint8_t i = 0; i < analog.count; ++i) {
    const int8_t pin = analog.pins[i];
    if (pin < 0) continue;

    analogSetPinAttenuation((uint8_t)pin, attenuation);
    ADC_LOGD("AIN%u GPIO%02d attenuation=%s\n",
             (unsigned)i,
             (int)pin,
             adcAttenuationLabel_(analog.attenuation));
  }
}

static void applyLogSettings_(const LoggerConfig& cfg) {
  Log_setEnabled(true);
  Log_resetLevel();
  if (cfg.logLevelOverride <= LOG_TRACE) {
    Log_setLevel((LogLevel)cfg.logLevelOverride);
  }
}


LoggerConfig g_cfg;  
TransformRegistry gTransforms;

using namespace board;

static bool isLoggingPredicate() { return LoggingManager::isRunning(); }

#if defined(BODAQS_BRINGUP_DIAGNOSTICS)
static void setupBringupDiagnostics_() {
  BOOT_LOGI("Bring-up diagnostics enabled\n");

  ConfigManager::begin("/config/loggercfg.txt");

  g_cfg.uiTarget       = 3;
  g_cfg.uiSerialLevel  = 3;
  g_cfg.uiOledLevel    = 3;
  g_cfg.oledBrightness = 200;
  g_cfg.oledIdleDimMs  = 30000;
  g_cfg.sampleRateHz   = 100;

  I2CManager::begin(*gBoard);
  DisplayManager::begin(g_cfg,
                        gBoard->display,
                        I2CManager::bus(gBoard->display.bus_index));
  UI::begin(g_cfg);
  UI::status("Bring-up ready");
  UI::toast("BODAQS\nBRINGUP", 2500, 1);
  UI::println("Bring-up diagnostics ready.", "", UI::TARGET_SERIAL, UI::LVL_INFO);

  ButtonActions::begin();
  ButtonManager_setPressActivityCallback(PowerManager::noteActivity);
}
#endif

void setup() {
  
    Serial.begin(115200);
    SelectBoard(BoardID::BODAQS_BOARD_PROFILE);
    if (!gBoard) {
      BOOT_LOGE("FATAL: Board not selected\n");
      while (true) delay(1000);
    }
    PowerManager::begin(*gBoard);
    configureBoardAnalogInputs_();
    DumpActiveBoardProfile();
    DumpActiveBoardButtons();

#if defined(BODAQS_AS5048_LIBRARY_PROBE)
    RunAS5048LibraryProbe(*gBoard);
    return;
#endif

#if defined(BODAQS_GPS_UART_PROBE)
    RunGpsUartProbe(*gBoard);
    return;
#endif

#if defined(BODAQS_BRINGUP_DIAGNOSTICS)
    setupBringupDiagnostics_();
    return;
#endif

  AnalogInputManager::begin(*gBoard);

#if defined(BODAQS_ADC_DEBUG_PROBE)
    auto dumpAdc = [](const char* tag){
      ADC_LOGD("\n%s\n", tag);
      if (!gBoard) return;
      for (uint8_t i = 0; i < gBoard->analog.count && i < board::BOARD_MAX_ANALOG_INPUTS; ++i) {
        int8_t p = AnalogInputManager::pinForAin(i);
        if (p < 0) continue;
        int v = analogRead((uint8_t)p);
        LOGD("  AIN%u GPIO%02d = %d\n", (unsigned)i, (int)p, v);
      }
    };

    dumpAdc("before WiFi");
#endif
  
  //Buffer debug
  static uint32_t g_sampleCounter = 0;

  StorageManager_begin(*gBoard);           

  applyLogSettings_(g_cfg);

  StorageManager_setSampleRate(100);   // 100 Hz logging

  // UI / OLED defaults (fallbacks)
  g_cfg.uiTarget       = 1;     // serial
  g_cfg.uiSerialLevel  = 3;     // info
  g_cfg.uiOledLevel    = 3;     // info
  g_cfg.oledBrightness = 200;   // nominal contrast
  g_cfg.oledIdleDimMs  = 30000; // 30s
  g_cfg.sampleRateHz   = 100;   // fallback

  IndicatorManager::begin(*board::gBoard);

  ConfigManager::begin("/config/loggercfg.txt");


  if (!ConfigManager::load(g_cfg)) {
    LOGW_TAG("CFG", "Load failed, using defaults\n");
  } else {
    LOGI_TAG("CFG", "Loaded");
  }

  applyLogSettings_(g_cfg);
  BOOT_LOGI("SETUP: A ButtonBindingTable::initFromConfig\n");
  ButtonBindingTable::initFromConfig(ConfigManager::get());
  BOOT_LOGI("SETUP: A done\n");
  RTCManager_setHumanReadable(g_cfg.timestampHuman);
  RTCManager_setTimezone(g_cfg.tz);
  const auto& cfg = ConfigManager::get();
  I2CManager::begin(*gBoard);


  // 1) Sensor framework
  BOOT_LOGI("SETUP: B Sensormanager::begin\n");

  SensorManager::begin(&g_cfg);
    BOOT_LOGI("SETUP: B done\n");

  BOOT_LOGI("SETUP: C buildsensorsfromFromConfig\n");

  SensorManager::buildSensorsFromConfig(g_cfg);
  BOOT_LOGI("SETUP: C done\n");

  BOOT_LOGI("SETUP: D finalize begin\n");

  SensorManager::finalizeBegin();
    BOOT_LOGI("SETUP: D done\n");

  //PROBE("[SENS] debugDump");
  //SensorManager::debugDump("after-register");
  UI::status("Sensors ready");

  StorageManager_setSampleRate(AnalogInputManager::configureFromConfig(g_cfg, g_cfg.sampleRateHz));


  //ConfigManager::print(g_cfg);
  // Boot probe after ConfigManager::print.
  //Serial.flush();

  BOOT_LOGI("SETUP: E webservermanager::attachconfig\n");
  WebServerManager::attachConfig(&g_cfg);
      BOOT_LOGI("SETUP: E done\n");

  BOOT_LOGI("SETUP: F storagemanager_getSD\n");

  WebServerManager::begin(isLoggingPredicate);
    BOOT_LOGI("SETUP: F done\n");

  // Choose RTC from the board profile. A8 uses its RV3028; legacy boards
  // retain the ESP32 internal clock until network sync.
  RTCManager_begin(gBoard->rtc);

  //Initialise wifi manager
  BOOT_LOGI("SETUP: G wifimanager::begin\n");
  WiFiManager::begin(isLoggingPredicate);
  BOOT_LOGI("SETUP: G Done\n");

  BOOT_LOGI("SETUP: H uploadmodemanager::begin\n");
  UploadModeManager::begin(isLoggingPredicate);
  BOOT_LOGI("SETUP: H Done\n");

  // Bring Wi-Fi up on boot only if the user asked for it by default
  if (cfg.wifiEnabledDefault) {
    WiFiManager::enable();
    WiFiManager::connectNow();   // one pass: scan → select → connect
    WiFiManager::maybeConnectForRTC();   

  } else {
    WiFiManager::disable();  // ensures clean OFF
    WiFiManager::maybeConnectForRTC();  // if your signature takes cfg; otherwise keep your existing call
  }

 
  // 3) Init logging *after* sensors exist
  LoggingManager::begin(&g_cfg);

  BOOT_LOGI("SETUP: I Done\n");

  if (gBoard && gBoard->fuel.type != FuelGaugeType::None) {
    PowerManager::fuelGaugeBegin(gBoard->fuel.i2c_addr,
                                 I2CManager::bus(gBoard->fuel.bus_index));
  }
  // Start OLED if present
  DisplayManager::begin(cfg,
                        gBoard->display,
                        I2CManager::bus(gBoard->display.bus_index));

  BOOT_LOGI("SETUP: J Done\n");

  // Configure routing (Serial/OLED/Both + levels)
  UI::begin(g_cfg);
    BOOT_LOGI("SETUP: K Done\n");


  // Show initial status
#if defined(BODAQS_BRINGUP_DIAGNOSTICS)
  BOOT_LOGI("Bring-up diagnostics enabled\n");
  UI::status("Bring-up ready");
  UI::toast("BODAQS\nBRINGUP", 2500, 1);
#else
  UI::status("Ready");
#endif
  UI::println("Device ready.", "", UI::TARGET_SERIAL, UI::LVL_INFO, 1200);

  ButtonActions::begin();
    BOOT_LOGI("SETUP: L Done\n");

  ButtonManager_setPressActivityCallback(PowerManager::noteActivity);


  //ConfigManager::printAllCalibrations();

  // Start the menu system
  MenuSystem::begin(&g_cfg);
    BOOT_LOGI("SETUP: M Done\n");

  MenuSystem::setIdleCloseMs(300000);
  PowerManager::noteActivity();
  BOOT_LOGI("SETUP: N Done\n");

    BOOT_LOGI("SETUP: ALL DONE\n");

}

void loop() {
#if defined(BODAQS_AS5048_LIBRARY_PROBE) || defined(BODAQS_GPS_UART_PROBE)
  delay(1000);
  return;
#endif

#if defined(BODAQS_BRINGUP_DIAGNOSTICS)
  ButtonManager_loop();
  DisplayManager::loop();
  delay(1);
  return;
#endif

  WiFiManager::loop();
  RTCManager_loop();
  ButtonManager_loop();
  StorageManager_loop();       
  WebServerManager::loop();
  UI::loop();
  MenuSystem::loop();
  PowerManager::loop();
  PowerManager::fuelGaugeLoop();
  //dbgHeartbeat_();
}

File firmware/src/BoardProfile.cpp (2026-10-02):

#include <Arduino.h>
#include "BoardProfile.h"
#include <string.h>

namespace board {

static constexpr int8_t kDefaultUartTxPin = 43;
static constexpr int8_t kDefaultUartRxPin = 44;

static SPIProfile MakeSPI(bool present, int8_t sck, int8_t miso, int8_t mosi,
                          const int8_t* cs_list, uint8_t cs_count,
                          uint32_t hz = 20000000) {
  SPIProfile p;
  p.present = present;
  p.sck = sck;
  p.miso = miso;
  p.mosi = mosi;
  p.hz_default = hz;
  p.cs_count = (cs_count > 8) ? 8 : cs_count;
  for (uint8_t i = 0; i < 8; ++i) p.cs_pins[i] = -1;
  for (uint8_t i = 0; i < p.cs_count; ++i) p.cs_pins[i] = cs_list[i];
  return p;
}

static UARTProfile MakeUART(bool present, int8_t tx, int8_t rx,
                            uint32_t baud = 38400) {
  UARTProfile p;
  p.present = present;
  p.tx = tx;
  p.rx = rx;
  p.baud_default = baud;
  return p;
}

static AnalogInputHW MakeInternalAnalog(int8_t pin) {
  AnalogInputHW input;
  input.source = (pin >= 0) ? AnalogSourceType::InternalGpio : AnalogSourceType::None;
  input.pin = pin;
  return input;
}

static AnalogInputHW MakeExternalAdcInput(uint8_t adcIndex, uint8_t channel) {
  AnalogInputHW input;
  input.source = AnalogSourceType::ExternalAdc;
  input.external_adc_index = adcIndex;
  input.external_channel = channel;
  input.differential = false;
  input.negative_channel = -1;
  return input;
}

static const BoardProfile THING_PLUS_S3_BODAQS_4_D = {
  .name = "BODAQS 4D",

  .storage = {
    .type = StorageType::SDMMC,
    .sdmmc_1bit = true,
    .sdmmc_clk = 38,
    .sdmmc_cmd = 34,
    .sdmmc_d0  = 39,
  },

  .display = {
    .type = DisplayType::OLED_SSD1306,
    .addr_primary = 0x3C,
    .addr_alt     = 0x3D,
    .bus_index    = 0,
    .rst = -1
  },

  .buttons = {
    .btn = {
      { "nav_up",    true, 6, 1, true,  true },
      { "nav_down",  true, 7, 1, true,  true },
      { "nav_left",  true, 5, 1, true,  true },
      { "nav_right", true, 4, 1, true,  true },
      { "nav_enter", true, 21, 0, true,  true },
      { "mark",      true, 2, 0, true,  true },
    },
    .count = 6,
    .binding_preset = ButtonBindingPreset::BodaqsRc3,
  },

  .fuel = {
    .type = FuelGaugeType::MAX17048,
    .i2c_addr = 0x36,
    .bus_index = 0
  },

  .analog = {
    .pins  = { 15, 17, 18, 10, -1, -1, -1, -1 },
    .inputs = {
      MakeInternalAnalog(15),
      MakeInternalAnalog(17),
      MakeInternalAnalog(18),
      MakeInternalAnalog(10),
    },
    .count = 4,
    .adc_max = 4095,
    .vref = 3.3f,
    .attenuation = AdcAttenuation::Db11
  },

  .i2c = {
    {
      .present = true,
      .sda = 8,
      .scl = 9,
      .hz  = 400000
    }
  },
  .i2c_count = 1,

  .spi = MakeSPI(
    true,
    -1,
    -1,
    -1,
    (const int8_t[]){ -1 },
    0,
    20000000
  ),

  .indicators = {
    .has_led = true,
    .led_pin = 1,
    .led_active_high = true,
    .has_buzzer = false,
    .buzzer_pin = -1,
    .buzzer_active_high = true
  },

  .perf = {
    .queue_depth = 256,
    .ring_buffer_bytes = 32768,
    .bdq_chunk_bytes = 16384
  },
  .supports_user_sleep = true,
};

static const BoardProfile THING_PLUS_S3_BODAQS_4_D_UART_I2C1 = [] {
  BoardProfile p = THING_PLUS_S3_BODAQS_4_D;
  p.name = "BODAQS 4D (UART as I2C1)";
  p.i2c[1] = {
    .present = true,
    .sda = TX,
    .scl = RX,
    .hz  = 400000
  };
  p.i2c_count = 2;
  return p;
}();

static const BoardProfile THING_PLUS_S3_BODAQS_4_F = [] {
  BoardProfile p = THING_PLUS_S3_BODAQS_4_D;
  p.name = "BODAQS 4F";
  p.buttons.binding_preset = ButtonBindingPreset::PrototypeF;

  p.buttons.btn[0] = ButtonHW{ "nav_up",    true, 6,  1, true, true };
  p.buttons.btn[1] = ButtonHW{ "nav_down",  true, 5,  1, true, true };
  p.buttons.btn[2] = ButtonHW{ "nav_left",  true, 7,  1, true, true };
  p.buttons.btn[3] = ButtonHW{ "nav_right", true, 21, 1, true, true };
  p.buttons.btn[4] = ButtonHW{ "nav_enter", true, 4,  0, true, true };
  p.analog.pins[0] = 10;
  p.analog.pins[1] = 18;
  p.analog.pins[2] = 17;
  p.analog.pins[3] = 15;
  p.analog.inputs[0] = MakeInternalAnalog(10);
  p.analog.inputs[1] = MakeInternalAnalog(18);
  p.analog.inputs[2] = MakeInternalAnalog(17);
  p.analog.inputs[3] = MakeInternalAnalog(15);

  p.i2c[0] = {
    .present = true,
    .sda = 8,
    .scl = 9,
    .hz  = 400000
  };
  p.i2c[1] = {
    .present = true,
    .sda = 14,
    .scl = 16,
    .hz  = 400000
  };
  p.i2c_count = 2;
  p.uart[0] = MakeUART(true, kDefaultUartTxPin, kDefaultUartRxPin);
  p.uart_count = 1;
  p.analog.attenuation = AdcAttenuation::Db6;
  p.analog.enable_pin = 42;
  p.analog.enable_active_high = true;
  p.analog.enable_default_on = true;

  return p;
}();
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

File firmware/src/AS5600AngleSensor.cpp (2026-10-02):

#include "AS5600AngleSensor.h"

#include <Arduino.h>
#include <Wire.h>
#include <math.h>
#include <string.h>

#include "ConfigManager.h"
#include "BdqV2Catalog.h"
#include "I2CManager.h"
#include "PowerManager.h"
#include "SensorRegistry.h"
#include "DebugLog.h"
#include "esp_timer.h"

#define AS5600A_LOGI(...) LOGI_TAG("AS5600", __VA_ARGS__)
#define AS5600A_LOGW(...) LOGW_TAG("AS5600", __VA_ARGS__)

namespace {

static constexpr uint8_t kDefaultAddress = 0x36;
static constexpr uint8_t kZposMsbReg = 0x01;
static constexpr uint8_t kMposMsbReg = 0x03;
static constexpr uint8_t kMangMsbReg = 0x05;
static constexpr uint8_t kConfMsbReg = 0x07;
static constexpr uint8_t kStatusReg = 0x0B;
static constexpr uint8_t kRawAngleMsbReg = 0x0C;
static constexpr uint8_t kAngleMsbReg = 0x0E;
static constexpr uint8_t kAgcReg = 0x1A;
static constexpr uint8_t kMagnitudeMsbReg = 0x1B;
static constexpr uint16_t kCountsPerTurn = 4096;
static constexpr uint16_t kHalfTurn = kCountsPerTurn / 2;
static constexpr float kDegreesPerCount = 360.0f / float(kCountsPerTurn);
static constexpr uint32_t kDefaultDiagnosticIntervalMs = 1000;
static constexpr uint32_t kDeviceConfigRetryMs = 2000;
static constexpr int32_t kDirectionMinDeltaCounts = int32_t(kCountsPerTurn / 720); // about 0.5 deg
static constexpr uint8_t kDiagnosticColumnCount = 7;
static constexpr uint16_t kConfSlowFilterMask = 0x0300;
static constexpr uint8_t kConfSlowFilterShift = 8;
static constexpr uint16_t kMaxAsyncRateHz = 1000;
static constexpr uint32_t kDeferredRecoveryFailureStreak = 3;

void recordRuntimeTiming_(
    SensorRuntimeTimingSummary& summary,
    uint32_t durationUs) {
  if (summary.count == 0 || durationUs < summary.minimumUs) {
    summary.minimumUs = durationUs;
  }
  if (durationUs > summary.maximumUs) summary.maximumUs = durationUs;
  if (UINT64_MAX - summary.totalUs < durationUs) {
    summary.totalUs = UINT64_MAX;
  } else {
    summary.totalUs += durationUs;
  }
  if (summary.count != UINT32_MAX) ++summary.count;
}

static constexpr uint8_t kStatusMagnetTooStrong = 0x08;
static constexpr uint8_t kStatusMagnetTooWeak = 0x10;
static constexpr uint8_t kStatusMagnetDetected = 0x20;

const BdqV2CatalogChannel kBdqV2Channels[] = {
    {"sequence", "sample_sequence", "count", "uint32", 0, "diagnostic"},
    {"native_tick", "logger_monotonic_time", "us", "uint32", 4,
     "diagnostic"},
    {"status_flags", "status", "bitfield", "uint16", 8, "diagnostic"},
    {"raw_angle", "absolute_angle_raw", "count", "uint16", 12, "signal"},
    {"sensor_status", "sensor_status", "bitfield", "uint8", 14,
     "diagnostic"},
    {"agc", "automatic_gain_control", "count", "uint8", 15,
     "diagnostic"},
    {"magnitude", "magnetic_magnitude", "count", "uint16", 16,
     "diagnostic"},
    {"read_ok", "read_ok", "flag", "uint8", 18, "diagnostic"},
    {"reused", "reused_previous", "flag", "uint8", 19, "diagnostic"},
};

const BdqV2CatalogStatusFlag kBdqV2StatusFlags[] = {
    {"discontinuity_before", BdqV2Format::DiscontinuityBefore},
    {"producer_queue_drop_before", BdqV2Format::ProducerQueueDropBefore},
    {"source_recovery_before", BdqV2Format::SourceRecoveryBefore},
    {"timing_degraded", BdqV2Format::TimingDegraded},
    {"read_failed", AS5600BdqV2::kReadFailed},
    {"reused_previous", AS5600BdqV2::kReusedPrevious},
    {"diagnostics_stale", AS5600BdqV2::kDiagnosticsStale},
    {"magnet_not_detected", AS5600BdqV2::kMagnetNotDetected},
    {"magnet_too_weak", AS5600BdqV2::kMagnetTooWeak},
    {"magnet_too_strong", AS5600BdqV2::kMagnetTooStrong},
};

void copyField_(char* dst, size_t cap, const char* src) {
  if (!dst || cap == 0) return;
  if (!src) src = "";
  size_t n = strlen(src);
  if (n >= cap) n = cap - 1;
  memcpy(dst, src, n);
  dst[n] = '\0';
}

void writeColumnLabel_(const char* name, const char* units, char* out, size_t cap) {
  if (!out || cap < 2) return;
  out[0] = '\0';

  String s = name ? String(name) : String();
  if (units && units[0]) {
    s += " [";
    s += units;
    s += "]";
  }
  s.toCharArray(out, cap);
}

AS5600AngleSensor::I2CReadMode parseReadMode_(const String& value) {
  String s = value;
  s.trim();
  s.toLowerCase();
  s.replace("-", "_");

  if (s == "stop" || s == "stop_then_read" || s == "stop_read" || s == "0") {
    return AS5600AngleSensor::I2CReadMode::StopThenRead;
  }
  return AS5600AngleSensor::I2CReadMode::RepeatedStart;
}

int8_t parseDirectionSign_(const String& value) {
  String s = value;
  s.trim();
  s.toLowerCase();
  s.replace("-", "_");

  if (s == "counts_decrease_positive" || s == "decrease_positive" ||
      s == "inverted" || s == "invert" || s == "reverse" || s == "-1" || s == "-") {
    return -1;
  }
  return 1;
}

const char* directionName_(int8_t sign) {
  return (sign < 0) ? "counts_decrease_positive" : "counts_increase_positive";
}

int8_t parseSlowFilterCode_(const String& value) {
  String s = value;
  s.trim();
  s.toLowerCase();
  s.replace("-", "_");
  s.replace(" ", "");

  if (!s.length() || s == "unchanged" || s == "default" || s == "none" || s == "-1") return -1;
  if (s == "16x" || s == "16" || s == "0") return 0;
  if (s == "8x" || s == "8" || s == "1") return 1;
  if (s == "4x" || s == "4" || s == "2") return 2;
  if (s == "2x" || s == "3") return 3;
  return -1;
}

uint32_t busHz_(uint8_t busIndex) {
  const board::I2CProfile* profile = I2CManager::profile(busIndex);
  return (profile && profile->hz) ? profile->hz : 100000UL;
}

void loadParamsFromPack_(AS5600AngleSensor::Params& p,
                         const char* instanceName,
                         const ParamPack& params) {
  p.name = instanceName ? instanceName : "as5600";

  long li = 0;
  bool b = false;
  double d = 0.0;
  String s;

  if (params.getInt("i2c_bus", li))       p.busIndex = (li < 0) ? 0u : (uint8_t)li;
  if (params.getInt("i2c_addr", li))      p.i2cAddr = (li <= 0) ? kDefaultAddress : (uint8_t)li;
  if (params.get("i2c_read_mode", s))     p.readMode = parseReadMode_(s);
  if (params.getInt("zero_count", li))    p.zeroCount = (int32_t)li;
  if (params.get("direction", s))          p.directionSign = parseDirectionSign_(s);
  if (params.getFloat("installed_range", d)) p.installedRange = (float)d;
  if (params.get("slow_filter", s))        p.slowFilterCode = parseSlowFilterCode_(s);
  if (params.getInt("async_rate_hz", li))  p.asyncRateHz = (li < 0) ? 0u : (uint16_t)li;
  if (params.getBool("include_raw", b))   p.includeRawColumn = b;
  if (params.getBool("include_angle", b)) p.includeAngleColumn = b;
  if (params.getBool("include_diag", b))  p.includeDiagColumns = b;
  if (params.getInt("diag_interval_ms", li)) p.diagnosticIntervalMs = (li < 0) ? 0UL : (uint32_t)li;
  if (params.get("end", s))               s.toCharArray(p.semanticEnd, sizeof(p.semanticEnd));
  if (params.get("primary_domain", s))    s.toCharArray(p.primaryDomain, sizeof(p.primaryDomain));
  if (params.get("primary_quantity", s))  s.toCharArray(p.primaryQuantity, sizeof(p.primaryQuantity));
}
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

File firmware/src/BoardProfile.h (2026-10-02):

// BoardProfile.h
#pragma once
#include <stdint.h>
#include <stddef.h>

namespace board {

static constexpr uint8_t BOARD_MAX_BUTTONS = 6;
static constexpr uint8_t BOARD_MAX_I2C_BUSES = 2;
static constexpr uint8_t BOARD_MAX_UART_PORTS = 2;
static constexpr uint8_t BOARD_MAX_ANALOG_INPUTS = 8;
static constexpr uint8_t BOARD_MAX_EXTERNAL_ADCS = 2;

// ---------- IDs / Types ----------
enum class BoardID : uint8_t {
  ThingPlusS3_BODAQS_4_D = 0,
  ThingPlusS3_BODAQS_4_D_UartI2C1,
  ThingPlusS3_BODAQS_4_F,
  BODAQS_V1RC3,
  ThingPlusS3_Proto_F_ADC_Diagnostic,
  BODAQS_A8,
  BODAQS_S3_Mini_N4R2 = BODAQS_A8,
  // Add more here...
};

enum class StorageType : uint8_t { None, SDMMC };
enum class DisplayType : uint8_t { None, OLED_SSD1306 };
enum class FuelGaugeType : uint8_t { None, MAX17048, Other };
enum class AdcAttenuation : uint8_t { Db0 = 0, Db2p5, Db6, Db11 };
enum class RtcType : uint8_t { None, RV3028 };
enum class ExternalAdcType : uint8_t { None, ADS1220 };
enum class AdcReferenceType : uint8_t { Default, Internal, ExternalRef0, ExternalRef1, AnalogSupply };
enum class AnalogSourceType : uint8_t { None, InternalGpio, ExternalAdc };
enum class ButtonID : uint8_t { BTN0=0, BTN1, BTN2, BTN3, BTN4, BTN5, Count };
enum class ButtonMode : uint8_t {Interrupt = 0, Poll = 1 };
enum class ButtonBindingPreset : uint8_t {
  None = 0,
  BodaqsRc3,
  PrototypeF,
  BodaqsA8,
};

// ---------- Sub-profiles ----------

struct StorageProfile {
  StorageType type = StorageType::None;

  // SDMMC configuration
  bool sdmmc_1bit = true;          // if you use SD_MMC 1-bit mode
  int8_t sdmmc_clk = -1;
  int8_t sdmmc_cmd = -1;
  int8_t sdmmc_d0  = -1;
  int8_t sdmmc_d1  = -1;   // optional (4-bit)
  int8_t sdmmc_d2  = -1;   // optional (4-bit)
  int8_t sdmmc_d3  = -1;   // optional (4-bit)

  // Optional socket card-detect switch. Not used by StorageManager yet.
  int8_t detect_pin = -1;
  bool detect_active_low = true;
  bool detect_use_internal_pullup = true;
};

struct ButtonHW {
  char id[16];
  bool present = false;
  int8_t pin = -1;
  uint8_t mode = 0; // 0 = interrupt, 1 = poll 
  bool active_low = true;
  bool use_internal_pullup = true;
};

struct ButtonsProfile {
  ButtonHW btn[6];     // fixed max, easy on embedded
  uint8_t count = 0;   // number actually present
  ButtonBindingPreset binding_preset = ButtonBindingPreset::None;
};

struct DisplayProfile {
  DisplayType type = DisplayType::None;

  // If using I2C OLED
  uint8_t addr_primary = 0x3C;
  uint8_t addr_alt     = 0x3D;
  uint8_t bus_index    = 0;

  // Optional reset pin for the display (if wired)
  int8_t rst = -1;                 // -1 = not used
};

struct FuelGaugeProfile {
  FuelGaugeType type = FuelGaugeType::None;
  uint8_t i2c_addr = 0x36;         // MAX17048 default
  uint8_t bus_index = 0;

  // Optional alert/interrupt pin. MAX17048 ALRT is typically active-low/open-drain.
  int8_t alert_pin = -1;
  bool alert_active_low = true;
  bool alert_use_internal_pullup = true;
};

struct RtcProfile {
  RtcType type = RtcType::None;
  uint8_t i2c_addr = 0x52;         // RV3028 default
  uint8_t bus_index = 0;

  // Optional interrupt pin for future alarm/timer support.
  int8_t interrupt_pin = -1;
  bool interrupt_active_low = true;
  bool interrupt_use_internal_pullup = true;
};

struct I2CProfile {
  bool present = false;
  int8_t sda = -1, scl = -1;
  uint32_t hz = 400000;
};

struct UARTProfile {
  bool present = false;
  int8_t tx = -1;
  int8_t rx = -1;
  uint32_t baud_default = 38400;
};

struct SPIProfile {
  bool present = false;
  int8_t sck = -1, miso = -1, mosi = -1;
  uint32_t hz_default = 20000000;

  // “available CS pins” for other SPI devices (IMUs, ADCs, etc.)
  int8_t cs_pins[8] = {-1,-1,-1,-1,-1,-1,-1,-1};
  uint8_t cs_count = 0;
};

struct ExternalAdcProfile {
  ExternalAdcType type = ExternalAdcType::None;
  bool present = false;
  uint8_t spi_bus_index = 0;
  int8_t cs_pin = -1;
  int8_t drdy_pin = -1;
  bool drdy_active_low = true;
  bool drdy_use_internal_pullup = false;

  uint8_t channel_count = 0;
  uint32_t max_sps = 0;
  uint32_t spi_hz = 1000000;
  AdcReferenceType reference = AdcReferenceType::Default;
  uint8_t gain = 1;
  bool pga_bypass = true;
  uint8_t effective_bits = 12;
};

struct AnalogInputHW {
  AnalogSourceType source = AnalogSourceType::None;

  // Internal ESP32 ADC source.
  int8_t pin = -1;

  // External ADC source.
  uint8_t external_adc_index = 0;
  uint8_t external_channel = 0;
  bool differential = false;
  int8_t negative_channel = -1;
};
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

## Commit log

2025-11-06 Initial BODAQS structure (fresh history)
    [Data logger shield v1.kicad_pcb, Data logger shield v1.kicad_sch, Data logger shield v1_original.kicad_sch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]
2025-11-16 Kitchen sink: analysis pipeline
    [Data logger shield v1.step, event_analysis_df_data_1.csv, front_shock_rebounds_0.csv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]
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2025-11-27 button cleanup / backward searches
    [BODAQS shield v1.kicad_pcb, BODAQS shield v1.kicad_sch, Data logger shield v1_original.kicad_sch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]
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2025-11-28 Fix firmware layout and restore buttonbindingtable files
    [AnalogPotSensor.cpp, AnalogPotSensor.h, ConfigManager.cpp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]
2025-12-07 Support SDMMA and SDFat
    [BODAQS shield v1 SMD.kicad_pcb, BODAQS shield v1 SMD.kicad_sch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]
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2025-12-14 Fix crash problems and complete SDMMC support
    [ConfigManager.cpp, Routes_Config.cpp]
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2025-12-27 Standardise on SdFs; all SDFat instances replaced with SdFs.
    [ConfigManager.cpp, ConfigManager.h]
2025-12-27 Fix wifi state management
    [BoardProfile.cpp]
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2025-12-28 Fix bug with analog pot sensor pin assignment
    [AnalogPotSensor.cpp, AnalogPotSensor.h]
2025-12-28 Fix transform updating on webpage; UI polish
    [Routes_Config.cpp]
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2025-12-31 Tighten up and document public API contract; apply throughout pipeline
2025-12-31 Adding my to-do list
    [To do list.xlsx]
2026-01-03 Fix log-start latency and dropped samples. Pin sampling task to Core 0 plus assorted other tweaks.
2026-01-04 Fix selection / key issues with transforms
    [AnalogPotSensor.cpp, AnalogPotSensor.h, ConfigManager.cpp]
2026-01-04 Add SD card and transforms documentation, update to-do list
    [To do list.xlsx]
2026-01-06 Add event table contract documentation
    [LUT spreadsheet.xlsm]
2026-01-06 Tighten contracts for events and metrics; add tests.
2026-01-06 tighten and document time handling
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2026-01-16 getting the pipeline working again
    [Analysis workflow.xlsx]
2026-01-16 Finish debugging and update tests
    [Analysis workflow.xlsx]
2026-01-24 Minor changes to enqueue_sample / dequeue_sample and samplerow to resolve row corruption
2026-01-26 Add global strict / tolerant flag to data ingestion pipeline
    [Analysis workflow.xlsx]
2026-01-26 Make zeroing optional and geberate a mask for inactive sections
    [To do list.xlsx]
2026-01-28 Consumer side: develop a session selector and convert two widgets - signal histogram and event browser - to use it. Re-factor the event browser to remove redundant UI elements and improve what remain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
    [To do list.xlsx]
2026-01-31 Implement rebuild of widgets if session selector changes. Migrate metrics histogram widget. Cosmetic changes to widget layouts.
    [To do list.xlsx]
2026-02-01 Finish cosmetic tidy up of widgets. Stop inferring sensors from signal names and use the registry and schema instead.
    [To do list.xlsx]
2026-02-01 Initial prototype of session browser widget
    [To do list.xlsx]
2026-02-03 Move session window browser to single-figure design and debug. Ready to commence managing marks and bookmarks
    [To do list.xlsx]
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2026-02-15 Invalidate RTC time on reset. Fix mark button double-click. Update readme.
2026-02-18 Start work on PCB prototype E. Some incidental fiddling with zeroing settings.
    [BODAQS 4 Proto D Box.stl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]
2026-02-21 Update gitignore and todo
    [To do list.xlsx]
2026-02-21 Fix preprocessing pipeline so it works with zeroing disabled. CHange interpretation of schematic roles so ops not indicated are allowed. Change segment and event extraction to use registry for roles.
    [To do list.xlsx]
2026-02-23 Add documentation of python dependencies. Add install guide for Jupyter Lab. Add log file examples.
    [2026-02-20_08-34-26.CSV, 2026-02-20_08-36-01.CSV, 2026-02-20_09-13-59.CSV]
2026-02-25 Add linear pot mountings and first draft of logger BOM
    [Fork pot mount Fox 36 lower.stl, Fork pot mount Fox 38 lower.stl, Fork pot mount upper 38 oval.stl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]
2026-02-27 Update gitignore, add parametric pot mount
    [Fork pot mount lower.f3d]
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2026-02-28 Move to VSCode / PlatformIO for firmware development and install VSCode Codex extension. Test build and resolve build issues.
    [To do list.xlsx]
2026-02-28 Move wifi scan to synchronous to address strange issues
    [BoardProfile.cpp]
2026-02-28 Fi issue of NTP servers and time check URL not being written in config
    [ConfigManager.cpp, Routes_Config.cpp]
2026-03-01 Add a test harness notebook for developing event definitions
    [BODAQS shield Proto E.kicad_pcb, To do list.xlsx]
2026-03-03 Add shield prototype E designs; add test Sufni data
    [BODAQS 4 Proto D Box.stl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]
2026-03-06 Finish hardware prototype E design (TH and SMD)
    [BODAQS 4 Proto D Box.stl, BODAQS shield Proto E SMD BOM.csv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]
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2026-03-16 Polish run library formatting and behaviour
    [To do list.xlsx]
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2026-03-30 Move all time setting to RTC manager; revert to 2-param wifi connection
    [main.cpp]
2026-03-30 Fix file browsing bug. Add 'click' button action distinct from 'pressed'.
2026-03-31 Investigate issues with as5600 on I2C
    [To do list.xlsx]
2026-04-02 Omnibus commit of minor stuff - firmware button semantics, PCB design evolution
    [BODAQS shield Proto E SMD BOM.csv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]
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2026-04-06 Make preprocessing fail gracefully if sensors missing. Edit sourcing guide.
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2026-04-10 Add 3d printed parts to repo
    [Base_inserts.stl, Base_nuts.stl, Bottom end.stl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]
2026-04-10 Progress in rev F of PCB
    [BODAQS shield SMD Proto F.kicad_pcb, BODAQS shield SMD Proto F.kicad_sch]
2026-04-13 More work on hardware design
    [BODAQS shield SMD Proto F.kicad_sch]
2026-04-13 Analysis notebook for string pot testing
    [1000rpm.CSV, 1500rpm.CSV, 2026-04-11_15-12-28.CSV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]
2026-04-13 Add F3Z and STEP files to case directory; add end variants for plastic connectors
    [2026-04-11_15-15-12_manual_analysis.csv, Bottom end_1_connector_plastic.stl, Case proto E-F V2.step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]
2026-04-13 Continue string pot analysis
    [2026-04-11_15-15-12_manual_analysis.csv]
2026-04-14 Fix mark/enter button menu mehaviour. Clean up on screen toasts so they always fit.
    [Routes_Config.cpp]
2026-04-14 Fix log-start latency when RTC is not set. Clean up repo
    [1000rpm.CSV, 1500rpm.CSV, 2026-02-20_08-34-26.CSV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]
2026-04-14 Fix fast timestamp mode; add manual time setting option
    [ConfigManager.cpp, ConfigManager.h, Routes_Config.cpp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]
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2026-04-17 Shorten the lede
2026-04-17 Move string pot analysis back into repo
    [1000rpm.CSV, 1000rpm_2.CSV, 1500rpm.CSV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]
2026-04-21 Fix issues with re-applying live config in firmware
    [AS5600StringPotI2C.cpp, AS5600StringPotI2C.h, AnalogPotSensor.cpp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]
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2026-04-24 Update 3d printing case files, add links and extend documentation, add Bambulab project files
    [All parts - one material.3mf, All parts - three color.3mf, Base.step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]
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2026-04-29 Add board profile for Proto F board. Add helper notebook for syn.bike export.
    [All parts - three color.3mf]
2026-04-29 General web UI tidyup. Change timeout units to mins, remove explicit invert, drop dns2
    [AS5600StringPotI2C.cpp, AS5600StringPotSensorBase.h, AnalogPotSensor.cpp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]
2026-04-30 Add example files for web development
    [2026-02-20_08-34-26.CSV, 2026-02-20_08-36-01.CSV, 2026-02-20_08-39-06.CSV]
2026-05-04 Fix 3mf 3 color print file
    [All parts - three color.3mf]
2026-05-04 Fix uppercase file names stage 1
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2026-05-05 Update build guide for Proto F. Correct analog pin assignments in Proto F board definition.
    [BoardProfile.cpp]
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2026-05-07 Update STL, 3MF and f3Z files
    [All parts - one color - F.3mf, All parts - one material.3mf, All parts - three color - F.3mf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]
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2026-06-04 Fix a firmware bug for RC3 board
    [BoardProfile.cpp, BoardProfile.h, main.cpp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]
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2026-06-19 Fix webserver issues with analog input configuration for external ADCs
    [AnalogInputManager.cpp, Routes_Config.cpp]
2026-06-20 Restructure library. Fix logger discovery on AP.
    [AS5048BAngleSensor.cpp, AS5048BAngleSensor.h, AS5600AngleSensor.cpp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]
2026-06-20 Add firmware sag helper
    [AS5048BAngleSensor.cpp, AS5048BAngleSensor.h, AS5600AngleSensor.cpp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]
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2026-06-29 Fix engineering units issue. Fix bug with diagnnostic column semantics.
    [AS5048BAngleSensor.cpp, AS5600AngleSensor.cpp, AS5600AngleSensor.h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]
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2026-07-28 Add A8 case design and mesh files to repo
    [A8 case V1.f3z, Amphenol M8 cap.stl, Base bt2_5.step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]
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2026-08-03 feat(wifi): Enable mDNS/Bonjour in AP mode and show .local on display
    Non-breaking feature adding mDNS advertisement in AP mode and
    showing the .local hostname on the OLED display.
    What changed:
    startMdns_() no longer requires Station mode; runs whenever
    the network is up
    startAccessPoint_() calls startMdns_() after AP is live
    refreshDiscovery() relaxed to work in any online state
    added display_name and wifi_mode TXT records to mDNS advertisement
    ButtonActions toast and UI status line now show hostname.local
    instead of the raw IP address
    updated README, API spec, implementation plan, and release notes
    to reflect AP mode mDNS support
    Why it changed:
    AP mode previously required typing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
2026-08-05 fix(web-ui): Address PR #135 review findings
    Non-breaking fixes for four review findings on the htmx web UI PR.
    sensor add/delete/apply-type now use HX-Redirect to force a full
    page reload, so the sensor list and editor refresh after mutations
    cache-busting ?v= parameter now uses FNV-1a content hash from
    WebAssets.h instead of firmware version, so same-version rebuilds
    with changed assets properly bust the browser cache
    added tools/generate_web_assets.py to regenerate WebAssets.h from
    firmware/www/, with --check mode for CI consistency validation
    rewrote test_routes_static.cpp to test the flash-embedded
    implementation instead of the old SD-card approach
    removed commi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
    [Routes_Config.cpp]
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2026-08-23 Various: library catalog projection fix, better firmware gating when configured sensors are physically missing.
    [AS5600AngleSensor.cpp, AS5600AngleSensor.h, BMI270FifoAcquisition.cpp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]
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2026-09-02 Start bike installation guide - linear pots for forks
    [Fork pot mount Fox 38 lower.stl, Fork pot mount lower.f3d, Fork pot mount upper 38 oval.stl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]
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2026-09-08 Add pot mounts for SID and Fox 34
    [fork-lower-band0-type-od41_5-af7mm-sid-fox34-miran.stl, fork-lower-band0-type-od44_5-af7mm-fox36-lyrik-miran.stl, fork-lower-band30-type-od41_5-af7mm-sid-fox34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]
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2026-09-09 Fix button bindings for Mac builds
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2026-09-24 4-IMU bug fixes; additional firmware diagnostics
    [AS5600AngleSensor.cpp, AS5600AngleSensor.h, AS5600StringPotI2C.h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]
2026-09-25 Add default button bindings to board profiles
    [BoardProfile.cpp, BoardProfile.h, ConfigManager.cpp]
2026-10-02 Fix slow scenario evaluation... and other things
    [AnalogInputManager.cpp]
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2026-10-11 Rework I2C recovery and add startup diagnostics. Highlight config issues on logger screen
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
